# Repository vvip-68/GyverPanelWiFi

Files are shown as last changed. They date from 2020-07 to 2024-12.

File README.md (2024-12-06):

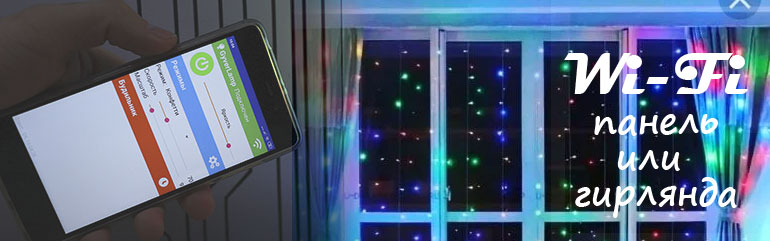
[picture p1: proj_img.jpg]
PROJECT_PHOTO

# Крутая WiFi панель / гирлянда на esp8266 своими руками
* [Описание проекта](#chapter-0)
* [Папки проекта](#chapter-1)
* [Схемы подключения](#chapter-2)
* [Материалы и компоненты](#chapter-3)
* [Как скачать и прошить](#chapter-4)
* [Полезная информация](#chapter-5)

## **Этот проект устарел.** 
> Новый проект ["WiFi панель или гирлянда на ESP8266 / ESP32 с Web-интерфейсом"](https://github.com/vvip-68/LedPanelWiFi)
> почти полностью повторяет функционал этого проекта, за исключением следующих позиций:
> - В новом проекте в настоящее время в комплекте нет Android-приложения для управления и настройки.
> - Android-приложение из версии 1.13 несовместимо с прошивкой в новом проекте
> - Управление и настройка параметров нового проекта выполняется через Web интерфейс.
> - Управление сторонним приложением или интеграция в Умный дом всё ещё возможна:  
>   Управление по каналам UDP и MQTT поддерживается как и раньше, за исключением некоторых изменений в API 
> 
> Переход на Web-интерфейс упрощает процесс внедрения новых возможностей, которые будут дополняться по мере развития проекта
> 
> Если вы активно используете управление устройством через MQTT - оставайтесь на этой версии.
> В противном случае - переходите на новый проект. 
> Поддержка этого проекта будет закрыта.  

## Описание проекта
  
Этот проект основан на проекте ["Крутая WiFi лампа на esp8266 своими руками"](https://github.com/vvip-68/GyverLampWiFi)
с расширением возможностей работы на неквадратных широких матрицах с размерами от 23x11.  
Основное назначение проекта - настенные экраны больших размеров или гирлянды на широкие балконы.  
Также подходит с некоторыми ограничениями для матриц с размерами 16x16.
Ограничение связаны с невозможностью отображения часов крупным шрифтом 5x7 для которого требуется матрица не менее 23 пикселей по ширине.
Для матриц менее 23 колонок шириной в часах может использоваться только шрифт 3x5 для которого достаточно 15 колонок.

### Железо
- Проект собран на базе микроконтроллера ESP8266 в лице платы NodeMCU или Wemos D1 mini (неважно, какую из этих плат использовать)
- Реализована поддержка микроконтроллера ESP32, имеющего больший размер оперативной памяти и быстродействие, что позволяет управлять матрицами с большим количеством светодиодов
- Матрица может быть реализована на адресной ленте или отдельных светодиодах WS8212b, спаянных в нити гирлянды проводами
- Также для компактных панелей может использоваться соединение нескольких гибких адресных матриц 16×16, состоящих из 256 диодов с плотностью 100 штук на метр, что позволяет 
  легко получить панели размерами 32х16, 48x16, 64x16 и так далее (до 128 по ширине и/или высоте).
- Система управляется со смартфона по Wi-Fi в локальной сети или из любой точки мира через MQTT, а также “оффлайн” с кнопки на корпусе (сенсорная кнопка на TTP223 или 
  любая физическая кнопка с нормально разомкнутыми контактами)
- В случае реализации проекта в виде большой настенной матрицы поддерживается функционал будильника-рассвет и индикация текущего времени на индикаторе TM1637, 
  что позволяет в ночное время полностью выключать саму матрицу, оставляя возможность отображения текущего времени на этом индикаторе
- Поддерживается загрузка файлов анимации формата \*.out программы Glediator с SD-карты.

### Фишки
 - Более 40 крутых эффектов с поддержкой отображения часов или текста бегущей строки поверх эффектов
 - 4 интерактивные игры: Лабиринт, Змейка, Тетрис, Арканоид (в программе-компаньоне "WiFiPlayer")
 - Отправка картинки со смартфона на матрицу (в программе-компаньоне "WiFiPlayer")
 - Рисование на матрице (в программе-компаньоне "WiFiPlayer")
 - Сохранение нарисованных изображения на SD-карте или во внутренней памяти микроконтроллера
 - Загрузка сохраненных изображений на матрицу и в программу "WiFiPlayer" для редактирования
 - Редактирование и создание картинок пользователя пригодных для загрузки на матрицу в утилите ["JinxFramer"](https://github.com/vvip-68/GyverPanelWiFi/wiki/JinxFramer---редактор-анимации,-роликов,-картинок).
 - Регулировка яркости эффектов относительно яркости часов или текста бегущей строки, отображаемых поверх эффектов
 - Возможность задания до 36 разных [текстовых строк](https://github.com/vvip-68/GyverPanelWiFi/wiki/Настройка-бегущей-строки), задание порядка их "воспроизведения" a также параметров отображения.
   Тексты задаются из программы на смартфоне без необходимости перепрошивки контроллера.
   [Как настроить.](https://github.com/vvip-68/GyverPanelWiFi/wiki/Настройка-бегущей-строки)
   [Обсуждение текстов.](https://github.com/vvip-68/GyverPanelWiFi/issues/102#issue-778611501)  
 - Поддержка текста бегущей строки с отображением оставшегося до события времени, например: "До Нового года осталось 5 дней 12 часов"
   и после наступления события - вывод специального текста, например: "С Новым 2022 годом!!!"
 - Текст бегущей строки может отображаться различными цветами внутри одной строки
 - Поддержка в бегущей строке шрифтов трех размеров: малый (5x8 точек), средний (8х13 точек), большой (10х16 точек) - [настраивается](https://github.com/vvip-68/GyverPanelWiFi/wiki/Большие-буквы-в-бегущей-строке) в скетче при компиляции проекта
 - Поддержка символов украинского и литовского языка (в этом случае - размер шрифта 5x11. 8x17, 10x20 точек)
 - Настройка скорости и вариаций отображения для каждого эффекта со смартфона
 - Поддержка эффектов анимации, подготовленных в программе [“Jinx!”](https://github.com/vvip-68/GyverPanelWiFi/wiki/Экспорт-эффектов-анимации-из-ПО-«Jinx!»), сохраненных на SD карту
 - Редактирование роликов анимации с SD-карты в утилите ["JinxFramer"](https://github.com/vvip-68/GyverPanelWiFi/wiki/JinxFramer---редактор-анимации,-роликов,-картинок).
 - [Создание кадров для эффекта "Анимация"](https://github.com/vvip-68/GyverPanelWiFi/wiki/Добавление-своей-анимации--к-эффекту-«Анимация») в утилите "JinxFramer" для последующего экспорта кода, пригодного для включения в скетч проекта.
 - Работа системы как в локальной сети, так и в режиме “точки доступа”
 - Система получает точное время из Интернета
 - Управление кнопкой: смена режима, настройка яркости, вкл/выкл, отображение текущего IP адреса устройства
 - Режим будильник-рассвет: менеджер будильников на неделю в приложении
 - Отображение текущего времени на индикаторе TM1637
 - Отображение текущего времени на матрице поверх эффектов
 - Отображение текстовых сообщений на матрице поверх эффектов
 - Настройка сервера синхронизации времени из программы на смартфоне 
 - Установка текущего времени со смартфона вручную, если не удалось подключиться к серверу времени NTP
 - Два режима работы индикатора времени TM1637 - светится постоянно или выключается вместе с панелью
 - Пока время не получено с сервера NTP - на индикаторе TM1637 отображается --:-- вне зависимости от настройки
   "Выключать индикатор при выключении панели"
 - Поддержка звука будильника / звука рассвета звуковой платой MP3 DFPlayer
 - Настройки сетевого подключения (SSID и пароль, статический IP) задаются в программе и сохраняются в EEPROM
 - Если не удается подключиться к сети (неверный пароль или имя сети) - автоматически создается точка подключения
   с именем PanelAP, пароль 12341234, IP 192.168.4.1. Подключившись к точке доступа из приложения
   можно настроить параметры сети. Если после задания параметров сети WiFi соединение установлено - 
   в приложении на смартфоне виден IP адрес подключения к сети WiFi.
 - Отображение текущего IP адреса устройства на индикаторе TM1637 или на матрице в режиме бегущей строки
 - Быстрое включение популярных режимов из приложения
 - Четыре программируемых по времени режима, позволяющие, например, настроить автоматическое выключение панели в ночное время
   и автоматическое включение панели вечером в назначенное время
 - Два специальных режима времени - "Рассвет" и "Закат". Время рассвета и заката на текущий день берется с сервера погоды при получении текущих погодных условия и температуры
 - Получение текущей температуры воздуха и погоды с сервера Яндекс.Погода или OpenWeatherMap. Полученные данные могут отображаться в бегущей строке или в режиме отображения времени вместе с часами
   Код региона (города) указывается в настройках в программе на смартфоне. Настройка погоды - [тут](https://github.com/vvip-68/GyverPanelWiFi/wiki/Настройка-получения-информации-о-погоде)  
 - Возможность управления из любой точки планеты через подключение к MQTT-серверу из приложения на смартфоне или с использованием ассистентов умного дома (Яндекс Алиса, Google Ассистент и т.д.)  
   Настройка подключения к MQTT-серверу [здесь](https://github.com/vvip-68/GyverPanelWiFi/wiki/Настройка-подключения-к-MQTT-серверу)  
   Описание API управления устройством [здесь](https://github.com/vvip-68/GyverPanelWiFi/wiki/API-управления-устройством)
 - Поддержка [составных матриц](https://github.com/vvip-68/GyverPanelWiFi/wiki/Сборная-матрица), собранных из стандартных матриц 8x8, 16x16, 8x32 в одну матрицу большого размера.
 - [Настройка](https://github.com/vvip-68/GyverPanelWiFi/wiki/Сборная-матрица) размеров матрицы (ширины и высоты), а также способ ее подключения - угол, направление из угла задаются в приложении-компаньоне
   WiFiPanelSetup без необходимости перепрошивки микроконтроллера.
 - Синхронизация эффектов между устройствами. Может быть создано до 10 групп устройств, количество устройств в группе - не ограничено.
 - Беспроводная трансляция эффектов на матрицу устройств из специализированных программ типа *Jinx!*, *Wixen Lights*, *xLights* и подобных по протоколу *sACN Streaming ACN E1.31 DMX*  
 - ***Новое!*** Возможность работы со сборными матрицами, собранными из сегментов любых размеров, с любым способом подключения (угол, направление из угла, зигзаг/параллельная).

#### Эффекты:
 - Заливка панели белым или другим выбранным цветом
 - Снегопад
 - Блуждающий кубик
 - Пейнтбол
 - Радуга (горизонтальная, вертикальная, диагональная, вращающаяся)
 - Огонь
 - The Matrix
 - Шарики
 - Конфетти
 - Звездопад
 - Шумовые эффекты с разными цветовыми палитрами
 - Плавная смена цвета заливки панели
 - Светлячки
 - Водоворот
 - Мерцание
 - Северное сияние
 - Циклон
 - Тени (меняющийся теневой рисунок на матрице)
 - Демо-версия игры Тетрис - автоигра без возможности управления
 - Демо-версия игры Лабиринт - автоигра без возможности управления
 - Демо-версия игры Змейка - автоигра без возможности управления
 - Демо-версия игры Арканоид - автоигра без возможности управления
 - Демо-версия игры Эволюция (симулятор жизни) - автоигра без возможности управления
 - Движущийся синус
 - Палитра (лоскутное одеяло) 
 - Имитация графического индикатора спектра, движущегося "в такт музыке". 
 - Вышиванка
 - Дождь
 - Камин
 - Стрелки
 - Погода (слайдшоу или отображение текущих погодных условия)
 - Отображение анимированных картинок
 - Фоновые узоры (нотки, сердечки, снежинки, зигзаги и т.п.)
 - Анимация с SD карты
 - Звезды - вспышки крестообразных "звезд" по всему полю матрицы
 - Штора - имитация светодиодной шторы на окне

#### Игры:

Доступны в приложении-компаньоне "WiFiPlayer"   
 - Лабиринт
 - Змейка
 - Тетрис
 - Арканоид

### Кнопка управления режимами, последовательность переключения:
#### Будильник сработал, идет рассвет или мелодия пробуждения
- Любое нажатие кнопки отключает будильник
#### Долгое удержание кнопки 
- При включенной панели - плавное изменение яркости
- При выключенной панели - включение яркой белой панели освещения (только для сборки типа "Лампа" - DEVICE_TYPE == 0)
#### Однократное нажатие кнопки
- Включение / выключение панели. При включении возобновляется режим на котором панель была выключена.
#### Двухкратное нажатие кнопки
- Ручной переход к следующему режиму
#### Трехкратное нажатие кнопки
- Включение демо-режима с автоматической сменой режимов по циклу
#### Четырехкратное нажатие кнопки
- Включение яркой белой панели освещения из любого режима, даже если панель была "выключена" /для сборки типа "Лампа"/  
  Отображение IP адреса панели на матрице и на индикаторе TM1637, если подключение к локальной WiFi сети установлено  /для сборки типа "Панель"/  
#### Пятикратное нажатие кнопки
- На индикаторе TM1637 и на матрице отображается IP адрес панели, если подключение к локальной WiFi сети установлено /для сборки типа "Лампа"/

## Папки
**ВНИМАНИЕ! Если это твой первый опыт работы с Arduino, читай [инструкцию](#chapter-4)**
- **Android** - файлы с приложениями, примерами для Android и MIT App Inventor
- **firmware** - прошивки
- **libraries** - библиотеки проекта.
- **pics** - примеры картинок для загрузки / отображении на матрице
- **schemes** - схемы подключения компонентов
- **sounds** - звуковые файлы будильника для размещения на SD-карте
- **tools** - полезные утилиты, Jinx! и другие
- **wiki** - файлы раздела wiki-страниц GitHub 

## Схема

Варианты схем с различным набором компонент, для микроконтроллеров **ESP8266** - NodeMCU, Wemos d1 mini, **ESP32** представлены [здесь](https://github.com/vvip-68/GyverPanelWiFi/wiki/%D0%92%D0%B0%D1%80%D0%B8%D0%B0%D0%BD%D1%82%D1%8B-%D1%83%D1%81%D1%82%D1%80%D0%BE%D0%B9%D1%81%D1%82%D0%B2.-%D0%A1%D1%85%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.).

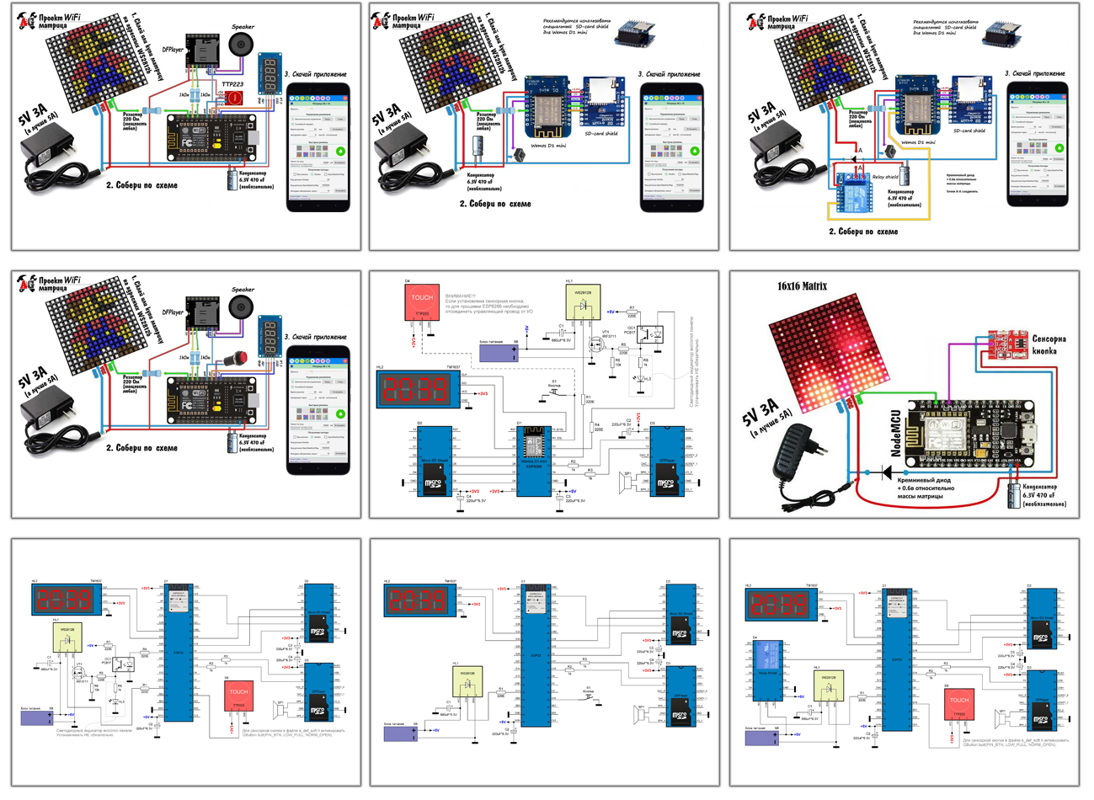
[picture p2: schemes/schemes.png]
SCHEME


Вариант релизации от [Дмитрия (7918514)](https://github.com/7918514) - схемы, фотографии сборки и готового изделия, печатные платы - все материалы доступны по [ссылке](https://disk.yandex.ru/d/fIo2UEuKpR54hg) в папке "Монстр".

## Материалы и компоненты
### Ссылки оставлены на магазины
Полный список компонентов есть в статье https://alexgyver.ru/matrix_guide/
- NodeMCU http://ali.ski/_1FJZ, https://ali.onl/1FjU
- Wemos D1 mini http://ali.ski/FuTgbO, https://ali.onl/1FjS https://ali.onl/1Fk1
- Wemos D1 mini Pro https://ali.onl/1FjT https://ali.onl/1Fk0
- Матрица 16x16 http://ali.ski/BCKQT http://ali.ski/bRW14 http://ali.ski/X-tBrQ
- Адресная лента (для DIY матрицы) http://ali.ski/rqgqdq  http://ali.ski/4Ma9iH
- Готовая гирлянда на 20/50/100 диодов (2м/5м/10м) https://ali.onl/1Fk3 https://ali.onl/1Fk4 https://ali.onl/1Fk5
- Сенсорная кнопка http://ali.ski/aWQBAa  http://ali.ski/rsOrSB
- Резисторы http://ali.ski/UEez2
- БП 5V (брать 3A минимум) http://ali.ski/K-CThT  http://ali.ski/3UWXJ
- MP3 DFPlayer http://ali.onl/1gY1 http://ali.onl/1gY3
- SD card shield https://ali.onl/1FjV https://ali.onl/1FjW https://ali.onl/1FjZ
- Динамики http://ali.onl/1h3u https://ali.onl/1FjX
- Проводочки http://ali.ski/JQRler  http://ali.ski/_SuCF
- Дисплеи TM1637 https://ali.onl/1Fkg https://ali.onl/1Fkf
- Диоды кремниевые выпрямительные https://ali.onl/1Fmw https://ali.onl/1Fmy
- MOSFET IRF4905 https://ali.onl/1Fsl https://ali.onl/1Fsm
- MOSFET IRF3205 https://ali.onl/1Fsn https://ali.onl/1Fso
- Реле управления питанием https://ali.onl/1HBY https://ali.onl/1HBZ https://ali.onl/1HC0

## Вам скорее всего пригодится
* [Всё для пайки (паяльники и примочки)](http://alexgyver.ru/all-for-soldering/)
* [Недорогие инструменты](http://alexgyver.ru/my_instruments/)
* [Все существующие модули и сенсоры Arduino](http://alexgyver.ru/arduino_shop/)
* [Электронные компоненты](http://alexgyver.ru/electronics/)
* [Аккумуляторы и зарядные модули](http://alexgyver.ru/18650/)

## Как скачать и прошить
* [Первые шаги с Arduino](http://alexgyver.ru/arduino-first/) - ультра подробная статья по началу работы с Arduino, ознакомиться первым делом!
* Скачать архив с проектом
> На главной странице проекта (где ты читаешь этот текст) вверху справа зелёная кнопка **Clone or download**, вот её жми, там будет **Download ZIP**
* Установить библиотеки в  
`C:\Program Files (x86)\Arduino\libraries\` (Windows x64)  
`C:\Program Files\Arduino\libraries\` (Windows x86)
* **Подключить внешнее питание 5 Вольт**
* Подключить Arduino к компьютеру
* Запустить файл прошивки (который имеет расширение .ino)
* Настроить IDE (COM порт, модель Arduino, как в статье выше)
* Настроить что нужно по проекту
* Нажать загрузить
* Скачать и установить на смартфон GyverPanelWiFi
* Пользоваться  

**Подробная инструкция [тут](https://github.com/vvip-68/GyverPanelWiFi/wiki/%D0%9F%D0%BE%D1%88%D0%B0%D0%B3%D0%BE%D0%B2%D0%B0%D1%8F-%D0%B8%D0%BD%D1%81%D1%82%D1%80%D1%83%D0%BA%D1%86%D0%B8%D1%8F-%D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)**

## Важно
Если проект не собирается (ошибки компиляции) или собирается, но работает неправильно (например вся матрица светится белым и ничего не происходит) - проверьте версии библиотек.   

Данный проект рассчитан на работу с версиями библиотек поддержки плат:  
- ESP8266 версии 3.2.1
- ESP32 версии 2.0.14 
- библиотеки FastLED версии 3.6.0 или более новой - 3.7.0

Вся актуальная информация о версиях ядра, библиотек, прочие требования находится в комментариях в начале основного файла скетча - GyverPanelWiFi_v1.13.ino

## Полезная информация
* [Cайт Alex Gyver](http://alexgyver.ru/)
* [Канал Alex Gyver на YouTube](https://www.youtube.com/channel/UCgtAOyEQdAyjvm9ATCi_Aig?sub_confirmation=1)
* [YouTube канал про Arduino](https://www.youtube.com/channel/UC4axiS76D784-ofoTdo5zOA?sub_confirmation=1)
* [Видеоуроки по пайке](https://www.youtube.com/playlist?list=PLOT_HeyBraBuMIwfSYu7kCKXxQGsUKcqR)
* [Видеоуроки по Arduino](http://alexgyver.ru/arduino_lessons/)

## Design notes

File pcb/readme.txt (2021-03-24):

Вариант печатной платы, разработанной пользователем RailWar (Evgeny)
для варианта устройства на ESP8366 (плата ESP-12F) по схеме "С полным набором компонент (отключение матрицы - MOSFET)" 
с toush-button смотри статью "Варианты устройств. Схемы." в wiki.

Для данной платы используется
#define DEVICE_VARIANT 1
в настройках прошивки

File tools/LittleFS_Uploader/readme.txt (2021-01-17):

Плагин для Arduino IDE - загрузчик файлов в файловую систему LittleFS микроконтроллера ESP8266

https://github.com/earlephilhower/arduino-esp8266littlefs-plugin

1. Установите плагин в Arduino IDE:
 a. Перейдите в папку, где установлена Arduino IDE (обычно "C:\Program Files (x86)\Arduino\")
 b. Если в папке нет подпапки tools - создайте ее, если есть - перейдите в эту папку
 с. Распакуйте архив ESP8266LittleFS-2.6.0.zip в папку tools - в ней будет создана подпапка ESP8266LittleFS с файлами плагина
 d. Перезагрузите Arduino IDE

2. В папке скетча создайте подпапку data
3. В созданной папке data создайте подпапку с именем, соответствующим размерам вашей матрицы. 
   Например для матрицы 16x16 создайте папку "16p16"
4. В созданную папку 16р16 скопируйте файлы картинок
5. В Arduino IDE в меню "Инструменты" выберите пункт "ESP8266 LittleFS Data Upload"
6. Наблюдайте в ArduinoIDE области сообщений ход загрузки файлов, дождитесь сообщения о завершении загрузке и
   о перезагрузке микроконтроллеоа
7. Загрузка файлов завершена.

---------------------------------------------

Для ESP32 используется свой плагин для загрузки файлов в файловую систему LittleFS ESP32

https://github.com/lorol/arduino-esp32littlefs-plugin

Установка плагина и загрузка файлов - аналогично описанной для ESP8266

---------------------------------------------

Универсальный плагин для ESP32 с поддержкой SPIFFS, LittleFS и FatFS

https://github.com/lorol/arduino-esp32fs-plugin

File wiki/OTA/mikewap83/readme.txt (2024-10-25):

Добрый вечер, я новичок в Arduino и тоже стокнулся что не хватает памяти для скетча на ESP 32 4MB если включить все, методом проб и ошибок, 
нашел метод как переразметить структуру памяти

Вот инструкция
Открыть файл C:\Users\[ИМЯ пользователя]\AppData\Local\Arduino15\packages\esp32\hardware\esp32\2.0.14\boards.txt

Добавить строки в разделе ## IDE 2.0 Seems to not update the value где идет описание PartitionScheme

esp32.menu.PartitionScheme.default_1_4MB=4MB with spiffs (1.408MB APP/1.152MB SPIFFS)
esp32.menu.PartitionScheme.default_1_4MB.build.partitions=default_1_4MB
esp32.menu.PartitionScheme.default_1_4MB.upload.maximum_size=1441792

Скопировать файл default_1_4MB.csv в папку C:\Users\[ИМЯ пользователя]\AppData\Local\Arduino15\packages\esp32\hardware\esp32\2.0.14\tools\partitions

Перезапустить Arduino и выбрать в настройка размер памяти 4M with spiffs (1.408MB APP/1.152MB SPIFFS)

В Arduino IDE 2.x в меню "Инструменты" не появится новый вариант PartitionScheme, пока мы не удалим скешированную папку приложения, для этого 
необходимо удалить папку C:\Users\[ИМЯ пользователя]\AppData\Roaming\arduino-ide\

После этого получается 1.408MB на скетч, столько же для OTA обновлений и 1.152MB для хранения папки Data, может конечно и меньше нужно, 
знать бы какой размер нужен для хранения папки Data и настроек, так бы может быть и больше под скетч можно было выделить

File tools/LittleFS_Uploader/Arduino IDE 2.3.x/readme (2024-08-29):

LittleFS uploader for ESP8266 compatible with Arduino IDE 2.3.x or higher.

https://github.com/earlephilhower/arduino-littlefs-upload

Для загрузки файловой системы необходимо сделать следующее:

1. Скачать файл плагина по ссылке: https://github.com/earlephilhower/arduino-littlefs-upload/releases/download/
   или взять уже скачанный файл из этой папки
2. Разместить его в указанном месте: C:\Users\<username>\.arduinoIDE\plugins\
3. Запустить Arduino IDE 2.3.x, нажать одновременно [Ctrl] + [Shift] + [P], 
   затем выбрать в появившемся меню "Upload LittleFS to Pico/ESP8266/Esp32".
   Начните мечатать в строке поиска 'Upload' и фильтр поможет найти плагин

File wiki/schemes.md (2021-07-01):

## Схемы устройств для Wemos d1 mini и NodeMCU

### С сенсорной кнопкой
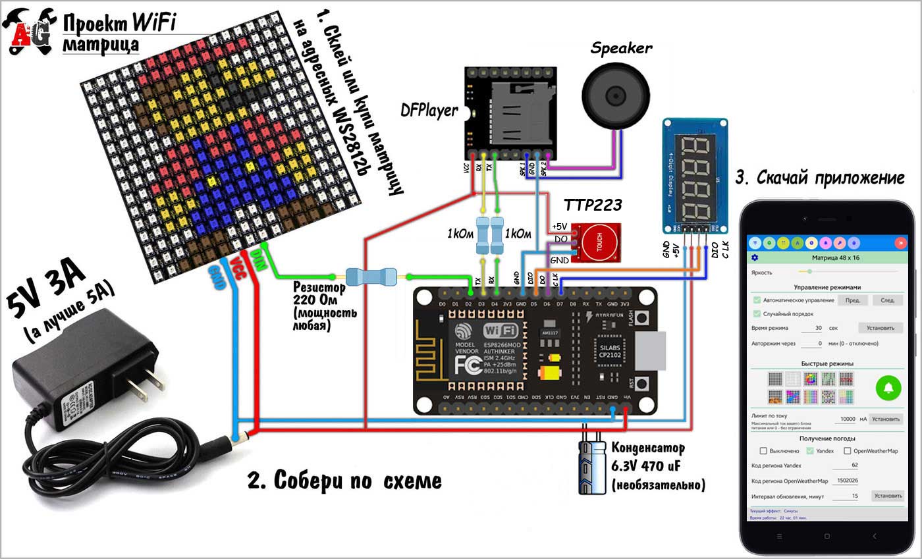
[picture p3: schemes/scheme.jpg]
SCHEME


### С обычной кнопкой
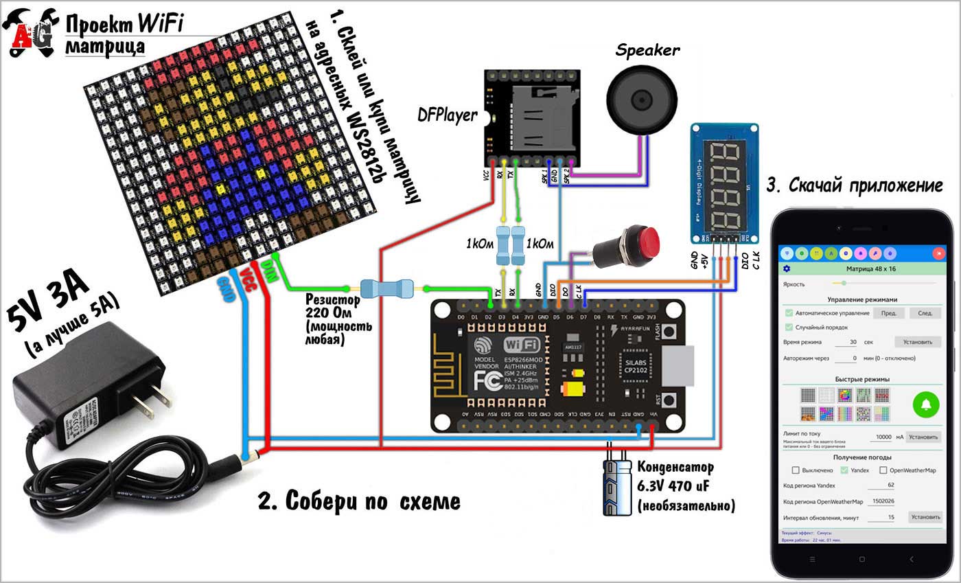
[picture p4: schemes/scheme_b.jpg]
SCHEME


### С SD картой
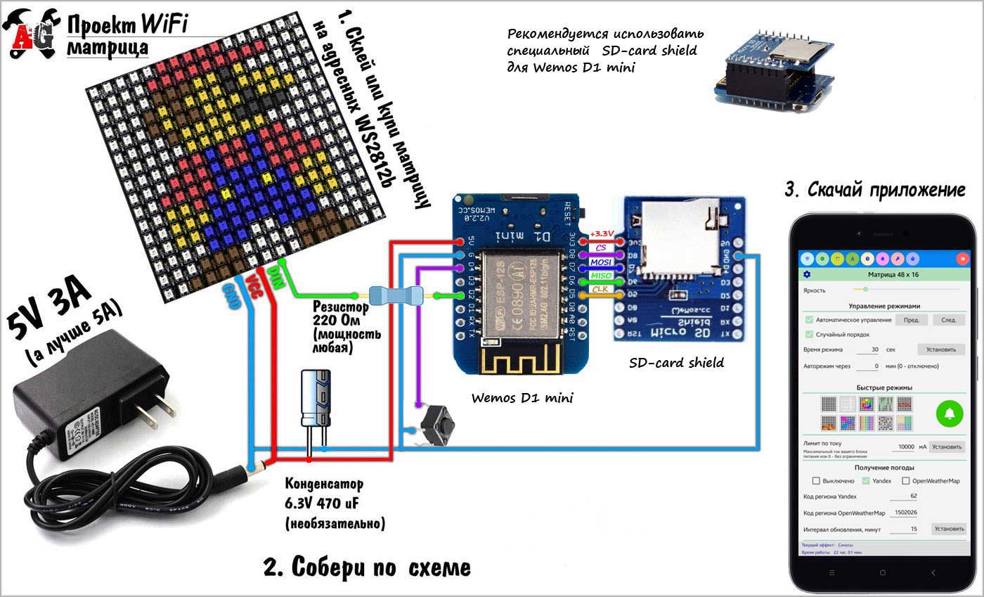
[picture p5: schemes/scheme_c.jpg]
SCHEME


### С корректировкой питания и отключением матрицы
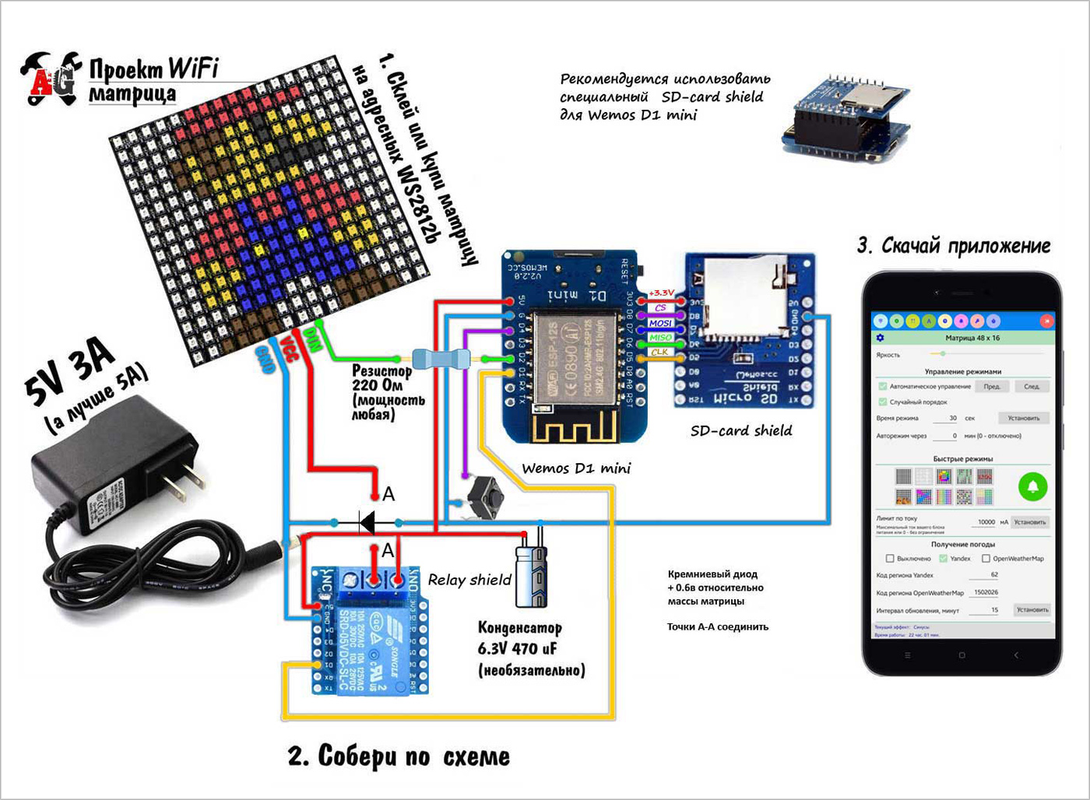
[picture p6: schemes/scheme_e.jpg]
SCHEME


### С корректировкой питания
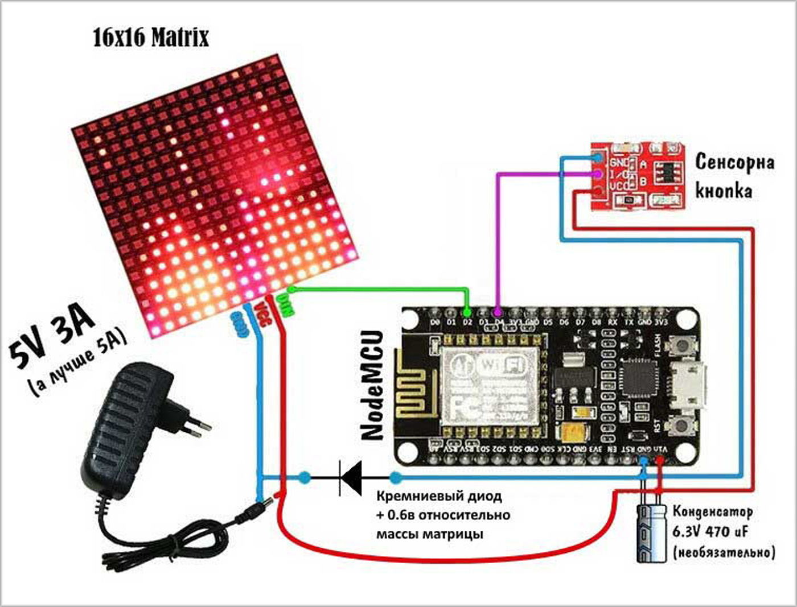
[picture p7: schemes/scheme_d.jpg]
SCHEME


### С полным набором компонент (отключение матрицы - MOSFET)
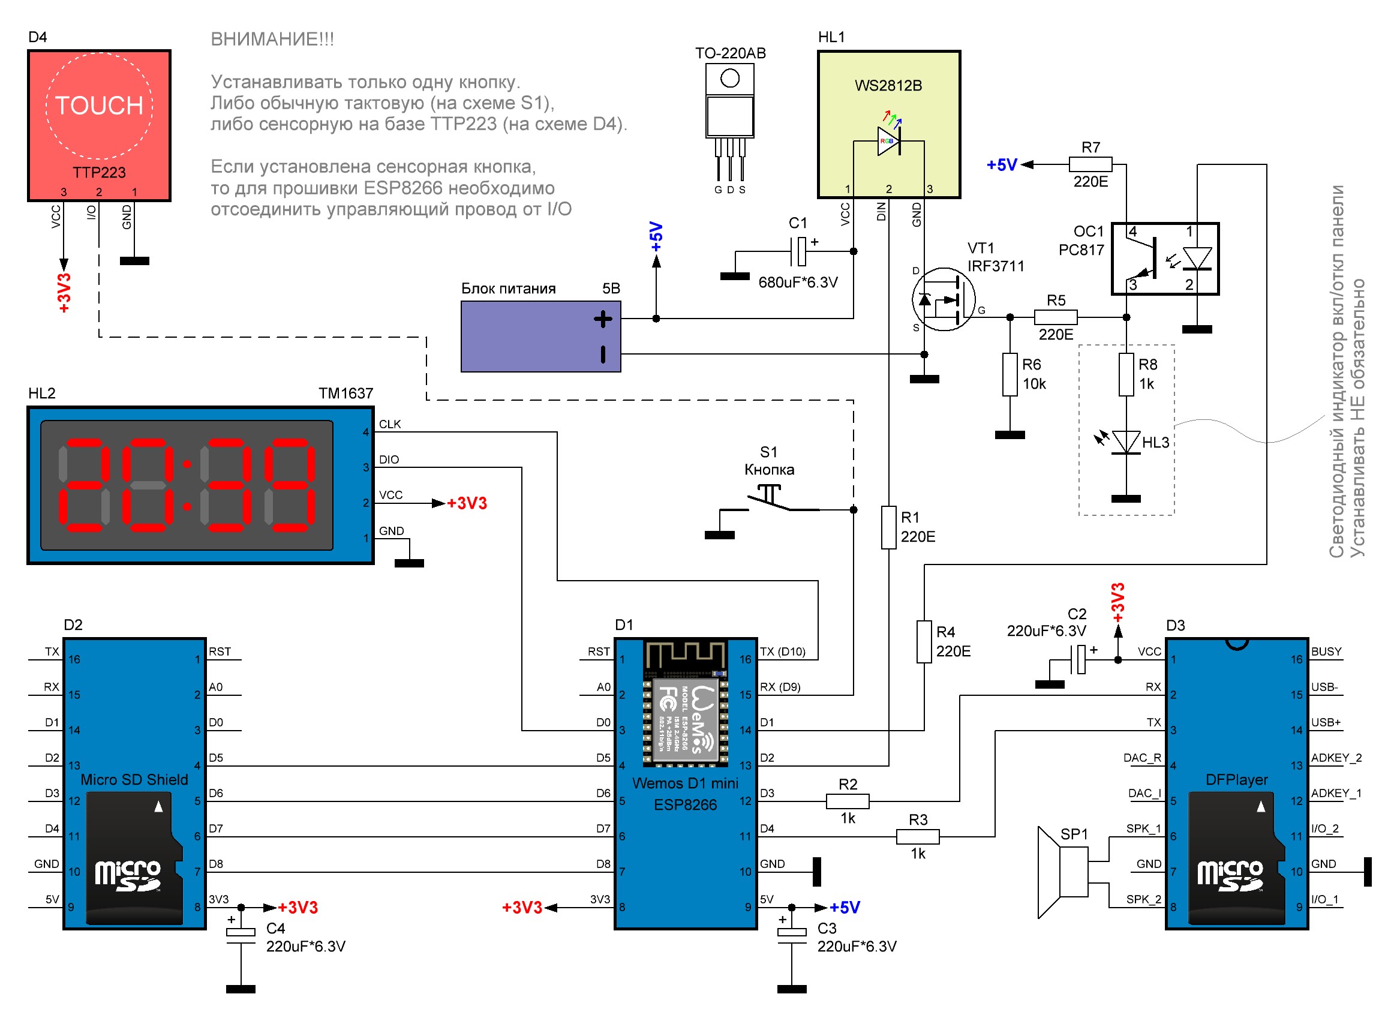
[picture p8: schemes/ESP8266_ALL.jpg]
SCHEME


Для данного варианта схемы ползователь ***RailWar*** (Evgeny) разработал печатную плату.  
PCB Layout смотри в папке **"pcb"** проекта - архив **"lamp8266.zip"**.

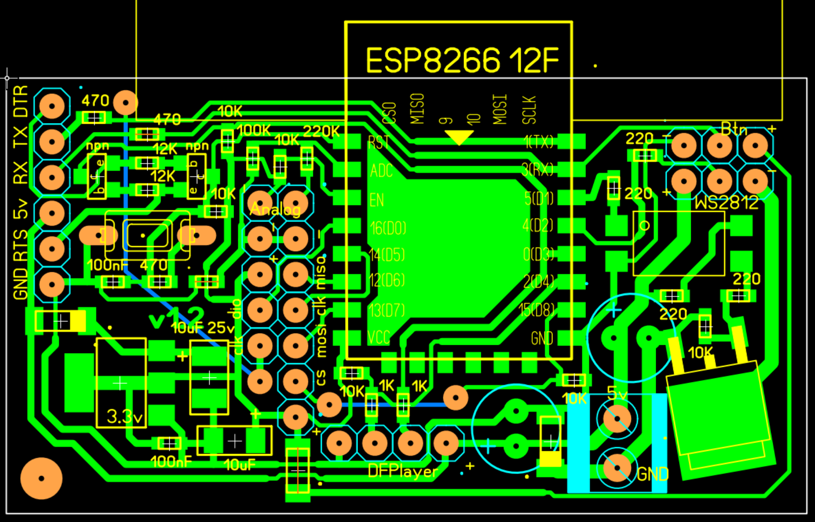
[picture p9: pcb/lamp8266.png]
PCB


### С полным набором компонент (отключение матрицы - реле)
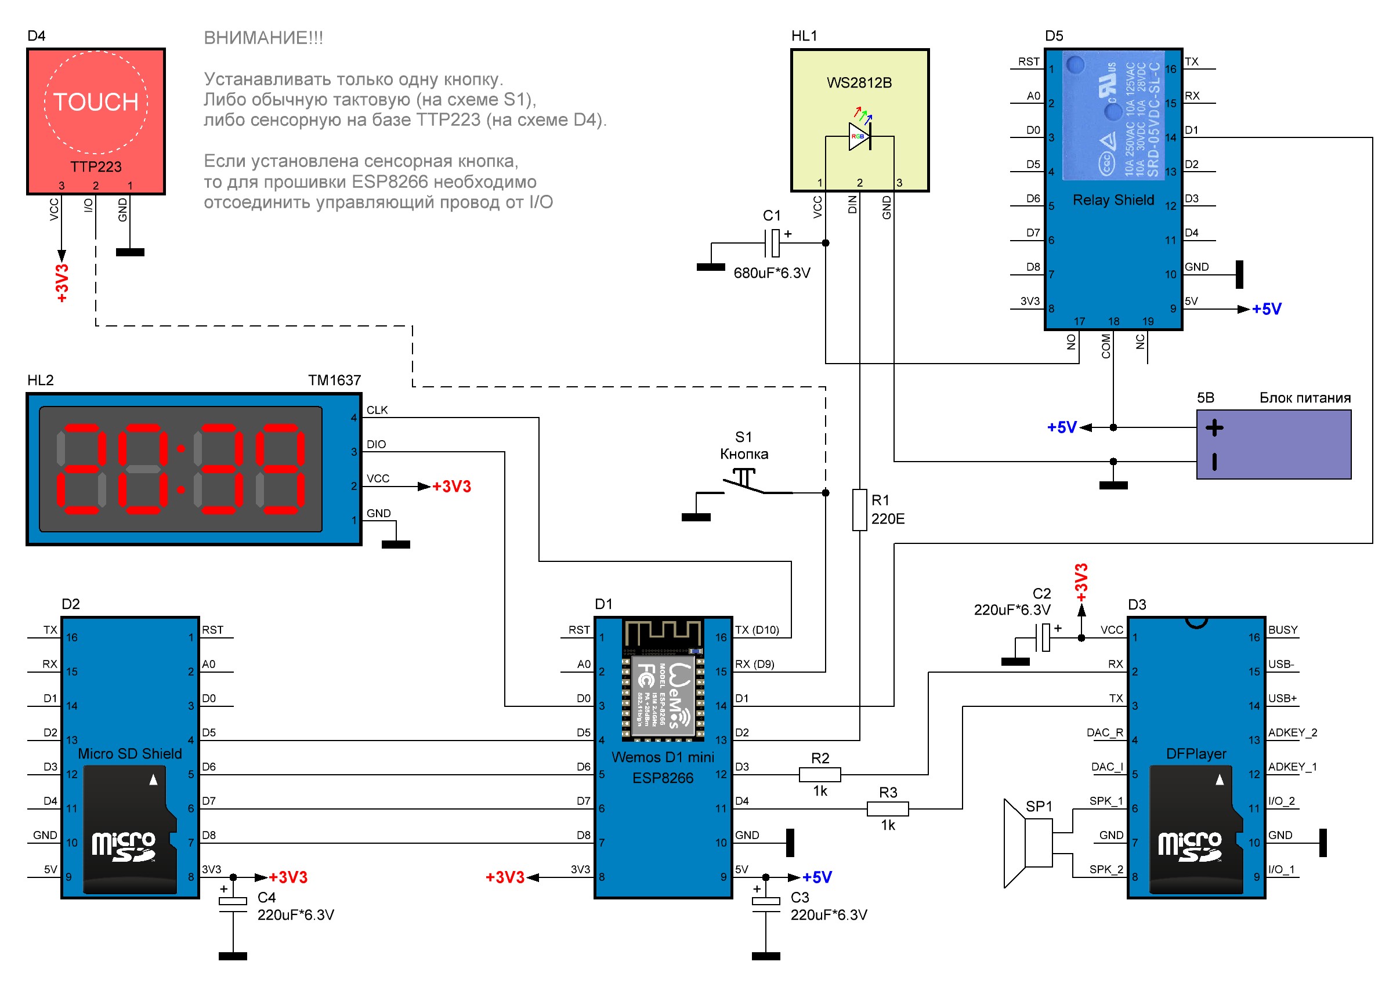
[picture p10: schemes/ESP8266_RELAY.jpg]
SCHEME


<br><br>

## Схемы устройств для ESP32

### С полным набором компонент
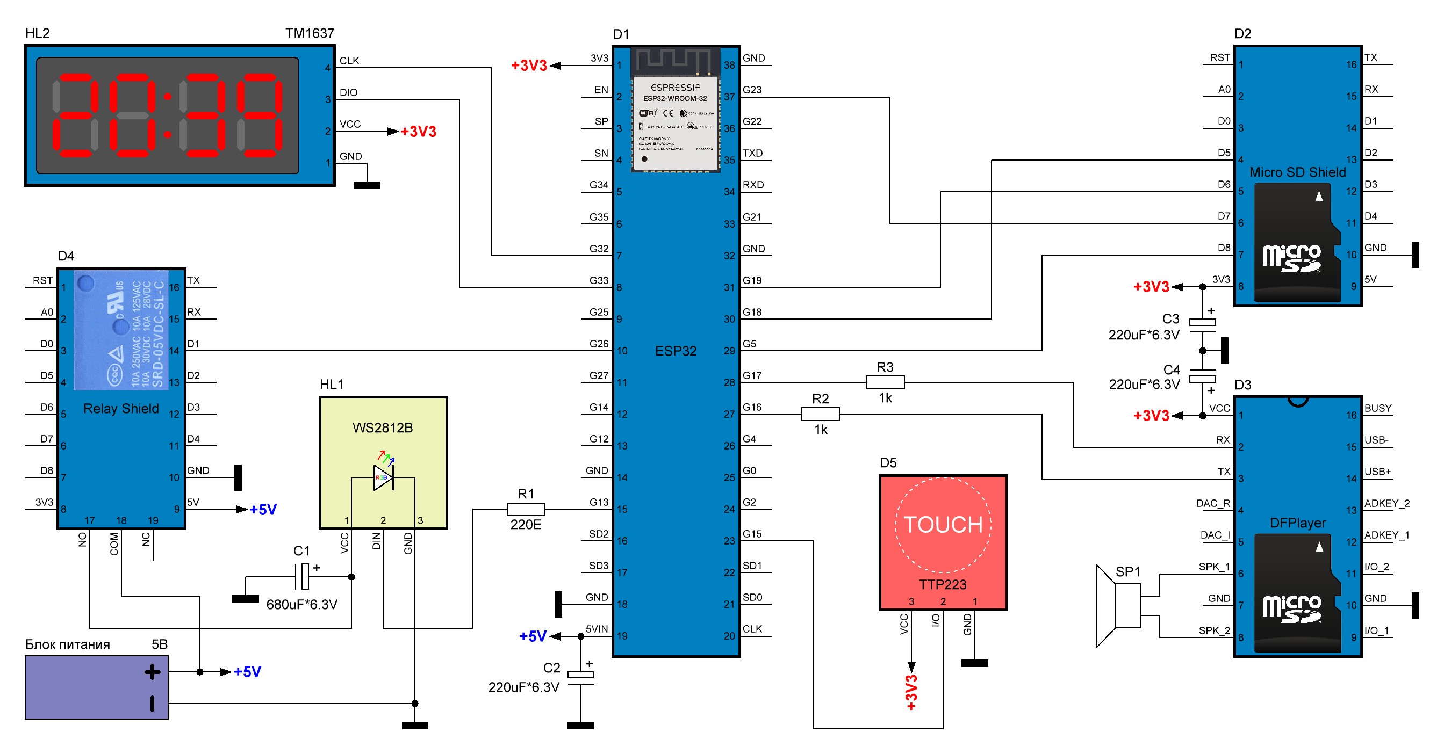
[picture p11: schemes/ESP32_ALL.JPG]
SCHEME


### С сенсорной кнопкой и отключением матрицы
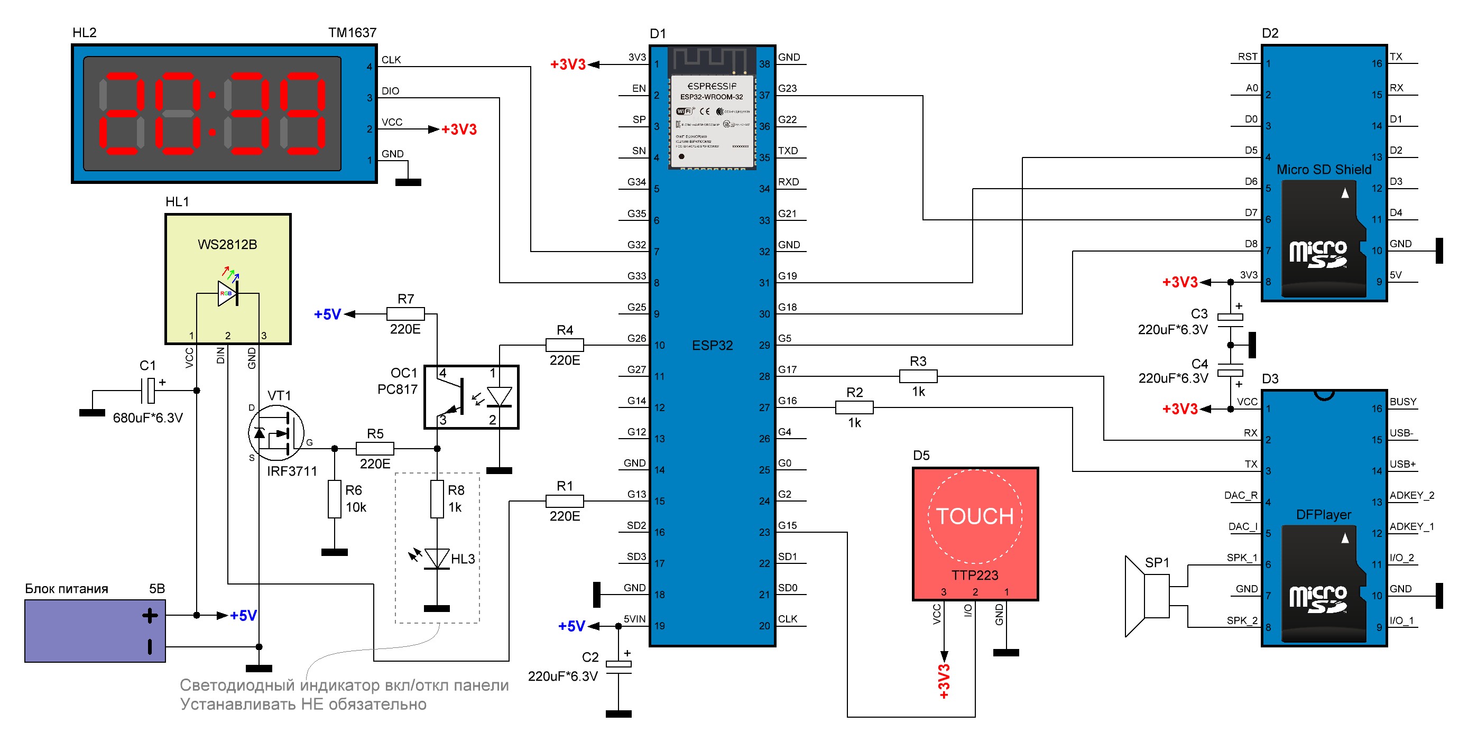
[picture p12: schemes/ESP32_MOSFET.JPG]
SCHEME


### С обычной кнопкой
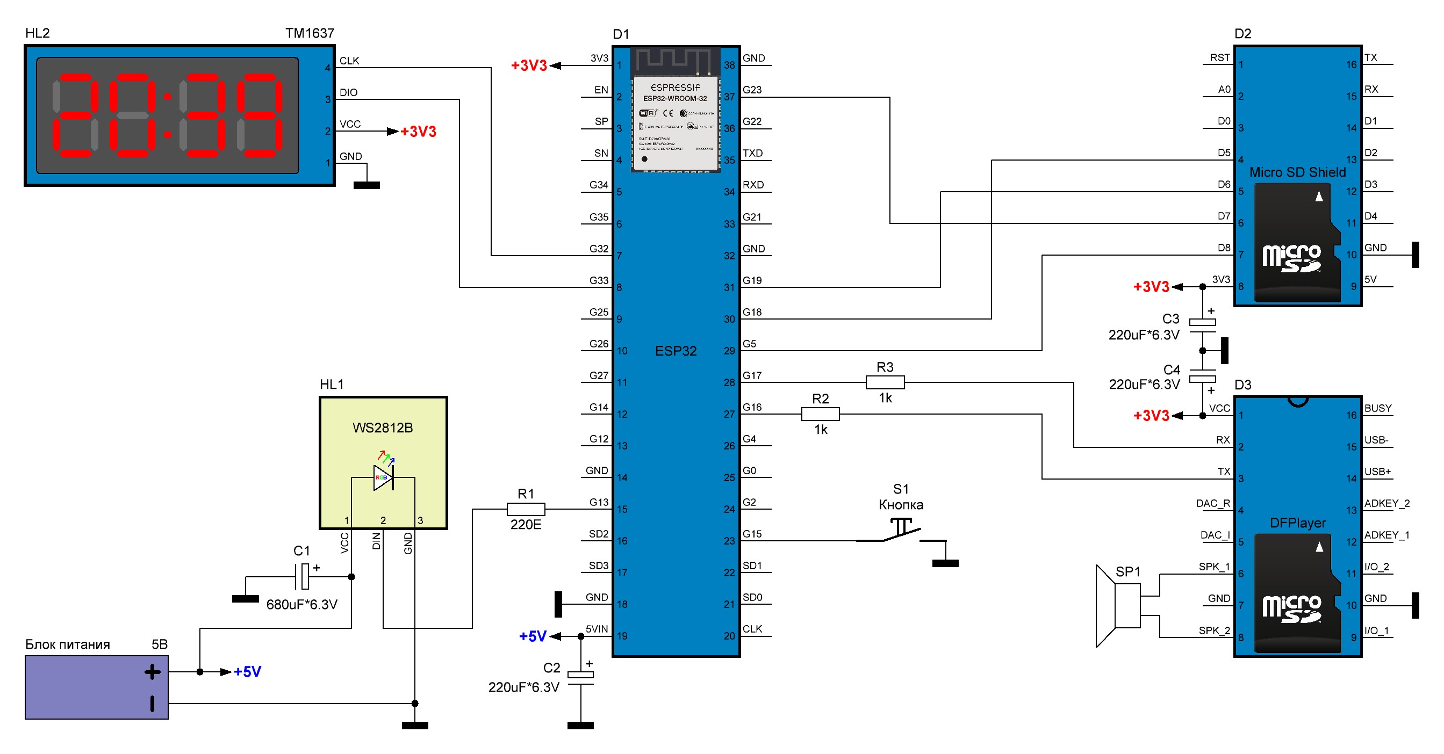
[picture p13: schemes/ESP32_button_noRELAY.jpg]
SCHEME


<br><br>

При повторении устройств следует учитывать особенности подачи питающего напряжения на собранную схему.
От соблюдения правильных параметров питания элементов зависит насколько надежно и бесперебойно будет работать собранное вами устройство.  

```
# Рекомендация по питанию

Наиболее стабильная работа устройства обеспечивается при питании схемы напряжением 4.6-4.9 вольт (не выше!).
При этом корректирующий диод в зазрыв GND питания микроконтроллера ставить не нужно.
Для схем, использующих DFPlayer, питание на него (VCC) в этом случае подавать с общего плюса питания, 
а не с пина 3.3 вольта микроконтроллера, поскольку пин 3.3 вольта не обеспечивает достаточного 
для потребления DFPlayer'ом тока, что приведет к недостаточной громкости воспроизведения, а в худшем 
случае - выходу из строя микросхемы стабилизатора напряжения 3.3 вольта микроконтроллера.

```
Заметки о том, как обеспечивается правильное питание устройства - в [этой](https://github.com/vvip-68/GyverPanelWiFi/wiki/%D0%97%D0%B0%D0%BC%D0%B5%D1%82%D0%BA%D0%B8-%D0%BE-%D0%BF%D0%B8%D1%82%D0%B0%D0%BD%D0%B8%D0%B8) статье.

<br><br>

Благодарность [Дмитрию (7918514)](https://github.com/7918514) за предоставленные варианты схем и проверку их работоспособности.
Его вариант реализации (схемы, фотографии сборки и готового изделия, печатные платы) - все материалы доступны по [ссылке](https://disk.yandex.ru/d/fIo2UEuKpR54hg) в папке "Монстр".

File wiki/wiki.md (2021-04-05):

# Пошаговая инструкция подготовки среды для проекта
## Шаг 1
Перейдите на сайт разработчиков [Arduino](https://www.arduino.cc/en/Main/Software) и скачайте среду разработки.

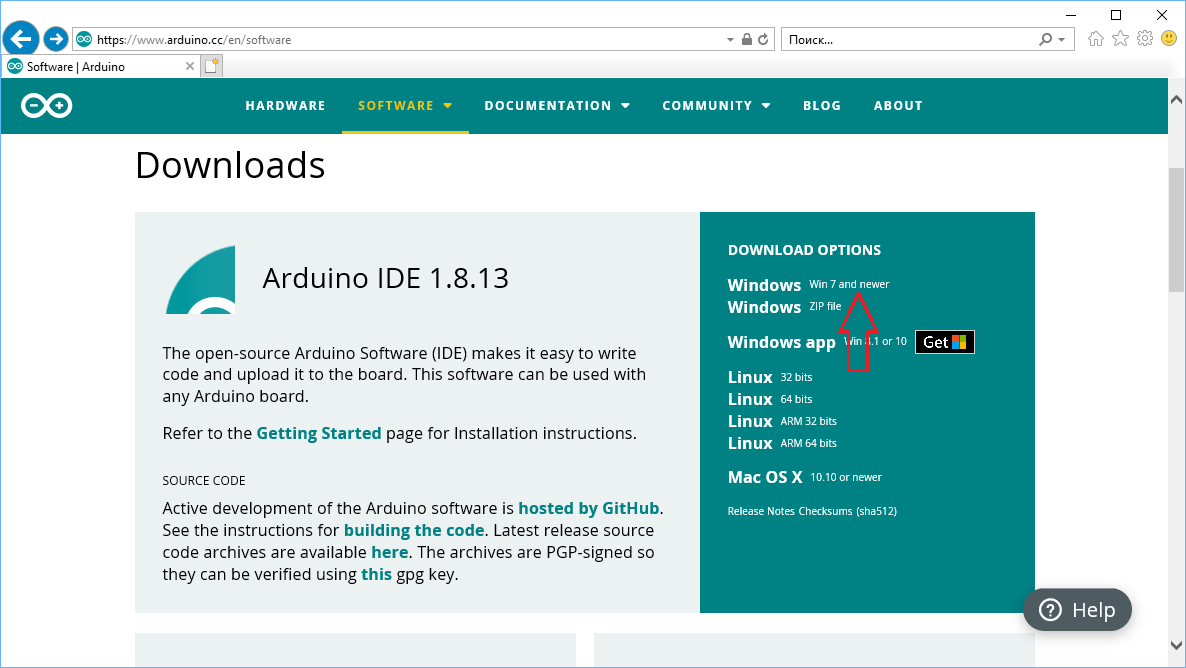
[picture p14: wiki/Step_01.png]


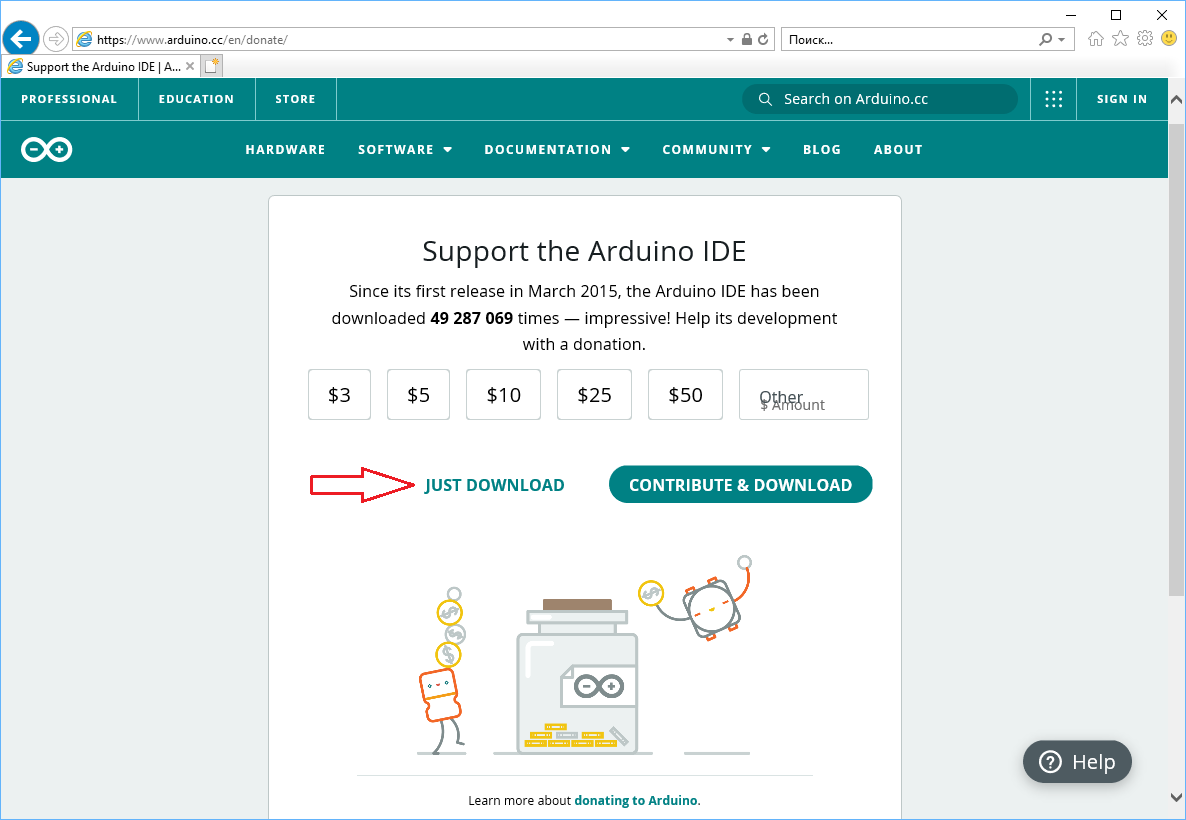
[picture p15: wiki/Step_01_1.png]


Установите среду разработки на ваш компьютер. После завершения установки, запустите Arduino IDE.

## Шаг 2
В Arduino IDE в меню "Файл" выберите пункт "Настройки".

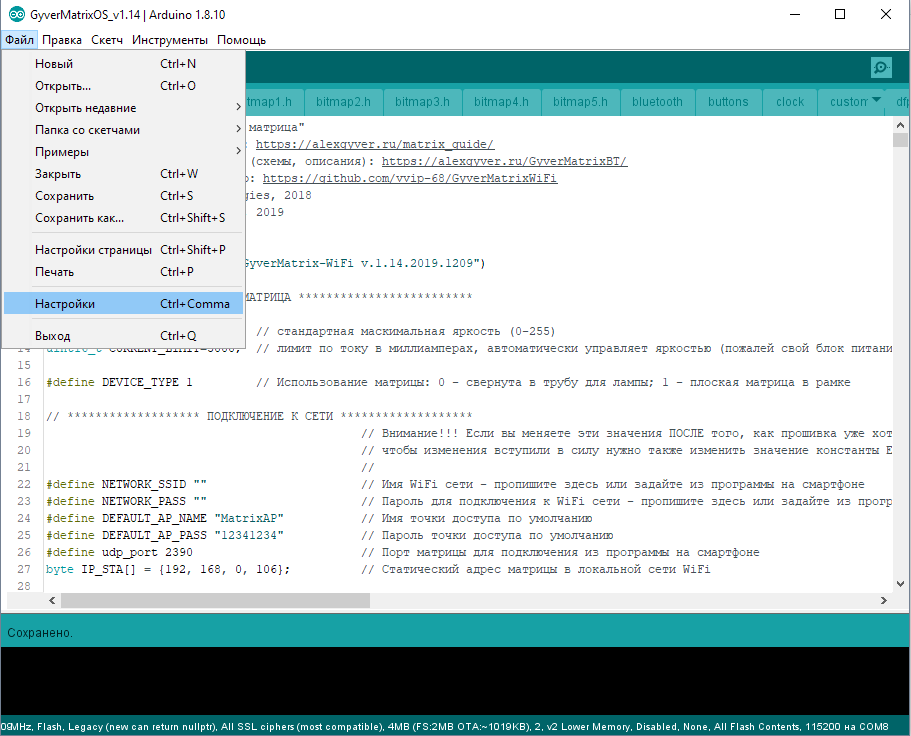
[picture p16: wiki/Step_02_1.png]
Настройки среды разработки ArduinoIDE


В открывшемся окне нажмите на кнопку справа от поля "Дополнительные ссылки для менеджера плат"

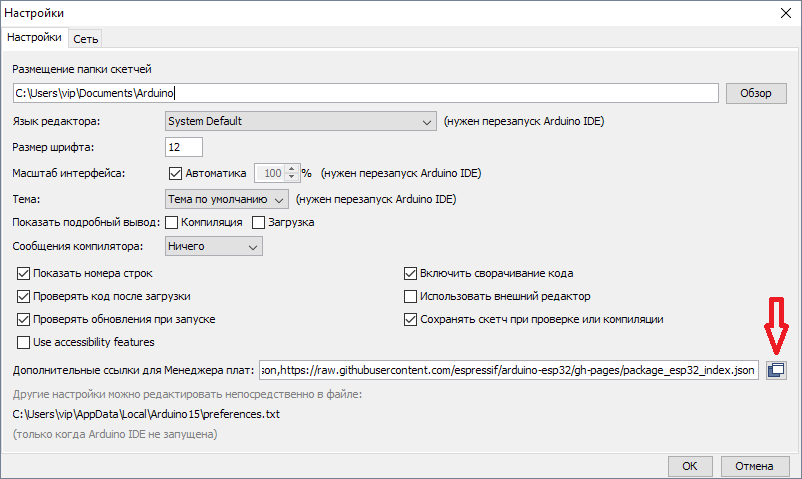
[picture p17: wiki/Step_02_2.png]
Дополнительные ссылки для менеджера плат


В открывшемся окне добавьте в поле ввода следующие строки:
`http://arduino.esp8266.com/stable/package_esp8266com_index.json` - для поддержки микроконтроллеров ESP8266 (NodeMCU, Wemos d1 mini)
`https://raw.githubusercontent.com/espressif/arduino-esp32/gh-pages/package_esp32_index.json` - для поддержки микроконтроллера ESP32.
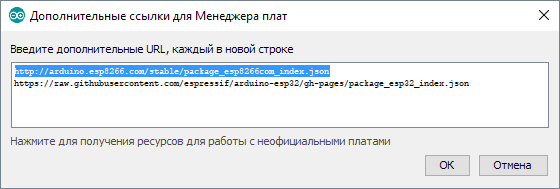
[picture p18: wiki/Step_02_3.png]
Ссылка на плату ESP8266


Примените изменения

## Шаг 3

В Arduino IDE в меню "Инструменты" выберите пункт "Менеджер плат".

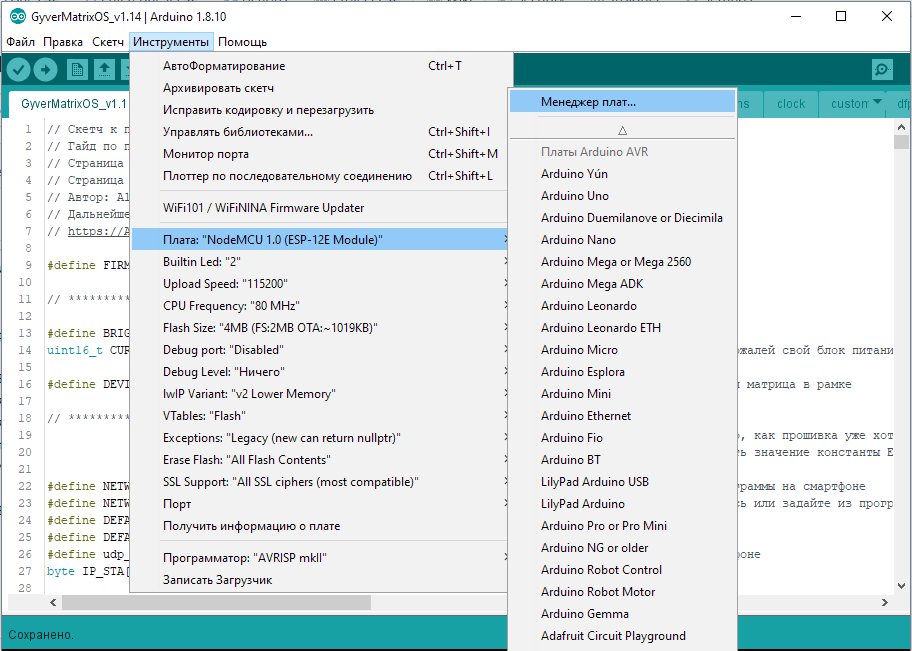
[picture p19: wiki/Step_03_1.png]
Менеджер плат


В строке фильтра введите "ESP8266", найдите блок esp8266 by ESP8266 Commumity
Нажмите кнопку "Установка", дождитесь завершения установки.

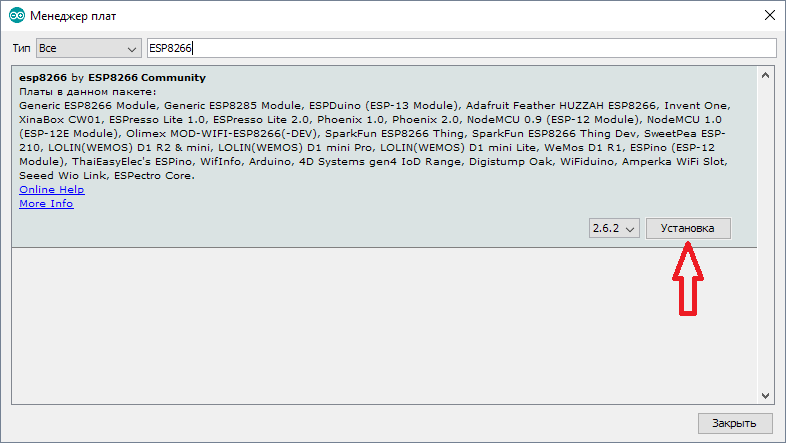
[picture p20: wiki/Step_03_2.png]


В строке фильтра введите "ESP32", найдите блок esp23 by Espressif System
Нажмите кнопку "Установка", дождитесь завершения установки.

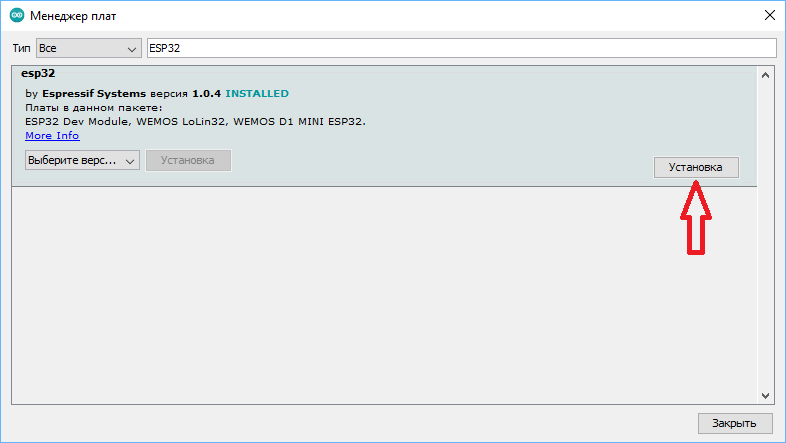
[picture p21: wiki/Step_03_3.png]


Закройте Arduino IDE

## Шаг 4

Перейдите в [репозиторий](https://github.com/vvip-68/GyverPanelWiFi) проекта
Нажмите зеленую кнопку "Clone or download" выберите "Download ZIP"

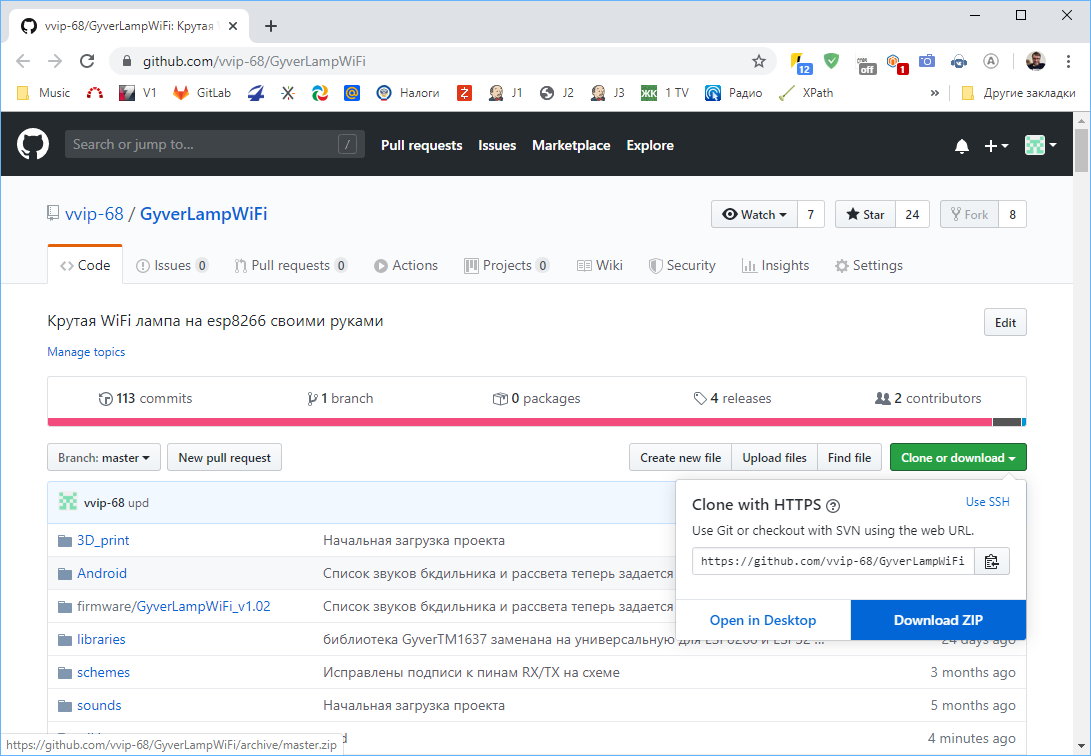
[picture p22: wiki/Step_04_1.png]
Загрузка проекта из репозитория


Сохраните архив на диск, распакуйте его в отдельную папку.

Для тех, кто пользуется утилитами работы с хранилищем GitHub (например, [SmartGit](https://www.syntevo.com/smartgit/download/)) - зарегистрируйте в нем ссылку на репозиторий
https://github.com/vvip-68/GyverPanelWiFi

## Шаг 5
Скопируйте содержимое папки "libraries" из папки проекта, в папку "libraries" установленной среды разработки Arduino
C:\Program Files (x86)\Arduino\libraries

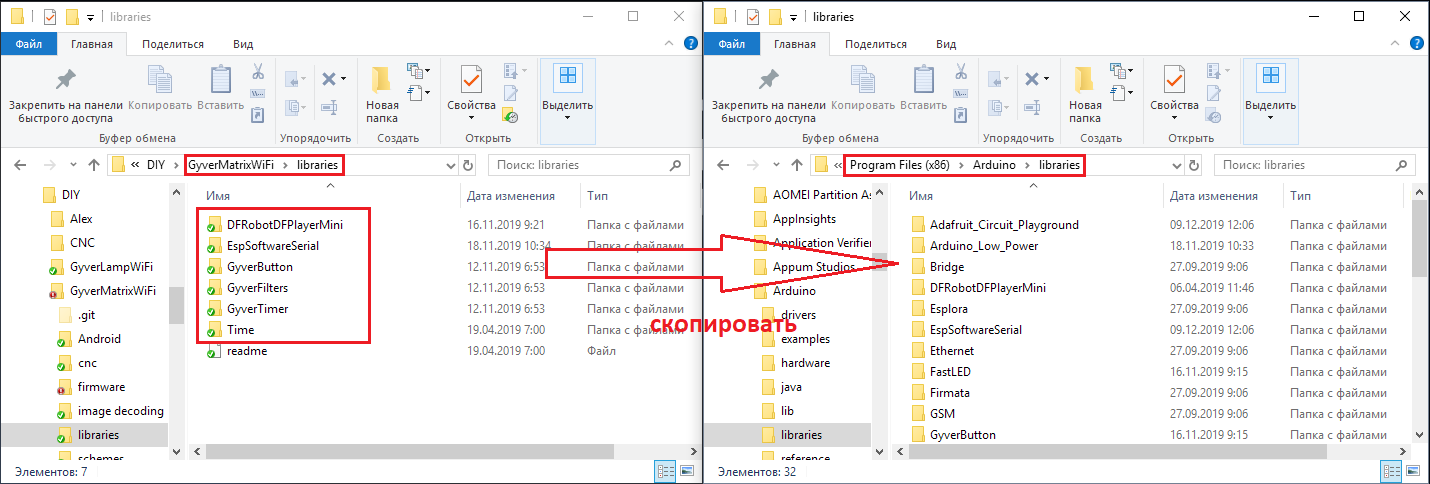
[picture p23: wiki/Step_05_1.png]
Копирование библиотек


## Шаг 6

Запустите Arduino IDE
В меню "Инструменты" выберите пункт "Управлять библиотеками"

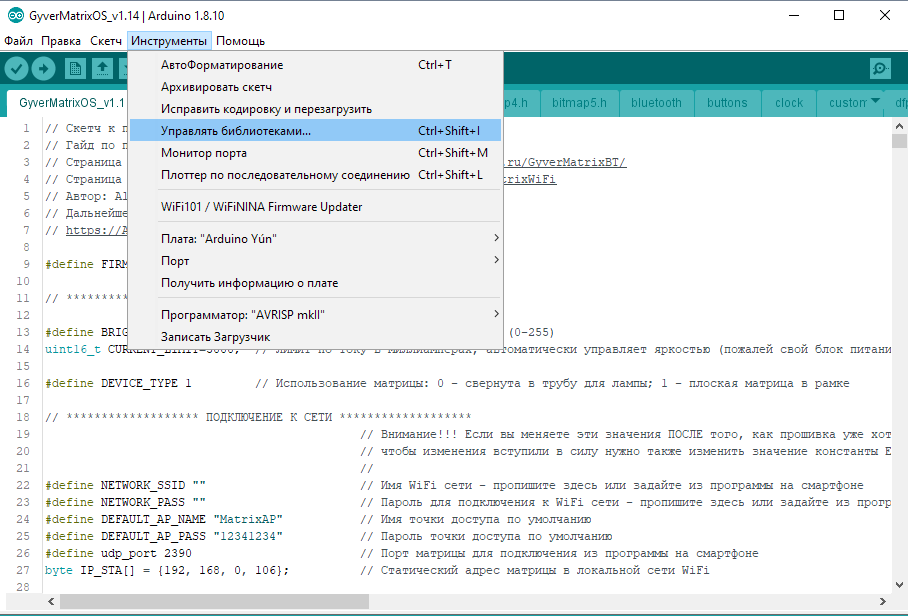
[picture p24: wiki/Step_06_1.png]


A строке поиска наберите "FastLED"
Выберите блок "FastLED by Daniel Garcia", нажмите кнопку "Установка".

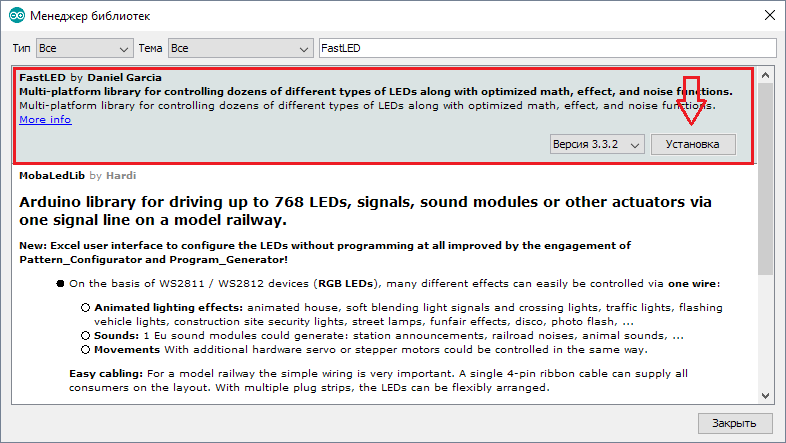
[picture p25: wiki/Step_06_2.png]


Дождитесь завершения установки. Закройте Arduino IDE

## Шаг 7

В проводнике откройте папку с проектом, перейдите в папку "firmware" и далее в папку "GyverPanelWiFi_v1.10"

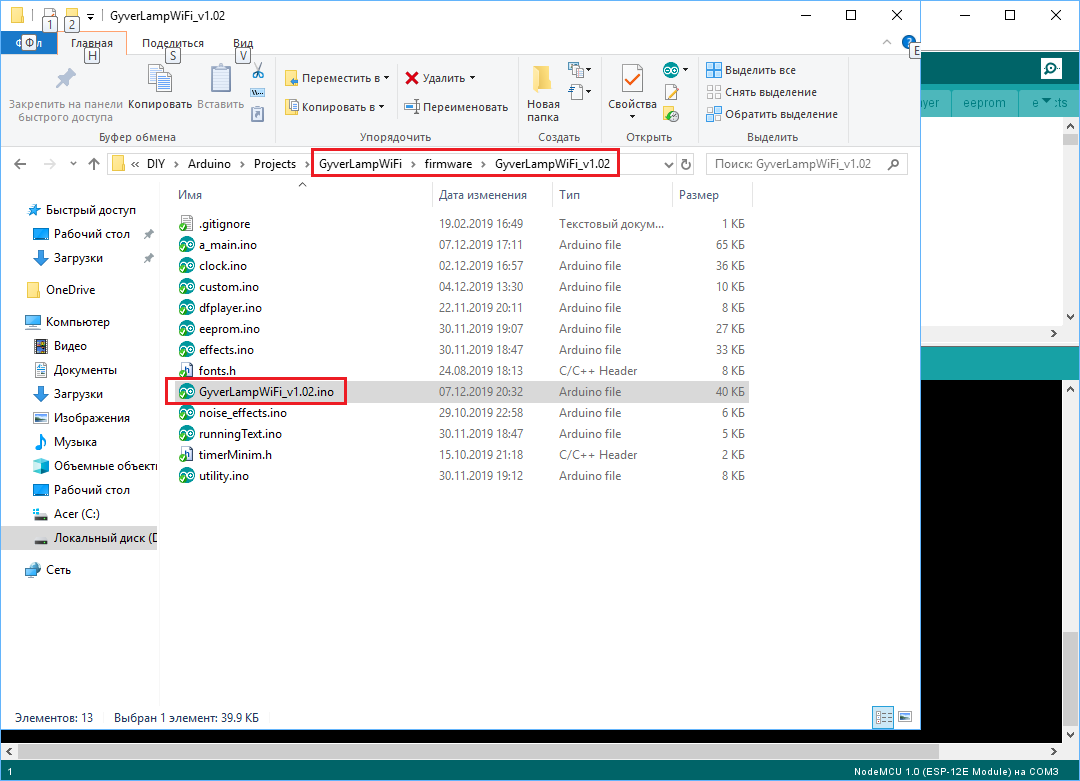
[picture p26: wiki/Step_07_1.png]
Проводник - папка проекта


Дважды щелкните на файле "GyverPanelWiFi_v1.10.ino"
Откроется Arduino IDE с загруженным проектом. Файлы проекта располагаются в разных вкладках. Их несколько.

Редактор кода

В меню "Инструменты" в пункте "Плата" в выпадающем списке выберите плату, соответствующую вашему микроконтроллеру.
В данном проекте используется плата микроконтроллера NodeMCU v1.0 или Wemos D1 pro mini.
В обоих случаях рекомендуется установить настройки как показано на рисунке.

Параметры сборки

Подключите плату микроконтроллера кабелем micro-USB к компьютеру.
Установите драйверы, соответствующие вашей плате (CH340G или CP2101) если они не установились автоматически при подключении контроллера.

Откройте менеджер устройств, найдите в группе "Диспетчер устройств" ветку дерева "Порты COM и LPT"

Управление компьютером

Найдите COM-порт, соответствующей вашей подключенной плате.

Менеджер устройств

Укажите данный порт в настройках - в меню "Инструменты", пункт "Порт"

## Шаг 8

Измените в скетче [параметры](https://github.com/vvip-68/GyverPanelWiFi/wiki/%D0%9D%D0%B0%D1%81%D1%82%D1%80%D0%BE%D0%B9%D0%BA%D0%B0-%D1%81%D0%BA%D0%B5%D1%82%D1%87%D0%B0-%D0%B4%D0%BB%D1%8F-%D0%B2%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),
соответствующие вашему проекту - высоту, ширину матрицы, угол подключения, направление ленты и другие, которые требуется изменить для вашего проекта.
Проверьте, что проект компилируется без ошибок. Для этого нажмите на кнопку "Проверить" в панели инструментов Arduino IDE.

Проверка скетча

Дождитесь окончания сборки проекта компилятором. Об успешном окончании сборки свидетельствуют белые буквы на черном фоне внизу окна редактора. 

Если белые буквы появились, обращать внимание на расположенные выше них оранжевые не нужно. Это диагностические сообщения библиотек. 

Если белых букв не появилось, вместо этого напечаталось сообщение об ошибке - читайте его внимательно, включая весь текст выше и устраняйте причину ошибки.

## Шаг 9

Если сборка проекта завершилась без ошибок - можно скетч загружать в микроконтроллер.
Подключите контроллер к USB кабелем micro-USB, выберите порт к которому подключена плата микроконтроллера, откройте монитор порта, нажав на кнопку в правом верхнем углу окна Arduino IDE.

При необходимости перед присоединением кабеля USB к контроллеру, подключите дополнительное питание к компонентам вашего собранного проекта. 

Загрузка скетча

Нажмите на кнопку "Загрузка" для загрузки скетча в микроконтроллер. Дождитесь завершения операции загрузки. 

Загрузка скетча

В черном поле редактора будут отображаться служебные сообщения, а так же прогресс загрузки в процентах.
После завершения операции появится надпись "Leaving... Hard resetting via RTS pin..."

Микроконтроллер автоматически перезагрузится и начнет выполнение скетча.
В мониторе порта отобразится журнал работы приложения, подтверждающий успешное завершение операции и выполнение скетча

Загрузка скетча

Для завершения процесса сборки устройства установите Android-приложение и [выполните настройку](https://github.com/vvip-68/GyverPanelWiFi/wiki/%D0%9D%D0%B0%D1%81%D1%82%D1%80%D0%BE%D0%B9%D0%BA%D0%B0-%D0%BF%D0%B0%D1%80%D0%B0%D0%BC%D0%B5%D1%82%D1%80%D0%BE%D0%B2-%D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)
подключения устройства к сети и параметов режимов работы.

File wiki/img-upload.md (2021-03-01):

# Загрузка изображений в файловую систему МК

1. Скачайте плагин для работы с файловой системой микроконтроллера из Arduino IDE

- Для микроконтроллера **ESP8266**
https://github.com/earlephilhower/arduino-esp8266littlefs-plugin

- Для микроконтроллера **ESP32**
https://github.com/lorol/arduino-esp32littlefs-plugin

2. Установите плагин в Arduino IDE:  
 a. Перейдите в папку, где установлена Arduino IDE (обычно `"C:\Program Files (x86)\Arduino\"`)  
 b. Если в папке нет подпапки **tools** - создайте ее, если есть - перейдите в эту папку  
 с. Распакуйте архив **ESP8266LittleFS-2.6.0.zip** для ***ESP8266*** или **ESP32LittleFS.zip** для ***ESP32*** в папку tools - 
    в ней будет создана соответствующая подпапка **ESP8266LittleFS** или **ESP32LittleFS** с файлами плагина  
 d. Перезагрузите Arduino IDE  

3. В папке скетча создайте подпапку **data**

4. В созданной папке data создайте подпапку с именем, соответствующим размерам вашей матрицы. 
   Например для матрицы **16x16** создайте папку **16p16**

5. В созданную папку **16р16** скопируйте файлы картинок из папки **pics/16p16** проекта

6. В Arduino IDE в меню **"Инструменты"** выберите пункт **"ESP8266 LittleFS Data Upload"**

7. Наблюдайте в ArduinoIDE области сообщений ход загрузки файлов, дождитесь сообщения о завершении загрузке и
   о перезагрузке микроконтроллеоа

8. Загрузка файлов завершена.

После выполнения этих действий в приложении на смартфоне ***WiFiPlayer*** будет доступна возможность работы с сохраненными
в файловой системе микроконтроллера картинками.

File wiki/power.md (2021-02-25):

## Заметки о питании

Рабочее напряжение микроконтроллера (логические уровни) - 3.3 вольта.  
Рабочее напряжение матрицы - 4.0 - 5.5 вольт.  
При питающем напряжении с источника питания 4.0-4.8 вольт включение диода не обязательно, т.к уровни логических сигналов на пинах мкроконтроллера и DIN ленты согласуются достаточно хорошо.  
Если же напряжение с блока питания составляет 5.0-5.6 вольта - без включения диода матрица надежно работать не будет из за несогласованности уровней логики.  
Включение кремниевого диода по такой схеме позволяет поднять уровень массы микроконтроллера относительно массы матрицы на 0.6-0.8 вольта в зависимости от диода, 
что в результате повышает уровень логической 1 на выходных пинах микроконтроллера до 3.3+0.6 ~= 3.8-3.9 вольта относительно "земли" матрицы, которые матрица уверенно распознает даже при повышении
напряжения с блока питания до 5.5-6 вольт. Диод можно взять, например, 1N4007 (или другой кремниевый с током не менее 0.5A)  

Корректировка напряжения с блока питания до 5-6 В также обязательна, если вы используете управление питанием матрицы через MOSFET, поскольку большинство распространенных мосфетов
логического уровня надежно открываются лишь при напряжении на затворе не ниже 5 вольт. Схемы управления питанием для P-канального MOSFET IRF4905 и N-канального MOSFET IRF3205 приведены ниже.  

```
# Рекомендация по питанию

Наиболее стабильная работа устройства обеспечивается при питании схемы напряжением 4.6-4.9 вольт (не выше!).
При этом корректирующий диод в зазрыв GND питания микроконтроллера ставить не нужно.
Для схем, использующих DFPlayer, питание на него (VCC) в этом случае подавать с общего плюса питания, 
а не с пина 3.3 вольта микроконтроллера, поскольку пин 3.3 вольта не обеспечивает достаточного 
для потребления DFPlayer'ом тока, что приведет к недостаточной громкости воспроизведения, а в худшем 
случае - выходу из строя микросхемы стабилизатора напряжения 3.3 вольта микроконтроллера.
```

## Управление питанием

Матрица, даже если она "выключена" и ничего не отображает все равно потребляет довольно значительный ток от источника питания.
Микросхемы светодиодов продолжают работать, ожидают поступление сигнала. Для проектов, работающих от аккумуляторов это может
представлять проблему - аккумулятор быстро садится.  

Для исправления этой ситуации с микроконтроллера на управляющий пин выведен сигнал включения / отключения питания матрицы.
Управление питанием реализуется следующими схемами:

P-канальный MOSFET IRF4905 обеспечивает ток питания матрицы 74А при 25 градусах, 52А - при 100 градусах.

SCHEME

N-канальный MOSFET IRF3205 обеспечивает ток питания матрицы 30А при 25 градусах, 40А - при 100 градусах.

SCHEME

Оптрон PC817 - гальваническая развязка и защита пина ESP, а также обеспечивает управление уровнем 3.3 вольта
с которым работает микроконтроллер. Мосфет лучше брать в корпусе TO-220. 
Для обеспечения большого тока питания матрицы MOSFET'ы обязательно устанавливать на радиаторы!
Управляющий сигнал POWER_ON в HIGH для включения питания матрицы, POWER_OFF в LOW для отключения питания матрицы.

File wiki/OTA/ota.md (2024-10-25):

# Обновление по воздуху - ОТА

В некоторых случаях собранное устройство - блок управления матрицей - размещено в местах, доступ к которым затруднён.
Для обновлении прошивки обычным способом - через подключение к компьютеру через USB кабель, требуется отсоединять устройство от матрицы,
вскрывать его корпус для доступа к микроконтроллеру.  

Чтобы упростить процесс обновления микропрограммы устройства в прошивку была введена поддержка обновления "по воздуху" - 
Over the Air (ОТА).  

## Обновление по воздуху

OTA

Для беспроводного обновления прошивки выполните следующие шаги:  

### Шаг 1

Запустите **Arduino IDE**. В меню **"Инструменты"** нажмите на пункт **"Порт"**.
Если ваше устройство работает уже какое-то время, роутер знает его адрес и предоставляет список
обнаруженных активных устройств среде IDE. Этот список доступен в выпадающем подменю, открывающемся
при выборе меню **"Порт"**.   

```
В некоторых случаях в точно знаете, что устройство в сети, его интерфейс доступен в браузере, но Arduino IDE упорно
не находит его в сети и его IP-адрес отсутствует в меню "Порт". Причина такого поведения неизвестна. Возможно это ошибка
Arduino IDE. Во всяком случае замечено, что Arduino IDE версий 2.x обнаруживают активные устройства в сети
гораздо быстрее и стабильнее.

Если Arduino IDE версии 1.8.xx не видит устройство в сети, попробуйте следующее:
1. Закройте Arduino IDE
2. Выключите роутер, подождите, и через некоторое время включите его обратно.
3. Запустите Arduino IDE.

В некоторых случаях после выполнения этих действий работающее устройство находится в сети.
Если устройство так и не обнаружено - отложите затею беспроводного обновления на некоторое время.
Возможно на следующий день ситуация исправится сама собой.
```

### Шаг 2

После того как сетевой порт назначенный вашему устройству выбран, нажмите в Arduino IDE  кнопку "Загрузить",
как это делается при обычном обновлении по кабелю.  

Дождитесь завершения компиляции скетча и окончании его загрузки в микроконтроллер по воздуху.  

OTA

В Arduino IDE вы увидите надпись ***`Uploading...`***, затем **"Загрузка завершена"** в строке статуса терминала Arduino IDE.  

### Шаг 3

Если в прошивке обновился Web-интерфейс, его файлы также должны быть выгружены в файловую систему микроконтроллера.
К этому моменту у вас уже должны быть [установлены плагины](https://github.com/vvip-68/LedPanelWiFi/wiki/Загрузка-данных-в-файловую-систему-МК) 
для работы с файловой системой микроконтроллера LittleFS.  

OTA

Убедитесь, что в меню **"Инструменты"** в пункте **"Порт"** по прежнему выбран сетевой порт, принадлежащий вашему устройству.
Нажмите в меню пункт **"ESP8266 LittleFS Data Upload"**, если устройство собрано на микроконтроллере ESP8266 (Wemos d1 mini, NodeMCU) или
**"ESP32 LittleFS Data Upload"**, если устройство собрано на базе микроконтроллера ESP32.  

### Шаг 4

Ожидайте завершения операции. После того, как загрузка файлов будет выполнена, в строке статуса терминала Arduino IDE
появится надпись **"LittleFS Image Uploaded"**.  

OTA

Микроконтроллер устройства автоматически перезагрузится и устройство продолжит свою работу.  
На этом процесс обновления прошивки по воздуху завершен.

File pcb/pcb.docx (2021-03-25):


Плата разработана в Sprint Layout 6.0. Односторонняя чтобы легко повторить в домашних условиях (напр. с помощью лазерного принтера и утюга). Часть деталей (smd резисторы, конденсаторы, диоды, npn транзисторы, n-канальный MOSFET) снята с материнских плат. Остальное (esp-12f, кнопка, разъемы, 1117-33) куплено в интернет магазине. Для прошивки выведен раъем для usb-uart (у меня как на картинке, но в интернете их великое множество)


Кнопка сброса в принципе не нужна. Тогда и пара деталей под ней тоже.


Сделал вход ADC. Может когда пригодится. А пока резисторы 100К и 220К тоже не нужны. Если не нужен MOSFET, то можно замкнуть там где обведено красным и не запаивать то что обведено синим.

Здесь питание DFPlayer 5В. MicroSD, TM1637 и TTP223 питаются от 3.3В. Если тач кнопка не нужна, то обычная не использует контакт «+».


Для microSD я применил такую. Поэтому на плате именно такой порядок контактов.

Для WS2812 не ставил разъем. Сразу впаял кабель с разъёмом (взят из матрицы с неиспользуемого выхода)

В итоге все пины esp-12f подключены как показаны в ESP8266_ALL.jpg и в a_def_hard.h

#define LED_PIN D2 // пин ленты

#define PIN_BTN RX // кнопка подключена сюда (D9 --- КНОПКА --- GND)

#define POWER_PIN D1 // управляющий пин вкл/выкл матрицы через MOSFET / реле; POWER_ON - HIGH, POWER_OFF - LOW

#define SD_CS_PIN D8 // пин выбора SD карты - ChipSelect; Также SD карта использует D5 (CLK), D6 (MISO), D7 (MOSI)

#define STX D3 // подключен в RX пин (2) модуля DFPlayer

#define SRX D4 // подключен в TX пин (3) модуля DFPlayer

#define DIO D0 // TM1637 display DIO pin

#define CLK TX // TM1637 display CLK pin


А выглядит у меня как-то так.

Евгений Прошкин

март 2021

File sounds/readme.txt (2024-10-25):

Набор звуков для часов - будильника, рассвета, звуки текстовой строки и говорящих часов
Файлы находится в соответствующих папках по ссылке
https://drive.google.com/drive/folders/1Xh0CW_GjQMlhbkPjJ34w1UVbuB9aOjP3?usp=sharing

Скачайте файлы и разместите их на SD карточке для MP3-плеера в такие же папки

01 - звуки будильника
02 - звуки рассвета
03 - звуки текстовой строки

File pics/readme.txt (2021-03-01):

Примеры сохраненных картинок, нарисованных пользователем
Имя папки определяет размер матрицы, например "16p16" - картинки для матрицы 16х16

Для того, чтобы WiFiPlayer увидел эти картинки - скопируйте папку с картинками, соответстующую размерам вашей матрицы
на SD-карту или во внутреннюю память микроконтроллера.

Установка плагина для работы с файловой системой (внутренней памятью) микроконтроллера и инструкция по загрузке картинок - 
в папке проекта "tools/LittleFS_Uploader", файл "readme.txt"

После перезагрузки контроллера и перезапуска приложения WiFiPlayer картинки будут доступны для загрузки и отображения на матрице.

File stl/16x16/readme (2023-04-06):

Файлы решёток для сборных матриц из 16х16 для печати на 3D-принтере
от Aleksandr

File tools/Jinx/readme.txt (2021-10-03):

0 Создайте папку для работы с Jinx> например "work"
1. Распаковать архив jinx-2.4.zip в созданную папку work
2. Скачайте архив с gif-картинками, использующимися в эффектах из https://drive.google.com/file/d/1kcc4bdjTrMEvEoL1LI-N9i0ZEnaoGTZM/view?usp=sharing   
   Создайте папку 'pics' в папку work (рядом с папкой 'jinx') распакуйте туда gif-ки из скачанного архива pics.7z
3. В папку work поместить *.jnx файлы с эффектами
4. Запустить jinx.exe из папки jinx
5. Открыть выбранный файл с эффектами *.jnx

Эффекты используют скрипт "Image Viewer" который проигрывает анимацию gif-ок, 
размещенных в папке pics, поэтому такая структура папок - обязательно, иначе
Image Viewer не найдет картинку на основе которой создан эффект.
Если gif-ка не произрывается - нажмите кнопку 'Edit' у скрипта с Image Viewer
и найдите по имени файла картинку, которую тот использует.

Примеры эффектов для матриц соответствующего разрешения можно скачать по ссылке
https://drive.google.com/drive/folders/1Xh0CW_GjQMlhbkPjJ34w1UVbuB9aOjP3?usp=sharing

Обработка роликов, захваченных с Jinx возможна утилитой из соседней папки - "JinxFramer"

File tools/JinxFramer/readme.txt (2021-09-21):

Утилита просмотра, "подрезания" и редактирования роликов, подготовленных и захваченных программой Jinx! 
эффектов для воспроизведения их с SD-карты на матрице. 
Файлы в формате Glediator (*.out)

Также поддерживается создание новых роликов покадрово и сохранение их в файлы в формате Glediator (*.out),
сохранение отдельного кадра из ролика в формате картинок, принимаемых матрицей (*.p),
а также экспорт отдельного кадра или ролика в целом в код эффекта анимации, 
включаемый в скетч для компиляции в эффект "Анимация".

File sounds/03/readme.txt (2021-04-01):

Звуки отбивки каждого часа, если включен часовой сигнал в часах
Звуки нотификации (привлечения внимания) для макроса {A} в бегущей строке

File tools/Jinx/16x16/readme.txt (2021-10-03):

Примеры эфффектов, экспортированных из Jinx!
Конфигурация матрицы - 16x16, подключение - левый нижний угол, зигзаг, направление от угла - вправо

#define WIDTH 16              // ширина матрицы
#define HEIGHT 16             // высота матрицы
#define MATRIX_TYPE 0         // тип матрицы: 0 - зигзаг, 1 - параллельная
#define CONNECTION_ANGLE 0    // угол подключения: 0 - левый нижний, 1 - левый верхний, 2 - правый верхний, 3 - правый нижний
#define STRIP_DIRECTION 0     // направление ленты из угла: 0 - вправо, 1 - вверх, 2 - влево, 3 - вниз

Распакуйте эти файлы в папку 16х16 на SD-карту
Тип матрицы для этих файлов - Лево-Низ зигзаг вправо

Файлы доступны в соответствующей папке по ссылке
https://drive.google.com/drive/folders/1Xh0CW_GjQMlhbkPjJ34w1UVbuB9aOjP3?usp=sharing

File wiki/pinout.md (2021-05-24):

## Подключение периферии к пинам микроконтроллера

Пользователь Dimansion (7918514) провел большое исследование по вариантам подключения
различных компонент периферии - кнопки, индикатора, реле, матрицы - к пинам микроконтроллера.

Результаты исследования приведены в таблице:

SCHEME

### Примечания

1. Порты, отмеченные красным сразу после прошивки иногда работают, но после перезапуска модуля (снимал и подавал питание) работать прекращают.  
2. При использовании портов D9 (RX) и D10 (TX) при прошивке через кабель нужно отключать от них периферию.  
3. По OTA обновляется все норм, без отключения периферии.  
4. Включение в прошивку часов TM1637 очень сильно замедляет некоторые эффекты (может все), на максималках это хорошо видно. Для обычных скоростей это не критично.

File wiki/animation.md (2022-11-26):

# Добавление своей анимации к эффекту «Анимация»

1. С помощью утилиты [JinxFramer](https://github.com/vvip-68/GyverPanelWiFi/wiki/JinxFramer---редактор-анимации,-роликов,-картинок) подготовьте кадры анимации и экспортируйте их в файл скетча для включения в проект.  

> Для примера взята анимация "Пятнашки", экспортированная из ролика Jinx! "Fifteens.out" в файл кода ***"fifteens.h"***  
При необходимости после сохранения файла ***"fifteens.h"*** - отредактируйте параметры анимации в структуре типа **animation_t** с именем 
**animation_fifteens**, размещенной в конце этого файла.

```   
   const animation_t animation_fifteens PROGMEM = {
     ...
   }
```   

2. Поместите отредактированный файл *"fifteens.h"* с кадрами анимации в папку проекта со скетчем  

3. В файле *animation.ino* в строках начиная с 79 найдите блок описания файлов анимации и добавьте в #include ваш файл анимации
```
   #include fifteens.h 
```

4. В файле *animation.ino* в строках, начиная с 84 добавьте имя описателя вашей анимации, как это сделано для других анимаций, 
   определенных в скетче. Имя описателя анимации смотрите в вашем подключенном файле анимации.
```
const animation_t animations[] = {
  animation_heart,
  animation_mario,
  animation_weather,
  animation_fifteens
};
```

5. В файле *animation.ino* - в строке 90 добавьте имя вашей анимации к списку  
```
   #define IMAGE_LIST F("Сердце,Марио,Погода,Пятнашки")
```

6. Скомпилируйте скетч и загрузите его в микроконтроллер.  
   Добавленная анимация должна появиться в приложении ***WiFiPanel*** на телефоне в эффекте **"Анимация"**, в комбобоксе выбора анимации.

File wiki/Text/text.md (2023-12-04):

### Настройка бегущей строки:
#### Общие правила
- Поддерживается 36 строк, каждая строка имеет номер '0'..'9','A'..'Z'
- "Макрос" - последовательность управляющих конструкций, каждая из которых заключена в фигурные скобки, например '{Exx}'
- Строка с индексом '0' является управляющей строкой, содержащей индексы строк, определяющие в какой последовательности они должны отображаться на матрице.
- Если строка с индексом '0' начинается с '#' - строка содержит последовательность строк к отображению, например '#123ZYX'  
  Эта последовательность задает порядок отображения строк '1','2','3','Z','Y','X' и далее по циклу
- Если строка с индексом '0' содержит только значение '##' - строки отображаются в случайном порядке
- Если строка пустая, начинается с '-' или содержит '{-}' - строка отключена и не отображается
- Суммарный размер всех заданных строк не должен превышать 1500 символов, в противном случае строки, выходящие за размер не сохранятся

#### Макросы 
- **{-}**   в любом месте строки означает, что строка временно отключена, аналогично '-' в начале строки
- **{#n}**  в любом месте строки означает, что после отображения этой строки будет немедленно отображена строка с номером n, где n - 1..35 или '1'..'9','A'..'Z'
- **{An+}** при наличии MP3 DFPlayer воспроизводить звук n из папки SD://03; Если указан необязательный суффикс '+' - звук зацикливается пока отображается строка.
- **{Exx}** строка отображается на фоне эффекта XX, где XX - номер эффекта. Эффект не меняется, пока строка не будет полностью отображена
- **{Exx-n}** строка отображается на фоне эффекта XX вариант n, где XX - номер эффекта, n - номер варианта.
- **{Ts}**  отображать строку указанное количество секунд s
- **{Nx}**  отображать строку указанное количество (x) раз подряд
- **{Cc}**  отображать строку указанным цветом. Цвет 'c' задается в web-формате #RRGGBB  
            Если в строке только один макрос цвета текста, расположенный **в самом начале** или в **самом конце** строки - вся строка выводится указанным цветом  
            Если в строке содержится несколько макросов определения цвета или макрос задан посередине строки, строка выводится указанными цветами:  
  - от начала строки до первого макроса цвета - глобальным значением цвета, который задается в программе на телефоне в настройках бегущей строки
  - от позиции макроса цвета до следующего макроса цвета или до концв строки - цветом, определенным в макросе
            Специальные значения цветов:  
  -  #000001 - радужные буквы вдоль текста  
  -  #000002 - каждая буква отдельным цветом
- **{Bc}**  отображать строку на однотонном фоне. Цвет фона 'c' - задается в формате #RRGGBB, например для черного цвета макрос имеет вид ```{B#000000}```  
- **{WS}**  вставить в строку текущее состояние погоды (ясно, пасмурно, дождь и т.п.)
- **{WT}**  вставить в строку текущую температуру
- **{D}**   отображать часы вида ЧЧ:MM на месте макроса
- **{D:f}** отображать часы в указанном формате f, гдее f может содержать в себе:  
  -    **d** или **D**       - день месяца в диапазоне от 1 до 31  
  -    **dd** или **DD**     - день месяца в диапазоне от 01 до 31  
  -    **ddd** или **DDD**   - сокращенное название дня недели (пон - вск)  
  -    **dddd** или **DDDD** - полное название дня недели (понедельник - воскресенье)  
  -    **М**                 - месяц от 1 до 12  
  -    **ММ**                - месяц от 01 до 12  
  -    **МММ**               - месяц прописью (янв - дек)  
  -    **MMMM**              - месяц прописью (января - декабря)  
  -    **y** или **Y**       - год от 0 до 99  
  -    **yy** или **YY**     - год от 00 до 99  
  -    **yyyy** или **YYYY** - текущий год в виде четырехзначного числа  
  -    **yyy+** или **YYY+** - следующий год в виде четырехзначного числа  
  -    **h**                 - час в 12-часовом формате от 1 до 12  
  -    **hh**                - час в 12-часовом формате от 01 до 12  
  -    **H**                 - час в 24-часовом формате от 0 до 23  
  -    **HH**                - час в 24-часовом формате от 00 до 23  
  -    **m**                 - минуты от 0 до 59  
  -    **mm**                - минуты от 00 до 59  
  -    **s** или **S**       - секунды от 0 до 59  
  -    **ss** или **SS**     - секунды от 00 до 59  
  -    **t** или **T**       - первый символ указателя am/pm или AM/PM  
  -    **tt** или **TT**     - указатель am/pm или AM/PM  
- **{Rdate time#N}** оставшееся до события время, где  

    **date** - дата события в формате ДД.ММ.ГГГГ  
               В дате допускается использовать символы-заменители:  
               - День  `'**'`   - означает любой день  
               - Месяц `'**'`   - означает любой месяц   
               - Год   `'****'` - означает текущий год  
               - Год   `'***+'` - означает следующий год  

    **time** - время события в формате ЧЧ:ММ:CC  
               Время может быть опущено, тогда принимается 00:00:00
    **N**    - индекс строки (1..9,A..Z или 1..35) отображаемой ПОСЛЕ наступления события.  
               Если N не указана - после наступления события, строка отображаться не будет.  

  При использовании в части заменителя года значения '\*\*\*\*' или '\*\*\*+' при смене года текст "До Нового года осталось {R01.01.\*\*\*+}\#N"  
  строка '#N' никогда не будет показана, поскольку при наступлении даты события год сменится и будет выводиться текст 
  "До Нового года осталось 365 дней".  

  Чтобы избежать такого развития событий, рекомендуется макрос {R} использовать совместно с макросом {S}, ограничивающим период вывода строки:
```  
  "До Нового года осталось {R01.01.***+}{S01.12.****#31.12.**** 23:59:59}"
  "До Нового года осталось {R31.12.**** 23:59:59}{S01.12.****#31.12.**** 23:59:59}"
```
  
  Время, оставшееся до наступления события, показывается в соответствии с правилами:  
  -   осталось более 7 дней - *'XX дней'*  
  -   осталось 7 дней и менее - *'XX дней XX часов'*  
  -   осталось менее 1 дня - *'XX часов XX минут'*  
  -   осталось менее 1 часа - *'XX минут'*  
  -   осталось менее 1 минуты - *'XX секунд'*  

  Если событие уже прошло, вместо строки, содержащей макрос показывается строка-заместитель с номером N, где N - индекс 1..35 или '1'..'9','A'..'Z'.  
  Для того, чтобы строка-заместитель не показывалась как обычная строка, не связанная с событием - она должна быть "отключена" - то есть - начинаться с '-' или иметь внутри макрос отключения '{-}'.  
  Если вы забудете отключить строку-заместитель, она будет отключена автоматически при воспроизведении родительской строки-события.  
  Если строка-заместитель не указана - строка с наступившим событием не показывается.  
  
- **{Pdate time#N#B#A#W}** оставшееся до события время, где  
    **date** - дата события в формате ДД.ММ.ГГГГ  
               - дата может быть опущена, указано только время, что означает "каждый день в указанное время"  
               - любой компонент даты может быть заменен звездочкой ```'*'```, что означает "любой"  
               ```**.01.2020``` - "весь январь 2020 года"  
               ```**.01.****``` - "весь январь каждого года"  
               ```01.**.2020``` - "каждое 1-е число месяца 2020-го года"  
               ```01.09.****``` - "каждое 1-е сентября"  
               ```**.**.2020``` - "весь 2020-год, каждый день"  
    **time** - время события в формате ЧЧ:ММ  
               - если время не указано - означает 0:00  
    **N**    - индекс строки (1..9,A..Z или 1..35) отображаемой ПОСЛЕ наступления события.  
    **B**    - количество секунд ДО наступления события, когда начинает отображаться строка  
    **A**    - количество секунд ПОСЛЕ наступления события, когда отображается строка-заместитель  
    **W**    - дни недели 1-пн..7-вс когда отображается бегущая строка  

  Дата или время должны быть указаны обязательно, остальные элементы могут последовательно опускаться, тогда они будут иметь значения по умолчанию:
    - нет строки заместителя, если опущены элементы #N#B#A#W
    - количество секунд ДО события - 60, если опущены элементы #B#A#W
    - количество секунд ПОСЛЕ события - 60, если опущены элементы #A#W
    - ограничения по дням недели - '1234567', если опущен элемент #W

  Строка, содержащая макрос {P} не отображается регулярно как строки с прочими макросами.  
  Эта строка отображается только за #B секунд до наступления события, затем #A секунд ПОСЛЕ наступления события отображается строка-заместитель, 
  если в макросе присутствует элемент #N и указываемая им строка не пустая.

  Если указана конкретная дата и день недели, но указанная дата не является этим днем недели - строка отображаться не будет.  

  Для того, чтобы строка-заместитель не показывалась как обычная строка, не связанная с событием - она должна быть "отключена" - то есть - начинаться с '-' или иметь внутри макрос отключения '{-}'.  

  Пример:  
    Строка D: ```Подъем через {P7:00#E#60#60#12345}```  
    Строка E: ```-Доброе утро!```  

  Каждый будний день в 6:59 до 7:00 будет отображаться обратный отсчет до пробуждения, затем с 7:00 до 7:01 отображается надпись "Доброе утро!"

  Пример:  
    Строка D: ```Трансляция начнется через {P01.11.2020 19:30#E#180#60}```  
    Строка E: ```Все на футбол!{-}```  

  1 ноября 2020 года за три минуты до начала трансляции (в 19:27 и до 19:30) начнется обратный отсчет оставшегося до трансляции времени. 
  В 19:30 и до 19:31 будет отображаться бегущая строка с текстом "Все на футбол!"

  Пример:  
    Строка D: ```До Нового года осталось {P01.01.****#E#60#60}```  
    Строка E: ```-С Новым годом!!!!```  

  За минуту до наступления каждого Нового года начнет отображаться бегущая строка с обратным отсчетом. 
  С наступлением Нового года, пока бьют куранты 1 минуту показывается бегущая строка "С Новым годом!!!"

- **{Sdate1 time1#date2 time2}** период отображения строки, где  
    **date1** - дата начала периода в формате ДД.ММ.ГГГГ  
    **time1** - время начала периода в формате ЧЧ:ММ:CC  
    **date2** - дата окончания периода в формате ДД.ММ.ГГГГ  
    **time2** - время окончания периода в формате ЧЧ:ММ:CC  

     - дата может быть опущена, указано только время, что означает "каждый день в указанное время"  
     - любой компонент даты может быть заменен звездочкой ```'*'```, что означает "любой"  
       ```**.01.2020``` - "весь январь 2020 года"  
       ```**.01.****``` - "весь январь каждого года"  
       ```01.**.2020``` - "каждое 1-е число месяца 2020-го года"  
       ```01.09.****``` - "каждое 1-е сентября"  
       ```**.**.2020``` - "весь 2020-год, каждый день"  

     - если указана только дата начала периода - датой окончания будет считаться конец указанного дня - та же дата, время 23:59:59
     - если указана только дата окончания периода - датой начала будет считаться начала указанного дня - та же дата, время 00:00:00
     - если время начала периода не указано - означает 00:00:00  
     - если время окончания периода не указано - означает 23:59:59  
     - допускается указывать несколько макроcов {S} в строке для определения нескольких разрешенных диапазонов

  Примеры:
    ``` "С Рождеством!{S07.01.2020}"```  - один день только 7 января 2021 года (весь день с 0:00 до 23:59)
    ``` "С днем Победы!{S09.05.**** 09:00#09.05.**** 21:00}"``` - каждый год 9 мая с 9:00 до 21:00
    ``` "Ура, каникулы!!!{S01.01.****#12.01.****}{S01.04.****#08.04.****}"``` - каждый год в период с 1 по 12 января и с 1 по 8 апреля

### Номера эффектов для макроса {Exx}
- **1** - "Лампа"
- **2** - "Снегопад"
- **3** - "Кубик"
- **4** - "Радуга"
- **5** - "Пейнтбол"
- **6** - "Огонь"
- **7** - "The Matrix"
- **8** - "Шарики"
- **9** - "Звездопад"
- **10** - "Конфетти"
- **11** - "Цветной шум"
- **12** - "Облака"
- **13** - "Лава"
- **14** - "Плазма"
- **15** - "Радужные переливы"
- **16** - "Полосатые переливы"
- **17** - "Зебра"
- **18** - "Шумящий лес"
- **19** - "Морской прибой"
- **20** - "Смена цвета"
- **21** - "Светлячки"
- **22** - "Водоворот"
- **23** - "Циклон"
- **24** - "Мерцание"
- **25** - "Северное сияние"
- **26** - "Тени"
- **27** - "Лабиринт"
- **28** - "Змейка"
- **29** - "Тетрис"
- **30** - "Палитра"
- **31** - "Спектрум"
- **32** - "Синусы"
- **33** - "Вышиванка"
- **34** - "Дождь"
- **35** - "Камин"
- **36** - "Водопад"
- **37** - "Стрелки"
- **38** - "Анимация"
- **39** - "Погода"
- **40** - "Жизнь"
- **41** - "Узоры"
- **42** - "Кубик Рубика"
- **43** - "Звезды"
- **44** - "Штора"
- **45** - "Рассвет"
- **46** - Эффекты с SD карты

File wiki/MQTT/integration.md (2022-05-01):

## Интеграция в Умный дом.

После появления в устройстве канала управления через подключение к MQTT-брокеру,  
энтузиасты разработчики реализовали интеграцию устройства в систему Умного дома. 

На этой страничке размещены ссылки на репозитории известных мне проектов интеграции.

1. Интеграция в HgomeAssistant oт **tarasifua**:   
      https://github.com/tarasifua/vvip-68-matrix-home-assistant-integration

2. Интеграция c Домовенком Кузей oт **Krypt0nC0R3**:   
      https://github.com/Krypt0nC0R3/AliceMQTTHandler

3. Интеграция с Алисой через Node Red от **bulava92**  
      https://github.com/bulava92/nodered_matrix

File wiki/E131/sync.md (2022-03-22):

# Синхронизация устройств

- [Общие понятия](#Общие-понятия)
- [Внешние эффекты Jinx!](#Внешние-эффекты-jinx)
- [Настройка синхронизации](#Настройка-синхронизации)
- [Технические аспекты](#Технические-аспекты)
- [Возможные проблемы](#Возможные-проблемы)
- [Настройка  ***"Jinx!"*** как источника эффектов](https://github.com/vvip-68/GyverPanelWiFi/wiki/Настройка-ПО-управления-эффектами-%22Jinx!%22-как-источника-синхронизации-устройств-в-группе).  

## Общие понятия

Прошивка поддерживает синхронизацию эффектов между устройствами. Может быть создано до 10 групп устройств.
Количество устройств в группе - не ограничено. Все синхронизированные устройства должны находиться в одной локальной сети.
Маршрутизатор должен обеспечивать корректную передачу многоадресных UDP пакетов в локальной сети - режим ***multicast***.
Настройку передачи multicast-пакетов в вашем роутере смотрите в документации на роутер.

Сеть

Устройства, объединенные в группу должны содержать одно **главное устройство** - источник (***MASTER***), остальные устройства группы являются **ведомыми** и должны быть настроены для работы в режиме приемник (***SLAVE***).

Прошивка поддерживает до 10 групп устройств - "Группа 0" .. "Группа 9", устройства в каждой группе работают синхронно, группы независимы.

### Режимы работы устройств

Каждое устройство может быть настроено в приложении-компаньоне **"WiFi Panel Setup"** для работы в одном из трех режимов:
- **Автономный режим** - устройство отключено от синхронизации, работает самостоятельно.
- **Источник** (мастер) - задает синхронизацию ведомым устройствам. Ведомые устройства воспроизводят те же эффекты, которые в настоящий момент отображаются на устройстве - источнике. Группа должна содержать не более одного устройства-источника.
- **Приемник** (ведомый) - принимает данные от главного устройства группы, повторяет эффекты, которые в настоящий момент отображает источник - мастер. Количество устройств-приемников в группе не ограничено. 

### Уровни синхронизации

Для корректной работы устройств в группе источник и приемник должны быть настроены на *одинаковые уровни* синхронизации.  
Существуют три уровня синхронизации устройств:
 - **Физическая** синхронизация
 - **Логическая** синхронизация
 - Синхронизация на уровне **команд**

#### Физический уровень

Физический уровень синхронизации является самым быстрым, поскольку полученные от источника пакеты данных не требуют дополнительной обработки и передаются "как есть" на матрицу устройства приемника. Этот режим синхронизации рекомендуется для устройств с большими матрицами, так как требуют минимальное время на обработку принятых данных.

Работа на физическом уровне синхронизации накладывает следующие ограничения на устройства группы:
- Размеры матриц всех устройств группы должны иметь одинаковый размер - высоту и ширину.
- Угол подключения матрицы и направление следования цепочки диодов из угла подключения должны быть одинаковым для всех устройств группы

Несоблюдение этих требований нарушит отображение эффектов - картинка будет искажена/рассинхронизирована. Максимальное количество диодов в матрице для этого режима - 1190. Для увеличения количества диодов (для слишком больших матриц) требуется корректировка кода в скетче. 

Физический уровень синхронизации устройств обеспечивает **абсолютную** синхронизацию устройств. Эффекты на всех устройствах группы будут выглядеть абсолютно синхронно, поскольку устройство-мастер передает устройствам-приемникам "картинку" со своей матрицы.

#### Логический уровень

Логический уровень синхронизации определяет отображение картинки эффекта с позиции (X,Y) = (0,0) - левый верхний угол картинки, направление следования "пикселей" картинки - слева направо по X, затем сверху вниз по Y. Логический уровень синхронизации требует дополнительных затрат на обработку пакетов принятых от мастера, зато нивелирует требование одинаковости угла подключения  и направления из угла матрицы для устройств в группе. Размеры матрицы (высота и ширина) по прежнему должны быть такими же как на устройстве - источнике.

Несоблюдение требования одинакового размера матриц нарушит отображение эффектов - картинка будет искажена/рассинхронизирована. Максимальное количество диодов в матрице для этого режима - 1190. Для увеличения количества диодов (для слишком больших матриц) требуется корректировка кода в скетче. 

Логический уровень синхронизации устройств обеспечивает **абсолютную** синхронизацию устройств. Эффекты на всех устройствах группы будут выглядеть абсолютно синхронно, поскольку устройство-мастер передает устройствам-приемникам "картинку" со своей матрицы.

#### Командный уровень

Командный уровень синхронизации хорошо работает для устройств группы, если размеры их матриц, угол подключения и направление цепочки светодиодов из угла не совпадают. Этот режим не позволяет добиться абсолютной синхронизации устройств, поскольку от ведущего устройства к приемникам передается не "картинка" эффекта, а команды - "включить эффект N", "установить яркость в значение X", "отобразить бегущую строку с текстом xxx" и подобные.

Часть эффектов имеют свои "подрежимы" - например эффект "радуга" имеет разновидности "Вертикальная", "Горизонтальная", "Диагональная", "Вращающаяся", "Случайный выбор". Эффекты "Анимация" или "SD-карта" - набор различных анимаций и роликов в качестве "подрежимов". Устройство приемник, получив от главного устройства команду "Включить эффект N" включит сам эффект, но "подрежимы" включенного эффекта совпадать не будут. Особенности технической реализации командного режима не позволяют синхронизировать варианты эффектов на всех устройствах группы.

Сравнение

## Внешние эффекты Jinx!

Одним из вариантов синхронизации устройств в группе является ***внешняя синхронизация***. В этом режиме в группе нет устройства-источника, все устройства настроены на работу в режиме **"приемник"** (SLAVE). В качестве источника эффектов для отображения на всех устройствах группы используется одна из программ управления световым оборудованием и создания эффектов, поддерживающих протокол SACN E1.31 (DMX-512 over Ethernet) - [***"Jinx!***](http://www.live-leds.de/), ***"Glediator"***,  [***"Wixen lights"***](http://www.vixenlights.com), [***"XLights"***](http://xlights.org/) и подобные.

Сеть

Настройка внешнего источника синхронизации на примере программы управления световым оборудованием ***"Jinx!"*** описана в этой [статье](https://github.com/vvip-68/GyverPanelWiFi/wiki/Настройка-ПО-управления-эффектами-%22Jinx!%22-как-источника-синхронизации-устройств-в-группе).

## Настройка синхронизации

Задание роли для конкретного устройства производится в приложении-компаньоне ***"WiFi Panel Setup"***. Скачайте и установите приложение из архива проекта из папки ***Android***. Создайте учетную запись устройства, задайте имя и укажите его IP. Порт оставьте по умолчанию. Нажмите кнопку "Подключить".

Настройка
Настройка 

Перейдите к разделу "Настройки синхронизации".

Настройка 

Выберите нужный *режим работы* устройства - ***Автономный***, ***"Источник"*** или ***"Приемник"***.  
При выборе режима *"Источник"* или *"Приемник"* станут доступными опции настройки *режима синхронизации*. Выберите нужный.  
Установите в комбобоксе *группу синхронизации*. Этот параметр должен совпадать для всех устройств группы.
Сохраните настройки - нажмите кнопку ***"Сохранить"***. Устройство перейдет в работу в соответствующем настройкам режиме.

Выполните описанные действия для всех устройств группы.
Если мастер-устройство доступно в сети...   
- В режиме синхронизации ***физический*** и ***логический*** картинка с матрицы ведущего устройства (источника) станет незамедлительно отображаться на устройствах, работающих в режиме приемника. После отключения мастера, когда данные потока синхронизации перестанут поступать к приемникам, они перейдут в автономный режим после двухсекундной паузы (в это время они ожидают продолжения поступления данных от мастера).
- В режиме синхронизации ***команды*** устройства приемники получат команду и выполнят синхронизацию в момент смены эффекта на мастер-устройстве.
В случае отключения мастер-устройства (переключение его в автономный режим или выключении питания) устройства приемники продолжат воспроизведение последнего полученного эффекта. Если в настройках приемника задан таймаут перехода из установленного режима к автоматическому перебору эффектов, демо-режим включится автоматически по истечении указанного таймаута.

## Технические аспекты

### Общие сведения о протоколе E1.31

В техническом плане синхронизация устройств основана на протоколе управлением световым оборудованием **E1.31** (***SACN DMX-512 over Ethernet***), разработанным компанией [ESTA](https://tsp.esta.org/tsp/index.html). Спецификация протокола описана в этом [документе](https://tsp.esta.org/tsp/documents/docs/ANSI_E1-31-2018.pdf). Передача данных от источнику к приемнику в данном проекте осуществляется путем отправки многоадресных (*multicast*) пакетов по протоколу UDP, содержащих данные синхронизации - части картинки с матрицы Мастер-устройства или команды управления.

По спецификации **DMX-512** пакет данных управления цифровым оборудованием содержит 512 байт (каналов) управляющей информации. Применительно к матрице, это означает, что в одном пакете могут быть переданы RGB цвета 170 диодов матрицы. Каждый цвет содержит компоненты RGB, занимающие по одному байту. Таким образом, данные пакета позволяют разместить RGB-цвета для 512 / 3 = 170 светодиодов. Размер полезной загрузки пакета - 170 * 3 = 510 байт.

Фабричная матрица содержит 16x16 = 256 светодиодов. Следовательно, для того, чтобы передать полную картинку с матрицы-источника на матрицу приемника требуется более 512 информационных каналов, а именно 256 * 3 = 768 каналов, или два потока по 510 (1) и 268 (2) каналов (170 и 86 светодиодов) соответственно.

Протокол DMX-512 вводит понятие **Вселенная** (*Universe*) - совокупность потоков данных, каждый из которых содержит 512 каналов. Передача каждого такого потока (каждая вселенная) требует выделения отдельного IP адреса. Для передачи многоадресных пакетов для совокупности вселенных выделяется диапазон адресов 239.255.0.0 .. 239.255.255.255. Часть из этого диапазона адресов зарезервирована для служебных целей и не может быть использована (смотри [спецификацию](https://tsp.esta.org/tsp/documents/docs/ANSI_E1-31-2018.pdf) протокола. В общем случае данные для управления световым оборудованием могут содержать до 64000 вселенных по 512 каналов в каждой. На практике же (и в данной прошивке) для передачи данных используется 10 групп, каждая из которых содержит по 7 вселенных. Таким образом, каждая группа может управлять матрицей, состоящей из 7 * 170 = 1190 светодиодов.
```
Ограничение 10 групп 7 вселенных введено из соображений достаточности для большинства проектов 
и при необходимости может быть расширено путем внесения исправлений в код скетча (файл *e131.ino*).
```
Нумерация вселенных начинается с 1. Таким образом, распределение Multicast IP адресов вселенных приведено в следующей таблице:
| Группа | Адреса вселенных |
|---|---|
| **Группа 0** | 239.255.0.1  - 239.255.0.7 |
| **Группа 1** | 239.255.0.8  - 239.255.0.14 |
| **Группа 2** | 239.255.0.15 - 239.255.0.21 |
| **Группа 3** | 239.255.0.22 - 239.255.0.28 |
| **Группа 4** | 239.255.0.29 - 239.255.0.35 |
| **Группа 5** | 239.255.0.36 - 239.255.0.42 |
| **Группа 6** | 239.255.0.43 - 239.255.0.49 |
| **Группа 7** | 239.255.0.50 - 239.255.0.56 |
| **Группа 8** | 239.255.0.57 - 239.255.0.63 |
| **Группа 9** | 239.255.0.64 - 239.255.0.70 |

UDP порт для каждого адреса по стандарту E1.31 используется **5568**

### Реализация в скетче

Для включения поддержки синхронизации устройств найдите в проекте файл *a_def_haed.h*, в нем блок определения параметров оборудования и включите использование синхронизации устройств **`#define USE_E131 1`**:
```
...
#define USE_WEATHER 1           // 1 - использовать получение информации о текущей погоде; 0 - не использовать 
#define USE_E131 1              // 1 - использовать протокол E1.31 для синхронизации устройств
#define BIG_FONT 0              // 0 - шрифт 5x8, 1 - шрифт  10x16; 2 - шрифт 8x13
...
```
После компиляции скетча и загрузки прошивки в проект - настройте роль каждого устройства в группе - один источник на группу, остальные устройства в группе - приемники.

### Как это работает

Для уровня синхронизации ***"Физический"*** после того как изображение эффекта сформировано, выполнено наложение на эффект часов / текста / погоды, непосредственно перед отправкой изображения на диоды матрицы вызывается функция ***sendE131Screen()***. Функция выполняет перебор всех светодиодов в цикле от **0 до NUM_LED-1**, извлекает три байта цвета для каждого светодиода в цепочке в порядке их физического подключения и помещает их в область данных сетевого пакета E1.31. После заполнения пакета первой вселенной группы данными RGB-цвета первых 170 диодов, пакет отправляется в сеть многоадресной рассылкой по адресу соответствующему multicast-адресу первой вселенной группы. Затем формируется новый пакет для следующей вселенной, происходит заполнение данных цветами следующих 170 диодов и отправка пакета в сеть. Это повторяется до достижения последнего светодиода в матрице. Последний пакет может быть не полным, если общее количество светодиодов не кратно 170. После того как отправка данных в сеть устройствам получателям завершена, картинка выводится на матрицу устройства-источника - `FastLED.show()`.

Для уровня синхронизации ***"Логический"*** выполняется похожая последовательность действий, за исключением того, что светодиоды матрицы опрашиваются не в порядке физического следования от *0 до NUM_LED-1*, а сканируя "развертку" изображения начиная с верхнего левого угла матрицы по столбцам (***координата X***), затем по строкам (***координата Y***). Формирование пакетов данных для вселенных группы ничем не отличается от алгоритма для уровня синхронизации *"Физический"*.

На стороне приемника из каждого полученного пакета извлекаются данные RGB-цвета светодиодов, определяется номер диода в цепочке (уровень *"Физический"* или координаты X,Y (уровень *"Логический"*) и отправляются на матрицу.

Несколько иначе обстоят дела для уровня синхронизации ***"Командный"***. В этом случае пакет E1.31 в области данных содержит не триады RGB-цветов светодиодов, а команды, которые должен выполнить приемник при их получении от устройства-источника. Отправка команд мастером выполняется в ключевые моменты алгоритма скетча, например: при смене эффекта, при начале и и завершении отображения текста бегущей строки, при изменении яркости матрицы или параметров эффекта и при других событиях. 

Чтобы отличить пакет с командой от пакета с данными - в первые два байта области данных командного пакета помещается сигнатура - 0xAA, 0x55. Следующие байты данных в командном пакете содержат *код (ID) команды* и ее параметры.

Описание команд и их параметров приведены в следующей таблице:

| № байта | значение |
|---|---|
| **[1]** | 0xAA - сигнатура, байт 1 |
| **[2]** | 0x55 - сигнатура, байт 2 |
| **[3]** | ID команды |
| --- | **Команды** |
| **[3]** | **0** - ***Вкл/выкл устройства*** |
| **[4]** | = x - 0 - выключить 1 - включить |
| --- |  |
| **[3]** | **1** - ***Установить текущую яркость*** |
| **[4]** | x - Значение яркости |
| --- |  |
| **[3]** | **1** - ***Установить текущую яркость специальных эффектов*** |
| **[4]** | x - Значение яркости |
| --- |  |
| **[3]** | **3** - ***Включить эффект*** |
| **[4]** | x - ID эффекта |
| **[5]** | x - скорость эффекта |
| **[6]** | x - контраст эффекта |
| **[7]** | x - спец.параметр №1 |
| **[8]** | x - спец.параметр №2 |
| **[9]**  | r  - значение компоненты R цвета globalColor |
| **[10]** | g  - значение компоненты G цвета globalColor |
| **[11]** | b  - значение компоненты B цвета globalColor |
| **[12]** | W  - ширина матрицы Мастера |
| **[13]** | H  - высота матрицы Мастера |
| --- |  |
| **[3]** | **4** - ***Включить указанный специальный эффект*** |
| **[4]** | x - ID специального эффекта |
| --- |  |
| **[3]** | **5** - ***Включить отображение текста, переданного в параметре*** |
| **[4]** | x - char* null-terminated текст |
| --- |  |
| **[3]** | **6** - ***Остановить отображение бегущей строки, если оно выполняется*** |
| --- |  |
| **[3]** | **7** - ***Установить время*** |
| **[4]** | x - год (без века) -  20xx |
| **[5]** | x - месяц |
| **[6]** | x - день |
| **[7]** | x - часы |
| **[8]** | x - минуты |
| **[9]** | x - секунды |
| --- |  |
| **[3]** | **8** - ***Установить скорость эффекта*** |
| **[4]** | x - скорость |
| --- |  |
| **[3]** | **9** - ***Установить контрастность эффекта*** |
| **[4]** | x - контрастность |
| --- |  |
| **[3]** | **10** - ***Установить параметр 1 эффекта*** |
| **[4]** | x  - значение |
| --- |  |
| **[3]** | **11** - ***Установить параметр 2 эффекта*** |
| **[4]** | x  - значение |
| --- |  |
| **[3]** | **12** - ***Установить globalColor*** |
| **[4]** | r  - значение компоненты цвета R |
| **[5]** | g  - значение компоненты цвета G |
| **[6]** | b  - значение компоненты цвета B |
| --- |  |
| **[3]** | **13** - ***Ширина и высота панели Мастера*** |
| **[4]** | W  - ширина |
| **[5]** | H  - высота |

## Возможные проблемы

- На устаревших роутерах типа DIR-615 замечены неполадки на устройствах-приемниках, работающих в режиме ***SLAVE***  
  - **Проявление**: изображение эффекта с MASTER на устройствах SLAVE отображается не полностью, не на всей матрице, а только на первых 170 диодах. На остальной части матрицы диоды не светятся.  
  - **Причина**: роутер отдает устройствам только первый многоадресный пакет из кадра, остальные пакеты роутером устройству-приемнику не передаются.  
  - **Решение**: обычно решить проблему помогает перезагрузка роутера. Если проблема возникает достаточно часто - рекомендуется замена роутера на более современный.

- Современные роутеры типа TPLink серии Archer имеют ошибку в прошивке.
  - **Проявление**: после выключения питания ведомых устройств роутер перестает отвечать. Пинг на роутер не проходит, Web-страница настройки роутера не открывается. Компьютеры в сети сообщают, что интернет не доступен.
  - **Причина**: ошибка в прошивке роутера.
  - **Решение**: адекватного решения в настоящий момент не существует. Ожидается обновление прошивки роутера. Восстановить доступ в интернет и доступность роутера помогает его перезагрузка. Впрочем, если роутер не трогать, он восстановится самостоятельно через 5-7 минут. Включение питания  устройств-приемников обратно также восстанавливает работоспособность роутера и доступность интернета в течение 20-30 секунд.

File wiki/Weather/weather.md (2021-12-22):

# Настройка сервиса погоды
В настоящее время система способна получать сведения о текущей погоде из двух источников: погодного сервиса **Yandex** и погодного сервиса **OpenServiceMap**.
В тех странах, где по решению правительства заблокирован доступ к сервисам **Yandex**, можно настроить получение текущей погоды с **OpenServiceMap**.  

Найдите в файле **a_def_hard.h** блок с вашими настройками для устройства, в нем строки определения - используется ли сервисы погоды вообще:  
```
#define USE_WEATHER 1         // 1 - использовать получение информации о текущей погоде; 0 - не использовать 
```
Если использование сервиса погоды включено, прошивка будет иметь возможность получать погоду и с Yandex и с OpenWeatherMap.   
Какой именно сервис погоды используется в данный момент определяется настройками в программе управления на смартфоне.

## Настройка погоды с Yandex

Перейдите на сайт [Yandex](http://yandex.com/), введте в строке поиска любой текст и нажмите кнопку "Найти"  

Yandex

В адресной строке браузера найдите часть URL с кодом вашего города.  
Если этого не произошло и вы видите сообщение, что данный сайт заблокирован - в вашей стране получить сведения о погоде с сервиса Yandex не получится.  
Попробуйте настроить получение данных с **OpenWeatherMap**.  

Yandex

Запомните найденный код. После загрузки прошивки в микроконтроллер, подключитесь к устройству со смартфона и
вставьте этот код в поле "Код региона" на странице основных настроек.  

Скачать файл, содержащий список кодов городов можно здесь:  
https://github.com/vvip-68/GyverPanelWiFi/blob/master/wiki/Weather/yandex.ru-yaca-geo.c2n.pdf  
или [здесь](https://github.com/vvip-68/GyverPanelWiFi/blob/master/wiki/Weather/towns.xlsx)  

## Настройка погоды с OpenWeatherMap

Перейдите на сайт [OpenWeatherMap](http://openweathermap.org/)  
Слева от строки поиска и кнопки "Search" найдите значок со стрелочкой навигации и нажмите на него  

OpenWeatherMap

В адресной строке браузера найдите часть URL с кодом вашего города  

OpenWeatherMap

Запомните найденный код. После загрузки прошивки в микроконтроллер, подключитесь к устройству со смартфона и
вставьте этот код в поле "Код региона" на странице основных настроек.  

OpenWeatherMap

Убедитесь в мониторе порта, что устройство соединяется с сервисом и получает необходимые данные о текущей погоде.  

OpenWeatherMap

Если вместо сообщения об успешном получении данных погоды вы видите ошибку (обычно с кодом 401) и/или сообщение о неверном ключе API, выполните следующие действия:  

- Перейдите по [ссылке](https://home.openweathermap.org/users/sign_in) и войдите в свою учетную запись на cервисе OpenWeatgerMap или
создайте ее, если у вас еще нет учетной записи.  

OpenWeatherMap

- Заполните форму, указав в полях свой логин, пароль, оставьте действующий email, согласитесь с условиями и нажмите кнопку "Create Account"  

OpenWeatherMap

- Загляните в свой почтовый ящик - вам придет письмо с просьбой подтвердить регистрацию на сервисе OpenServiceMap  

OpenWeatherMap

- Нажмите на кнопку "Verify your email". Вам на почту придет следующее письмо, в котором указан созданный для вас ключ API  

OpenWeatherMap

- В файле a_def_soft.h в строке 406 найдите следующее:
```
// API-идентификатор сервиса получения погоды  
#define WEATHER_API_KEY "6a4ba421859c9f4166697758b68d889b"
```
и замените ключ на полученный вами в ответном письме. Как правило, ключ активируется в течении 10 минут, реже - до двух часов.  
Дождитесь активации ключа, когда переход по ссылке примера обращения к API из письма в браузере будет возвращать не ошибку, а
JSON с информацией о текущей погоде.  
```
{"coord":{"lon":92.79,"lat":56.01},"weather":[{"id":803,"main":"Clouds","description":"broken clouds","icon":"04d"}],"base":"stations",  
"main":{"temp":-1,"feels_like":-6.3,"temp_min":-1,"temp_max":-1,"pressure":1023,"humidity":80},"visibility":10000,"wind":{"speed":4,"deg":270},  
"clouds":{"all":75},"dt":1604373691,"sys":{"type":1,"id":8957,"country":"RU","sunrise":1604365212,"sunset":1604397872},  
"timezone":25200,"id":1502026,"name":"Krasnoyarsk","cod":200}
```
Загрузите прошивку с новым ключом в устройство. Убедитесь в мониторе порта, что в логах есть информация об успешной загрузке погоды с погодного сервиса.

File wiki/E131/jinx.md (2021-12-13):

# Пошаговая инструкция настройки ПО управления эффектами «Jinx!» как источника синхронизации устройств в группе
## Шаг 1
Перейдите на сайт разработчиков [«Jinx!»](http://www.live-leds.de/downloads/) и скачайте приложение. 
Распакуйте архив с программой в отдельную папку. Запустите приложение

Главное окно Jinx 2.4

## Шаг 2
Программа «Jinx!» поставляется с демо-скриптом, содержащем большое количество настроенных сцен, эффектов и переходов.
Для подключения скрипта примера в меню "File" выберите пункт "Import"  

Import Demo Script  

В окне выбора файла выберите "demo.jnx" и нажмите кнопку "Открыть"  

Import Demo Script  

После того, как скрипт подключен к программе, выбор пункта меню "View Scenelist" (или нажатие кнопки F2) 

Menu Scenelist  

откроет окно выбора доступных сцен.  

Scenelist  

Каждая сцена содержит комбинацию эффектов, результат отображается в реальном режиме времени в панелях предпросмотра в верхней части главного окна Jinx.  
Изучите как работают и комбинируются эффекты. Изменяйте настройки каналов и смотрите как они влияют на результат.  

В интернете вы можете найти большое количество инструкций по созданию эффектов с помощью Jinx,  
доступны видеоуроки в Youtube.

## Шаг 3
Откройте окно настроек матрицы  

Меню Setup / Matrix options  

и задайте размер рабочего поля в пикселях  

Настройки матрицы  

Размер должен соответствовать вашей матрице, которую вы используете в своем проекте

## Шаг 4
Настройте выходное устройство для передачи анимации эффекта устройствам-потребителям.  
В нашем случае программа должна выполнять передачу изображения в сеть по протоколу **E1.31**  

Откройте окно настроек выходных устройств  

Меню Setup / Output devices  

Рассчитайте количество потоков (вселенных), требуемых для передачи изображения на вашу матрицу.  
В данном примере используется матрица размером 16x16 - общее количество светодиодов - 256.  
Одна вселенная вмещает данные RGB-цветов для 170 светодиодов (170 * 3 = 510 каналов).  
Остается 256 - 170 = 86 светодиодов (86 * 3 = 258 каналов), которые могут быть целиком размещены во второй вселенной.  
Таким образом, для матрицы 16x16 достаточно двух вселенных, содержащих 510 и 258 каналов соответственно.

Таблица распределения вселенных по группам синхронизации для этого проекта:
| Группа | Номера вселенных | IP адреса |
|---|---|---|
| **Группа 0** | 1-7 | 239.255.0.1  - 239.255.0.7 |
| **Группа 1** | 8-14  | 239.255.0.8  - 239.255.0.14 |
| **Группа 2** | 15-21 | 239.255.0.15 - 239.255.0.21 |
| **Группа 3** | 22-28 | 239.255.0.22 - 239.255.0.28 |
| **Группа 4** | 29-35 | 239.255.0.29 - 239.255.0.35 |
| **Группа 5** | 36-42 | 239.255.0.36 - 239.255.0.42 |
| **Группа 6** | 43-49 | 239.255.0.43 - 239.255.0.49 |
| **Группа 7** | 50-56 | 239.255.0.50 - 239.255.0.56 |
| **Группа 8** | 57-63 | 239.255.0.57 - 239.255.0.63 |
| **Группа 9** | 64-70 | 239.255.0.64 - 239.255.0.70 |

Пусть в нашем случае устройства-приемники объединены в группу **"Группа 0"**, имеет номера вселенных **1-7** и 
соответственно адреса многоадресной рассылки UDP пакетов - **239.255.0.1 -239.255.0.7**  

Output devices  
 
Нажмите кнопку **Add** (***"Добавить"***) для добавления нового устройства (новой вселенной)

Add/Edit device  

- В комбо-боксе ***"Device Type"*** выберите значение **"sACN / E1.31"**  
- В поле ***"Universe"*** укажите номер вселенной - **1**. Обратите внимание, что при переходе к следующему полю значение **IP Address** изменится на ***239.255.0.1***
- В поле ***"Channels"*** укажите количество каналов для вселенной 1 - **510** (это первые **170** светодиодов матрицы)
- Нажмите кнопку ***"ОК"*** для добавления созданной вселенной в список устройств

Снова нажмите кнопку **Add** (***"Добавить"***) для добавления описателя второй вселенной

Add/Edit device  

- В комбо-боксе ***"Device Type"*** выберите значение **"sACN / E1.31"**  
- В поле ***"Universe"*** укажите номер вселенной - **2**. Обратите внимание, что при переходе к следующему полю значение **IP Address** изменится на ***239.255.0.2***
- В поле ***"Channels"*** укажите количество каналов для вселенной 2 - **258** (это оставшиеся **86** светодиодов матрицы)
- Нажмите кнопку ***"ОК"*** для добавления созданной вселенной в список устройств

Для примера с матрицей 16x16 созданы все необходимые вселенные.

Device list  

Если ваша матрица другого размера - выполните расчет и создание вселенных для вашего случая.  

## Шаг 5

На следующем шаге требуется указать программе в какой последовательности располагаются светодиоды на вашей матрице, 
иными словами - в каком порядке программа должна передавать изображение на устройства-приемники. 

Выберите в меню пункт настройки варианта подключения светодиодов матрицы  

Output patch  

В открывшемся окне представлена схема матрицы, на которую должны выводиться эффекты.  
Красными представлены пиксели для которых еще не назначено соответствие светодиодам матрицы  

Output patch  

Здесь возможны два варианта в зависимости от выбранного типа синхронизации - **"Логический"** и **"Физический"**

### Логический тип синхронизации

В ***логическом*** типе синхронизации светодиоды располагаются начиная с левого верхнего угла **X,Y=(1,1)** и далее вправо по колонкам (**X**), затем вниз по строкам (**Y**). Каждая строка (и четная и нечетная) начинаются слева, увеличение координаты - вправо. Заполнение вселенных ведется последовательно - сначала созданная **Вселенная 1**, затем **Вселенная 2** и так далее.

#### Разметка Вселенной 1

Установите маркер начала распределения светодиодов - ярко красный квадрат в левый верхний угол матрицы и нажмите кнопку **"Fast Patch"**  

Output patch - Select Device  

Для размещения первых 170 светодиодов при ширине матрицы 16 колонок достаточно 11 строк. Последняя строка будет не полной - останется место для 6 светодиодов. В поле **"Dimension"** укажите размер заполняемой области - **X:16, Y:11**

В комбобоксе "Patch Mode" выберите направление светодиодов из угла подключения матрицы. 
Как указано выше - в случае логического порядка светодиоды следуют построчно с началом - в левом верхнем углу матрицы.  
Выберите значение **"Linewise starting Top-Left"**

> Доступны следующие варианты:  
Fast Patch  
```
- Linewise starting Top-Left         - Левый верхний угол, параллельно по строкам слева направо
- Linewise starting Top-Right        - Правый верхний угол, параллельно по строкам справа налево
- Linewise starting Bottom-Left      - Левый нижний угол, параллельно по строкам слева направо
- Linewise starting Bottom-Right     - Правый верхний угол, параллельно по строкам справа налево
- Snakelines starting Top-Left       - Левый верхний угол, зигзаг направление вправо
- Snakelines starting Top-Right      - Правый верхний угол, зигзаг направление влево
- Snakelines starting Bottom-Left    - Левый нижний угол, зигзаг направление вправо
- Snakelines starting Bottom-Right   - Правый нижний угол, зигзаг направление влево
- Columnwise starting Top-Left       - Левый верхний угол, параллельно по колонкам сверху вниз
- Columnwise starting Top-Right      - Правый верхний угол, параллельно по колонкам сверху вниз
- Columnwise starting Bottom-Left    - Левый нижний угол, параллельно по колонкам снизу вверх
- Columnwise starting Bottom-Right   - Правый нижний угол, параллельно по колонкам снизу вверх
- Snakecolumns starting Top-Left     - Левый верхний угол, зигзаг, направление вниз
- Snakecolumns starting Top-Right    - Правый верхний угол, зигзаг, направление вниз
- Snakecolumns starting Bottom-Left  - Левый нижний угол, зигзаг, направление вверх
- Snakecolumns starting Bottom-Right - Правый нижний угол, зигзаг, направление вверх
```
Значение в комбобоксе **"Pixel Order"** - всегда **"RGB"** - порядок следования цветов в пикселе обрабатывается программно в скетче прошивки при задании типа ленты в блоке инициализации библиотеки ***FastLED***.

Поле **"First Channel"** содержит номер канала, начиная с которого будут размещены данные цветов в формируемом пакете.
Поскольку размещение данных для вселенной только начинается - данные следуют с канала **0**.

В комбобоксе **"Patch device"** выберите устройство, соответствующее первой вселенной - **sACN/E1.31 239.255.0.1**

Нажмите кнопку **"ОК"** для запуска разметки данных для *Вселенной 1*.

Теперь первые 170 клеток матрицы имеют зеленый цвет, что означает, что каждой зеленой ячейке виртуальной / программной матрицы назначено место в массиве данных передаваемых на устройство-приемник. 

Output patch  

Обратите внимание, что последняя строка заполнена не полностью - для нее не хватило места в пакете E1.31, первой вселенной, который вмещает в себя 510 доступных каналов из 512 (или данные для 170 светодиодов). В области, выделенной зеленым справа видно, что выбранная вселенная - **sACN/E1.31 239.255.0.1[1]** и каналы для цвета RGB назначены R-507, G-508, B-509.

#### Разметка Вселенной 2

Инструмент **"Fast Patch"** использует для разметки прямоугольные области, внутри которых задает последовательность диодов согласно выбранным настройкам. После завершения распределения диодов для первой вселенной выполним разметку для второй вселенной.

В строке 11 осталось неразмеченной 6 клеток. Установите маркер начала разметки - красный прямоугольник на первую клетку неразмеченной области и снова нажмите кнопку **"Fast Parch"**.

Start output  

Прямоугольная область разметки остатка строки - 6 клеток в одной строке - укажите размер заполняемой области в поле  **"Dimension"** - **X:6, Y:1**.
В комбобоксе **"Patch Mode"** направление светодиодов из угла подключения матрицы остается неизменным - **"Linewise starting Top-Left"**.
Нумерация каналов для второй вселенной начинается с **0** - укажите это значение в поле **"First Channel"**. В поле **"Patch Device"** выберите вторую вселенную - **sACN/E1.311 239.255.0.2[2]**. Нажмите кнопку **"ОК"**.

Start output  

Разметка остатка строки выполнена. Последняя размеченная клетка определяет каналы R-15, G-16, B-17

Переместите маркер начала размечаемой области в начало строки 12. Нажмите кнопку **"Fast Patch"**.

Start output  

Размеры размечаемой области - 16 колонок, 5 строк **(X=16, Y=5)**. 
Направление следование цепочки остается неизменным - **Linewise starting Top-Left**.
Последний занятый канал Вселенной 2, заданный на предыдущем шаге - **17** (компонента цвета B). 
Значит, нумерация каналов для следующего диода должна начинаться с **18**. Это значение вводится в поле **"First Channel"**.
Убедитесь, что в комбобоксе **"Patch Device"** по-прежнему выбрана вторая вселенная **sACN/E1.311 239.255.0.2[2]** и нажмите кнопку **"ОК"**.

Start output  

Разметка матрицы для передачи изображения эффектов устройствам-приемникам по протоколу E1.31 для выбранного режима синхронизации ***"Логический"*** на этом завершена.

### Физический тип синхронизации

Физический тип синхронизации подразумевает, что определение матрицы для вывода эффектов в программе ***"Jinx!"*** должно полностью соответствовать последовательности размещения светодиодов на физической матрице.

Для примера рассмотрим матрицу размером ***16x16***, топ соединения диодов - ***зигзаг***, угол подключения - ***левый нижний***, направление следования цепочки диодов из угла - ***вправо***. Заполнение вселенных ведется последовательно - сначала созданная **Вселенная 1**, затем **Вселенная 2** и так далее.

#### Разметка Вселенной 1

Первая вселенная содержит в себе цвета первых **170** светодиодов или **170 * 3 = 510** каналов. Эти светодиоды занимают на матрице нижние 11 строк, причем последняя распределяемая строка будет содержать только 10 светодиодов, остальные 6 клеток останутся незаполненными.

Установите маркер начала распределения светодиодов - ярко красный квадрат в первую ячейку (крайнюю левую) строки под номером 6. Таким образом, определяется размечаемая область (**X,Y**) - левый верхний угол (**1,6**), правый нижний угол (**16,16**). Нажмите кнопку **"Fast Patch"**.  

Output patch - Select Device  

Задайте параметры распределения ячеек матрицы:   
Для размещения первых 170 светодиодов при ширине матрицы 16 колонок достаточно 11 строк. Последняя строка будет не полной - останется место для 6 светодиодов. В поле **"Dimension"** укажите размер заполняемой области - **X:16, Y:11**

В комбобоксе "Patch Mode" выберите направление светодиодов из угла подключения матрицы. В нашем случае светодиоды расположены ***"змейкой"***, начиная с ***левого нижнего угла*** выделенной области, направление следования из угла - ***вправо***. Выберите в комбобоксе **""Patch Mode"** значение **"Snakelines starting Bottom-Left"**

Значение в комбобоксе **"Pixel Order"** - всегда **"RGB"** - порядок следования цветов в пикселе обрабатывается программно в скетче прошивки призадании типа ленты в блоке инициализации библиотеки ***FastLED***.

Поле **"First Channel"** содержит номер канала, начиная с которого будут размещены данные цветов в формируемом пакете.
Поскольку размещение данных для вселенной только начинается - данные следуют с канала **0**.

В комбобоксе **"Patch device"** выберите устройство, соответствующее первой вселенной - **sACN/E1.31 239.255.0.1**

Нажмите кнопку **"ОК"** для запуска разметки данных для *Вселенной 1*.

Output patch - Select Device  

Теперь первые 170 клеток матрицы имеют зеленый цвет, что означает, что каждой зеленой ячейке виртуальной / программной матрицы назначено место в массиве данных передаваемых на устройство-приемник. 

Однако, разметка выглядит несколько не так, как ожидалось... К сожалению, утилита **"Fast Patch"** имеет ошибку и распределяет ячейки не совсем в соответствии с заданным алгоритмом. Придется исправлять ошибки вручную...

Обратите внимание, что ячейка **(1,16)** определяющая начальную точку (первый светодиод матрицы) подсвеченная ярко-зеленым маркером в правой части окна в информационной панели содержит номера каналов **R,G,B** - **0,1,2**. Следующая зеленая ячейка **(2,16)** - каналы **3,4,5** и так далее. И это правильно. Однако первая красная ячейка (и следующие за ней красные ячейки в строке) содержат правильное распределение каналов **(30,31,32)**, **(33,34,35)**..., но комбобокс **"Patch Device"*** содержит значение **None**. Это ошибка. 

Output patch - Select Device  

Для исправления ошибки вручную выберите в комбобоксе **"Patch Device"** *Вселенную 1* - **sACN/E1.31 239.255.0.1** для каждой красной ячейки строки.

Напротив, в строке 6 последние 6 ячеек имеют зеленый цвет, но каналы для них не назначены - **R,G,B** содержат значения **0,0,0** выберите для 6 последних ячеек строки 6 в комбобоксе **"Patch Device"** *Вселенную 2* - **sACN/E1.31 239.255.0.2** и номера каналов последовательно **(0,1,2)**,**(3,4,5)**,**(6,7,8)**,**(9,10,11)**,**(12,13,14)**,**(15,16,17)**.

Output patch - Select Device  

Итак, разметка *Вселенной 1* и первых шести диодов *Вселенной 2* - выполнена

#### Разметка Вселенной 2

Следующая размечаемая область - от **X,Y** ячейки **(1,1)** (левый верхний угол области) до **(16,5)** (правый нижний угол области.
Поскольку тип соединения нашей матрицы - **"зигзаг"** (или ***"змейка"***) с началом в левом нижнем углу, строки **16,14,12,10,8,6** имеют нумерацию ячеек и распределение каналов по возрастанию ***слева направо***, а строки **13,11,9,7** - нумерацию ячеек и распределение каналов по возрастанию - ***справа налево***.

Строка **5** в оставшейся у распределению красной области также имеет распределение номеров ячеек **СПРАВА НАЛЕВО** (***!!!***).

Нажмите кнопку **"Fast Patch"** для выполнения распределения оставшейся части ячеек матрицы.

Output patch - Select Device  

Размер области распределения **Dimension** **X=16**, **Y=5**, направление следования цепочки светодиодов в выделенной области - из **правого нижнего** угла **влево**, по строкам **змейкой** вверх. В поле **"Patch Mode"** выбираем значение **"Snakelines starting Bottom-Right"***. Номер последнего распределенного канала во *Вселенной 2* в ячейке с координатами **(16,6)** - ***B-17***, значит первым распределяемым каналом в оставшейся области будет канал **18**, что и указываем в поле **"First Channel"**. Нажмите кнопку **"ОК"** для завершения операции распределения.

Output patch - Select Device  

Назначение светодиодов для передачи картинки эффекта на устройства-приемники завершено!

### Сборная матрица

Ниже приведен рисунок назначения светодиодов матрицы "Jinx!" на [сборную матрицу](https://github.com/vvip-68/GyverPanelWiFi/wiki/Сборная-матрица), состоящую из четырех матриц размером 8x8 пикселей.

Output patch - Select Device  

Расположение матриц в сборке представлено на рисунке. Первый светодиод каждой матрицы (угол подключения) обозначен зеленой точкой. 
Направление следования цепочки светодиодов из угла подключения - красной линией.

Ниже представлена пошаговая схема распределения диодов матрицы по вселенным.

Output patch - Select Device  

## Шаг 6

Итак, эффекты созданы или выбраны из готовых примеров. Один из эффектов отображается в реальном режиме времени в центральной панели, являющейся результатом смешивания эффектов из правой и левой панелей предварительного просмотра. 

Start output  

Для начала трансляции эффекта на устройства-приемники выберите в меню **"Setup"** пункт **"Start Output"**. 
Для остановки трансляции повторно выберите этот же пункт меню.  

Start output

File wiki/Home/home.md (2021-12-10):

[Варианты устройств. Схемы.](https://github.com/vvip-68/GyverPanelWiFi/wiki/Варианты-устройств.-Схемы.)  
[Сборная матрица](https://github.com/vvip-68/GyverPanelWiFi/wiki/Сборная-матрица)   
[Всё собрал, ничего не работает.](https://github.com/vvip-68/GyverPanelWiFi/wiki/Всё-собрал,-ничего-не-работает.)  
[Три шага к успеху. Некоторые особенности настроек...](https://github.com/vvip-68/GyverPanelWiFi/wiki/Три-шага-к-успеху.-Некоторые-особенности-настроек...)  

[Пошаговая инструкция подготовки среды для проекта](https://github.com/vvip-68/GyverPanelWiFi/wiki/Пошаговая-инструкция-подготовки-среды-для-проекта)  
[Настройка скетча для вашего устройства](https://github.com/vvip-68/GyverPanelWiFi/wiki/Настройка-скетча-для-вашего-устройства)  
[Настройка параметров в приложении](https://github.com/vvip-68/GyverPanelWiFi/wiki/Настройка-параметров-в-приложении)  
[Настройка получения информации о погоде](https://github.com/vvip-68/GyverPanelWiFi/wiki/Настройка-получения-информации-о-погоде)  
[Настройка бегущей строки](https://github.com/vvip-68/GyverPanelWiFi/wiki/Настройка-бегущей-строки)  
[Настройка подключения к MQTT-серверу](https://github.com/vvip-68/GyverPanelWiFi/wiki/Настройка-подключения-к-MQTT-серверу)  

[JinxFramer - редактор анимации, роликов, картинок пользователя](https://github.com/vvip-68/GyverPanelWiFi/wiki/JinxFramer---редактор-анимации,-роликов,-картинок)  
[Загрузка изображений в файловую систему МК](https://github.com/vvip-68/GyverPanelWiFi/wiki/Загрузка-изображений-в-файловую-систему-МК)  
[Экспорт эффектов анимации из ПО «Jinx!»](https://github.com/vvip-68/GyverPanelWiFi/wiki/Экспорт-эффектов-анимации-из-ПО-«Jinx!»)  
[Захват видео программой «Jinx!»](https://github.com/vvip-68/GyverPanelWiFi/wiki/Захват-видео-программой-«Jinx!»)  
[Как добавить свою анимацию](https://github.com/vvip-68/GyverPanelWiFi/wiki/Добавление-своей-анимации--к-эффекту-«Анимация»)  

[API управления устройством](https://github.com/vvip-68/GyverPanelWiFi/wiki/API-управления-устройством)  
[API управления устройством по каналу MQTT](https://github.com/vvip-68/GyverPanelWiFi/wiki/API-управления-устройством-по-каналу-MQTT)   
[Интеграция в Умный дом](https://github.com/vvip-68/GyverPanelWiFi/wiki/Интеграция-в-Умный-дом)  
[Большие буквы в бегущей строке](https://github.com/vvip-68/GyverPanelWiFi/wiki/Большие-буквы-в-бегущей-строке)  

#### [Синхронизация устройств](https://github.com/vvip-68/GyverPanelWiFi/wiki/Синхронизация-устройств)  
- [Общие понятия](https://github.com/vvip-68/GyverPanelWiFi/wiki/Синхронизация-устройств#Общие-понятия)  
- [Внешние эффекты Jinx!](https://github.com/vvip-68/GyverPanelWiFi/wiki/Настройка-ПО-управления-эффектами-%22Jinx!%22-как-источника-синхронизации-устройств-в-группе)  
- [Настройка синхронизации](https://github.com/vvip-68/GyverPanelWiFi/wiki/Синхронизация-устройств#Настройка-синхронизации)  
- [Технические аспекты](https://github.com/vvip-68/GyverPanelWiFi/wiki/Синхронизация-устройств#Технические-аспекты)  

[Продвинутый уровень. Использование портов МК](https://github.com/vvip-68/GyverPanelWiFi/wiki/Продвинутый-уровень.-Использование-портов-микроконтроллера.) 

[FAQ](https://github.com/vvip-68/GyverPanelWiFi/wiki/FAQ)

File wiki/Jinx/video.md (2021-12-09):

# Захват видео программой «Jinx!»

### По материалам пользователей **247760** и **7918514** в [issue #166](https://github.com/vvip-68/GyverPanelWiFi/issues/166#issuecomment-986279874) 

**247760**:

В двух словах, начало такое, а дальше как и с другими вариантами в JINX:  
Предварительная базовая настройка под Вашу гирлянду. И погнали.
1. Выбрать режим **Capture Screen**
2. Сразу ниже: **Edit** 
3. Появится окошко в котором нужно нажать : **Select screen region**
4. Появится новое окошко: **Capture Screen** с кнопкой **Close**
5. Это окошко тянется за углы, это и есть площадь видеозахвата, т.е. как только вы растянете его на размер окна ролика с Ютуба или видеоплеера, жмёте **Close**, окошко пропадёт. 



6. Вы увидите в программе (окно с размерами Вашей гирлянды) то что она захватывает.  
Саму JINX утяните вниз экрана, чтобы она не попадала в видеозахват.



Вот ещё видео, с отображением видеозахвата на панели в режиме реального времени

Watch the video (https://youtu.be/wy_lokJMGOI)

**7918514**:

Я Джинксом граблю видео с ютюба. Нахожу какую-нибудь анимацию компьютерную и в Джинксе включаю захват экрана.  
Некоторые получаются  даже ничего...  

https://youtu.be/aqfzA8PqgVA  
https://youtu.be/zngPoLK_IGE  
https://youtu.be/iatlzfjluHQ  
https://youtu.be/pwcmANSvtu4  
https://youtu.be/dX6sz2QCxWc  
https://youtu.be/bx-0YlFprqc  
https://youtu.be/lbgPHWONVQg  
https://youtu.be/msnYBMdaB08  
https://youtu.be/Opymy0DXPcI  
https://youtu.be/MW2OVIdGT0o  
https://youtu.be/RoCct_L2RJI  

ну и так далее, справа в подборке ещё много вылазит.

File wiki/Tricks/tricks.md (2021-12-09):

# Три шага к успеху. Некоторые особенности настроек...

Если на вашей матрице наблюдаются случайные цветные всполохи, срывы синхронизации, когда часы или бегущая строка "рассыпается",
выполните следующие шаги, которые, вероятно, смогут устранить проблему

## Шаг1

   Описанные эффекты возникают при превышении выходного напряжения блока пиания выше 4.8-5.2 вольта. 
   Обычно китайские блоки питания имеют заводскую настройку выходного напряжение 5.4-5.6 вольт. 
   Для проверки - не подключайте +5 вольт от блока питания к микроконтроллеру совсем, питание подавайте на матрицу непосредственно. 
   "Землю" микроконтроллера и ленты соедините. Подключите сигнальный пин микроконтроллера ко входу DIN ленты. 
   Подключите микроконтроллер к компьютеру через USB (питание будет поступать отсюда). 
   Если после проделанных манипуляции проблема исчезла, регулируем напряжение на блоке питания:

   1. Для блоков питания в жестяном корпусе - возле гребенки выходных контактов есть "крутилка" - переменный резистор.  
      Подключаем к выходным разъемам вольтметр и маленькой отверткой крутим резистор влево, установив выходное напряжение в 4.8 вольта  
   2. Если ваш блок питания не имеет переменного резистора - возможно на его место впаян постоянный резистор - найдите его и земените переменным резистором.
      Далее выполните настройку из п.1
   3. Если вы не можете найти резистор или его регулировка не позволяет установить 4.8 вольта - переходим к **Шаг 2**

## Шаг 2
  
   Если ваш блок питания в пластиковой коробке и у вас нет возможности/желания разбирать его и выполнять рекомендации из **Шаг 1**
   или если вы используете схему с MOSFET для отключения питающего напряжения матрицы, попробуйте применить схему с
   включением кремниевого диода между минусом БП и пином GND микроконтроллера. Это позволит "приподнять" "землю" микроконтроллера
   на 0.6-0.8 вольт относительно уровня "земли" матрицы, что автоматически поднимает уровень логического сигнала на управляющем пине микроконтроллера / ленты.
   Лучшее согласование логических уровней может устранить всполохи на матрице.  
   Такое включение позволяет панели стабильно работать при напряжении с блока питания практически от 4.2 до 6.5 вольт без необходимости 
   регулировки выходного напряжения блока питания.  
   Если проделанные манипуляции не устранили проблему - пробуем рекомендации из **Шаг 3**

## Шаг 3

   Возможно устранить проблему всполохов и "рассыпания" текста поможет программная корректировка управляющего сигнала, подающегося на ленту / матрицу.  
   В библиотеке FastLED найдите файл **clockless_esp8266.h**. Он может быть расположен в одной из следующих папок:  

```
C:\Program Files (x86)\Arduino\libraries\FastLED\platforms\esp\8266\clockless_esp8266.h
C:\Users\<user>\Documents\Arduino\libraries\FastLED\platforms\esp\8266\clockless_esp8266.h
```

   и в строке 19 файла **clockless_esp8266.h** заменить 

```
template <int DATA_PIN, int T1, int T2, int T3, EOrder RGB_ORDER = RGB, int XTRA0 = 0, bool FLIP = false, int WAIT_TIME = 50>
```

   на

```
template <int DATA_PIN, int T1, int T2, int T3, EOrder RGB_ORDER = RGB, int XTRA0 = 0, bool FLIP = false, int WAIT_TIME = 10>
                                                                                                              ------------^
```

  Во всех файлах скетча ищем:
  Строку `#include <FastLED.h>` (это в одном файле только) и перед ней, выше пишем: 
```
  #define FASTLED_ALLOW_INTERRUPTS 0 
```
  Далее ищем строку **"FastLED.show()"** и после каждого вхождения с новой строки пишем: `yield();`

  После выполнения этих исправлений пересоберите проект и загрузите прошивку. С большой долей вероятности это решит проблему "мерцающих" пикселей на матрице.

   Однако этот метод с большой долей вероятности может привести к "отваливанию" WiFi соединения микроконтроллера с сетью и периодическим перезагрузкам, 
   обычно с сообщением о причине "Soft WDT" или "wdt reset". Обычно перезагрузка происходит через некоторое время после пропадания соединения с сетью.  

   Пробуйте подобрать значение ```WAIT_TIME``` от 5 до 50, соблюдая баланс между стабильностью работы микроконтроллера и стабильностью отображения эффектов.

   Вам решать - критично это для вас или нет. Что важнее - постоянное соединение с программой на телефоне и с сетью вообще или более стабильное отображение
   текста, часов и эффектов на матрице. Если у вас настроен выход в интернет через локальную сеть, с которой соединяется микроконтроллер - он после перезагрузки
   получит время, погоду и все что ему необходимо и продолжит работу. Внешне это выглядит как периодическое кратковременное пропадание эффектов с матрицы и 
   секунд через 10 всё восстанавливается.

   Как обычно - решать вам.

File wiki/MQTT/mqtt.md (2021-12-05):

Для управления устройством может использоваться канал связи с использованием технологии MQTT (Message Queue Telemetry Transport).
В интернете можно найти множество статей, объясняющих принципы функционирования этого протокола, дающие понятия о подписках, публикациях 
и другие основные сведения.

Список публичных MQTT-серверов можно найти в любой поисковой системе по запросу "публичный MQTT брокер".
Один из таких списков представлен [здесь](https://github.com/mqtt/mqtt.github.io/wiki/public_brokers).
Пример обзора публичных MQTT серверов можно изучить на [этой](https://kotyara12.ru/pubs/iot/cloud_services/) странице.
Выберите подходящий именно вам MQTT брокер, изучите документацию на него, настройте подключение.

## Требование к MQTT-серверу

Как правило, сервера отличаются наличием наряду с платными, бесплатных сервисов, которые, однако, могут иметь ограничения на количество одновременных подключений к брокеру,
количество разрешенных запросов в период времени, наличие / отсутствие авторизации при подключении, поддержку SSL и так далее. Выбор конкретного брокера 
зависит от ваших предпочтений и требований по защите канала (авторизация, наличие SSL и т.д). 
Вместе с тем следует принимать во внимание ряд параметров от которых зависит будет ли вообще устройство нормально работать с управлением по MQTT-каналу.

### Обработка пакета сообщений

В процессе коммуникации устройство отправляет вновь подключившемуся клиенту одновременно большое количество сообщений (около 80), содержащих
информацию о текущем состоянии устройства, актуальные значения его параметров. Далее при смене режимов отправляются одновременно от 3 до 8 сообщений об изменившихся параметрах.
По этой причине для нормальной работы критически важно выбрать брокер не имеющий ограничений на количество передаваемых сообщений в единицу времени - все отправленные сообщения
должны без задержек доходить до заинтересованных клиентов. Если бесплатный публичный MQTT-брокер имеет ограничение на отправку - "не более 1 сообщения в секунду" - он нам не подходит.

### Последняя воля

Выбранный MQTT-брокер должен поддерживать функцию LWT (Last Will and Testament). 
После физического отключения устройства от сети или потери устройством связи с MQTT-сервером, брокер автоматически рассылает
всем подключившимся клиентам сообщение, что устройство более недоступно. Получив это сообщение, клиент (программа на смартфоне)
понимает, что устройство более не доступно и деактивирует элементы управления с соответствующим сообщением о недоступности устройства.

Выполнение двух этих обязательных требований обеспечивает доступность управления устройством через MQTT-канал.
Если вам не удалось подобрать подходящий сервер из доступных бесплатных - подумайте о покупке платного тарифа MQTT-брокера
или установите и настройте свой собственный брокер для вашей локальной сети.

## MQTT-сервер по-умолчанию

#f03c15 **ВНИМАНИЕ!** В связи с изменением у брокера [mqtt.by](https://mqtt.by/) формата префикса, в приведенных ниже примерах везде вместо строки ***"af7cd12a"*** требуется использовать ***"user/<имя пользователя>/af7cd12a"***. Так же требуется задать имя пользователя и пароль. Подробности настройки подключения см. на странице брокера **"Профиль"**.

Для пробного упрощенного использования управления по каналу MQTT в проекте используется бесплатный 
общедоступный брокер - [mqtt.by](https://mqtt.by/). Зарегистрируйтесь на сервере [mqtt.by](https://mqtt.by/), в личном кабинете получите пароль
для подключения к брокеру.

Передача сообщений для конкретного устройства обеспечиваются уникальностью топика сообщения - задайте для вашего устройства гарантированный уникальный префикс. Например, используйте для префикса набор символов, формируемый из [GUID](https://ru.wikipedia.org/wiki/GUID) - Globally Unique Identifier, 
сгенерированного специальной [утилитой](https://www.rapidus.ru/guid-generator.html), буквенно-цифровой идентификатор из MAC-адреса микроконтроллера 
вашего устройства, его ID или придумайте набор символов сами. Длина сформированного префикса не должна превышать 30 символов.

Примеры префиксов: 
```
'3db46032'
'ESP-EA4774'
'gy-lamp-e5zs8d'
'MyPanel-4'
```

### Настройка MQTT-соединения в скетче

Откройте в Arduino IDE файл прошивки **"a_def_soft.h"**. Найдите строки 325-343.  
Строки указаны для версии скетча WiFiPanel-v.1.10.2021.0325. Если у вас другая версия - найдите строки, соответствующие строкам на картинке.  

Fast Patch  

Строка 326 - DEFAULT_MQTT_SERVER - укажите URL подключения к MQTT-серверу  
Строка 330 - DEFAULT_MQTT_USER   - укажите имя пользователя (логин)  
Строка 334 - DEFAULT_MQTT_PASS   - укажите пароль  
Строка 338 - DEFAULT_MQTT_PORT   - укажите порт MQTT сервера  
Строка 338 - DEFAULT_MQTT_PREFIX - укажите префикс топика сообщений  

```
#define DEFAULT_MQTT_SERVER "mqtt.by"            // MQTT сервер
#define DEFAULT_MQTT_USER   ""                   // Имя mqtt-пользователя    (укажите имя пользователя для вашего соединения)
#define DEFAULT_MQTT_PASS   ""                   // Пароль mqtt-пользователя (укажите пароль вашего соединения)
#define DEFAULT_MQTT_PORT   1883                 // Порт mqtt-соединения
#define DEFAULT_MQTT_PREFIX "af7cd12a"           // Префикс топика сообщения уникальный для вашего устройства
```

Обратите внимание на строку `#define A_DEF_PASS 1 ` определенную в выбранном вами профиле устройства в файле a_def_hard.ino

Fast Patch  

Если параметр `A_DEF_PASS` определен как **1** - это означает, что ваши настройки с чувствительными данными хранятся в отдельном 
файле с именем **"a_def_pass.h"**, который не включен в состав исходников.
Вам нужно будет создать этот файл и перенести в него настройки с вашими персональными учетными данными.

Fast Patch  

Если параметр `A_DEF_PASS` определен как **0** - это означает, что настройки вашего аккаунта для подключения к MQTT-серверу 
задаются непосредственно в строках 325-343 скетча в файле **"a_def_soft.h"**.  

Итак, параметры соединения определены, прошивку можно загружать в устройство.  
После того как прошивка загружена и стартовала, в мониторе порта будет виден лог подключения.  
Если все прошло успешно, вы увидите примерно следующее:  

Fast Patch  

На этом настройка устройства для управления по каналу MQTT завершена.  

Если у вас есть соответствующие знания - вы можете настроить управление устройством через голосовые помощники, например - **Яндекс Алиса** или **Google Assistant**.

На данный момент есть несколько реализаций интеграции устройства в систему управления умным домом с помощью Home Assistant.
Одна из реализаций описана [тут](https://github.com/tarasifua/vvip-68-matrix-home-assistant-integration).  

## Настройка параметров MQTT в приложении

#f03c15 **ВНИМАНИЕ!** В связи с изменением у брокера [mqtt.by](https://mqtt.by/) формата префикса, в приведенных ниже примерах везде вместо строки ***"af7cd12a"*** требуется использовать ***"user/<имя пользователя>/af7cd12a"***. Так же требуется задать имя пользователя и пароль. Подробности настройки подключения см. на странице брокера **"Профиль"**.

Настройки соединения с MQTT-сервером, сделанные в скетче по описанию выше, используются как значения по-умолчанию и сохраняются в энергонезависимой памяти при первой загрузке прошивки в микроконтроллер. При дальнейших запусках микроконтроллера настройки считываются из EEPROM и используются
при подключении к серверу. В любой момент настройки соединения можно изменить в программе на смартфоне.

Откройте приложение, подключитесь к устройству и перейдите на страницу "Настройки соединения"

Fast Patch  

Чекбокс **"Использовать MQTT"** позволяет временно включать и отключать канал управления MQTT.

Ниже расположены поля ввода значений настроек соединения:
1. Имя сервера
2. Имя пользователя
3. Пароль
4. Порт
5. Префикс
6. Интервал отправки сообщений 'uptime'

Некоторые параметры очевидны - имя сервера, имя пользователя, пароль и порт.  
Другие требуют некоторого объяснения:
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

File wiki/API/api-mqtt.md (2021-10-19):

## Канал управления MQTT

Управление устройством выполняется путем отправки ему команды через один из доступных каналов - UDP или MQTT.  
Не имеет значения по какому каналу устройство получило команду - обработка выполняется одинаково.  

Настройка канала управления MQTT описана в статье [Настройка подключения к MQTT серверу](https://github.com/vvip-68/GyverPanelWiFi/wiki/%D0%9D%D0%B0%D1%81%D1%82%D1%80%D0%BE%D0%B9%D0%BA%D0%B0-%D0%BF%D0%BE%D0%B4%D0%BA%D0%BB%D1%8E%D1%87%D0%B5%D0%BD%D0%B8%D1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)  

MQTT протокол обеспечивает двунаправленную передачу сообщений - как со стороны управляющей программы / браузерной панели управления в устройство,
так и из устройства в управляющую программу по инициативе устройства.  

Наличие двустороннего канала связи позволяет устройству инициативно уведомлять управляющего о событиях, произошедших в устройстве.  
К таким событиям относятся:
  - Включение и запуск устройства
  - Изменение значения параметра
  - Событие получение времени с сервера NTP
  - Событие получения информации о текущей погоде
  - Событие срабатывания одного из запрограммированных режимов по времени
  - Событие срабатывания или отключение будильника
  - Событие запуска воспроизведения файла эффекта с SD-карты
  - Событие начала / окончания показа текста бегущей строки
  - Событие выполнения синхронизации отображения данных между устройствами
  - Ошибки обработки запросов и команд, выполнения операций

### Топики сообщений

Используемые устройством топики и их назначение приведены в таблице
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

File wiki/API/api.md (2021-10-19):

## Общие понятия

Управление устройством выполняется путем отправки ему команды через один из доступных каналов - UDP или MQTT.  
Не имеет значения по какому каналу устройство получило команду - обработка выполняется одинаково.  
Команда представляет собой управляющую последовательность, начинающуюся с символа `'$'`, далее идет код операции и параметры.  
Завершается команда символом `';'`. Код команды и параметры разделены символом `' '`(пробел), состав параметров - зависит от конкретной команды.  

```
Команда: $<код> <параметры>; 
```
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

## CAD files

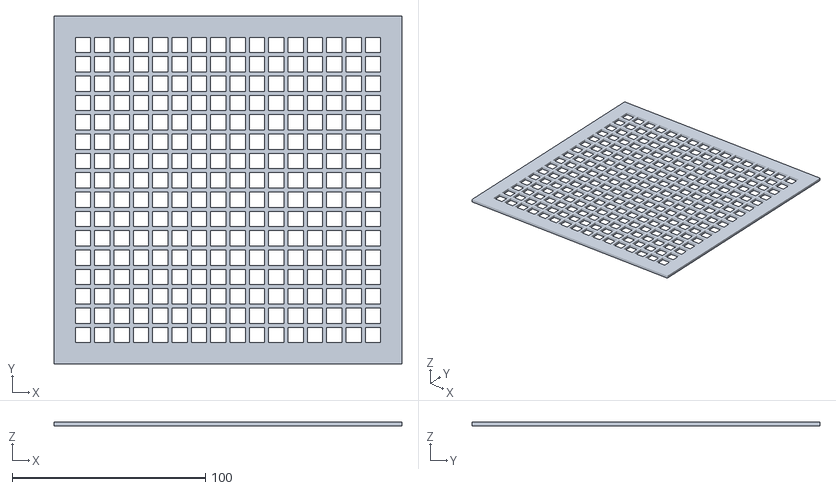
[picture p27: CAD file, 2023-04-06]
stl/16x16/matrix-full.stl
180.0 x 180.0 x 2.00

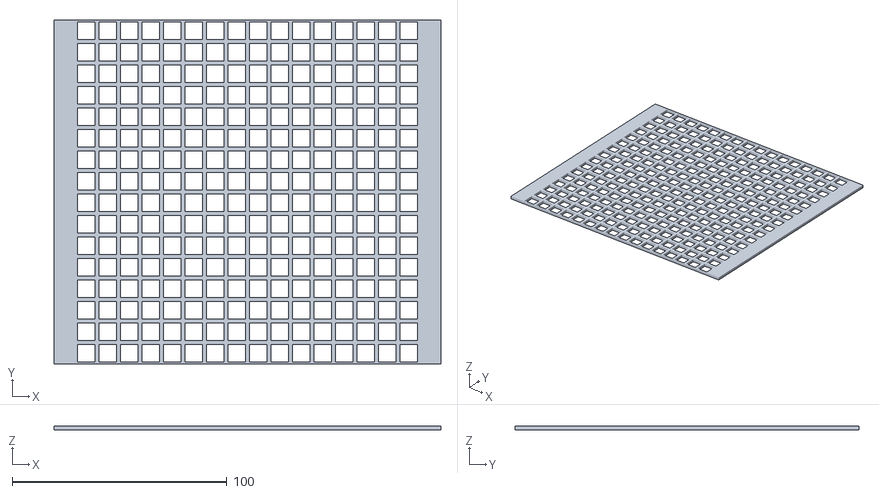
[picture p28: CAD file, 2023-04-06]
stl/16x16/matrix-2-sides.stl
180.0 x 160.0 x 2.00

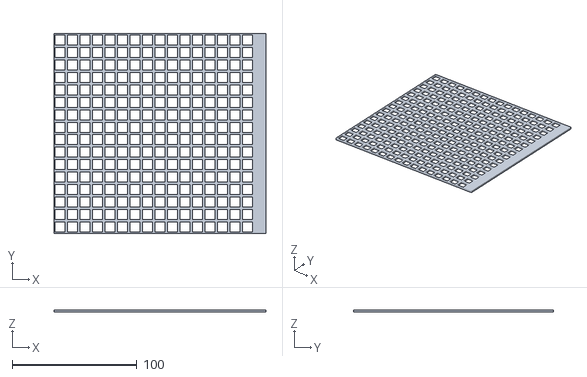
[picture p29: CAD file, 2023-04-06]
stl/16x16/matrix-1-side.stl
170.0 x 160.0 x 2.00

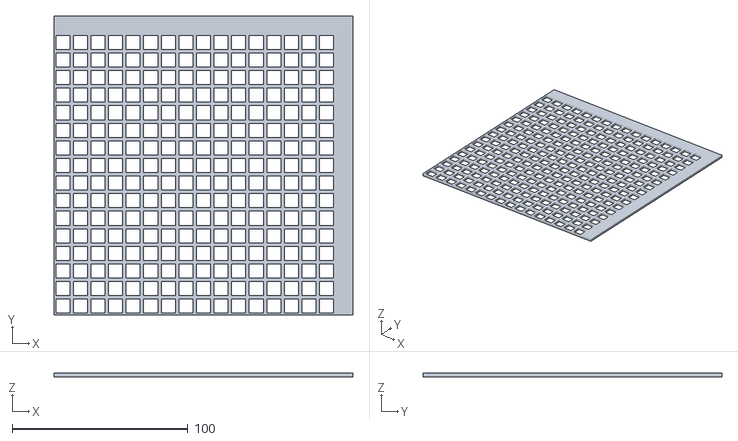
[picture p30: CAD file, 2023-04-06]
stl/16x16/matrix-angle.stl
170.0 x 170.0 x 2.00

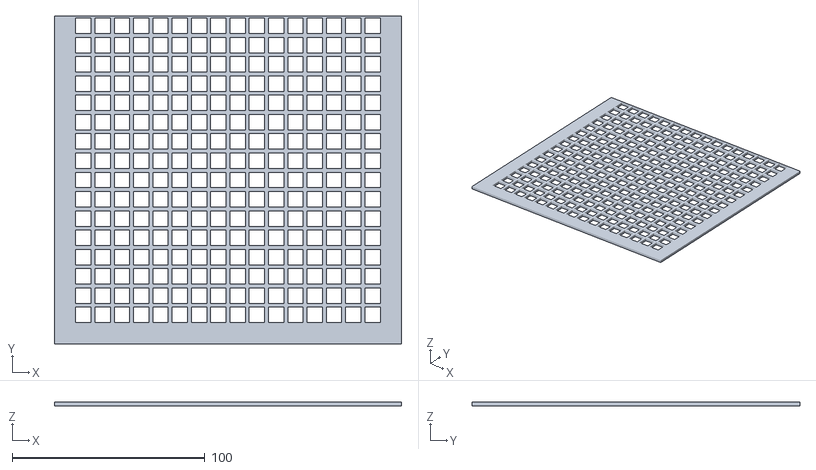
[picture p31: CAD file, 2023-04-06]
stl/16x16/matrix-3-sides.stl
180.0 x 170.0 x 2.00

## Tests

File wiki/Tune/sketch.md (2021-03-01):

# Настройка скетча для вашего устройства

## Выбор варианта устройства

Итак, вы выбрали схему, соединили все компоненты между собой.  
Следующий шаг - сообщить прошивке микроконтроллера как со всем этим работать.  

Откройте среду разработки Arduino IDE для редактирования скетча проекта. 
Перейдите на вкладку **a_def_hard.h** - все параметры, описывающие ваше устройство и поддерживаемый устройством функционал сосредоточен здесь.

Внимательно прочитайте комментарии в начале файла, там содержится важная информация!  

Если для своего устройства вы выбрали плату на базе микроконтроллера ESP8266 - NodeMCU или Wemos da mini - в пункте меню "Инструменты" установите параметры как это указано на картинке:

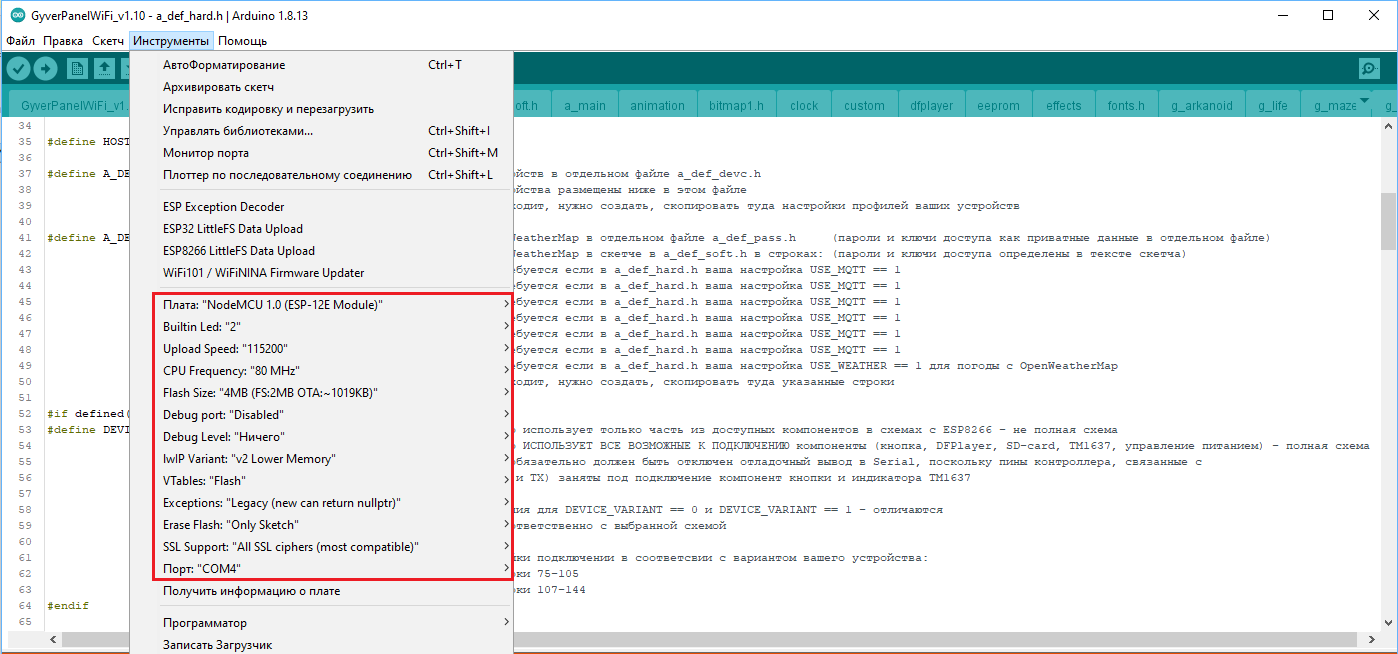
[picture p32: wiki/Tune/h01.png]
ESP8266


Если же ваше устройство собрано на базе микроконтроллера ESP32 - в пункте меню "Инструменты" установите параметры как это указано на картинке:

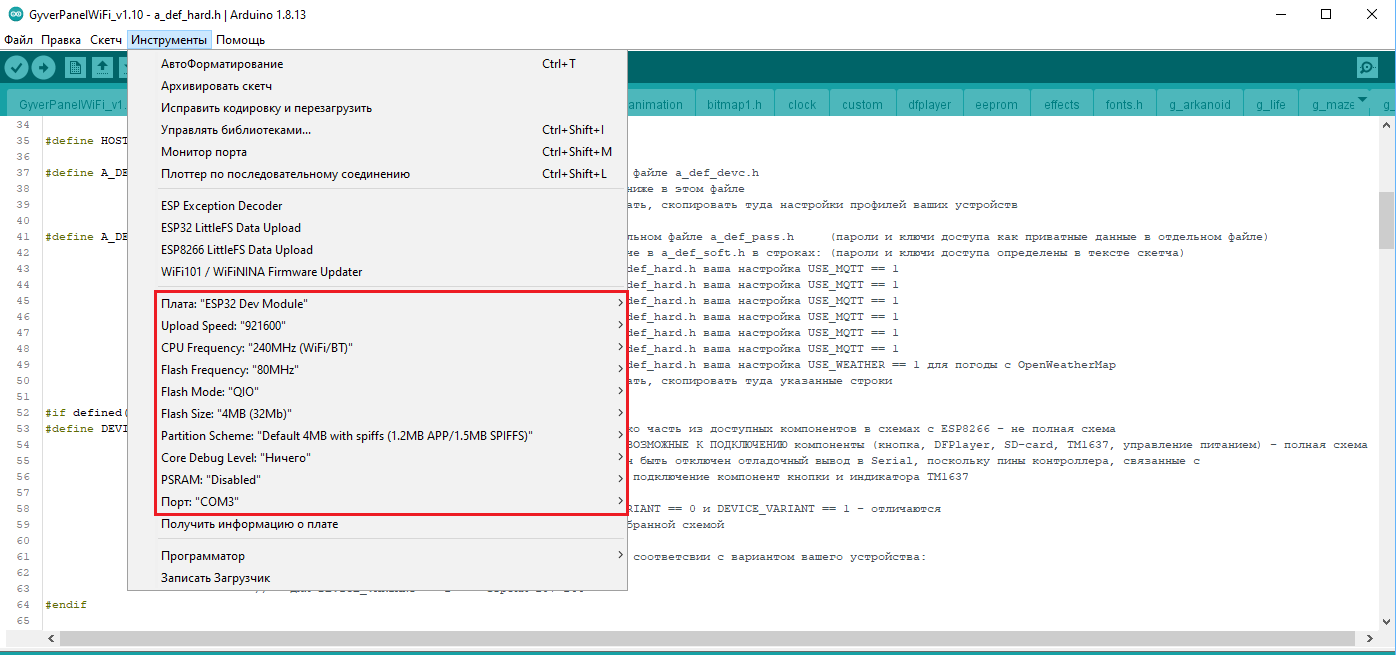
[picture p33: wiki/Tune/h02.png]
ESP32


В обоих случаях значение параметра "Порт" выбирайте в соответствии с тем, какой порт получил подключенный к USB микроконтроллер в вашем компьютере.  
Подробнее - [здесь](https://github.com/vvip-68/GyverPanelWiFi/wiki/%D0%9F%D0%BE%D1%88%D0%B0%D0%B3%D0%BE%D0%B2%D0%B0%D1%8F-%D0%B8%D0%BD%D1%81%D1%82%D1%80%D1%83%D0%BA%D1%86%D0%B8%D1%8F-%D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)

После того, как вы выбрали настройки компиляции для вашей платы - изучите и отредактируйте настройки скетча, чтобы они соответствовали собранному устройству

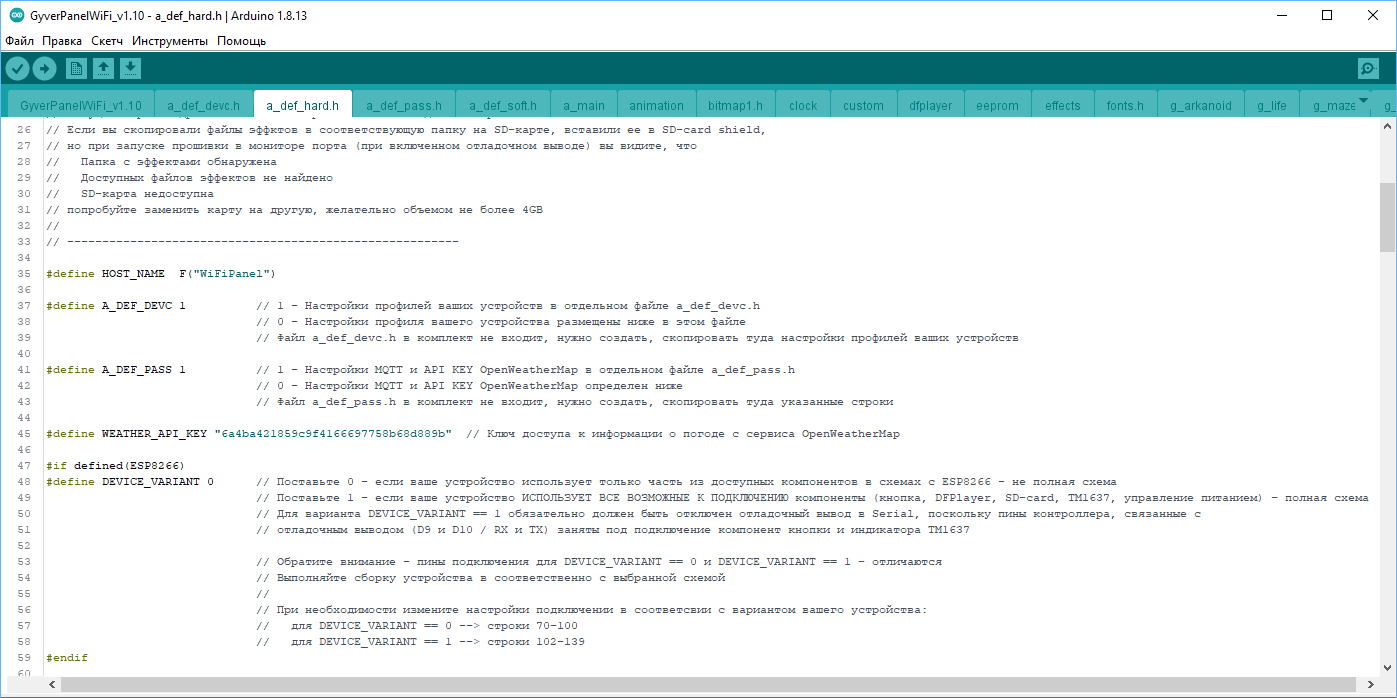
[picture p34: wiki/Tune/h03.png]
Profile


`HOST_NAME`   - строка задает то, под каким именем ваше устройство будет видно в вашей локальной сети.  
`A_DEF_DEVC`  - поставьте здесь *0*. Все параметры вашего устройства описываются в этом файле ниже.
`A_DEF_PASS`  - поставьте здесь *0*. Все параметры ваших подключений описываются в этом файле ниже.

Если вы планируете использовать сервис получения погоды с сервиса OpenWeatherMap - [получите](https://github.com/vvip-68/GyverPanelWiFi/wiki/%D0%9D%D0%B0%D1%81%D1%82%D1%80%D0%BE%D0%B9%D0%BA%D0%B0-%D0%BF%D0%BE%D0%BB%D1%83%D1%87%D0%B5%D0%BD%D0%B8%D1%8F-%D0%B8%D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) 
ключ API доступа к погодной информации на сервере. Если вы не собираетесь получать погоду - оставьте это поле не изменённым.

`WEATHER_API_KEY` - вставьте сюда ключ API получения погоды с OpenWeatherMap

Для устройств, собранных на ESP8266 существует два варианта подключения компонент к микроконтроллеру
1. Подключены [ВСЕ доступные компоненты](https://github.com/vvip-68/GyverPanelWiFi/raw/master/schemes/ESP8266_ALL.jpg): 
   DFPlayer, SD-Card, индикатор TM1637, реле или MOSFET управления питанием матрицы, кнопка (обычная или сенсорная)
2. Используется только часть из доступных к подключению компонент, устройство собрано по одной из 
   [схем](https://github.com/vvip-68/GyverPanelWiFi/wiki/%D0%92%D0%B0%D1%80%D0%B8%D0%B0%D0%BD%D1%82%D1%8B-%D1%83%D1%81%D1%82%D1%80%D0%BE%D0%B9%D1%81%D1%82%D0%B2.-%D0%A1%D1%85%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.):
   [схема 1](https://github.com/vvip-68/GyverPanelWiFi/raw/master/schemes/scheme.jpg),
   [схема 2](https://github.com/vvip-68/GyverPanelWiFi/raw/master/schemes/scheme_b.jpg),
   [схема 3](https://github.com/vvip-68/GyverPanelWiFi/raw/master/schemes/scheme_c.jpg),
   [схема 4](https://github.com/vvip-68/GyverPanelWiFi/raw/master/schemes/scheme_e.jpg),
   [схема 5](https://github.com/vvip-68/GyverPanelWiFi/raw/master/schemes/scheme_d.jpg) с возможным отсутствием одной из компонент.

Поскольку для варианта `DEVICE_VARIANT 1` используется все доступные выводы платы микроконтроллера, назначение пинов отличается от
назначения пинов варианта `DEVICE_VARIANT 0`. В зависимости от того, по какой схеме собрано ваше устройство  поставьте в определение
`DEVICE_VARIANT` значение **0** или **1**.

Если ваш вариант `DEVICE_VARIANT 0` - настраиваемые параметры определяются в строках 70-100 - переходите к редактированию этого блока  
Если ваш вариант `DEVICE_VARIANT 1` - настраиваемые параметры определяются в строках 102-139 - переходите к редактированию этого блока  

## Варианты устройств 

Для устройств, собранных на базе микроконтроллера ESP32 блок настроек параметров скетча расположен в строках 155-193 - переходите к редактированию этого блока  

### Вариант ESP8266 'DEVICE_VARIANT 0'

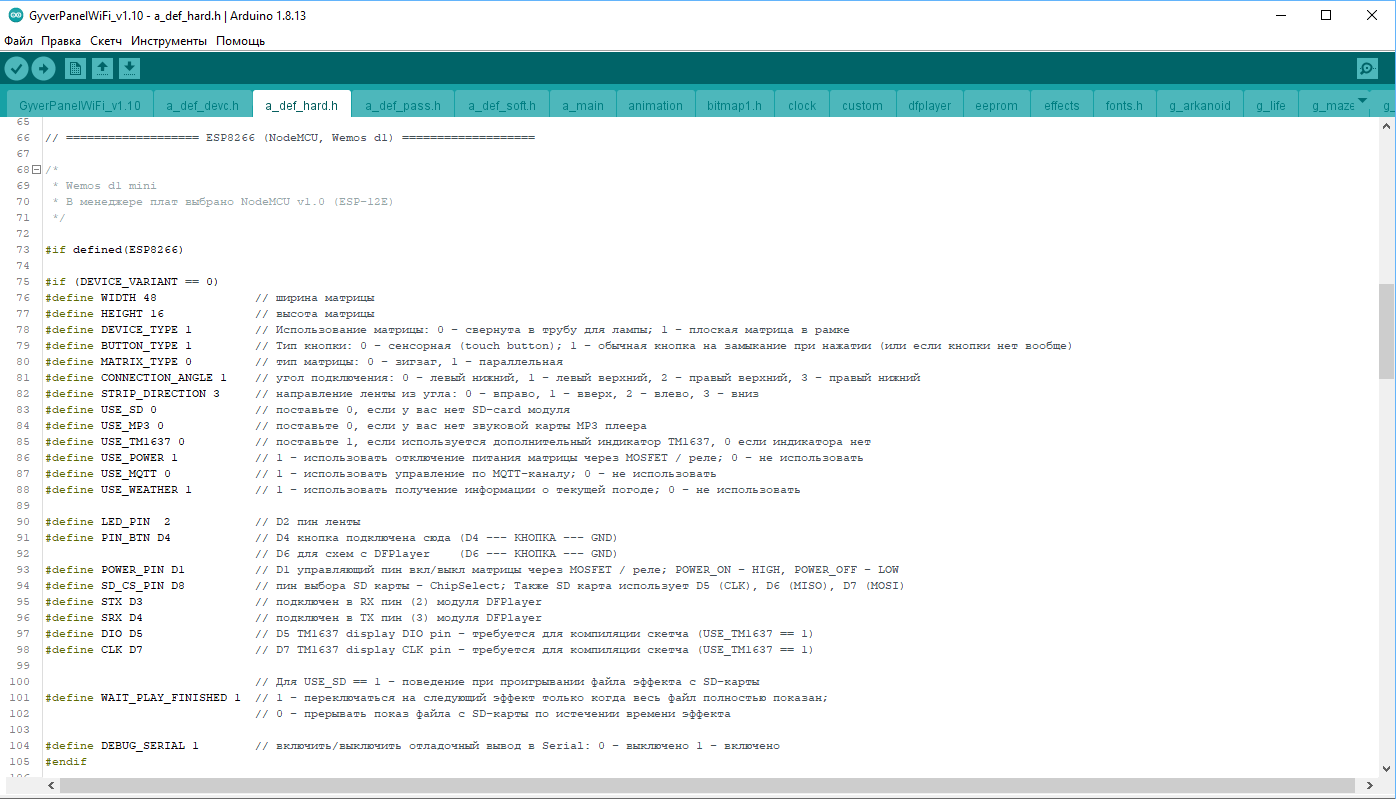
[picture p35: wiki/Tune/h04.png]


### Вариант ESP8266 'DEVICE_VARIANT 1'

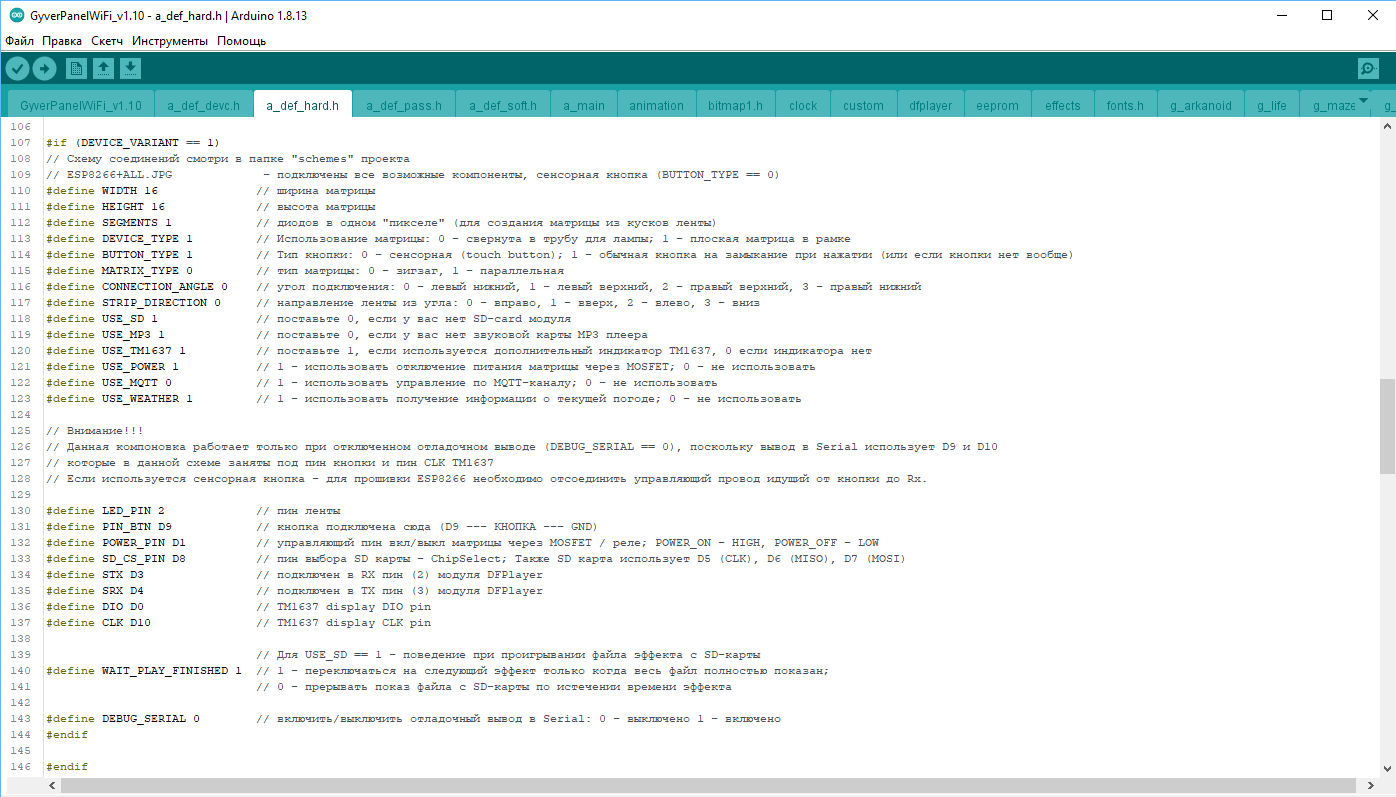
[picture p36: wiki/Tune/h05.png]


### Вариант ESP32

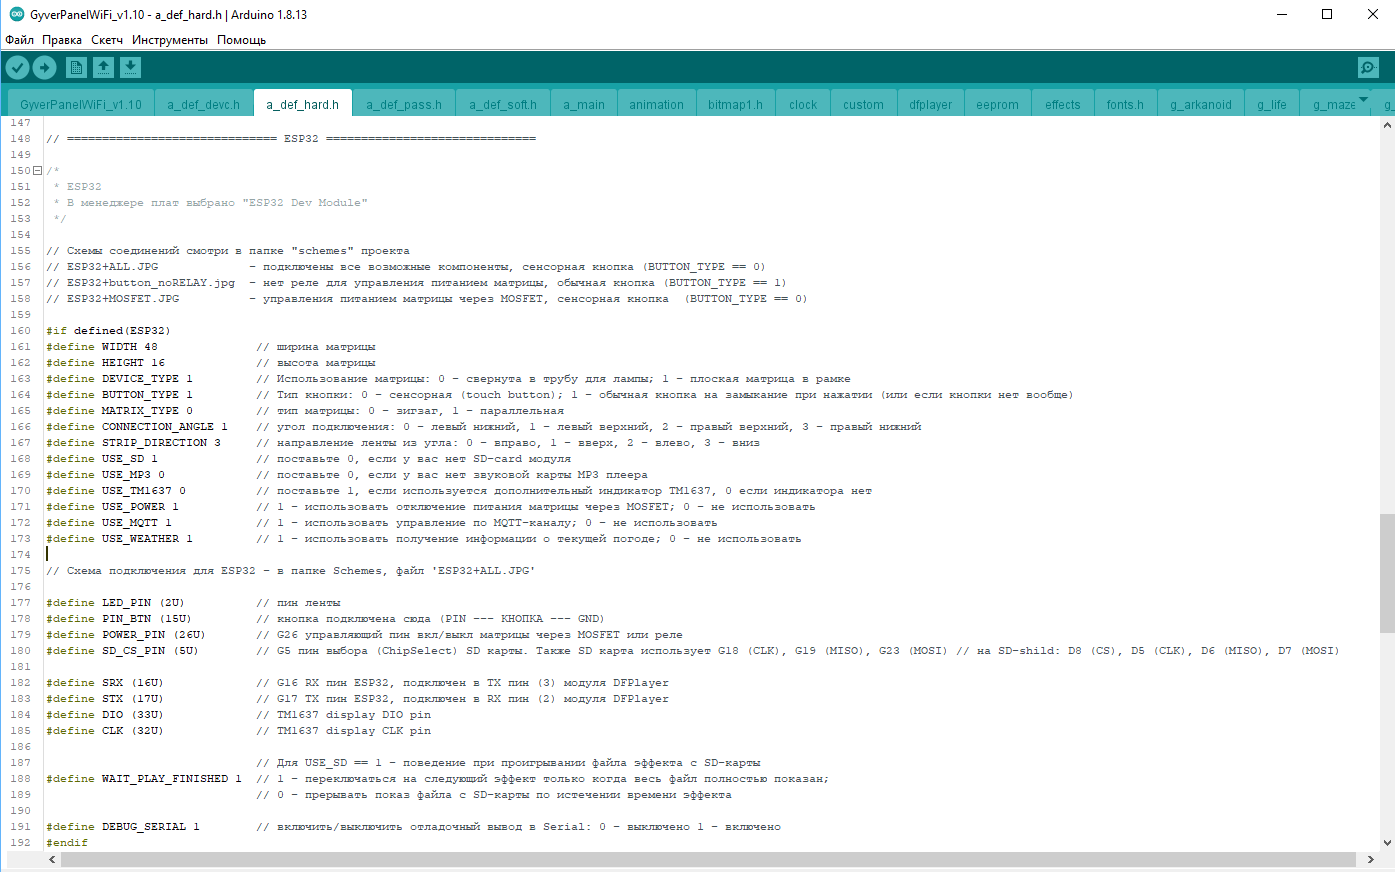
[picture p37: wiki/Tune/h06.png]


## Параметры профиля устройства

### Размеры и подключение матрицы

Профиль устройства содержит набор параметров, по значению одинаковый для всех трех вариантов. Рассмотрим назначение параметров подробнее.

#### WIDTH
Параметр **WIDTH** - укажите ширину вашей матрицы

#### HEIGHT
Параметр **HEIGHT** - укажите высоту вашей матрицы

#### DEVICE_TYPE
Параметр **DEVICE_TYPE** определяет как собрана ваша матрица:  
   **DEVICE_TYPE 0** - матрица свернута в трубу ("закольцована"), используется для устройств типа "лампа"  
   **DEVICE_TYPE 1** - плоская матрица, используется для устройств типа "гирлянда", "панель", "часы" и т.д.  

Значением этого параметра определяется поведение некоторых эффектов и часов. 
Например для *DEVICE_TYPE 0* - отображение движущихся часов "закольцовывается", что создает эффект движения часов по поверхности трубы без разрыва.
Для для *DEVICE_TYPE 1* - смещение часов уходит за край матрицы слева и не показывается с правого края, пока весь видимый текст не скроется из виду.

#### BUTTON_TYPE
Параметр **BUTTON_TYPE** определяет тип подключенной кнопки:  
  **BUTTON_TYPE 0** - сенсорная  
  **BUTTON_TYPE 1** - обычная физическая (тактовая) нормально-разомкнутая кнопка  

#### MATRIX_TYPE
Параметр **MATRIX_TYPE** определяет схему расположения "дорожек" светодиодов вашей матрицы  
  **MATRIX_TYPE 0** - зигзаг  
  **MATRIX_TYPE 1** - параллельная  

#### CONNECTION_ANGLE
Параметр **CONNECTION_ANGLE** определяет к какому углы матрицы подключен сигнальный провод, когда матрица расположена плоско прямо перед вами:  
  **CONNECTION_ANGLE 0** - левый нижний  
  **CONNECTION_ANGLE 1** - левый верхний  
  **CONNECTION_ANGLE 2** - правый верхний  
  **CONNECTION_ANGLE 3** - правый нижний  

#### STRIP_DIRECTION
Параметр **STRIP_DIRECTION** определяет в каком направлении идет "дорожка" светодиодов из угла подключения:  
  **STRIP_DIRECTION 0** - вправо  
  **STRIP_DIRECTION 1** - вверх  
  **STRIP_DIRECTION 2** - влево  
  **STRIP_DIRECTION 3** - вниз  

Схема, поясняющая тип матрицы, угол подключения и направление из угла:

MATRIX_TYPE

STRIP_DIRECTION

### Задействованные функции

В этом блоке определяются параметры, указывающие наличие подключенных к устройству компонент - **DFPlayer**, **SD-card**, **TM1637**, **Реле** или **MOSFET** для управления питанием матрицы.
В зависимости от того подключено ли устройство, в прошивке включаются или отключаются соответствующие блоки кода, обслуживающие работу с этими устройствами,
а также наличие или отсутствия соответствующих элементов управления в приложении на смартфоне.

#### USE_SD
Парааметр **USE_SD** определяет подключен ли к вашему устройству считыватель SD-карты  
  **USE_SD 0** - считыватель SD-карт отсутствует  
  **USE_SD 1** - считыватель SD-карт подключен  

#### USE_MP3
Параметр **USE_MP3** определяет подключен ли к устройству проигрыватель MP3- файлов DFPlayer  
  **USE_MP3 0** - DFPlayer отсутствует  
  **USE_MP3 1** - DFPlayer подключен  

#### USE_TM1637
Параметр **USE_TM1637** определяет подключен ли к устройству индикатор TM1637  
  **USE_TM1637 0** - TM1637 отсутствует  
  **USE_TM1637 1** - TM1637 подключен  

#### USE_POWER
Параметр **USE_POWER** определяет присутствует ли в устройстве блок управления пиитанием матрицы - реде или MOSFET  
  **USE_POWER 0** - управление питанием матрицы отсутствует  
  **USE_POWER 1** - управление питанием матрицы подключено  

Управление питанием матрицы актуально для устройств, которые работают не круглосуточно (отключены какую-то часть времени) для экономии потребляемой электроэнергии.
При программном отключении устройства "Soft Power Off" светодиоды матрицы не светятся, но микросхемы, расположенные внутри светодиодов продолжают потреблять электроэнергию.
При значительном размере матриц ток потребления матрицы в целом может составлять значительную величину. Наличие блока управления позволяет физически убирать питание
с матрицы при программном отключении устройства. Полее подробная информаци я питании [здесь](https://github.com/vvip-68/GyverPanelWiFi/wiki/%D0%97%D0%B0%D0%BC%D0%B5%D1%82%D0%BA%D0%B8-%D0%BE-%D0%BF%D0%B8%D1%82%D0%B0%D0%BD%D0%B8%D0%B8)

**Следующие два параметра определяют  поддержку программных компонент устройства - включают или отключают соответствующий функционал**

#### USE_MQTT
Параметр **USE_MQTT** определеят использование дополнительного канала управления устройством удаленно через MQTT сервер, а также возможность 
[интеграции](https://github.com/vvip-68/GyverPanelWiFi/wiki/%D0%98%D0%BD%D1%82%D0%B5%D0%B3%D1%80%D0%B0%D1%86%D0%B8%D1%8F-%D0%B2-%D0%A3%D0%BC%D0%BD%D1%8B%D0%B9-%D0%B4%D0%BE%D0%BC)
вашего устройства в одну из систем умного дома. Подробнее [здесь](https://github.com/vvip-68/GyverPanelWiFi/wiki/%D0%9D%D0%B0%D1%81%D1%82%D1%80%D0%BE%D0%B9%D0%BA%D0%B0-%D0%BF%D0%BE%D0%B4%D0%BA%D0%BB%D1%8E%D1%87%D0%B5%D0%BD%D0%B8%D1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)
и [здесь](https://github.com/vvip-68/GyverPanelWiFi/wiki/API-%D1%83%D0%BF%D1%80%D0%B0%D0%B2%D0%BB%D0%B5%D0%BD%D0%B8%D1%8F-%D1%83%D1%81%D1%82%D1%80%D0%BE%D0%B9%D1%81%D1%82%D0%B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)  
  **USE_MQTT 0** - поддержка протокола управления через MQTT отключена
  **USE_MQTT 1** - поддержка протокола управления через MQTT включена

#### USE_WEATHER
Параметр **USE_WEATHER** определяет будет ли устройство получать информацию о текущей погоде с одного из погодных серверов - [Яндекс.Погода](https://github.com/vvip-68/GyverPanelWiFi/wiki/%D0%9D%D0%B0%D1%81%D1%82%D1%80%D0%BE%D0%B9%D0%BA%D0%B0-%D0%BF%D0%BE%D0%BB%D1%83%D1%87%D0%B5%D0%BD%D0%B8%D1%8F-%D0%B8%D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)
или [OpenWeatherMap](https://github.com/vvip-68/GyverPanelWiFi/wiki/%D0%9D%D0%B0%D1%81%D1%82%D1%80%D0%BE%D0%B9%D0%BA%D0%B0-%D0%BF%D0%BE%D0%BB%D1%83%D1%87%D0%B5%D0%BD%D0%B8%D1%8F-%D0%B8%D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)  
  **USE_WEATHER 0** - получение информации о погоде отключено  
  **USE_WEATHER 1** - получение информации о погоде включено  

При наличии информации о погоде текущая температура может отображаться совместно с часами и в бегущей строке. 
Также доступны два дополнительных режима по времени - "Закат" и "Рассвет" - позволяют выполнять запрограммированное действие с наступлением заката и рассвета.
Например автоматическое включение устройства с наступлением сумерек и отключение на рассвете.

**Следующий блок - подключение компонентов к пинам микроконтроллера (платы NodeMCU, Wemos d1 mini или ESP32).**

#### LED_PIN
Параметр **LED_PIN** указывает к какому пину платы микроконтроллера подключен управляющий вход матрицы. 

#### PIN_BTN
Параметр **PIN_BTN** указывает к какому пину платы микроконтроллера подключена кнопка.  
Обратите внимание, что в части схем для **DEVICE_VARIANT 0** кнопка подключена к пину **D4** либо к пину **D6** - смотри схему по которой собрано устройство.

#### POWER_PIN
Параметр **POWER_PIN** указывает к какому пину платы микроконтроллера подключен сигнальный вход блока управления питанием матрицы - реле или MOSFET

#### SD_CS_PIN
Параметр **SD_CS_PIN** указывает пин "Chip Select (CS)" считывателя SD-карт. 
Также считыватель использует пины *D5*, *D6* и *D7* для **ESP8266** или *G18*, *G19* и *G23* для **ESP32** - эти пины аппаратно зависимы и используются протоколом SPI с которым работает считыватель.

#### SRX
Параметр **SRX** указывает пин, соответствующий функции RX (прием данных) от проигрывателя MP3-файлов DFPlayer - TX пин (3) модуля DFPlayer

#### STX
Параметр **STX** указывает пин, соответствующий функции TX (передача данных) в проигрыватель MP3-файлов DFPlayer - RX пин (2) модуля DFPlayer

#### DIO
Параметр **DIO** указывает пин приема/передачи данных в индикатор TM1637 по протоколу I2C

#### CLK
Параметр **CLK** указывает пин тактирования данных индикатора TM1637 по протоколу I2C

### Дополнительные параметры

#### WAIT_PLAY_FINISHED
Параметр **WAIT_PLAY_FINISHED** определяет поведение при проигрывании эффектов  с SD- карты  
  **WAIT_PLAY_FINISHED 0** - переключаться на следующий эффект только когда весь файл полностью показан  
  **WAIT_PLAY_FINISHED 1** - прерывать показ файла с SD-карты по истечении времени эффекта  

#### DEBUG_SERIAL
Параметр **DEBUG_SERIAL** определяет будет ли выводиться отладочная информация и лог работы устройства в монитор порта - Serial  
  **DEBUG_SERIAL 0** - отладочный вывод отключен
  **DEBUG_SERIAL 1** - отладочный вывод включен

Отключение отладочного вывода позволяет сэкономить порядка 150 килобайт памяти программы, но лишает возможности отслеживать поведение устройства в мониторе порта
для выявления причин поведения устройства не соответствующего ожиданию.

**Внимание!!!**  
Если вы собрали **полнокомплектное** устройство на микроконотроллере **ESP8266** - вариант компиляции `DEVICE_VARIANT 1` -
установка параметра **DEBUG_SERIAL 0** ***обязательна!!!***. В противном случе устройство работать не будет, поскольку вывод 
информации отладки в Serial использует пины D9 и D10, к которым уже подключены компоненты схемы. Вследствие возникающего конфликта микроконтроллер может даже вовсе не запуститься.

Также для `DEVICE_VARIANT 1` с сенсорной кнопкой при прошивке устройства следует отключать пин `D9` - иначе прошивка не будет загружена в устройство из за конфликта использования пинов.

## Завершение настройки

После того, как параметры прошивки сконфигурированы, скомпилируйте скетч и [загрузите](https://github.com/vvip-68/GyverPanelWiFi/wiki/%D0%9F%D0%BE%D1%88%D0%B0%D0%B3%D0%BE%D0%B2%D0%B0%D1%8F-%D0%B8%D0%BD%D1%81%D1%82%D1%80%D1%83%D0%BA%D1%86%D0%B8%D1%8F-%D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)
прошивку в микроконтроллер.

После успешной загрузки (смотрите сообщение в мониторе порта) ваше устройство либо подключится к локальной сети, если соответствующие параметры были указаны в скетче,
либо создаст точку доступа с адресом 192.168.4.1  

Для дальнейшей настройки параметров соединения с сетью и режимов работы устройства - установите на смартфон приложение **WiFiPanel.apk** из папки ***Androud*** проекта,
подключите телефон к сети или созданной точке доступа и продолжите выполнение [настройки устройства](https://github.com/vvip-68/GyverPanelWiFi/wiki/%D0%9D%D0%B0%D1%81%D1%82%D1%80%D0%BE%D0%B9%D0%BA%D0%B0-%D0%BF%D0%B0%D1%80%D0%B0%D0%BC%D0%B5%D1%82%D1%80%D0%BE%D0%B2-%D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) 
в приложении.

**Примечание:** приложения для iPhone в природе не существует, если только не найдется энтузиаст, способный написать такое приложение.

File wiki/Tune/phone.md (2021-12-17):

# Настройка параметров в приложении

## Подключение к устройству

Итак, прошивка настроена, скомпилирована и загружена в микроконтроллер. Микроконтроллер запустился и в окне монитора порта вы видите сообщение, 
что точка доступа **PanelAP** создана со стандартным IP **192.168.4.1** и стандартным паролем 12341234.  

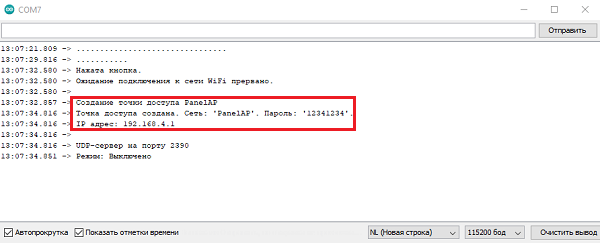
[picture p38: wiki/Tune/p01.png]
Монитор порта

               
Откройте в телефоне настройки WiFi подключений, найдите созданную сеть **PanelAP**  

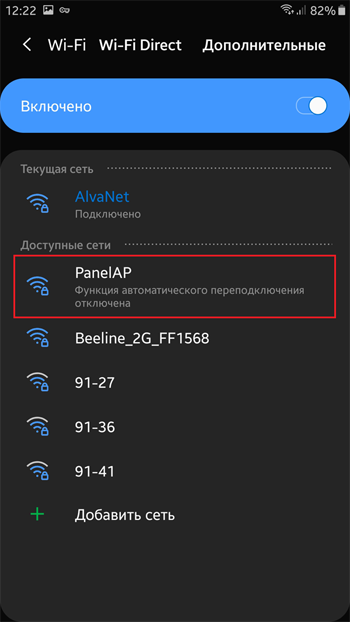
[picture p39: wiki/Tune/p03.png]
PanelAP-1


Выберите сеть **PanelAP**, введите в поле пароля пароль **12341234** и нажмите кнопку **"Подключиться"**  

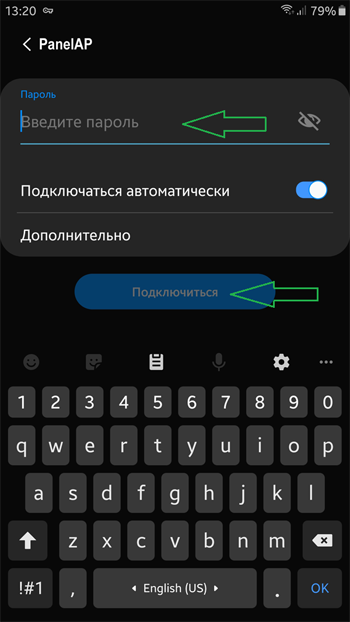
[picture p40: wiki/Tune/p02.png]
PanelAP-2


Ваш телефон подключился к точ	ке доступа, созданной устройством  

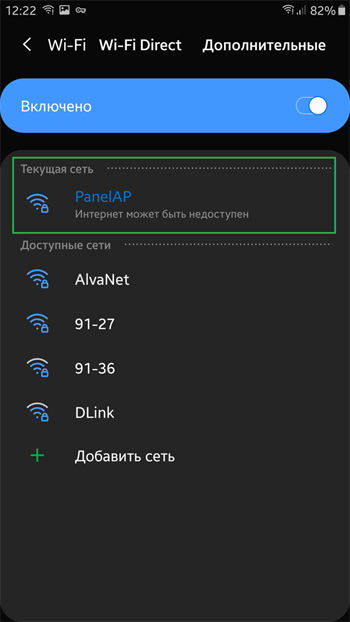
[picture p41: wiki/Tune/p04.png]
PanelAP-3


Найдите в папке проекта **Android/AppInventor** файл приложения ***PanelSetupWiFi.apk***
и установите его на ваш смартфон. Запустите приложение.

Приложение-1

В списке доступных подключений уже выбрано подключение **PanelAP**, параметры подключения - **192.168.4.1:2390**. Нажмите кнопку **"Подключить"**.  

Приложение подключится к устройству. В верхней части экрана приложения вы увидите набор кнопок, позволяющих переключаться между страницами интерфейса приложения.
Перейдите на страницу **"Настройки подключения"**.

Приложение-2

В секции **"Параметры сети"** укажите имя сети (SSID) и пароль доступа в сеть. В поле **"Текущий IP"** укажите желаемый адрес, 
который получит устройство в вашей сети. Обратите внимание, что IP адрес должен быть свободным, то есть не принадлежать какому-либо другому работающему в сети устройству.
При необходимости проверьте адреса вашей сети в настройках вашего роутера. Нажмите кнопку **"Сохранить"**. 
Для верности - можно нажать несколько раз - не всегда пакеты с данными успешно доходят до устройства.

Устройство выполнит переподключение к сети с указанным адресом. Вы увидите соответствующие сообщения в мониторе порта.
На матрице устройства бегущей строкой отобразится адрес, полученный устройством.

После того, как настройки сети применены и устройство перезагрузилось - приложение потеряет связь с устройством.  
Перейдите в приложении на страничку начального подключения и нажмите кнопку **"Добавить"**.

Приложение-3

После нажатия на кнопку **"Добавить"** откроется страница создания нового подключения.

Приложение-4

В поле **"Имя"** дайте имя создаваемому соединению. Это имя позже можно будет выбрать из списка созданных соединений для быстрого выбора устройства для подключения.  
В поле **"IP адрес"** укажите IP адрес, который получило ваше устройство при регистрации в вашей локальной сети.  
В поле **"Порт"** укажите порт подключения, который был указан на этапе конфигурирования прошивки перед компиляцией. Значение по умолчанию ***2390***  
Обратите внимание, что при настройке соединения отмечен чекбокс **"Локальная сеть"**

Нажмите кнопку **"Подключить"**. Приложение сохранит введенные настройки подключения для дальнейшего использования.  
После подключения к устройству вы снова увидите в приложении доступные элементы управления.

## Управление по каналу MQTT

Если в настройках прошивки вы указали возможность использования управления по [каналу MQTT](https://github.com/vvip-68/GyverPanelWiFi/wiki/%D0%9D%D0%B0%D1%81%D1%82%D1%80%D0%BE%D0%B9%D0%BA%D0%B0-%D0%BF%D0%BE%D0%B4%D0%BA%D0%BB%D1%8E%D1%87%D0%B5%D0%BD%D0%B8%D1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)  
```#define USE_MQTT 1```  
выполните в приложении на смартфоне [настройку](https://github.com/vvip-68/GyverPanelWiFi/wiki/%D0%9D%D0%B0%D1%81%D1%82%D1%80%D0%BE%D0%B9%D0%BA%D0%B0-%D0%BF%D0%BE%D0%B4%D0%BA%D0%BB%D1%8E%D1%87%D0%B5%D0%BD%D0%B8%D1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) 
связи с использованием этого канала.

```
Управление по каналу MQTT позволяет управлять устройством не находясь в непосредственной близости от него.
Если ваша гирлянда висит на балконе 12-го этажа многоэтажного здания и с улицы видна только через дорогу от него - вам скорее всего не удастся подключится 
к вашей локальной сети. В этом случае может быть использовано управление по каналу MQTT - гирлянда будет доступна даже если вы находитесь в другом городе.
```

### Настройка подключения со стороны устройства

Подключитесь к вашему устройству, используя уже настроенный вами канал ***"Локальная сеть"***.  
Перейдите на страничку настройки соединения к секции **"Настройки MQTT"**.  

![Приложение-5](https://github.com/vvip-68/GyverPanelWiFi/blob/master/wiki/Tune/p07.png)

Вы можете использовать любой публичный MQTT-брокер, который соответствует [требованиям](https://github.com/vvip-68/GyverPanelWiFi/wiki/%D0%9D%D0%B0%D1%81%D1%82%D1%80%D0%BE%D0%B9%D0%BA%D0%B0-%D0%BF%D0%BE%D0%B4%D0%BA%D0%BB%D1%8E%D1%87%D0%B5%D0%BD%D0%B8%D1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) 
или установить и настроить свой собственный MQTT-сервер. По умолчанию устройство использует бесплатный MQTT-брокер ***mqtt.by*** на порту **1883**. 
Укажите имя сервера MQTT и порт подключения в полях **"Имя сервера"** и **"Порт"** соответственно.  

Выбранный нами сервер ***mqtt.by*** использует авторизацию по ***Логину*** и ***Паролю*** - узнайте их в личном кабинете в настройках профиля на сайте брокера.  

Уникальность соединения канала управления устройством обеспечивается выбранным префиксом, добавляемым к
топику команд управления устройством. Придумайте уникальное значение и укажите его в поле **"Префикс"**.
Используйте только латинские буквы, цифры, знак подчеркивания и минус.
В нашем случае используется префикс ***tfhi8fb***. Помимо уникального значения - идентификатора устройства поле **"Префикс"**
для выбранного брокера ***mqtt.by*** должно содержать в начале префикса конструкцию ***user/\<login\>/***, где *\<login\>* - ваш логин, указанный в вашем личном кабинете на сайте брокера. В данном примере полный префикс - ***user/vvip/tfhi8fb***

Если канал связи создается для управления одним устройством - в качестве уникального идентификатора можете указать в поле **"Префикс"** любое понятное вам значение, например ***WiFiPanel***.  

Нажмите кнопку **"Сохранить"** для отправки настроек в устройство.  
Отметьте чекбокс **"Использовать MQTT"** для активации соединения.  

В мониторе порта вы увидите, что устройство отправило брокеру пакет со значениями своего текущего состояния.  
Устройство готово к работе по каналу MQTT.  

### Настройка подключения со стороны приложения

Откройте в приложении страницу настроек соединения, выберите в комбобоксе созданное соединение с вашим устройством и нажмите кнопку **"Править"**.  

![Приложение-6](https://github.com/vvip-68/GyverPanelWiFi/blob/master/wiki/Tune/p09.png)

Настройте параметры соединения с устройством через канал MQTT:  

![Приложение-7](https://github.com/vvip-68/GyverPanelWiFi/blob/master/wiki/Tune/p10.png)

Установите чекбокс способа подключения - **MQTT канал**  
В полях **"Сервер"** и **"Порт"** укажите имя MQTT-сервера и порт, как вы указали их в настройках подключения со стороны устройства выше.  
Укажите **"Логин"** и **"Пароль"** для подключения к серверу или оставьте их пустыми, если сервер не требует авторизации.  
В поле **"Префикс"** укажите тот же префикс, который вы использовали в ***Настройках подключения*** со стороны устройства выше.  

Нажмите кнопку **"Сохранить"** вверху страницы или сразу кнопку **"Подключить"** - настройки соединения будут сохранены.  

Какой канал соединения с устройством будет использоваться - ***Локальная сеть*** или ***MQTT*** можно увидеть в специальном информационном поле на странице **"Подключение"**
в приложении:  

![Приложение-8](https://github.com/vvip-68/GyverPanelWiFi/blob/master/wiki/Tune/p11.png)

В случае подключение к устройству в ***локальной сети*** - указана IP адрес и порт подключения устройства.  
В случае подключение к устройству по к ***каналу MQTT*** - указано имя сервера (MQTT-брокер) и портподключения к серверу.  

# Настройка устройства из приложения

Итак, соединение с устройством установлено, интерфейс управления возможностями устройства - доступен. 
Можно приступать к настройке функций и эффектов.

В верхней части экрана приложения находится панель переключения страничек интерфейса

![Приложение-9](https://github.com/vvip-68/GyverPanelWiFi/blob/master/wiki/Tune/p12-0.png)

Здесь:  
1. Настройки соединения
2. Общие настройки
3. Настройки эффектов
4. Настройки бегущей строки
5. Настройки часов
6. Настройки будильников
7. Настройки подключения
8. Настройки режимов по времени
9. Закрыть приложение

### Настройки соединения

[Настройки соединения](https://github.com/vvip-68/GyverPanelWiFi/wiki/%D0%9D%D0%B0%D1%81%D1%82%D1%80%D0%BE%D0%B9%D0%BA%D0%B0-%D0%BF%D0%B0%D1%80%D0%B0%D0%BC%D0%B5%D1%82%D1%80%D0%BE%D0%B2-%D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)
подробно рассмотрены в этом документе выше, в разделе посвященном
подключению к устройству из приложения. Повторяться не будем.

### Общие настройки

На странице общих наcтроек собраны элементы управления, позволяющие установить следующие параметры устройства:

![Приложение-10](https://github.com/vvip-68/GyverPanelWiFi/blob/master/wiki/Tune/p12-1.png)

**Общая яркость** - определяет яркость свечения светодиодов матрицы.  
Максимальная возможная яркость ограничена используемым блоком питания.  

```
Внимание!!! Длительное использование устройства на максимальной яркости может приводить к перегреву 
светодиодов и их деградации. Обеспечьте хороший отвод тепла от светодиодов для продления их максимального
срока службы. Рекомендуемая яркость - на уровне 25-50%.
```

#### Управление режимами

- Чекбокс **"Автоматическое управление"** - если включен, устройство перебирает все доступные эффекты, сменяя их через указанный промежуток времени.
  Если чекбокс отключен - выполняется постоянная демонстрация включенного вручную эффекта.  
- Чекбокс **"Случайный порядок"** - если включен - алгоритм перебора эффектов выбирает следующий эффект случайным образом. 
  Если чекбокс отключен - эффекты перебираются последовательно из списка разрешенных к использованию (смотри раздел [***"Настройки эффектов"***](https://github.com/vvip-68/GyverPanelWiFi/wiki/%D0%9D%D0%B0%D1%81%D1%82%D1%80%D0%BE%D0%B9%D0%BA%D0%B0-%D0%BF%D0%B0%D1%80%D0%B0%D0%BC%D0%B5%D1%82%D1%80%D0%BE%D0%B2-%D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) ниже)  
- Кнопка **"Предыдущий"** - возврат к предыдущему эффекту, если используется последовательный перебор эффектов  
- Кнопка **"Следующий"** - переход к следующему эффекту, если используется последовательный перебор эффектов  
  В случае, если включен режим *случайного* выбора эффекта, кнопки **"Предыдущий"** и **"Следующий"** просто меняют эффект на другой, выбранный случайным образом.  
- Значение **"Время режима"** - задает время демонстрации эффекта в секундах. По истечении указанного интервала времени будет включен следующий (случайный) эффект.  
- Значение **"Авторежим через"** определяет время возврата от включенного вручную эффекта к режиму автоматической смены эффектов. 
  Если указан **0** - возврат от ручного режима к автоматическому управлению - отключен. Заданный вручную режим будет демонстрироваться постоянно.  

#### Быстрые режимы

- Кнопка программного включения / отключения устройства.  
  Позволяет "выключить" устройство (отключить матрицу светодиодов). При наличии схемы управления питания матрицей через реле или MOSFET - снимается подача питания на светодиоды.  
- Кнопки быстрого включения "избранного" режима. Одновременно с включением выбранного режима отключается автосмена режима, выбранный эффект будет демонстрироваться постоянно.  
- Кнопка отключения будильника, если будильник включился или переход к странице настроек будильников, если будильник не активен.  

#### Лимит по току

- Значение указанное в поле **"Лимит по току"** позволяет программным образом ограничить максимальную яркость светодиодов и уберечь блок питания от срабатывания защиты
  или выхода из строя, когда установленный уровень яркости светодиодов приводит к повышенному потреблению тока, которое используемый источник питания обеспечить не в состоянии. 
  Значение указывается в миллиамперах. Рекомендуется устанавливать ограничение по току процентов на 20 меньше максимального паспортного тока вашего источника питания.  

  После ввода в поле ограничения по току нажмите на кнопку **"Установить"**, чтобы настройки были сохранены и применены в устройстве.

#### Получение погоды.

Если в настройках прошивки при компиляции указана возможность получения текущей погоды  (параметр ```#define USE_WEATHER 1```) - в этом разделе
задаются параметры запроса информации о погоде с соответствующих погодных серверов.  

**Выбор источника** 
- **Выключено** - информация о погоде не получается, отображение температуры в часах и в бегущей строке отключено.  
- **Yandex** - информация о погоде получается с погодного сервера ***Yandex.ru***  
- **OpenWeatherMap** - информация о погоде получается с погодного сервера ***OpenWeatherMap.com***  

В состав информации, получаемой с погодного сервера, кроме текущей температуры также получается время наступления ***рассвета*** и ***заката*** для возможности работы специальных 
["Режимов по времени"](https://github.com/vvip-68/GyverPanelWiFi/wiki/%D0%9D%D0%B0%D1%81%D1%82%D1%80%D0%BE%D0%B9%D0%BA%D0%B0-%D0%BF%D0%B0%D1%80%D0%B0%D0%BC%D0%B5%D1%82%D1%80%D0%BE%D0%B2-%D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) - 
**Рассвет** и **Закат**.  

- **"Код региона Yandex"** - задает код города (села, метеостанции) для которого запрашивается информация с сервера погоды ***Yandex***.  
- **"Код региона OpenWeatherMap"** - задает код города (села, метеостанции), для которого запрашивается информация с сервера погоды ***OpenWeatherMap***.  

Подробнее о настройках погоды читайте в [этой статье](https://github.com/vvip-68/GyverPanelWiFi/wiki/%D0%9D%D0%B0%D1%81%D1%82%D1%80%D0%BE%D0%B9%D0%BA%D0%B0-%D0%BF%D0%BE%D0%BB%D1%83%D1%87%D0%B5%D0%BD%D0%B8%D1%8F-%D0%B8%D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)  

- **"Интервал обновления"** - задаёт с какой периодичностью (в минутах) будет обновляться информация о текущей температуре с выбранного сервера погоды.

#### Резервная копия настроек

Позволяет сохранить все выполненные настройки во внутренней файловой системе микроконтроллера или на подключенной SD-карте, если прошивка перед компиляцией была сконфигурирована
для работы с SD-картой ```#define USE_SD 1``` и карта вставлена в соответствующий модуль устройства.  

В резервной копии сохраняются все параметры, заданные как на этой страничке приложения, так и на других - *настройки эффектов*, *тексты бегущей строки*, *настройки часов*, *будильников*, *режимов по времени* и т.д.
Рекомендуется выполнить сохранение текущих настроек устройства после завершения всего комплекса работ по настройке.  

Если SD-карта доступна - вы видите чекбокс выбора места хранения резервной копии настроек - во ***внутренней памяти*** или на подключенной ***SD-карте***.  
Если SD-карта отсутствует - резервная копия настроек может быть сохранена только во внутренней памяти микроконтроллера, в его файловой сситеме.

Нажмите кнопку **"Сохранить"** для сохранения в выбранном хранилище файла настроек - ***eeprom.bin***  
После успешного сохранения настроек станет доступна кнопка **"Загрузить"**. Нажатие этой кнопки загрузит настройки из файла ***eeprom.bin***, размещенном в указанном хранилище.
После успешной загрузки сохраненных настроек устройство будет автоматически перезагружено для применения считанных параметров.

### Настройки эффектов

На этой странице размещены элементы выбора демонстрируемого эффекта и его настройки. Наличие тех или иных настроек зависят от конкретного эффекта, какие параметры эффекта реализованы в прошивке.  

![Приложение-11](https://github.com/vvip-68/GyverPanelWiFi/blob/master/wiki/Tune/p13.png)

- Комбобокс **"Выбор эффекта"** - выбирает и активизирует эффект для демонстрации на матрице.  
  Выбор эффекта в комбобоксе отключает режим автоматической смены. Выбранный эффект будет воспроизводиться,
  пока режим автоматической смены не будет включен вручную или через указанный интервал автоматического включения демо-режима.  

- Чекбокс **"Использовать в демо-режиме"**  
  Если чекбокс активирован - эффект будет включен в список воспроизводимых для режима автоматической смены эффектов.  
  Если чекбокс отключен - эффект можно выбрать вручную, но при переходе к следующему эффекту в режиме демонстрации он будет пропущен.  

- Чекбокс **"Использовать бегущую строку поверх эффекта"**  
  Если чекбокс активирован и режим воспроизведения бегущей строки включен - текст бегущей строки будет отображаться поверх эффекта.  
  Если чекбокс отключен - бегущие строки поверх этого эффекта показываться не будут.  

- Чекбокс **"Использовать часы поверх эффекта"**  
  Если чекбокс активирован - поверх эффекта будут отображаться часы и текущая температура, если получение информации с сервера погоды включено и размеры матрицы позволяют разместить температуру вместе с часами.  
  Если чекбокс отключен - часы и температура поверх этого эффекта показываться не будут.  

```
  Для демонстрации часов малого размера требуется матрица размером не менее 15x5, 
  больших - не менее 23x7 (ширина x высота)
```

- Слайдер **"Контрастность"** позволяет регулировать яркость эффекта относительно общей яркости, установленной для устройства. 
  Если воспроизводится полноэкранный полноцветный эффект - часы не его фоне могут стать нечитаемыми.
  Снижение уровня яркости эффекта относительно яркости часов (***контраснтность***) позволяет сделать часы на фоне эффекта более заметными.  

- Слайдер **"Скорость"** регулирует скорость эффекта.  
  Некоторые эффекты по своему алгоритму требуют для формирования максимально возможной скорости.
  Для этих эффектов регулировка скорости недоступна.  

- Слайдер **"Вариант"** регулирует индивидуальные параметры эффекта. Значение регулировки зависит от выбранного эффекта.
  Например, для "шумовых" эффектов слайдер изменяет размер цветового пятна.  
  Для таких эффектов как ***"Светлячки"***, ***"Шарики"***, ***"Конфетти"***, ***"Радуга"*** и подобных - количество или размер элементов.  
  Для режима полноэкранной заливки цветом - цвет или насыщенность
  Для некоторых эффектов изменение параметра **"Вариант"** может отсутствовать.  

- Комбобокс **"Вариант"** позволяет выбрать один из возможных вариантов эффекта.  
  Например, для эффекта ***"Радуга"*** - направление радужных полос, для эффекта ***"Стрелки"*** - направление и место появления стрелок, и т.д.  
  Как правило, один из вариантов - ***"Случайный"***. Выбор этого варианта позволяет устройству выбирать вариант случайным образом.  

- Чекбокс **"Сегменты"** - переключение между широкоформатным видом эффекта или видом разделенным на сегменты.  
  
  Некоторые эффекты, например, ***"Пейнтбол"*** или ***"Водоворот"*** выглядят не очень красиво в широкоформатном режиме, когда цветовой шар движется по всей площади матрицы.  
  Если чекбокс включен - всё пространство матрицы делится на квадратные сегменты. Ширина квадрата выбирается по меньшему размеру матрицы.
  Так, матрица 48x16 может быть разделена на ***три*** квадратных сегмента ***16x16***. Сам эффект рисуется синхронно в каждом сегменте.
  Такой подход позволяет сделать эффект более насыщенным. Для матриц, у которых размеры не позволяют сформировать более одного сегмента,
  эта регулировка пиведет к сужению поля отображения эффекта до одного квадрата с размерами по меньшей стороне матрицы.  

### Настройки бегущей строки

Устройство поддерживает отображение до 36 различных строк текста в виде бегущей строки поверх эффектов.  
Все параметры отображения задаются на странице настройки параметров ***бегущей строки***  

![Приложение-12](https://github.com/vvip-68/GyverPanelWiFi/blob/master/wiki/Tune/p14.png)

- Чекбокс **"Текст поверх эффектов"**
  Включите этот чекбокс для активации периодического отображения бегущей строки поверх эффектов.
  Этот "выключатель" имеет приоритет в настройках, его отключение запрещает бегущую строку на устройстве.  
  Если чекбокс отключен - бегущая строка НЕ БУДЕТ отображаться, даже если в настройках эффектов отображение разрешено.  
  Если чекбокс включен - бегущая строка будет отображаться поверх эффектов для которых в их настройках показ бегущей строки разрешен.  

- **"Интервал"** - задает время в секундах - период отображения. Очередной текст будет отображен поверх эффектов с разрешенным 
  показом бегущей строки по истечении указанного интервала времени. Если ко времени показа бегущей строки отображается эффект, 
  для которого стоит запрет бегущей строки - текст будет показан немедленно с началом эффекта для которого бегущая строка разрешена.  

- Кнопка **"Установить"** отправляет настройки интервала в устройство.  

- **"Цвет текста"** - выбор варианта цвета отображения текста, когда внутри текста цвет не задан специальным макросом цвета.  
  - ***"Одноцветный"*** - задает цвет отображения бегущей строки. Кнопка **"Цвет"** позволяет выбрать желаемый цвет из цветового круга.  
  - ***"Радуга"*** - буквы вдоль матрицы окрашиваются в цвет радуги. Цвет букв меняется с их перемещением вдоль матрицы.  
  - ***"Каждая буква свой цвет"*** - каждая буква имеет свой цвет. Цвет букв НЕ меняется с их перемещением вдоль матрицы.  

- Слайдер **"Скорость"** задает скорость прокрутки текста бегущей строки на матрице.  

#### Ячейки хранения текста

Каждой ячейке соответствует кнопка от **0** до **9**, а так же **A**..**Z**. Нажатие на кнопку загружает в строку редактирования 
текст из соответствующей ячейки.  

Введенный в строку текст можно сохранить, нажав на кнопку **"Сохранить"**.  

Нажатие на кнопку **"Просмотр"** помимо сохранения текста в устройстве также запускает отображение бегущей строки на устройстве.  

Текст бегущей строки может содержать специальные управляющие последовательности - ***макросы***, позволяющие задавать цвет отображения текста,
количество или продолжительность показа, привязывать текст к событиям и многое другое. Подробная инструкция по использованию макросов
находится в [этой статье](https://github.com/vvip-68/GyverPanelWiFi/wiki/%D0%9D%D0%B0%D1%81%D1%82%D1%80%D0%BE%D0%B9%D0%BA%D0%B0-%D0%B1%D0%B5%D0%B3%D1%83%D1%89%D0%B5%D0%B9-%D1%81%D1%82%D1%80%D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).  

Для быстрой вставки макроса в редактируемый текст используйте **кнопки подстановки макросов**, расположенные ниже строки ввода.
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

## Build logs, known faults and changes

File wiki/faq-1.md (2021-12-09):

## FAQ
### Основные вопросы
**В**: **Как скачать с этого грёбаного сайта?**  
**О**: На главной странице проекта (где ты читаешь этот текст) вверху справа зелёная кнопка **Clone or download**, вот её жми, там будет **Download ZIP**

**В**: **Скачался какой то файл .zip, куда его теперь?**  
**О**: Это архив. Можно открыть стандартными средствами Windows, но думаю у всех на компьютере установлен WinRAR, архив нужно правой кнопкой и извлечь.

**В**: **Я совсем новичок! Что мне делать с Arduino, где взять все программы?**  
**О**: Читай и смотри видос http://alexgyver.ru/arduino-first/

**В**: **Вылетает ошибка загрузки / компиляции!**  
**О**: Читай тут: https://alexgyver.ru/arduino-first/#step-5

-----

### Вопросы по этому проекту

**В**: **Эй чувак! У тебя проект не компилится. Ты файл FastLed.h в проект забыл включить. Выложи!**  
**О**: Это стандартная библиотека для FastLed для управления адресными светодиодами. Идите в менеджер библиотек и установите ее. Или скачайте с [сайта производителя](https://github.com/FastLED/FastLED)

-----

**В**: **Собрал, использую NodeMCU/Wemos. Ничего не работает! Мигает один или несколько светодиодов в начале матрицы. И всё.**  
**О**: Производители разных плат (NodeMCU, Wemos) могут использовать различные схемы соединения контактов микроконтроллера ESP8266 к выводам макетной платы. Обычно используемый в проекте пин вывода на ленту приходится или на пин D2 или на пин D4. Для проверки не подключайте сигнальный провод матрицы к микроконтроллеру, вместо этого через резистор коснитесь вывода D2 или D4 пина микроконтроллера. Большая вероятность что матрица заработает с тем или иным вариантом подключения.

-----

**В**: **Не компилируется. Выбрана плата "голая ESP8266-12E". Сообщение об ошибке: "D4 was not declared in this scope."**  
**О**: Очевидно производители библиотеки для "голой ESP8266-12E" не определили данную константу. Используйте вместо константы D4 числовое определение пина для вашей платы или выполните компиляцию проекта для плат NodeMCU или WeMos D1 mini.

-----

**В**: **Не компилируется. В сообщении об ошибке содержатся сведения о дублирующихся библиотеках.**  
**О**: В вашей среде установлено две версии одной и той же библиотеки. Обычно это библиотека FastLED - одна версия находится в папке установки среды Arduino (например в "C:\Program Files (x86)\Arduino\libraries\"), другая - в папке документов пользователя (например "C:\Users\vvip-68\Documents\Arduino\libraries\"). Удалите одну из версий библиотек и попробуйте скомпилировать снова.

-----

**В**: **Не компилируется. В сообщении об ошибке что-то про несоответствие типов.**  
**О**: Обычно такая ситуация возникает в двух случаях:
- выбрана неверная плата. Используйте NodeMCU 1.0 (ESP-12E Module) или Wemos D1 mini. Под эти платы проект собирается, под другие, возможно, нужна модификация кода.
- установлена устаревшая версия библиотек поддержки плат - например для ESP8266 версия библиотеки 2.4.2. Данный проект использует библиотеки для плат ESP8266 версии **2.7.4**. Обновите библиотеки поддержки плат.

-----

**В**: **Собрал, использую NodeMCU (Wemos D1 mini). Эффекты работают, но нестабильно. Случайные вспышки на матрице. Буквы бегущей строки прыгают.**  
**О**: Попробуйте рекомендации изложенные в статье [Три шага к успеху](https://github.com/vvip-68/GyverPanelWiFi/wiki/%D0%A2%D1%80%D0%B8-%D1%88%D0%B0%D0%B3%D0%B0-%D0%BA-%D1%83%D1%81%D0%BF%D0%B5%D1%85%D1%83.-%D0%9D%D0%B5%D0%BA%D0%BE%D1%8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...)

-----

**В**: **Подскажите, что не так... C подключением через точку доступа всё исправно работает, а при попытке подключиться к локальной сети не могу законнектиться через приложение. В чем может быть проблема?**  
**О**: Проблема может быть в неправильно указанном статическом адресе / параметрах сети в прошивке. В скетче по умолчанию используется адрес в сети 192.168.**0**.xxx. Ваш WiFi роутер в зависимости от настроек может создавать сеть в другом диапазоне. Чаще всего это 192.168.**1**.xxx или 192.168.**100**.xxx; Проверьте какую сеть создает ваш роутер и укажите в скетче и при подключении приложения к сети именно эту сеть.

-----

**В**: **Автор неверно указал IP адрес панели 192.168.4.1 в режиме точки доступа. На самом деле он 192.168.4.2 - указываю его, приложение на смартфоне подключается. Правда управлять устройством не получается все равно - она не реагирует на изменения.**  
**О**: Нет, все правильно. IP панели - 192.168.4.1; Адрес 192.168.4.2 получает ваш смартфон при подключении к точке доступа. Когда в приложении для подключения вы указываете адрес 192.168.4.2 - вы подключаете ваш смартфон с самому себе, а не к устройству. Естественно никакое управление устройством работать не будет.   

-----

**В**: **Устройство создает точку доступа, телефон к ней подключается. В приложении ввожу IP адрес панели 192.168.4.1, но соединение не происходит. Что я делаю не так?**  
**О**: Некоторые телефоны не могут передавать данные через точку доступа, пока в них активен мобильный интернет. Все передаваемые данные отправляются в интернет, вместо передачи их в точку доступа. В настройках телефона выключите мобильный интернет ("Мобильные данные"). После этого телефон из приложения должен подключиться к устройству.  

-----

**В**: **Устройство подключается к сети, получает адрес - это видно в логах. Телефон к устройству подключается. В приложении ввожу IP адрес, полученный устройством (тот, что выводится в логе), но соединение не происходит. Что я делаю не так?**  
**О**: Некоторые роутеры  (например роутеры ASUS, в частности Asus RT-AC58U), имеют в своих настройках параметр "Изоляция точки доступа", он же - "Режим изоляции клиентов". По умолчанию эта настройка включена. Отключите ее. После этого приложение должно подключиться к смартфону.  

-----

**В**: **В скетче есть настройки который задают имя и пароль к локальной сети. Указываю, но к сети даже не пытается подключиться В чем дело?**  
```
#define NETWORK_SSID ""  // Имя WiFi сети - пропишите здесь или задайте из программы на смартфоне   
#define NETWORK_PASS ""  // Пароль для подключения к WiFi сети - пропишите здесь или задайте из программы на смартфоне
```
**О**: Эти настройки определяют параметры доступа к сети по умолчанию, которые используются при ***ПЕРВОЙ*** загрузке прошивки в устройство. В этот момент они сохраняются в EEPROM и при последующих запусках имя сети и пароль извлекаются из энергонезависимой памяти и используются уже извлеченные значения, а не те, что прописаны в #define. Если вы уже запускали устройство и ПОСЛЕ этого изменили в скетче имя и пароль сети, вам нужно также изменить значение флага, указывающее было ли уже сохранение параметров в EEPROM или еще нет. Этот флаг находится в файле a_def_soft.h в строке 7  

```
#define EEPROM_OK 0x5A // Флаг, показывающий, что EEPROM инициализирована корректными данными 
```

Измените его на любое другое значение, например **0xA5**

-----

**В**: **Погода в Украине работать будет? Как узнать код региона для моего города?**  
**О**: Изучите настройку погоды для вашего региона [тут](https://github.com/vvip-68/GyverPanelWiFi/wiki/%D0%9D%D0%B0%D1%81%D1%82%D1%80%D0%BE%D0%B9%D0%BA%D0%B0-%D0%BF%D0%BE%D0%BB%D1%83%D1%87%D0%B5%D0%BD%D0%B8%D1%8F-%D0%B8%D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)

-----

**В**: **Собрал, всё работает, но в начале матрицы постоянно ярко горит один светодиод. Как исправить?**  
**О**: Это проблема новой версии ядра ESP8266. Версия 3.0.0 и новее несовместима с используемой версией библиотеки управления светодиодами FastLED.
Для исправления ситуации - вернитесь к более ранней версии ядра - 2.7.4; В Arduino IDE в менеджере плат найдите ESP8266, посмотрите какая версия ядра установлена у вас и установите вместо нее правильную версию - 2.7.4  

Внимание!!! -  проверьте правильность подключения управляющего пина микроконтроллера к матрице:  
При определении 
```
#define LED_PIN  2            // D2 пин ленты
```
версия ядра 3.x.x направляет управляющий сигнал на пин **D4** микроконтроллера, версия ядра 2.7.4 - на пин микроконтроллера **D2**  
Если с версией ядра 3.x.x на матрице были видны эффекты, а после установки ядра 2.7.4 на матрице пусто - сделайте одно из двух:
- перепаяйте провод на матрицу с D4 на D2 или
- измените объявление пина вывода на матрицу с **`#define LED_PIN  2`** на **`#define LED_PIN  D2`**  

Перепайка предпочтительнее, так как по умолчанию скетч и схема используют подключение к пину D4 кнопки. 
Если для вывода сигнала на матрицу используется пин D4 - кнопка работать не будет, пока вы в скетче не 
переопределите подключение кнопки на другой пин и не подключите кнопку физически к указанному пину.

-----

**В**: **Как мне добавить свою анимацию в скетч в дополнение к эффекту "Анимация"?**  
**О**: Изучите утилиту редактирования роликов и анимации [JinxFramer](https://github.com/vvip-68/GyverPanelWiFi/wiki/JinxFramer---%D1%80%D0%B5%D0%B4%D0%B0%D0%BA%D1%82%D0%BE%D1%80-%D0%B0%D0%BD%D0%B8%D0%BC%D0%B0%D1%86%D0%B8%D0%B8,-%D1%80%D0%BE%D0%BB%D0%B8%D0%BA%D0%BE%D0%B2,-%D0%BA%D0%B0%D1%80%D1%82%D0%B8%D0%BD%D0%BE%D0%BA) и [эту](https://github.com/vvip-68/GyverPanelWiFi/wiki/%D0%94%D0%BE%D0%B1%D0%B0%D0%B2%D0%BB%D0%B5%D0%BD%D0%B8%D0%B5-%D1%81%D0%B2%D0%BE%D0%B5%D0%B9-%D0%B0%D0%BD%D0%B8%D0%BC%D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) инструкцию  

-----

**В**: **Матрица после включения самопроизвольно меняет яркость. Или до максимума или до минимума.**  
**О**: ***Вариант 1***: У вас физически не подключена кнопка, а тип кнопки в скетче указан "Сенсорная":
`#define BUTTON_TYPE 0`. В этом случае микроконтроллер свободный пин кнопки, притянутый внутренним резистором микроконтроллера к "земле"
воспринимает как состояние кнопки "нажато". Длительное "нажатие" кнопки воспринимается скетчем как запрос на регулировку яркости матрицы.  
**Решение:** либо припаяйте кнопку, либо измените в скетче в настройках параметров оборудования тип кнопки на "Тактовая кнопка"
`#define BUTTON_TYPE 1`  

***Вариант 2***: Физическая кнопка не подключена, в назначении пинов указано:
```
#define LED_PIN 2             // D2 пин ленты
#define PIN_BTN D4            // кнопка подключена сюда (D4 --- КНОПКА --- GND)
```
Такое определение ядро ESP8266 версии 2.7.4 назначает D2 - выход сигнала на ленту, D4 - на кнопку.  
Ядро версии 3.x.x назначает и кнопку и ленту на один и тот же пин - D4.  
Вывод сигнала на D4 воспринимается кнопкой как постоянное нажатие - сигнал к изменению яркости лампы.  

**Решение:** ***Варант 1***:  
Изменить назначение кнопки или ленты на другой пин, например
```
#define LED_PIN D2             // D2 пин ленты
#define PIN_BTN D4             // кнопка подключена сюда (D4 --- КНОПКА --- GND)
```
Однако, ядро 3.x.x некорректно выводит сигнал на матрицу - будет постоянно гореть зеленым первый светодиод матрицы.  

**Решение:** ***Вариант 2***:  
Установить ядро версии 2.7.4 - при этом и кнопка и первый диод матрицы будут работать корректно, самопроизвольного изменения яркости не будет происходить.

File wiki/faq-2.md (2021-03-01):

## Всё собрал строго по инструкции, ничего не работает.

1. Разбираем всё обратно.
2. Берем платку, смотрим чтобы к ней НИЧЕГО не было подключено.
3. Плату в таком состоянии подключаем кабелем USB к компьютеру.
4. Берем последнюю версию [прошивки](https://github.com/vvip-68/GyverPanelWiFi/) и загружаем ее в микроконтроллер.
5. Смотрим в сообщениях, что загрузка успешно выполнена и осуществлен перезапуск микроконтроллера, а в мониторе порта, что скетч стартовал, вывел версию прошивки, создал точку доступа PanelAP
6. Устанавливаем на смартфон приложение из этого проекта из папки Android
7. Подключаемся телефоном к точке доступа, приложение подключаем к матрице, пробуем тыкать на кнопки.
8. Отключаем микроконтроллер от компьютера
9. Подключаем блок питания +5 вольт и минусовой провод к матрице. Минусовой провод подключаем также к пину GND микроконтроллера.
Контроллер подключаем USB кабелем к компьютеру, блок питания включаем в сеть.
10. Проверяем, что напряжение питания с блока не превышает +5.25 вольт. Если больше - регулируем его до уровня 4.8 вольта. (см. заметки о питании)
11. Сигнальным проводом с матрицы с подключенным резистором 200 Ом тыкаемся поочередно в пины D4 и D2 микроконтроллера. В каком-то из этих двух вариантов на матрице должно сформироваться осмысленное отображение эффекта или бегущего текста. Что из этого конкретно должно в данный момент отображаться написано в мониторе порта. Запоминаем подключение к какому пину дало результат.
12. Отключаем микроконтроллер и блок питания. Провод +5V с блока питания подключаем к микроконтроллеру на пин его входного напряжения питания (у разных плат обозначен по разному - Vin, Vcc или +5). Сигнальный провод матрицы припаиваем к пину, который определили шагом выше. Очень желательно между пинами Vin и GND микроконтроллера припаять электролитический конденсатор номиналом 1000-4700 мкф, и параллельно ему керамический конденсатор на 33-100 нф.
13. Включаем блок питания в розетку. Панель должна заработать.
14. Собираем всю конструкцию в корпус.

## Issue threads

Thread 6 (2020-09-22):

How can I edit the GyverPanelWiFi.aia file ?

dorinik, 2020-09-22:
Congratulations on your work!
I want to edit the GyverPanelWiFi.aia file.
I tried with MIT app inventor, but without success ...
How can I solve this problem?
Thanks!

yusufsulaiman, 2020-09-23:
@dorinik u can use thunkableclassic

vvip-68, 2020-09-23:
@yusufsulaiman, yes, you right. It is application for Thunkable Classic.
@dornic, for edit this aia file in Thunkable Classic you MUST have account in this system. However registration of new user was closed by owners a couple year ago. Only old-registered users can use this service.
Second issue is - application reach its maximal size. Addition 1-2-3 new block into application makes application stop to compile. Compiler begin retrieve an error of compilation.

dorinik, 2020-09-23:
Thank you for the answers !
I don't want to add new blocks, I just want to translate messages from Russian into English.
Please convert the GyverPanelWiFi.aia file to the format recognized by the MIT app inventor, because I don't have an old account on Thunkable Classic.
Thanks!

vvip-68, 2020-09-23:
Do you know a way to convert aia-file from Thinkable to MIT? I know nothing about this feature / tool.
Ok, because size of application reach limit, which do not allow add new features, I can try to translate labels in UI of application to English. But you know, part of russian words come from device from firmware - list of effects for example...

dorinik, 2020-09-23:
I'm already working on translating the firmware into English.
Please translate all the words that appear in the application in Russian into English.

dorinik, 2020-09-23:
vvip-68, can you send me the keystore exported from Thunkable?

vvip-68, 2020-09-23:
I will update project after completion. aia and apk files. I think it will be done before today night.
Could you please after that check the translation and take screenshots with inapropriate translation and send them to me.
English is not native language for me. So, translation can be tampered by sense...

dorinik, 2020-09-23:
Thanks a lot !

vvip-68, 2020-09-23:
I`ve commited English version of APK file.
Please check it and send me corrections for wrong translation

dorinik, 2020-09-23:
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

vvip-68, 2020-09-23:
1. I used Full HD screen of my smartphone (1920x1080). I tried to fix sizes of elements, but not sure that it will normally viewed on screens with smaller resolution.
2. I corrected missprints in "Effects" page - "Use effect in demo mode" and "Text over effect" (and "Вариант" as label of combobox.
3. Other texts in cyrillic (content of comboboxes and checkbox label) are coming from firmware. You said you are changing code of firmware by yourself.
a_def_soft.h - 20-29 - list of effect names + line 33 -"Марио" - name of animation picture
a_main.ino - 1171-1821 - content of combo box 'Kind of" for effects parameters and checkbox label "Ceгменты"

Do you need help with translation of these strings?

dorinik, 2020-09-23:
The screenshots are from a Samsung SM-A805F (2256x1080).
The translation of the firmware in English is not completed, I still have work ...
Thanks for your patience and time for the translation!
Respect!

dorinik, 2020-09-23:
In a_def_soft.h lines 20-28 - are changed to English, only "escaped" line 33 - "Марио"

vvip-68, 2020-09-23:
Probably you use increased font size. Screenshots look as coming from hot HD screen, max - 720 pix...
I use Samsung SM-J730FM with 1920x1080, and text looks more small then yours on standard (unchanged) settings and there was no issue with screen elements sizes and positioning...

dorinik, 2020-09-23:
With the changes you made, it fits perfectly on the screen now!

dorinik, 2020-09-23:
In order not to take up space, the attached print screens (432x960) are reduced compared to the initial resolution (1080x2400)

vvip-68, 2020-09-23:
I told not about real size of pics, I told about proportions of text size with comparison of size of screen. I`ve got similar picture as on your screenshots when I changed (increased) font size in phone settings up to 2 grade over standard settings for font size (seems the ingrement is 150% over normal / ordinal size)

dorinik, 2020-09-23:
All that's left is this:
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

vvip-68, 2020-09-23:
Updated.

Fab8888, 2022-08-16:
vvip-68, would you mind to send me the translate English version app inventor .aia file and apk file, I use much time to translate it, but it's quite difficult to translate the effect page drop down menu, I really don't know how to find the list words, thanks

vvip-68, 2022-08-16:
@Fab8888 , dorry I have no time to do that at all.
List of effects comes from sketch from here:

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

Fab8888, 2022-08-16:
Thank you so much, I almost done for the translation, but I have a litter bit cannot do that very well, such as setting page the  header  "Matrix" 16 x16,  and the effects page Patterns Option drop down menu,  but it is a minor things.
By the way, really thanks.

vvip-68, 2022-08-16:
@Fab8888 , Matrix 16x16

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

Patterns effect names:

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

vvip-68, 2022-08-16:
@Fab8888 , could you share your work (aia + apk) for other users, when it is completed?

Fab8888, 2022-08-17:
Really thanks, pretty sure, I can share it.
https://tmpfiles.org/dl/12481/gyverpanelwifi.zip

One more question, if I want to send some Chinese words into the text page. Should I change the fonts.h from sketch ?
or the app have any drawing function to immediately to send the MCU Matrix LED? Just like Divoom pixel.

vvip-68, 2022-08-17:
@Fab8888 , - File not found (404)
Yes fonts.h contains bitmap image of each character of used font.
There are 3 set of letters (latin and cyrillic) for char image size 5x7, 8x13 and 10x16 points.
If you want have other-language characters, you need draw it into bitmap arrays and probably change some procedures in runningText.ino sketch like getFont(), drawLetter() and some other...

vvip-68, 2022-08-17:
Here is some information about fonts
https://github.com/vvip-68/GyverPanelWiFi/wiki/Большие-буквы-в-бегущей-строке

Text in russian, but you may use google-translate to translate it into your language.

Fab8888, 2022-08-19:
I upload again, this time in sendspace. If can't download, tell me again.
https://www.sendspace.com/file/qsxmiy

I just find some features do not include in GyverPanelWiFi.
I need the draw function. The GyverMatrixWiFi have it.
https://github.com/vvip-68/GyverMatrixWiFi/tree/master/Android
but there's aia file only supported in thunkable classic version. (Thunkable classic cannot access now)
Do you have any way to let me adjust the aia file? thanks.

vvip-68, 2022-08-30:
@Fab8888 , drawing and game application  for GyverPanelWiFi project is located in the same folder and named GyverPlayerWiFi.aia. Developed in AppInventor. Application was separated into two parts, because of big size of resulted code, that made a) very slow response in editor. b) Inventor compiler sometime returned compilation error 'file size too big'.

Fab8888, 2022-09-01:
Thanks for your reply.
One more question, when I use GyverPanelWiFi and the firmware, it is always dimming to light off, I need to increase the brightness bar. However, it is do the same things again and again.

When I use GyverMatrixWiFi and the firmware, it's no problem. Do you know what is wrong about that?

vvip-68, 2022-09-01:
@Fab8888 , yes it is known effect.
Most possible reasons:
1. Wrong initialization of of button (wrong type of button - initialization for tact button when really used sensor button or vise verse) or sketch tuned for button usage, but really no button contacted.
2. Usage of wrong version of MCU core, instead of recommended. Some versions of core mapped 2/D2 or 4/D4 to same pin out, so button and lead out mapped to same pin and output led signal on out pin reads by sketch as input button 'hold' signal that used by sketch as change brightness. Same effect also may occurs when user manually set output led to the same pin as button input pin.

Fab8888, 2022-09-04:
Thanks, I fixed the pin.
May I save a word to be a starting demo, and loop to play.

ChamakChy, 2023-05-30:
@Fab8888 can you please upload the translated .apk file the link given shows as expired.

vvip-68, 2023-05-31:
I have only this things, this is in free access

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

Closed 2020-09-24.

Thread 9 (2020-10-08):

Не компилируется при активации mp3 и ТМ1627.

Geonm778, 2020-10-08:
Не могу скомпилировать при активации проигрывателя DFPlayer mp3 и TM1627 (версия 1.05). Выдается много ошибок. Например
C:\GyverPanelWiFi_v1.05\GyverPanelWiFi_v1.05.ino: In function 'void setup()':
GyverPanelWiFi_v1.05:90:16: error: 'loadSettings' was not declared in this scope
   loadSettings();
И т.д. Проект больше не предполагает работу с лампой 16х16, mp3 проигрывателем и дисплеем? Просто схема с ними в проекте присутствует. При этом без mp3 и ТМ1627 компиляция проходит нормально.

vvip-68, 2020-10-08:
Там была ошибка - не убрал отладочный код, он не давал скомпилиться при включенном MP3. Исправил.
Еще вылез косяк с отрицательными температурами. Тоже исправил.
Возьмите последний коммит, там всё исправлено - должно собираться

Geonm778, 2020-10-08:
Прошу прощения, но нет. Не компилируется. Устанавливаю вариант часы на столе (2), устанавливаю необходимые параметры матрицы, прописываю
#define USE_SD 0
#define USE_MP3 1     
#define USE_TM1637 1
#define USE_WEATHER 0
#define USE_POWER 0  
#define USE_MQTT 0
#define SRX D4      
#define STX D3       
#define DIO D5        
#define CLK D7       
 и при попытке скомпилировать вылетает ошибка: 'loadSettings' was not declared in this scope

vvip-68, 2020-10-09:
Geonm778, у меня с вашими параметрами собирается без проблем.
" 'loadSettings' was not declared in this scope" - это всего лишь последняя ошибка в списке, причем порожденная другими ошибками. Приведите весь лог со всеми ошибками.
И - параметры с "часы на столе" - это для моей конкретно поделки, с моим набором оборудования, углом подключения и размером матрицы. Вам нужно все параметры все равно под себя настроить / проверить, что это все соответствует вашему изделию. Впрочем, думаю вы все это и так понимаете. Просто, на всякий случай...

Geonm778, 2020-10-09:
Добрый вечер! Компиляция заканчивается ошибкой, если указать что матрица свернута в трубу (а у меня как раз лампа!  Т.е.  файле a_def_hard.h если будет в настройках ЛЮБОГО варианта матрица свернута в трубу:

#define DEVICE_TYPE 0         // Использование матрицы: 0 - свернута в трубу для лампы; 1 - плоская матрица в рамке

то все, ошибка при компиляции!

vvip-68, 2020-10-10:
Geonm778, исправил

Geonm778, 2020-10-10:
Отлично! Спасибо!

Closed 2020-10-08.

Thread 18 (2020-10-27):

120x7 matrix

yusufsulaiman, 2020-10-27:
hi, thanks for sharing
i made matrix 120x7, but runningtext is not showup
what should i do?
thanks

vvip-68, 2020-10-27:
I do not know. Maybe you doing something wrong. I tried run text line on my test matrix with defined size 16x7 - text running well.
Of course tall cyrillec letters like 'Ц' and 'Щ' are truncated, however text is shown.
Does anything suspect in port monitor logs?

yusufsulaiman, 2020-10-27:
It works for 60x7, but it did not work for 120x7. Is it due to eeprom runningtext.thanks
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

vvip-68, 2020-10-27:
What wrong with eeprom running text? As far as I understand eeprom capacity for store text is about 1.5K chars.
And in my understanding do not related with ability to display text on matrix.

yusufsulaiman, 2020-10-27:
this is when i send runningtext
UDP пакeт размером 31 от 192.168.4.2, порт 2390
Содержимое: $6 0|1|ghwjshshsbbd    
Сохранение строк выполнено.
Ипользованы адреса EEPROM 800 - 849
Свободно ячеек 3246
Answer to 192.168.4.2:2390 >> $18 TE:1|TI:20|CT:0|ST:69|C2:255,255,255|OM:1623|TS:520000000000000000000000000000000000|TA:1|TX:[ghwjshshsbbd]|TY:[1:1 > 'ghwjshshsbbd'];

Exception (3):
epc1=0x40208501 epc2=0x00000000 epc3=0x00000000 excvaddr=0x40024b48 depc=0x00000000

>>>stack>>>

ctx: cont
sp: 3ffffd30 end: 3fffffc0 offset: 01a0
3ffffed0:  00000000 00000007 00000078 4020c974
3ffffee0:  00000000 3fff5b2e 0000000c 00000000
3ffffef0:  3fff5eb2 00000001 0000000c 40211339
3fffff00:  014ba1a5 3fffdad0 3fff7400 000c000f
3fffff10:  00000001 00000001 00000000 00000001
3fffff20:  ffffff8f 3fff6870 3fff8d38 401063e3
3fffff30:  3fff5be8 3fff5b2e 3fff8d04 3fff61a4
3fffff40:  00000000 3fff5b2e 3fff3c5c 402148ba
3fffff50:  6c432000 7364756f 80000027 3fff61a4
3fffff60:  3fffdad0 3fff6870 3fff5f5c 4021fa55
3fffff70:  3fffdad0 00000000 3fff5f5c 4021df36
3fffff80:  00000000 00000000 00000001 3fff61a4
3fffff90:  3fffdad0 00000000 3fff6164 40214bcb
3fffffa0:  3fffdad0 00000000 3fff6164 4021c668
3fffffb0:  feefeffe feefeffe 3ffe8590 40101115
<<<stack<<<

 ets Jan  8 2013,rst cause:2, boot mode:(3,7)

load 0x4010f000, len 1392, room 16
tail 0
chksum 0xd0
csum 0xd0
v3d128e5c
~ld

vvip-68, 2020-10-27:
Do you have latest version of firmware? A have more then 10 working devices with this firmware with different sizes of matrix. All of them display text (receive text from application, save it into eeprom) without any fault. This stack information is not informational for me. It may be decoded on your size using Exception decoder (https://github.com/me-no-dev/EspExceptionDecoder) having your build of firmware.
I am not able to debug this on my side, because I am not able to reproduce error.

vvip-68, 2020-10-27:
A see context of logs you provided - it contains words and structure of log phrases that do not present in latest version of firmware. So, I think you use enough outdated version of firmware that may contain errors fixed in later versions. Try to update your firmware to latest version. Send me log text from moment of start microcontrollet and until exceprion output.

yusufsulaiman, 2020-10-27:
ok. thanks

vvip-68, 2020-10-27:
Did you solve isuue finally?

Closed 2020-10-27.

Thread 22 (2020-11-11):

Changing custom list of effects

Engineerator, 2020-11-11:
Hello, thank you for this project!

I would like to change the list of effects that switch by themselves. The comments in custom.ino says to put the code in this structure "case number: effect; break;" Where exactly do I put this code if I wanted to add "case MC_SNOW: snowRoutine(); break;"?

I was able to run the default program normally. When I tried to change the program from `void customRoutine(byte aMode) {
  doEffectWithOverlay(aMode);
}` to `void customRoutine(byte aMode) {
switch (aMode) {
  case MC_SNOW: snowRoutine(); break;
}
}` my matrix became blank.

vvip-68, 2020-11-12:
I do not understand what you to achive with these changes.
1. Call of ```doEffectWithOverlay(aMode);``` do a lot of other preparations before show effects.
2. Your construction ```void customRoutine(byte aMode) { case MC_SNOW: snowRoutine(); break; }``` as you provide it is wrong by syntax and is not compileable.  ```case MC_SNOW: snowRoutine(); break;``` is part of ```switch``` operator, which is analog of ```if()``` cascade and do selection which effect must be processed depend on control variable aMode - all of them placed inside ```processEffect()``` procedure.
3. If you receive compiled scetch without error - I surprised about it. The blank matrix is became your current mode (thisMode) either is not in range ow known modes constants or there is no code which call one of effect processing procedure.

Engineerator, 2020-11-12:
Sorry what I meant was `void customRoutine(byte aMode) { switch (aMode) { case MC_SNOW: snowRoutine(); break; } }`.
I also meant that I ran the default sketch only changing the parameters to fit my matrix and the program worked normally.

I ran the default sketch and only changed the processEffect() procedure to `void processEffect(byte aMode) {
  switch (aMode) {
        case MC_SNOW:                snowRoutine(); break;
  }
}` but my matrix became blank.

vvip-68, 2020-11-12:
Obviously it because aMode was not MC_SNOW at that moment and showRoutine() was not called.
If you need only show MC_SNOW effect and by some reason do not want use sketch normally, set processEffect() procedure as
```
void processEffect(byte aMode) { snowRoutine();  }
```

Engineerator, 2020-11-12:
Thank you, I was able to run this code. I plan to add more effects but when I add another effect `void processEffect(byte aMode) {
  switch (aMode) {
    case MC_SNOW:                snowRoutine(); break;
    case MC_FIRE:                fireRoutine(); break;
  }
}` my matrix becomes blank again.

vvip-68, 2020-11-12:
Put into ```processEffect(byte aMode)``` procedure following line:
```
Serial.println("aMode=" + String(aMode));
```
and see which value has the switch variable aMode inside procedure and which branch of switch operator (or none of them) is executed.

Engineerator, 2020-11-12:
I put this code into processEffect(byte aMode) and the serial monitor printed out random values each minute.
aMode=12
aMode=15
aMode=31

vvip-68, 2020-11-12:
It is because time of show for each effect is one minute by default. Each minute ID of effect changed to next.
12 - MC_NOISE_CLOUD
15 - MC_NOISE_RAINBOW
31 - MC_ANALYZER
None of branch of your reduced switch operator belongs to these codes. You have only branches for MC_SNOW=2 and MC_FIRE=6.
Because you have no procedures drawing images on matrix for codes except MC_SNOW and MC_FIRE - you have blank matrix.
I do not understand why you surprised and what do you want finally.

You have a car. You removed some important gears from engine and transmission and wonder why your car stopped to move.
You removed some important parts of code from sketch and wonder why it stopped to work.
I do not understand why you surprised.

Engineerator, 2020-11-13:
In [GyverMatrixBT ](https://github.com/AlexGyver/GyverMatrixBT/blob/master/firmware/GyverMatrixOS_v1.12/custom.ino#L67) it is possible to change the list of effects the way you wanted. It is also possible in [GyverMatrixWiFi](https://github.com/vvip-68/GyverMatrixWiFi/blob/master/firmware/GyverMatrixOS_v1.15/custom.ino#L127). I'm trying to change the list so that I can add or remove effects that I want and don't want to use so that they switch by themselves without using the app.

vvip-68, 2020-11-13:
List of available effects is defined in a_def_soft.h, lines 36-79. The line 81 contains maximum number of effects.
Lines 19-29 contains list of effects (in defined order corresponded the list of definition in lines 36-79 for transfer into smartphone application. If you need to remove some effects from processing, reoder and renum them in 36-79, correct line 81 with number less then last used effect ID, reorder list of effects in 19-29.

custom.ino line 382 - nextModeHandler() and line 416 - prevModeHandler() sequentially increment/decrement ID for current effect from 0 to MAX_EFFECT or get random number in range 0..MAX_EFFECT depends on random switch on/off.

If you do not use some effect at all, you can remove effect ID definition at all and remove parts of code related with removed ID.
If you need add your own effects - take as a sample one of existing effects, do search among code for MC_XXXX and do almost same as for sampled effect

Engineerator, 2020-11-14:
Perfect! Thank you very much!!! I was able to change the custom list of effects.

When I turn off the [random switch](https://github.com/vvip-68/GyverPanelWiFi/blob/master/firmware/GyverPanelWiFi_v1.06/a_def_soft.h#L560), the program starts with a random effect. From that random effect the program switches to the next effect on the list. Is this possibly a glitch? How could the program be changed so that it starts with the first effect on the list?

vvip-68, 2020-11-14:
Main project file, lines 267-272 retrieve saved mode from EEPROM (if it was set manually) or get random mode on start.
Put following lines instead of:
```
thisMode = 0;
setEffect(thisMode);
```

Engineerator, 2020-11-15:
Thank you! I was able to start the program with the first effect on the list.

Engineerator, 2020-11-16:
I'm trying to use the project to read .out animation files from an SD card. How can I change the program so that it starts with the first file on the SD card and selects the next file on the list?

Currently if the program has more than three effects on the list, it will pick a random file and continue picking random files. I think that [this ](https://github.com/vvip-68/GyverPanelWiFi/blob/master/firmware/GyverPanelWiFi_v1.06/sdcard.ino#L121)line in the sdcard file chooses the next random file on the SD card. However I'm not sure how to change it so that it selects the next file on the list.

vvip-68, 2020-11-16:
If you need sequential files - you need simple increment file_idx until it reach countFiles value. After it reach countFiles value - reset file_idx back to zero. It is obviously, isn`t it?

Engineerator, 2020-11-22:
I'm trying to understand. So far I came up with this:
```
     for(currentFile < 0 || currentFile >= countFiles; currentFile < countFiles; currentFile++){
      file_idx++;
      if(file_idx == countFiles){
        file_idx = 0;
      }
     }
```
I replaced lines 115-125 in the sdcard file with this code. It works, but the first effect is skipped and I don't know why. For example: I have 3 files on an SD card: Effect1.out, Effect2.out and Effect3.out. The program begins with Effect2.out and then plays Effect3.out and then starts from the beginning Effect1.out, Effect2.out, etc. How can I change this code so that it begins with the first effect on the list?

Engineerator, 2020-11-22:
I'm trying to understand. So far I came up with this:
```
     for(currentFile < 0 || currentFile >= countFiles; currentFile < countFiles; currentFile++){
      file_idx++;
      if(file_idx == countFiles){
        file_idx = 0;
      }
     }
```
I replaced lines 115-125 in the sdcard file with this code. It works, but the first effect is skipped and I don't know why. For example: I have 3 files on an SD card: Effect1.out, Effect2.out and Effect3.out. The program begins with Effect2.out and then plays Effect3.out and then starts from the beginning Effect1.out, Effect2.out, etc. How can I change this code so that it begins with the first effect on the list?

Thank you very much for your help!!!

vvip-68, 2020-11-22:
It is very strange construction - use cycle 'for' without index variable. I do not understand logic how it works.
But If you use this construction and you said it works...

Obviously your currentFile and file_idx initially have values equal to zero.
Next, in the very first stage (ever before first usage)  you increment values and they become 1 and next use them in first time.
As solution - try in line 113 use following: currentFile = -1;
and initialize file_idx as:
file_idx = -1;

Engineerator, 2020-11-22:
The problem is solved! Thank you very much!!!

Evgeni198, 2020-12-02:
> Проблема решена! Большое спасибо!!!
Здравствуйте, может Вы мне поможете. Решил убрать ненужные эффекты например "Часы" убрал его из строки 36. Также в строке #define MAX_EFFECT уменьшил на один эффект и компиляция не проходит :

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

Engineerator, 2021-05-19:
Hello @vvip-68 please delete this issue. Thank you.

Engineerator, 2021-05-21:
@vvip-68 Delete this issue. Thank you.

Engineerator, 2021-05-21:
@vvip-68 Please delete this issue. Thank you.

Engineerator, 2021-05-21:
@vvip-68 Delete this issue. Thank you.

Engineerator, 2021-05-21:
@vvip-68 Please delete this issue thank you.

Engineerator, 2021-05-21:
@vvip-68 Please delete this issue thank you.

Engineerator, 2021-05-21:
@vvip-68 Please delete this issue thank you.

Engineerator, 2021-05-21:
@vvip-68 Please delete this issue thank you.

Engineerator, 2021-05-21:
@vvip-68 Please delete this issue thank you.

Engineerator, 2021-05-21:
@vvip-68 Please delete this issue thank you.

Engineerator, 2021-05-21:
@vvip-68 Please delete this issue thank you.

Engineerator, 2021-05-21:
@vvip-68 Please delete this issue thank you.

Engineerator, 2021-05-21:
@vvip-68 Please delete this issue thank you.

Engineerator, 2021-05-21:
@vvip-68 Please delete this issue thank you.

Engineerator, 2021-05-21:
@vvip-68 Please delete this issue thank you.

Engineerator, 2021-05-21:
@vvip-68 Please delete this issue thank you.

Engineerator, 2021-05-21:
@vvip-68 Please delete this issue thank you.

Engineerator, 2021-05-21:
@vvip-68 Please delete this issue thank you.

Engineerator, 2021-05-21:
@vvip-68 Please delete this issue thank you.

Engineerator, 2021-05-21:
@vvip-68 Please delete this issue thank you.

Closed 2020-11-12.

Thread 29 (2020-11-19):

Постоянная перезагрузка

jkreet, 2020-11-19:
Собрал панель на базе ESP-12E.
Включается, работает нормально.
Пока не подключена к wifi, всё ок. Эффекты переключаются, работает демо-режим. Можно подключиться к ней, как к точке доступа и управлять с телефона.
Стоит только подключить к домашнему wifi начинаются проблемы.
При включении показывает случайный эффект и часы с температурой.
Затем часы уезжают влево, и через секунду - reset.

Я подозреваю, что дело именно в уезжающих влево часах.
Потому что другие эффекты, где часы не наложены, после старта работают нормально. Например, жизнь или лабиринт, если они случайно запускаются после включения питания.

В мониторе порта сообщения по кругу:
```
ED-Panel-WiFi v.1.06.2020.1114

Загрузка строк выполнена.
Ипользованы адреса EEPROM 800 - 837
Свободно ячеек 3258

Подключение к Keenetic
...........
WiFi подключен. IP адрес: 192.168.1.102

UDP-сервер на порту 2390
NTP-сервер ru.pool.ntp.org -> 94.103.91.82
Отправка NTP пакета на сервер ru.pool.ntp.org
UDP << ip='94.103.91.82:123'; ntp sync
UDP пакeт размером 48
Разбор пакета NTP
Секунд с 1970: 1605788805
--------------------

Запрос текущей погоды
Погода получена:
Сейчас: пасмурно, +2ºC
Код иконки: 'ovc'

Цвет неба: '#58bbfe'

--------------- CUT HERE FOR EXCEPTION DECODER ---------------

Exception (3):
epc1=0x4020b658 epc2=0x00000000 epc3=0x00000000 excvaddr=0x40020173 depc=0x00000000

>>>stack>>>

ctx: cont
sp: 3ffffd00 end: 3fffffc0 offset: 0190
3ffffe90:  00000009 00000005 00000002 00000006
3ffffea0:  00000002 00000000 00000002 00000006
3ffffeb0:  00000012 0000001c 00000001 00000000
3ffffec0:  ffffff9c 00000019 00000001 00000000
3ffffed0:  3ffe8559 00000009 00000001 40214b97
3ffffee0:  00000000 00000000 4bc6a7f0 00000000
3ffffef0:  00000000 80ff1544 40100568 000039df
3fffff00:  00000000 00000000 3fff0ad4 80fe8574
3fffff10:  00000001 00000001 00000001 00000000
3fffff20:  3fff0a9c 3fff09aa 3fff0948 3ffe8574
3fffff30:  3fff0a9c 3fff09aa 3fff0ad4 40218c76
3fffff40:  3fff3900 001f001f 80ff0978 3fff3600
3fffff50:  001d02bf 800c000f 3fff3900 3fff10c8
3fffff60:  3fffdad0 00000000 3fff1544 40224fe1
3fffff70:  00000000 80efeffe 3fff0e80 40223536
3fffff80:  00000000 00000000 00000001 3fff10c8
3fffff90:  3fffdad0 00000000 3fff1088 40218fe7
3fffffa0:  3fffdad0 00000000 3fff1088 4022186c
3fffffb0:  feefeffe feefeffe 3ffe85d8 40100fed
<<<stack<<<

--------------- CUT HERE FOR EXCEPTION DECODER ---------------

 ets Jan  8 2013,rst cause:2, boot mode:(3,6)

load 0x4010f000, len 3584, room 16
tail 0
chksum 0xb0
csum 0xb0
v2843a5ac
~ld
```

kostyamat, 2020-11-19:
Судя по этому
 ets Jan  8 2013,rst cause:2, boot mode:(3,6)
сработал аппаратный вачдог. Где-то программа зациклилась.

vvip-68, 2020-11-19:
Не, когда Watchdog - оно так и пишет, что SoftReset или Watchdog reset. Тут что-то другое.
Может и в часах дело. Какой размер матрицы? На последней версии прошивки из репозитория - тоже ошибка есть? Может уже исправлено?

jkreet, 2020-11-19:
Матрица 16x16
Пробовал только последнюю версию прошивки.
По поводу ESP Exception Decoder - не силён в этом. Но если подскажете, готов попробовать.

vvip-68, 2020-11-19:
https://github.com/me-no-dev/EspExceptionDecoder
Ставишь как написано.
В меню IDE "Инструменты"  должно появиться "ESP Exception decoder"
Выбираешь этот пункт. Появляется окно, в которое копируешь вот тот стек с ошибками.
Оно показывает стек вызовов, по которому можно примерно понять что происходит.
Лучше то что получил кинуть мне в личку в https://vk.com/iivanovii - похоже разговор будет долгий.
Ни у кого ошибки не возникает, у тебя возникает. Это странно.
Давай туда же свой блок настроек - какие фичи включены / выключены, настройки размеров матрицы, угла подключения и все прочее связанное

jkreet, 2020-11-19:
У меня нет вк.
`0x40216e67: doEffectWithOverlay(unsigned char) at Z:\arduino\GyverPanelWiFi-master\firmware\GyverPanelWiFi_v1.06/custom.ino line 284
0x40100500: millis() at C:\Users\Pasha\AppData\Local\Arduino15\packages\esp8266\hardware\esp8266\2.7.4\cores\esp8266\core_esp8266_wiring.cpp line 167
0x4021a98a: process() at Z:\arduino\GyverPanelWiFi-master\firmware\GyverPanelWiFi_v1.06/a_main.ino line 195
0x40100568: millis() at C:\Users\Pasha\AppData\Local\Arduino15\packages\esp8266\hardware\esp8266\2.7.4\cores\esp8266\core_esp8266_wiring.cpp line 188
0x40106553: esp8266::polledTimeout::timeoutTemplate   >::expiredOneShot() const at C:\Users\Pasha\AppData\Local\Arduino15\packages\esp8266\hardware\esp8266\2.7.4\cores\esp8266/PolledTimeout.h line 218
0x40226d8c: esp8266::MDNSImplementation::MDNSResponder::_updateProbeStatus() at C:\Users\Pasha\AppData\Local\Arduino15\packages\esp8266\hardware\esp8266\2.7.4\libraries\ESP8266mDNS\src\LEAmDNS_Control.cpp line 1321
0x4022b140: PubSubClient::connected() (C:\Program Files at x86)\Arduino\libraries\PubSubClient\src\PubSubClient.cpp line 689
0x40205bc3: checkMqttConnection() at Z:\arduino\GyverPanelWiFi-master\firmware\GyverPanelWiFi_v1.06/mqtt.ino line 44
0x40227845: esp8266::MDNSImplementation::MDNSResponder::_process(bool) at C:\Users\Pasha\AppData\Local\Arduino15\packages\esp8266\hardware\esp8266\2.7.4\libraries\ESP8266mDNS\src\LEAmDNS_Control.cpp line 90
0x40225d9a: esp8266::MDNSImplementation::MDNSResponder::update() at C:\Users\Pasha\AppData\Local\Arduino15\packages\esp8266\hardware\esp8266\2.7.4\libraries\ESP8266mDNS\src\LEAmDNS.cpp line 1337
0x4021ad27: loop() at Z:\arduino\GyverPanelWiFi-master\firmware\GyverPanelWiFi_v1.06/GyverPanelWiFi_v1.06.ino line 297
0x402240d0: loop_wrapper() at C:\Users\Pasha\AppData\Local\Arduino15\packages\esp8266\hardware\esp8266\2.7.4\cores\esp8266\core_esp8266_main.cpp line 197`

vvip-68, 2020-11-19:
Ничего не понятно... Ну возможно да - по WatchDog падает - где-то что-то зацикливается
У тебя MQTT включен - он реально настроен и ты его используешь?
Взятый с репозитория проект - компилится, не вылетает?
Если проект без изменений не вылетает, а после твоих изменений проблемы - смотри где что правил, откатывай назад, вноси правки по одной и смотри на каком моменте валиться начинает...

jkreet, 2020-11-19:
Правок не вносил.
Только переменные под свои желания поправил.
mqtt пробовал отключать - без него то же самое.

jkreet, 2020-11-19:
Ради интереса собрал, отключив погоду:
#define USE_WEATHER 0

И всё заработало.

vvip-68, 2020-11-19:
Какой город погоды? Погода - яндекс или OpenWeatherMap?

jkreet, 2020-11-19:
Москва, Яндекс.

jkreet, 2020-11-19:
Но, похоже, дело вообще не в погоде.
Я сейчас экспериментировал - переключил часы в вертикальное отображение - всё заработало как надо.
Погоду тоже подключил - и она работает.

Включил часы поверх эффектов и горизонтально - снова словил перезагрузку. Но теперь не циклическую, т.к. в eeprom не сохранилась настройка с горизонтальными часами.

И сейчас могу, переключив часы в горизонт, снова вызвать ребут.

vvip-68, 2020-11-19:
Интересно почему у меня такого не происходит?
Видимо, тебе придется это отлаживать самостоятельно...
Потом расскажешь мне в чем было дело.

Дай свои настройки все что ты исправлял в исходном проекте.

fastdron, 2020-11-21:
Вот буквально сегодня обновил прошивку до последней актуальной - тоже все супер,не вылетает. Хотел попросить автора добавить в шрифты символ ° . Для отображения температуры очень не хватает в бегущей строке, особенно когда ноль градусов на улице - всегда дописываю после значения температуры 'С.

vvip-68, 2020-11-21:
@fastdron,  забирай обновления

Closed 2020-11-20.

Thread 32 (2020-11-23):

Не проходит компиляция на версии 1.07

tih66, 2020-11-23:
На последней версии не проходит проверку и соответственно не компилируется проект:

In file included from C:\Users\������������\AppData\Local\Arduino15\packages\esp8266\hardware\esp8266\2.5.2\libraries\ESP8266WiFi\src/ESP8266WiFi.h:31:0,
                 from sketch\a_def_hard.h:314,
                 from D:\GyverPanelWiFi-master\GyverPanelWiFi-master\firmware\GyverPanelWiFi_v1.07\GyverPanelWiFi_v1.07.ino:60:
C:\Users\������������\AppData\Local\Arduino15\packages\esp8266\hardware\esp8266\2.5.2\cores\esp8266/IPAddress.h:77:19: error: invalid use of incomplete type 'class IPAddress'
         IPAddress();
                   ^
C:\Users\������������\AppData\Local\Arduino15\packages\esp8266\hardware\esp8266\2.5.2\cores\esp8266/IPAddress.h:57:7: error: forward declaration of 'class IPAddress'
 class IPAddress: public Printable {
       ^
C:\Users\������������\AppData\Local\Arduino15\packages\esp8266\hardware\esp8266\2.5.2\cores\esp8266/IPAddress.h:77:19: error: ISO C++ forbids declaration of 'type name' with no type [-fpermissive]
         IPAddress();
                   ^
In file included from c:\users\������������\appdata\local\arduino15\packages\esp8266\tools\xtensa-lx106-elf-gcc\2.5.0-3-20ed2b9\xtensa-lx106-elf\include\c++\4.8.2\memory:67:0,
                 from C:\Users\������������\AppData\Local\Arduino15\packages\esp8266\hardware\esp8266\2.5.2\libraries\ESP8266WiFi\src/ESP8266WiFiGeneric.h:28,
                 from C:\Users\������������\AppData\Local\Arduino15\packages\esp8266\hardware\esp8266\2.5.2\libraries\ESP8266WiFi\src/ESP8266WiFiSTA.h:28,
                 from C:\Users\������������\AppData\Local\Arduino15\packages\esp8266\hardware\esp8266\2.5.2\libraries\ESP8266WiFi\src/ESP8266WiFi.h:34,
                 from sketch\a_def_hard.h:314,
                 from D:\GyverPanelWiFi-master\GyverPanelWiFi-master\firmware\GyverPanelWiFi_v1.07\GyverPanelWiFi_v1.07.ino:60:
c:\users\������������\appdata\local\arduino15\packages\esp8266\tools\xtensa-lx106-elf-gcc\2.5.0-3-20ed2b9\xtensa-lx106-elf\include\c++\4.8.2\bits\stl_raw_storage_iter.h:75:7: error: expected primary-expression before 'explicit'
       explicit
       ^
c:\users\������������\appdata\local\arduino15\packages\esp8266\tools\xtensa-lx106-elf-gcc\2.5.0-3-20ed2b9\xtensa-lx106-elf\include\c++\4.8.2\bits\stl_raw_storage_iter.h:74:11: error: expected ';' at end of member declaration
     public:
           ^
In file included from c:\users\������������\appdata\local\arduino15\packages\esp8266\tools\xtensa-lx106-elf-gcc\2.5.0-3-20ed2b9\xtensa-lx106-elf\include\c++\4.8.2\memory:74:0,
                 from C:\Users\������������\AppData\Local\Arduino15\packages\esp8266\hardware\esp8266\2.5.2\libraries\ESP8266WiFi\src/ESP8266WiFiGeneric.h:28,
                 from C:\Users\������������\AppData\Local\Arduino15\packages\esp8266\hardware\esp8266\2.5.2\libraries\ESP8266WiFi\src/ESP8266WiFiSTA.h:28,
                 from C:\Users\������������\AppData\Local\Arduino15\packages\esp8266\hardware\esp8266\2.5.2\libraries\ESP8266WiFi\src/ESP8266WiFi.h:34,
                 from sketch\a_def_hard.h:314,
                 from D:\GyverPanelWiFi-master\GyverPanelWiFi-master\firmware\GyverPanelWiFi_v1.07\GyverPanelWiFi_v1.07.ino:60:
c:\users\������������\appdata\local\arduino15\packages\esp8266\tools\xtensa-lx106-elf-gcc\2.5.0-3-20ed2b9\xtensa-lx106-elf\include\c++\4.8.2\ext\concurrence.h:70:5: error: expected primary-expression before 'virtual'
     virtual char const*
     ^
c:\users\������������\appdata\local\arduino15\packages\esp8266\tools\xtensa-lx106-elf-gcc\2.5.0-3-20ed2b9\xtensa-lx106-elf\include\c++\4.8.2\ext\concurrence.h:69:9: error: expected ';' at end of member declaration
   public:
         ^
c:\users\������������\appdata\local\arduino15\packages\esp8266\tools\xtensa-lx106-elf-gcc\2.5.0-3-20ed2b9\xtensa-lx106-elf\include\c++\4.8.2\ext\concurrence.h:78:5: error: expected primary-expression before 'virtual'
     virtual char const*
     ^
c:\users\������������\appdata\local\arduino15\packages\esp8266\tools\xtensa-lx106-elf-gcc\2.5.0-3-20ed2b9\xtensa-lx106-elf\include\c++\4.8.2\ext\concurrence.h:77:9: error: expected ';' at end of member declaration
   public:
         ^
c:\users\������������\appdata\local\arduino15\packages\esp8266\tools\xtensa-lx106-elf-gcc\2.5.0-3-20ed2b9\xtensa-lx106-elf\include\c++\4.8.2\ext\concurrence.h:86:5: error: expected primary-expression before 'virtual'
     virtual char const*
     ^
c:\users\������������\appdata\local\arduino15\packages\esp8266\tools\xtensa-lx106-elf-gcc\2.5.0-3-20ed2b9\xtensa-lx106-elf\include\c++\4.8.2\ext\concurrence.h:85:9: error: expected ';' at end of member declaration
   public:
         ^
c:\users\������������\appdata\local\arduino15\packages\esp8266\tools\xtensa-lx106-elf-gcc\2.5.0-3-20ed2b9\xtensa-lx106-elf\include\c++\4.8.2\ext\concurrence.h:94:5: error: expected primary-expression before 'virtual'
     virtual char const*
     ^
c:\users\������������\appdata\local\arduino15\packages\esp8266\tools\xtensa-lx106-elf-gcc\2.5.0-3-20ed2b9\xtensa-lx106-elf\include\c++\4.8.2\ext\concurrence.h:93:9: error: expected ';' at end of member declaration
   public:
         ^
c:\users\������������\appdata\local\arduino15\packages\esp8266\tools\xtensa-lx106-elf-gcc\2.5.0-3-20ed2b9\xtensa-lx106-elf\include\c++\4.8.2\ext\concurrence.h:131:13: error: invalid use of incomplete type 'class __gnu_cxx::__mutex'
     __mutex()
             ^
c:\users\������������\appdata\local\arduino15\packages\esp8266\tools\xtensa-lx106-elf-gcc\2.5.0-3-20ed2b9\xtensa-lx106-elf\include\c++\4.8.2\ext\concurrence.h:118:9: error: forward declaration of 'class __gnu_cxx::__mutex'
   class __mutex
         ^
c:\users\������������\appdata\local\arduino15\packages\esp8266\tools\xtensa-lx106-elf-gcc\2.5.0-3-20ed2b9\xtensa-lx106-elf\include\c++\4.8.2\ext\concurrence.h:131:13: error: expected ';' at end of member declaration
     __mutex()
             ^
c:\users\������������\appdata\local\arduino15\packages\esp8266\tools\xtensa-lx106-elf-gcc\2.5.0-3-20ed2b9\xtensa-lx106-elf\include\c++\4.8.2\ext\concurrence.h:132:5: error: expected unqualified-id before '{' token
     {

и т.д.
Не подскажите в чем загвоздка?

vvip-68, 2020-11-23:
Возможно - в устаревшей версии ядра ESP8266. У вас стоит 2.5.2
Обновитесь до последней - на текущий момент 2.7.4
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
tih66, 2020-11-23:
Тоже самое. Уже полностью удалил все что связано с ардуино и установил все с нуля, последняя версия вываливается в ошибку.

vvip-68, 2020-11-23:
Еще вариант - у вас в путях - кириллица. То что черными квадратиками в сообщении выше. Раньше Ардуино IDE точно не любил кириллицу в путях. Какой, кстати, версии у вас Arduino IDE? Если не последней - обновите...
Создайте пользователя в винде не содержащего кириллицу в имени, войдите под ним. Установите Arduino IDE, ядро и библиотеки. Откройте проект из под этого пользователя.
Я не вижу причины почему эта версия может вести себя вот так. Предыдущая версия - собирается?
Ничего серьезного касательно IPAddress на которую ругается - не поменялось. Все то же самое.
В 1.07 только добавилась игра Андроид, включено интерактивное управление играми и добавлена возможность рисования на матрице из программы на смартфоне. Весь остальной код остался тем же самым. Я не вижу причин почему старая версия собиралась, а новая нет.
Единственное изменение 1.07 от 1.06 касаемое IPAddress - в файле clock.ino, строки 88-89 -
  ip1.fromString(F("0.0.0.0"));
  ip2.fromString(F("255.255.255.255"));
Закомментируйте этот блок, и связанное с ним, попробуйте собрать.
Посмотрите как это было в версии 1.06

vvip-68, 2020-11-23:
Вот эти строки
C:\Users\������������\AppData\Local\Arduino15\packages\esp8266\hardware\esp8266\2.7.4\cores\esp8266/IPAddress.h:78:19: error: ISO C++ forbids declaration of 'type name' with no type [-fpermissive]
IPAddress();
навевают на мысль, что у вас в компиляторе включены какие-то строгие проверки...
Попробуйте в настройках среды выставить вот так:
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

tih66, 2020-11-23:
К сожалению смена пользователя на "без кирилицы" не помогла, та же самая ошибка. Настройки у меня выставлены как у Вас. Попробовал в итоге вообще заменить файл clock.ino на файл из 1.06 прошивки. не помогло.

vvip-68, 2020-11-23:
Так а 1.06 - собирается?

vvip-68, 2020-11-23:
Еще отличие 1.06 от 1.07 - в 1.07 были обновлены библиотеки ArduinoJson и ESPSoftwareSerial.
Но они вообще никаким боком к IPAddress не относятся...

tih66, 2020-11-23:
1.06 собирается

vvip-68, 2020-11-23:
Пришлите совсем полный лог ошибок  от нажатия кнопки до результата ошибок.
На vvip-cобака-маил-точка-ру

tih66, 2020-11-23:
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

tih66, 2020-11-23:
это версия 1.06

vvip-68, 2020-11-23:
Ну, что-то у меня нет вариантов. Я не понимаю почему ошибки и на что ругается.
У меня версия 1.07 собирается без ошибок и прямо сейчас работает на 5 устройствах...

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

vvip-68, 2020-11-23:
Вообще а другом есть возможность попробовать собрать?
И - у меня Windows 10...
Хотя 1.06 же у вас и на 7-ке тоже собирается. Не знаю...

vvip-68, 2020-11-23:
Пришлите мне на почту архив полная папка вашего проекта, вот прям как он у вас есть...

tih66, 2020-11-23:
отправил

tih66, 2020-11-23:
создал пустой файл a_def_pass.h и закоментировал //#define public и проект собрался!

tih66, 2020-11-23:
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

vvip-68, 2020-11-23:
Да... Такой вариант я не проверял - у меня всегда этот файл есть...
Попробую понять что происходит...

vvip-68, 2020-11-23:
Хм... Видимо public - что-то где-то зарезервированное "#define public" раньше был в другом месте скетча и, видимо, не влиял на компиляцию. В 1.07 он переехал в начало скетча и все сломал...
Переопределил
#define public_project
#ifndef public_project
и всё стало собираться.

vvip-68, 2020-11-23:
У вас в проекте в a_def_hard.h
#define DEVICE_ID   4         // 0 - тестовый стенд
Вот лучше использовать другую ID
У меня под этим номером - довольно проблемная гирлянда - во первых она большая 50x20 - как следствие - не хватает памяти на всё и скетч "валится". Во вторых - диоды проблемные - срывается синхронизация.
Чтобы не валился и попытки исправить - для этого DEVICE_ID, например, отключены игры. Возможно что-то где-то еще...
Совершенно точно - при сборке с этим ID вместо игр будет или черный экран или замерший предыдущий эффект...

KAKTO, 2020-12-21:
Я мало понимаю в этом, но начиная с  версии 1.07 был изменён код в EspSoftwareSerial. Конкретно в файле \libraries\EspSoftwareSerial\src\SoftwareSerial.h изменены строки 130-137, в строке 132 открыта фигурная скобка.
Заменил этот файл (из версии 1.06), теперь компиляция проходит на ура и в "точке доступа" вроде всё работает.

130     int available() override;
131 #if defined(ESP8266)
132     int availableForWrite() override {
133 #else
134     int availableForWrite() {
135 #endif
136         if (!m_txValid) return 0;
137         return 1;

KAKTO, 2020-12-21:
Да, и никаких манипуляций с файлом a_def_pass.h не проводил (не создавал, отключен и MQTT отключен.

Closed 2020-11-23.

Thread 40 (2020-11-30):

text and mqtt

matteos1, 2020-11-30:
the characters displayed appear to go from right to left and back. what needs to be corrected?
Mqtt fails to make it work

vvip-68, 2020-12-01:
If you want characters move right to left and back (bidirectional move) - in need write appropriate code in sketch. Current code allows move text unidirectional rigt to left. If you want move characters mirrored - left from right unidirectional and mirrored -- you need change matrix connection angle (CONNECTION_ANGLE) and direction from angle STRIP_DIRECTION

MQTT need appropriate setting to be working. Did you set appropriate server and  name and user password, server port and so on? Which server do you use? Are you able read article in project wiki related to mqtt settings (article in russian)?

matteos1, 2020-12-01:
Mosquito

vvip-68, 2020-12-01:
So, you need change settings in script regarding connection to your MQTT server.

matteos1, 2020-12-01:
I have tried several times. I wanted to make it communicate with home assistant but I can't.
i changed the parameters but nan goes.

vvip-68, 2020-12-01:
I know nothing about mosquito and its settings.
I know only thd sketch has server name defined in DEFAULT_MQTT_SERVER (line 293 of a_def_soft.h), server user in DEFAULT_MQTT_USER line 297, password in DEFAULT_MQTT_PASS line 301 and server port in DEFAULT_MQTT_PORT
All these settings are used on first time sketch start when params were not save into EEPROM). Next start these params rerieved from saved EEPROM and use to establish connection to MQTT server. You may change EEPROM_OK constant to another value after you changed one of definition described above. Or upload sketch with params "erase flash: all). After that saved ino EEPROM mqtt settings will be overwrite with defined default values. Also you may set MQTT connection parameters from amartphone application, page 'Connections'
Flag MQTT_USE_PREFIX lead to how topic request is constructed.
When MQTT_USE_PREFIX==1 topic is user_name/device_id/cmd
When MQTT_USE_PREFIX==0 topic is device_id/cmd
Here user_name is name of user defined in DEFAULT_MQTT_USER
device id is - DEVICE_ID value
For my settings to first case topic is 'user_af7cd12a/WiFiPanel-0/cmd', in second case - 'WiFiPanel-0/cmd'
Free MQTT servers usually have limitation - how often it can process request from one device, usually 1 request per second. More often request are skipped. Delay before send next request is defined in MQTT_SEND_DELAY
Check if your settings match to description

matteos1, 2020-12-01:
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

ok i try

Closed 2020-12-02.

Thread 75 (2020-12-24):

Проблема с прошивкой.

araneon, 2020-12-24:
Добрый день.
Уважаемый @vvip-68, не подскажите в чём моя ошибка (сразу скажу, что опыта с Arduino в принципе нет).
Пытаюсь загрузить в ESP-WROOM-32 ваш проект, изменил в **a_def_hard.h** параметры для своего случая на такие:

// Профиль устройства, под которое выполняется компиляция и сборка проекта
#define DEVICE_ID   **7**

// ================== Для ESP32 ====================

#if (DEVICE_ID == 7)   **// добавил сам, поправьте если не правильно сделал.**
/*
 * NodeMCU ESP32
 * Физическое подключение:
 * Матрица зигзаг, левый нижний угол, направление в право
 * Пин ленты    - 13
 * Пин кнопки   - 15
 * MP3Player    - 17 к RX, 16 к TX плеера
 * TM1637       - 33 к DIO, 32 к CLK
 * SD-карта     - 5 - CS, 18 (CLK), 19 (MISO), 23 (MOSI)  - у SD-card wemos d1 shield - D8 (CS), D5 (CLK), D6 (MISO), D7 (MOSI)
 * В менеджере плат выбрано "ESP32 Dev Module"
 */
#if defined(ESP32)
#define WIDTH 18              // ширина матрицы
#define HEIGHT 13             // высота матрицы
#define DEVICE_TYPE 1         // Использование матрицы: 0 - свернута в трубу для лампы; 1 - плоская матрица в рамке
#define MATRIX_TYPE 0         // тип матрицы: 0 - зигзаг, 1 - параллельная
#define CONNECTION_ANGLE 0    // угол подключения: 0 - левый нижний, 1 - левый верхний, 2 - правый верхний, 3 - правый нижний
#define STRIP_DIRECTION 1     // направление ленты из угла: 0 - вправо, 1 - вверх, 2 - влево, 3 - вниз
#define USE_SD 0              // поставьте 0, если у вас нет SD-card модуля
#define USE_MP3 0             // поставьте 0, если у вас нет звуковой карты MP3 плеера
#define USE_TM1637 0          // поставьте 1, если используется дополнительный индикатор TM1637, 0 если индикатора нет
#define USE_POWER 0           // 1 - использовать отключение питания матрицы через MOSFET; 0 - не использовать
#define USE_MQTT 1            // 1 - использовать управление по MQTT-каналу; 0 - не использовать
#define USE_WEATHER 0         // 1 - использовать получение информации о текущей погоде; 0 - не использовать

#define A_DEF_PASS 0          // 1 - Настройки MQTT и API KEY OpenWeatherMap в отдельном файле a_def_pass.h
                              // 0 - Настройки MQTT и API KEY OpenWeatherMap в скетче в a_def_soft.h в строках:
                              // Смотри комментарий к блоку DEVICE_ID == 0

// Схема подключения для ESP32 - в папке Schemes, файл 'ESP32+ALL.JPG'

#define LED_PIN (13U) // (13U)м // пин ленты, физически подключена к пину D13 на плате
#define PIN_BTN (15U)         // кнопка подключена сюда (PIN --- КНОПКА --- GND)
#define POWER_PIN (26U)       // G26 управляющий пин вкл/выкл матрицы через MOSFET или реле
#define SD_CS_PIN (5U)        // G5 пин выбора (ChipSelect) SD карты. Также SD карта использует G18 (CLK), G19 (MISO), G23 (MOSI) // на SD-shild: D8 (CS), D5 (CLK), D6 (MISO), D7 (MOSI)

#define SRX (16U)             // G16 RX пин ESP32, подключен в TX пин (3) модуля DFPlayer
#define STX (17U)             // G17 TX пин ESP32, подключен в RX пин (2) модуля DFPlayer
#define DIO (33U)             // TM1637 display DIO pin
#define CLK (32U)             // TM1637 display CLK pin

#endif
#endif     // добавил сам

// =======================================================

У меня пока кроме самой платы ESP-WROOM-32, блока питания и ленты WS2812, больше ничего нет, по этому в настройках выше вроде всё лишнее (что смог понять :)) отключил.
При попытке загрузить проект в плату, получаю ошибку **'WIDTH' was not declared in this scope** и открывается страница g_life, где подсвечивается 1-ая строка (#define  BYTE_WIDTH  (WIDTH / 8)             // Массив должен быть кратен 8 битам (сколько байт по ширине))
Не подскажите что нужно ещё поправить?

Весь лог из Arduino IDE выложил на [Google Диск](https://drive.google.com/file/d/1UlQx-7fva4hRzptuRxy_ceTw2WepmVU8), так как сюда не помещается.

vvip-68, 2020-12-24:
Для ESP32 там отдельный блок. В нем свои параметры поправь. И не надо для него никаких #If (DEVICE_ID) писать
Ты или написал и сам DEVICE_ID 7 d в але не поставил или... Или лишний #endif в конце поставил.
В общем структура кода у тебя нарушена после твоих правок

araneon, 2020-12-24:
Спасибо большое, поправил, теперь скетч грузится, но есть какие то другие ошибки.

In file included from sketch\a_def_hard.h:423:0,
                 from C:\Christmas_WINDOW\GyverPanelWiFi-master\firmware\GyverPanelWiFi_v1.08\GyverPanelWiFi_v1.08.ino:20:
C:\Soft\Arduino\libraries\FastLED/FastLED.h:14:21: note: #pragma message: FastLED version 3.003.003
 #    pragma message "FastLED version 3.003.003"
                     ^
In file included from C:\Soft\Arduino\libraries\FastLED/FastLED.h:65:0,
                 from sketch\a_def_hard.h:423,
                 from C:\Christmas_WINDOW\GyverPanelWiFi-master\firmware\GyverPanelWiFi_v1.08\GyverPanelWiFi_v1.08.ino:20:
C:\Soft\Arduino\libraries\FastLED/fastspi.h:130:23: note: #pragma message: No hardware SPI pins defined.  All SPI access will default to bitbanged output
 #      pragma message "No hardware SPI pins defined.  All SPI access will default to bitbanged output"
                       ^
И в итоге работает только первые 6 полос по 13 диодов, а остальные 12 полос молчат.
Пробовал менять угол подключения, не помогло. (подключил, как "правый нижний"), если я смотрю на диоды, то точка подключения получается с права внизу и дальше змейкой (в верх - в низ) уходит справа налево.

vvip-68, 2020-12-25:
1. Это не ошибки, это информационные сообщения.
2. Ищи там где горит последний / не горит первый непропай, соплю или один из этих  диодов сгоревший.
При условии что размеры матрицы указаны правильно.

sanyafifa, 2020-12-25:
> P.S. Походу косяк с подключением на ленте, завтра буду перепаивать.

Прозвоните диоды последний который работает и тот который не работает. "Короткого" между любыми контактами быть не должно.

araneon, 2020-12-25:
Лента в порядке, подключил контроллер T-1000S, все диоды горят, режимы меняются, а вот с ESP не хочет, как в прочем и с китайской Arduino NANO, на которой ранее эта лента полноценно работала.

vvip-68, 2020-12-25:
Вывод - лента впорядке, не работает микроконтроллер ESP или неправильно собрана схема.
Для Arduino Nano этот проект вообще не предназначен.
Проверяйте правильность сборки схемы.

Closed 2020-12-25.

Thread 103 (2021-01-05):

Не компилится 1.08 версия

mcvall, 2021-01-05:
C:\GyverPanelWiFi-master\GyverPanelWiFi-master\firmware\GyverPanelWiFi_v1.08\custom.ino: In function 'void checkIdleState()':
custom:639:36: error: 'wait_play_file_finished' was not declared in this scope
          _**(thisMode == MC_SDCARD && wait_play_file_finished && !play_file_finished))**_
                                    ^
custom:639:64: error: 'play_file_finished' was not declared in this scope
          (thisMode == MC_SDCARD && wait_play_file_finished && !play_file_finished))
                                                                ^
exit status 1
'wait_play_file_finished' was not declared in this scope

vvip-68, 2021-01-05:
Исправил.

Closed 2021-01-05.

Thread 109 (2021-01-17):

Ошибка при компиляции

vaicekas, 2021-01-17:
Здраствуйте, пытаюсь обновить прошивку, но получяю ошибку:

a_main:3903:82: error: 'IntToHex' was not declared in this scope
         imageLine += IntToHex(gammaCorrectionBack(getPixColorXY(sendImageCol, i))) + " ";
                                                                                  ^
C:\Users\Zydrius\Documents\Downloads\Compressed\GyverPanelWiFi-master20210117\GyverPanelWiFi-master\firmware\GyverPanelWiFi_v1.09\runningText.ino: In function 'void rescanTextEvents()':
runningText:1789:76: error: 'LEAP_YEAR' was not declared in this scope
           if (daysInMonth == 28) daysInMonth += byte(LEAP_YEAR(iYear - 1970));
                                                                            ^
exit status 1
'IntToHex' was not declared in this scope

Arduino IDE последней версии, все библиотеки из архива.
В чём моя ошибка?

Спасибо.

vvip-68, 2021-01-17:
В том, что смотрите на последнее сообщение в стеке ошибок, которая является как правило вторичной (порожденной) ошибкой. Первопричина - в списке ошибок выданных компилятором где-то выше. Скорее всего не поставили точку с запятой, скобку не закрыли или что-то еще. Устраните первопричину - эти ошибки уйдут автоматически

vaicekas, 2021-01-17:
В скече поменял только свои параметры матрицы, к разделительным знакам не притрагивался.
Попробую скомпилировать ничего не меняя, с Вашыми настройками, посмотрью результат.

vaicekas, 2021-01-17:
Нашёл свой косяк ;)
Я заменял utility.ino с предыдущей версии, првленный на литовский язык названия даты и времени.
А теперь сравнил с новым utility.ino, а здесь есть изменения.
Спасибо! ;)

Dmitro4ekalov, 2021-01-22:
Здравствуйте! такая ошибка при компиляции:
C:\Users\Максим\Documents\Arduino\GyverPanelWiFi_v1.09\clock.ino: In function 'void checkAutoMode5Time()':
clock:1187:80: error: 'useweather' was not declared in this scope
C:\Users\Максим\Documents\Arduino\GyverPanelWiFi_v1.09\clock.ino: In function 'void checkAutoMode6Time()':
clock:1207:80: error: 'useweather' was not declared in this scope
exit status 1
'useweather' was not declared in this scope
в чем причина?

Closed 2021-01-17.

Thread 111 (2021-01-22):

Ошибка при компиляции

Dmitro4ekalov, 2021-01-22:
Здравствуйте! такая ошибка при компиляции:
C:\Users\Максим\Documents\Arduino\GyverPanelWiFi_v1.09\clock.ino: In function 'void checkAutoMode5Time()':
clock:1187:80: error: 'useweather' was not declared in this scope
C:\Users\Максим\Documents\Arduino\GyverPanelWiFi_v1.09\clock.ino: In function 'void checkAutoMode6Time()':
clock:1207:80: error: 'useweather' was not declared in this scope
exit status 1
'useweather' was not declared in this scope
Помогите, в чем причина?

vvip-68, 2021-01-22:
Затрудняюсь сказать. Вы что-то исправляли?
В моем экземпляре скетча в 'mn[ строках - переменная useWeather.
А переменная useweather - действительно неизвестна...

Dmitro4ekalov, 2021-01-22:
да, useWeather на useweather я сам исправлял, думал может ошибка в большой букве W.
а вот с оригиналом так же
C:\Users\Максим\Documents\Arduino\GyverPanelWiFi_v1.09\clock.ino: In function 'void checkAutoMode5Time()':
clock:1187:80: error: 'useWeather' was not declared in this scope
C:\Users\Максим\Documents\Arduino\GyverPanelWiFi_v1.09\clock.ino: In function 'void checkAutoMode6Time()':
clock:1207:80: error: 'useWeather' was not declared in this scope
exit status 1
'useWeather' was not declared in this scope

vvip-68, 2021-01-22:
А... У вас наверное в настройках стоит `#define USE_WEATHER 0`
Мой косяк. Сейчас исправлю...

vvip-68, 2021-01-22:
Исправил, забирайте
clock.ino

Closed 2021-01-22.

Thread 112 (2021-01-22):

ошибки при компиляции ESP32

Dmitro4ekalov, 2021-01-22:
In file included from sketch\a_def_hard.h:432:0,
                 from C:\Users\Максим\Documents\Arduino\GyverPanelWiFi_v1.09\GyverPanelWiFi_v1.09.ino:19:
C:\Users\������\AppData\Local\Arduino15\packages\esp32\hardware\esp32\1.0.4\libraries\ArduinoOTA\src/ArduinoOTA.h:84:5: error: 'WiFiUDP' does not name a type
     WiFiUDP _udp_ota;
     ^
                       ^
C:\Users\Максим\Documents\Arduino\GyverPanelWiFi_v1.09\GyverPanelWiFi_v1.09.ino: In function 'void startWiFi(long unsigned int)':
GyverPanelWiFi_v1.09:325:23: error: no matching function for call to 'WiFiClass::disconnect(bool)'
In file included from C:\Users\������\AppData\Local\Arduino15\packages\esp32\hardware\esp32\1.0.4\libraries\ArduinoOTA\src/ArduinoOTA.h:4:0,
                 from sketch\a_def_hard.h:432,
                 from C:\Users\Максим\Documents\Arduino\GyverPanelWiFi_v1.09\GyverPanelWiFi_v1.09.ino:19:
C:\Program Files (x86)\Arduino\libraries\WiFi\src/WiFi.h:130:9: note: candidate: int WiFiClass::disconnect()
     int disconnect(void);
         ^
C:\Program Files (x86)\Arduino\libraries\WiFi\src/WiFi.h:130:9: note:   candidate expects 0 arguments, 1 provided
GyverPanelWiFi_v1.09:329:8: error: 'class WiFiClass' has no member named 'mode'
GyverPanelWiFi_v1.09:329:13: error: 'WIFI_STA' was not declared in this scope
GyverPanelWiFi_v1.09:341:40: error: no matching function for call to 'WiFiClass::config(IPAddress, IPAddress, IPAddress, IPAddress, IPAddress)'
In file included from C:\Users\������\AppData\Local\Arduino15\packages\esp32\hardware\esp32\1.0.4\libraries\ArduinoOTA\src/ArduinoOTA.h:4:0,
                 from sketch\a_def_hard.h:432,
                 from C:\Users\Максим\Documents\Arduino\GyverPanelWiFi_v1.09\GyverPanelWiFi_v1.09.ino:19:
C:\Program Files (x86)\Arduino\libraries\WiFi\src/WiFi.h:85:10: note: candidate: void WiFiClass::config(IPAddress)
     void config(IPAddress local_ip);
          ^
C:\Program Files (x86)\Arduino\libraries\WiFi\src/WiFi.h:85:10: note:   candidate expects 1 argument, 5 provided
C:\Program Files (x86)\Arduino\libraries\WiFi\src/WiFi.h:92:10: note: candidate: void WiFiClass::config(IPAddress, IPAddress)
     void config(IPAddress local_ip, IPAddress dns_server);
          ^
C:\Program Files (x86)\Arduino\libraries\WiFi\src/WiFi.h:92:10: note:   candidate expects 2 arguments, 5 provided
C:\Program Files (x86)\Arduino\libraries\WiFi\src/WiFi.h:100:10: note: candidate: void WiFiClass::config(IPAddress, IPAddress, IPAddress)
     void config(IPAddress local_ip, IPAddress dns_server, IPAddress gateway);
          ^
C:\Program Files (x86)\Arduino\libraries\WiFi\src/WiFi.h:100:10: note:   candidate expects 3 arguments, 5 provided
C:\Program Files (x86)\Arduino\libraries\WiFi\src/WiFi.h:109:10: note: candidate: void WiFiClass::config(IPAddress, IPAddress, IPAddress, IPAddress)
     void config(IPAddress local_ip, IPAddress dns_server, IPAddress gateway, IPAddress subnet);
          ^
C:\Program Files (x86)\Arduino\libraries\WiFi\src/WiFi.h:109:10: note:   candidate expects 4 arguments, 5 provided
C:\Users\Максим\Documents\Arduino\GyverPanelWiFi_v1.09\GyverPanelWiFi_v1.09.ino: In function 'void startSoftAP()':
GyverPanelWiFi_v1.09:403:8: error: 'class WiFiClass' has no member named 'softAPdisconnect'
GyverPanelWiFi_v1.09:409:23: error: 'class WiFiClass' has no member named 'softAP'
GyverPanelWiFi_v1.09:425:27: error: 'class WiFiClass' has no member named 'softAPIP'
GyverPanelWiFi_v1.09:429:10: error: 'class WiFiClass' has no member named 'enableAP'
GyverPanelWiFi_v1.09:430:10: error: 'class WiFiClass' has no member named 'softAPdisconnect'
GyverPanelWiFi_v1.09:434:25: error: 'class WiFiClass' has no member named 'softAP'
C:\Users\Максим\Documents\Arduino\GyverPanelWiFi_v1.09\GyverPanelWiFi_v1.09.ino: In function 'void connectToNetwork()':
GyverPanelWiFi_v1.09:448:10: error: 'class WiFiClass' has no member named 'mode'
GyverPanelWiFi_v1.09:448:15: error: 'WIFI_AP' was not declared in this scope
C:\Users\Максим\Documents\Arduino\GyverPanelWiFi_v1.09\a_main.ino: In function 'void parsing()':
a_main:1950:22: error: 'class WiFiClass' has no member named 'softAPdisconnect'
exit status 1
no matching function for call to 'WiFiClass::disconnect(bool)'

vvip-68, 2021-01-23:
Возможно это из за наличия у вас кириллицы в пути к библиотекам - те черные квадратики со знаками вопроса.
Смените пользователя Windows на не-кириллического.

Closed 2021-01-23.

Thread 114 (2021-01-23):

ошибки при компиляции ESP32

Dmitro4ekalov, 2021-01-23:
In file included from sketch\a_def_hard.h:432:0,

                 from C:\Users\Maxim\Documents\Arduino\GyverPanelWiFi_v1.09\GyverPanelWiFi_v1.09.ino:19:

C:\Users\Maxim\AppData\Local\Arduino15\packages\esp32\hardware\esp32\1.0.4\libraries\ArduinoOTA\src/ArduinoOTA.h:84:5: error: 'WiFiUDP' does not name a type

     WiFiUDP _udp_ota;

     ^

                       ^

C:\Users\Maxim\Documents\Arduino\GyverPanelWiFi_v1.09\GyverPanelWiFi_v1.09.ino: In function 'void startWiFi(long unsigned int)':

GyverPanelWiFi_v1.09:325:23: error: no matching function for call to 'WiFiClass::disconnect(bool)'

   WiFi.disconnect(true);

                       ^

In file included from C:\Users\Maxim\AppData\Local\Arduino15\packages\esp32\hardware\esp32\1.0.4\libraries\ArduinoOTA\src/ArduinoOTA.h:4:0,

                 from sketch\a_def_hard.h:432,

                 from C:\Users\Maxim\Documents\Arduino\GyverPanelWiFi_v1.09\GyverPanelWiFi_v1.09.ino:19:

C:\Program Files (x86)\Arduino\libraries\WiFi\src/WiFi.h:130:9: note: candidate: int WiFiClass::disconnect()

     int disconnect(void);

         ^

C:\Program Files (x86)\Arduino\libraries\WiFi\src/WiFi.h:130:9: note:   candidate expects 0 arguments, 1 provided

GyverPanelWiFi_v1.09:329:8: error: 'class WiFiClass' has no member named 'mode'

   WiFi.mode(WIFI_STA);

        ^

GyverPanelWiFi_v1.09:329:13: error: 'WIFI_STA' was not declared in this scope

   WiFi.mode(WIFI_STA);

             ^

GyverPanelWiFi_v1.09:341:40: error: no matching function for call to 'WiFiClass::config(IPAddress, IPAddress, IPAddress, IPAddress, IPAddress)'

                   IPAddress(8, 8, 8, 8));                                 // DNS2 8.8.8.8          

                                        ^

In file included from C:\Users\Maxim\AppData\Local\Arduino15\packages\esp32\hardware\esp32\1.0.4\libraries\ArduinoOTA\src/ArduinoOTA.h:4:0,

                 from sketch\a_def_hard.h:432,

                 from C:\Users\Maxim\Documents\Arduino\GyverPanelWiFi_v1.09\GyverPanelWiFi_v1.09.ino:19:

C:\Program Files (x86)\Arduino\libraries\WiFi\src/WiFi.h:85:10: note: candidate: void WiFiClass::config(IPAddress)

     void config(IPAddress local_ip);

          ^

C:\Program Files (x86)\Arduino\libraries\WiFi\src/WiFi.h:85:10: note:   candidate expects 1 argument, 5 provided

C:\Program Files (x86)\Arduino\libraries\WiFi\src/WiFi.h:92:10: note: candidate: void WiFiClass::config(IPAddress, IPAddress)

     void config(IPAddress local_ip, IPAddress dns_server);

          ^

C:\Program Files (x86)\Arduino\libraries\WiFi\src/WiFi.h:92:10: note:   candidate expects 2 arguments, 5 provided

C:\Program Files (x86)\Arduino\libraries\WiFi\src/WiFi.h:100:10: note: candidate: void WiFiClass::config(IPAddress, IPAddress, IPAddress)

     void config(IPAddress local_ip, IPAddress dns_server, IPAddress gateway);

          ^

C:\Program Files (x86)\Arduino\libraries\WiFi\src/WiFi.h:100:10: note:   candidate expects 3 arguments, 5 provided

C:\Program Files (x86)\Arduino\libraries\WiFi\src/WiFi.h:109:10: note: candidate: void WiFiClass::config(IPAddress, IPAddress, IPAddress, IPAddress)

     void config(IPAddress local_ip, IPAddress dns_server, IPAddress gateway, IPAddress subnet);

          ^

C:\Program Files (x86)\Arduino\libraries\WiFi\src/WiFi.h:109:10: note:   candidate expects 4 arguments, 5 provided

C:\Users\Maxim\Documents\Arduino\GyverPanelWiFi_v1.09\GyverPanelWiFi_v1.09.ino: In function 'void startSoftAP()':

GyverPanelWiFi_v1.09:403:8: error: 'class WiFiClass' has no member named 'softAPdisconnect'

   WiFi.softAPdisconnect(true);

        ^

GyverPanelWiFi_v1.09:409:23: error: 'class WiFiClass' has no member named 'softAP'

   ap_connected = WiFi.softAP(apName, apPass);

                       ^

GyverPanelWiFi_v1.09:425:27: error: 'class WiFiClass' has no member named 'softAPIP'

       Serial.println(WiFi.softAPIP());

                           ^

GyverPanelWiFi_v1.09:429:10: error: 'class WiFiClass' has no member named 'enableAP'

     WiFi.enableAP(false);

          ^

GyverPanelWiFi_v1.09:430:10: error: 'class WiFiClass' has no member named 'softAPdisconnect'

     WiFi.softAPdisconnect(true);

          ^

GyverPanelWiFi_v1.09:434:25: error: 'class WiFiClass' has no member named 'softAP'

     ap_connected = WiFi.softAP(apName, apPass);

                         ^

C:\Users\Maxim\Documents\Arduino\GyverPanelWiFi_v1.09\GyverPanelWiFi_v1.09.ino: In function 'void connectToNetwork()':

GyverPanelWiFi_v1.09:448:10: error: 'class WiFiClass' has no member named 'mode'

     WiFi.mode(WIFI_AP);

          ^

GyverPanelWiFi_v1.09:448:15: error: 'WIFI_AP' was not declared in this scope

     WiFi.mode(WIFI_AP);

               ^

C:\Users\Maxim\Documents\Arduino\GyverPanelWiFi_v1.09\a_main.ino: In function 'void parsing()':

a_main:1950:22: error: 'class WiFiClass' has no member named 'softAPdisconnect'

                 WiFi.softAPdisconnect(true);

                      ^

exit status 1

no matching function for call to 'WiFiClass::disconnect(bool)'

подскажите, в чем причина?

vvip-68, 2021-01-23:
Нет, не подскажу. Вы первый и единственный у кого такая ошибка. Причины не понимаю. Cудя по логу - версия ядра актуальная, все на что ругается - входит в состав ядра ESP32. Попробуйте переустановить всё - начиная с Arduino IDE, заканчивая всеми используемыми библиотеками и ядром ESP32. Другого совета у меня нет.

vvip-68, 2021-01-23:
У вас какая-то смесь из библиотек, например
`C:\Program Files (x86)\Arduino\libraries\WiFi\src/WiFi.h:130:9: note: candidate: int WiFiClass::disconnect()`
Что за библиотека WiFi, которая пытается использоваться при компиляции?
Все что нужно для работы скетча - находится внутри ядра ESP32
Удалите эту папку с библиотекой `C:\Program Files (x86)\Arduino\libraries\WiFi` для начала

Mosrom, 2021-04-03:
После изменений 6 дней назад файла clock.ino строк 870-876:
       if (((useWeather > 0)) && weather_ok && (((second() + 10) % 30) >= 28)) {
        uint8_t atH = abs(temperature) / 10;
        uint8_t atL = abs(temperature) % 10;
        display.point(false);
        if (atH == 0)
          display.displayByte(_empty, (temperature >= 0) ? _empty : _dash, display.encodeDigit(atL), _degree);
        else
возникает ошибка компиляции (см. скрин), до этих изменений скетч компилировался без ошибок.  
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

vvip-68, 2021-04-03:
Не подскажу. У меня таких проблем не возникает - всё собирается без ошибок.
Я там поубирал некоторые warnings компилятора. Попробуйте собрать обновленную версию.

Mosrom, 2021-04-03:
Спасибо. Помогло.

Closed 2021-01-23.

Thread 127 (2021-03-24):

pcb

RailWar, 2021-03-24:
для себя разработал плату для esp-12f в sprint layout если кому-то кроме меня интересно могу поделиться - вставите в проект. выглядит так
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
готовую уже не сфотогрофировать - запаял и засунул в коробку. разведено все - micro sd, dfplayer, дисплей, тач,  мосфет, порт для usb-uart

vvip-68, 2021-03-24:
Плата - это здорово. Я в этом ничего не понимаю, но если пришлёте всё что нужно - я добавлю это в проект.

RailWar, 2021-03-24:
[lamp8266.zip](https://github.com/vvip-68/GyverPanelWiFi/files/6196693/lamp8266.zip)

vvip-68, 2021-03-24:
Вот спасибо за печатку!
Чтобы не ошибиться - это же для
#define DEVICE_VARIANT 1
?

Дам для варианта 0 и 1 кажется немного отличается распиновка - что к каким пинам подключается.
Этот вариант для тач-кнопки или можно обычную использовать и где-то что-то перемычкой переключается?

vvip-68, 2021-03-24:
Может быть было бы совсем хорошо - если есть какой-то текстик - иснструкция по сборке для "чайников"...

vvip-68, 2021-03-24:
Особенно с инструкцией "как прошивать" по проводам. Для этого же нужен внешний конвертоh USB-TTL? насколько я понимаю или через Arduino (Nano)?

RailWar, 2021-03-24:
#define DEVICE_VARIANT 1 - да
можно и обычную кнопку. там контакт "+" не используется.
чайники с таким связываться не захотят (наверное). я утюгом делал плату, где покупал на али, где выпаивал из доноров детальки. но напишу-опишу чуть позже.
а прошивать точно так же. просто надо иметь com-uart. напр. на той же cp2102. появится ком-порт

vvip-68, 2021-03-24:
У меня ЧПУ-шка есть. Надо будет попробовать выгравировать плату, как время свободное на это появится...

RailWar, 2021-03-24:
специально делал односторонюю чтобы утюгом . только две перемычки бросить надо

RailWar, 2021-03-24:
вывел туда еще adc. может когда пригодится

RailWar, 2021-03-25:
[pcb.docx](https://github.com/vvip-68/GyverPanelWiFi/files/6203823/pcb.docx)

vvip-68, 2021-03-25:
Вот спасибо! Добавил в проект.

Closed 2021-03-25.

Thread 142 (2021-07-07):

Error while compiling - missing a_def_devc.h

TimoUrban, 2021-07-07:
Hi!

I get the following error during compilation in Arduino IDE:

```
compilation terminated.
exit status 1
a_def_devc.h: No such file or directory
```

I found this file in file "private.zip" but it is password protected.
Can you please help me?

Thank you very much.

vvip-68, 2021-07-07:
You not need this file.
Edit line 37 of file a_def_hard.h as:
 
#define A_DEF_DEVC  0
 
 
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
 
 
С уважением,
Вадим Пузанов

Closed 2021-07-08.

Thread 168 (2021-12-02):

Какой версией FastLED прошить, чтобы предотвратить хаотичные мерцания по всей матрице?

AndreyLyamkin, 2021-12-02:
Как можно устранить хаотичные вспышки на гирлянде?
Пробовал FastLED понижать до 3.3.3, 3.3.2...
Может есть патч какой-то для ESP8266 (NodeMCU 1.0(ESP-12E Module))&

vvip-68, 2021-12-02:
Хаотичные вспышки на гирлянде можно устранить только настройкой напряжения питания системы. Никакие изменения версии FаstLED не помогут в принципе.
Если схема собрана без поддерживающего диода по минусу питания контроллера - напряжение питания системы не должно быть выше 4.8 вольта. Если напряжение питание в диапазоне 5.0-5.8 вольт - нужно ставить поддерживающий диод на минус питания контроллера.
Естественно источник питания не должен должен иметь шумов на выходе, на питании контроллера очень желательно ставить электролитический конденсатор на 1000-2000 мкф и параллельно ему керамический конденсатор на 100 нф.

AndreyLyamkin, 2021-12-02:
Спасибо за совет!!!
попробовал понизить даже до 4.0 вольт... Ничего не изменилось.
Но! Я в прошлом году собирал на этом же железе, на этих же светодиодах.... И не было мерцаний.

vvip-68, 2021-12-02:
Ядро контроллера какой версии стоит?

AndreyLyamkin, 2021-12-02:
Это удар в спину ))))
Как проверить? и как обновить???

vvip-68, 2021-12-02:
В Arduino IDE - Инструменты - Платы - Менеджер плат - ESP8266
Версия должна быть 2.7.4

AndreyLyamkin, 2021-12-02:
Была 3.0.2
Ставлю 2.7.4 и шьюсь!

247760, 2021-12-02:
Кусочек из самого начала GyverPanelWiFi_v1.12.ino
`
// -------------------------------------------------------------------------------------------------------

// На версии ядра ESP8266 v3.x.x и FastLED 3.4 работать не будет!
//  -> Постоянно горит самый первый светодиод в цепочке синим или зелёным
//  -> некоторые эффекты сильно мерцают.
//  -> пин ленты с D2 переназначается ядром на D4
// На версии ядра ESP32 1.0.5 или 2.x.x и FastLED 3.4 работать не будет!
//  -> 1.0.5 - При USE_E131 == 1 - при переключении с MASTER на STANDALONE или SLAVE - crash  и перезагрузка.
//             Для исправления - в файле C:\Users\<user>\AppData\Local\Arduino15\packages\esp32\hardware\esp32\1.0.5\libraries\AsyncUDP\src\AsyncUDP.cpp
//             найти деструктор AsyncUDP::~AsyncUDP() и перенести вызов close(); из начала процедуры в конец
//  -> 2.0.0 - Нет вывода изображения на ленту ни на одном из пинов

// Версия ядра ESP8266 - 2.7.4
// Версия ядра ESP32   - 1.0.6
// Версия FastLED      - 3.4.0

// -------------------------------------------------------------------------------------------------------
`

AndreyLyamkin, 2021-12-02:
я уже откатился на прошивку 1.0.8....

247760, 2021-12-02:
@AndreyLyamkin раз осилили 1,08 в своё время, то потратьте 5 минут и настройте крайнюю версию, всё самое важное что надо прочитать (https://github.com/vvip-68/GyverPanelWiFi/issues/168#issuecomment-984744642) , сделать и перенести старые данные.

vvip-68, 2021-12-02:
@AndreyLyamkin - вы не только не читаете комментарии в скетче, но даже не читаете то, что вам отвечают...
Так что - откатиться на 1.0.8 - самое верное решение. Но оно скорее всего тоже не заработает по той же самой причине.
> // На версии ядра ESP8266 v3.x.x и FastLED 3.4 работать не будет!
 //  -> Постоянно горит самый первый светодиод в цепочке синим или зелёным
 //  -> некоторые эффекты сильно мерцают.
 //  -> пин ленты с D2 переназначается ядром на D4

**пин ленты с D2 переназначается ядром на D4**

AndreyLyamkin, 2021-12-02:
Да как же! Я же  в самом начале написал, что FastLED поставил != 3.4
Я пробовал все вниз: 3.3.3, 3.3.2
И все вроде как работает! Только эти хаотичные вспышки... И питанием не помогает убрать..

Сейчас прошился на крайний релиз, все как по Вашим подсказкам.
Но теперь другая беда - к Wi-Fi подключается, а вот дальше никуда, ни адрес NTP не получает, ни погоду никак не получит...
ДА!!! Пробовал и на рабочем роутере, и через Wi-Fi поднятого на телефоне...

vvip-68, 2021-12-02:
Вам же написали - вспышки - из за ядра 3.0.2. При назначении "LED_PIN 2" это ядро садит выход на D4.
Рабочее ядро - 2.7.4. При этом, если ничего не менять в настройках - при том же "LED_PIN 2" ядро направид выход сигнала на D2.

Про WiFi - смотрите правильно ли настроена сеть, находится ли устройство в той  же сети, что и роутер. Смотрите в мониторе порта на какой адрес подключается и подключается ли вовсе. Ну и далее по алгоритму...

AndreyLyamkin, 2021-12-06:
Вы меня простите. Я Вас обоих понимаю, сам работаю программистом и по совместительству сисадмином. И повторять одно и тоже этим тупым пользователям... Которые не читают инструкции... В общем, без обид!
Теперь по существу:

Чтобы я не делал, как бы не варьировал версии ядра и библиотеки FastLED, мой контроллер не работает с последней прошивкой! А именно: в мониторе порта тупо пишет, что подключился к сети, но в логах роутера (Mikrotik) пусто!, так же не пингуется плата вообще никак. Ну, и соответственно, ни время, ни погоду получить из интернета не может.
Это первое...  Было бы интересно понять, почему так происходит, тем более я не один [такой](https://github.com/vvip-68/GyverPanelWiFi/issues/165).

Я восстанавливаю 1.0.8 работала всю с декабря по май без проблем.... А вот в этом году почему-то хаотичные вспышки.
Блок питания у меня вполне норм, 5V30А... такой железный "в дырочку"... И питание я понижал до 4 вольт, и кондеры ставил 5.3V1000mF... И диод, чтобы подтянуть напругу.... Ничто это не помогло убрать хаотичные вспышки...

Но я победил этот недуг:
1. В библиотеке FastLED ищем файл "\FastLED\platforms\esp\8266\clockless_esp8266.h"
2. В нем ищем строку "//template <int DATA_PIN, int T1, int T2, int T3, EOrder RGB_ORDER = RGB, int XTRA0 = 0, bool FLIP = false, int WAIT_TIME = 50>"
3. Меняем ее на "//template <int DATA_PIN, int T1, int T2, int T3, EOrder RGB_ORDER = RGB, int XTRA0 = 0, bool FLIP = false, int WAIT_TIME = 5>"   т.е. в конце 50 меняем на 5. Возможно частые отключения от Wi-Fi, но у меня за час "НЕ БЫЛО НИ ЕДИНОГО РАЗРЫВА" )))

Далее... Во всех файлах скетча ищем:
Строку #include <FastLED.h> и перед ней, выше пишем: #define FASTLED_ALLOW_INTERRUPTS 0 (это в одном файле только)
Далее ищем строку "FastLED.show()" и после каждого вхождения с новой строки пишем:  yield();

После прошивки того-же контроллера все артефакты как ветром сдуло!
Может кому-то еще поможет...

KAKTO, 2021-12-09:
Была такая проблема с хаотичными вспышками на гирлянде  500 Leds 25 метров - поставил диод (1N4007) - проблема ушла. Думаю наводка по проводам (провода не скручивал). Но ближе к этой проблеме новая матрица 16х16, которую  купил. Собрал, подключил - хаотичные вспышки. Подключил старую матрицу - работает. Поставил диод, подключил новую матрицу - работает.
Правда собрано на Wemos
FastLED version 3.003.003
LED_PIN 3
PIN_BTN D4

Closed 2021-12-02.

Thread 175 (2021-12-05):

Внешний файл настроек

Des-75, 2021-12-05:
Здравствуйте. Можно поподробнее вот про этот момент:
```
#define A_DEF_DEVC 1          // 1 - Настройки профилей ваших устройств в отдельном файле a_def_devc.h
                              // 0 - Настройки профиля вашего устройства размещены ниже в этом файле
                              // Файл a_def_devc.h в комплект не входит, нужно создать, скопировать туда настройки профилей ваших устройств
```
Я не понимаю где начинаются/заканчиваются границы профиля, который я должен скопировать во внешний файл (у меня ESP8266).

vvip-68, 2021-12-05:
Оно вам действительно нужно? У вас несколько изделий, содержащих разные размеры матриц / состав подключенных модулей / пины подключения?

Профиль устройства - от начала описания профиля до следующего такого же куска в скетче ниже.
Вот пример описания профиля одного устройства:
```
#define WIDTH 16                // ширина одного сегмента матрицы
#define HEIGHT 16               // высота одного сегмента матрицы
#define MATRIX_TYPE 0           // тип соединения диодов в сегменте матрицы: 0 - зигзаг, 1 - параллельная
#define CONNECTION_ANGLE 1      // угол подключения диодов в сегменте: 0 - левый нижний, 1 - левый верхний, 2 - правый верхний, 3 - правый нижний
#define STRIP_DIRECTION 3       // направление ленты из угла сегмента: 0 - вправо, 1 - вверх, 2 - влево, 3 - вниз

#define META_MATRIX_WIDTH 1     // количество сегментов в ширину сборной матрицы
#define META_MATRIX_HEIGHT 1    // количество сегментов в высоту сборной матрицы
#define META_MATRIX_TYPE 0      // тип сборной матрицы: 0 - зигзаг, 1 - параллельная
#define META_MATRIX_ANGLE 0     // угол 1-го сегмента сборной матрицы: 0 - левый нижний, 1 - левый верхний, 2 - правый верхний, 3 - правый нижний
#define META_MATRIX_DIRECTION 0 // направление следующих сегментов сборной матрицы из угла: 0 - вправо, 1 - вверх, 2 - влево, 3 - вниз

#define DEVICE_TYPE 1           // Использование матрицы: 0 - свернута в трубу для лампы; 1 - плоская матрица в рамке
#define BUTTON_TYPE 1           // Тип кнопки: 0 - сенсорная (touch button); 1 - обычная кнопка на замыкание при нажатии (или если кнопки нет вообще)
#define USE_SD 0                // поставьте 0, если у вас нет SD-card модуля
#define USE_TM1637 0            // поставьте 1, если используется дополнительный индикатор TM1637, 0 если индикатора нет
#define USE_POWER 1             // 1 - использовать отключение питания матрицы через MOSFET / реле; 0 - не использовать
#define USE_MQTT 0              // 1 - использовать управление по MQTT-каналу; 0 - не использовать
#define USE_WEATHER 1           // 1 - использовать получение информации о текущей погоде; 0 - не использовать
#define USE_E131 0              // 1 - использовать протокол E1.31 для синхронизации устройств или приема внешнего потока на матрицу с Jinx! или другого аналогичного ПО
#define BIG_FONT 0              // 0 - шрифт 5x8, 1 - шрифт  10x16; 2 - шрифт 8x13

// DFPlayer выпускается разными производителями на разных чипах.
// Оригинальный плеер построен на микросхеме с обозначением на корпусе AS20HH5883-74
// Существует множество клонов DFPlayer от других производителей, построенных на других чипах, например MH2024K-24SS, MH2024K-16SS и др.
// Эти чипы отличаются от оригинальных несколько измененной системой команд. Библиотеке нужно знать команды в каком формате отправлять плееру.
// Укажите ниже какой чип использован в в вашем DFPlayer

#define USE_MP3 0               // поставьте 0, если у вас нет звуковой карты MP3 плеера
#define DFPLAYER_TYPE 0         // 0 - AS20HH5883-74 (оригинальный); 1 - MH2024K-24SS, MH2024K-16SS (клон)

#define LED_PIN  2              // D2 пин ленты
#define PIN_BTN D4              // D4 кнопка подключена сюда (D4 --- КНОПКА --- GND)
                                // D6 для схем с DFPlayer    (D6 --- КНОПКА --- GND)
#define POWER_PIN D1            // D1 управляющий пин вкл/выкл матрицы через MOSFET / реле; POWER_ON - HIGH, POWER_OFF - LOW
#define SD_CS_PIN D8            // пин выбора SD карты - ChipSelect; Также SD карта использует D5 (CLK), D6 (MISO), D7 (MOSI)
#define STX D3                  // подключен в RX пин (2) модуля DFPlayer
#define SRX D4                  // подключен в TX пин (3) модуля DFPlayer
#define DIO D5                  // D5 TM1637 display DIO pin - требуется для компиляции скетча (USE_TM1637 == 1)
#define CLK D7                  // D7 TM1637 display CLK pin - требуется для компиляции скетча (USE_TM1637 == 1)

                                // Для USE_SD == 1 - поведение при проигрывании файла эффекта с SD-карты
#define WAIT_PLAY_FINISHED 1    // 1 - переключаться на следующий эффект только когда весь файл полностью показан;
                                // 0 - прерывать показ файла с SD-карты по истечении времени эффекта

#define DEBUG_SERIAL 1          // включить/выключить отладочный вывод в Serial: 0 - выключено 1 - включено
```
Ниже повторяется такой же набор полей для другого профиля

ЗЫ: Раньше этот файл, содержащий профили (настройки) МОИХ устройств входил в состав проекта, но пользовали почему-то бездумно выбирали МОЕ устройство и удивлялись что у них ничего не работает. И оно вполне естественно - у них то другие размеры, другие пины подключения, другой набор модулей. Поэтому МОИ настройки были вынесены в отдельный файл, который теперь не входит проект, а пользователю предлагается ИЛИ самостоятельно создать файл и настроить в нем профили множества своих устройств под себя ИЛИ просто изменить настройки в этом (a_hard_def.h) файле в профиле, описанном ниже

Des-75, 2021-12-05:
Спасибо.
ЗЫ: Оно мне **действительно** нужно. Ваш проект на месте не стоит, и менять настройки каждое обновление несколько муторно, согласитесь?

vvip-68, 2021-12-05:
1. Тогда могу куда-нибудь прислать мой файл. Сделаете на его основе свой.
2. Потому что народ жаловался, что им мало 16 (или 24?) символов в пароли - у них пароли по 30 символов. Место на длинные строки в EEPROM уже не было (а все настройки там хранились) - пришлось переместить длинные пароли на "диск" - в файловую систему микроконтроллера.  Это было с версии то ли 1.10 то ли 1.11
Если прошивка без выделения места под файловую систему - сохранять настройки подклбчения к сети негде - она каждый раз будет требовать их вводить.

Des-75, 2021-12-05:
1. Спасибо, не надо, уже сделал.
2. Было бы неплохо указать на эту особенность. :)

Closed 2021-12-05.

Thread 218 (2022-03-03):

12 hour mode

Red-77, 2022-03-03:
is it possible to change the clock mode to 12 hour mode, cuz by default it is in 24 hour mode, thank you

vvip-68, 2022-03-03:
Here in the country of developer nobody uses 12H format of time display, only 24H
By this reason nobody wants this and nobody use it.
Source code is open - you may change script by yourself to use time format you want.

Red-77, 2022-03-03:
in what part of the code the time is formatted? alas where should i look and make changes to the format, sorry but im not good with coding, but i am willing to do it myself so can you please guide me a bit

vvip-68, 2022-03-03:
More obvious part of code is in clock.ino file, function DrawClock(), starting line 237
'hrs' is parameter of function containing hours of time in range 0..23.
You must doing simplest arithmetic operation to convert it from 0..23 to 1..12 range

Red-77, 2022-03-03:
ok i kind of figured it out the library has a function to return 12 hour time  "hourFormat12(); ". so that was simple to do, one last thing what is the purpose of line 128 : String clockCurrentText, do i need to change anything in that?

vvip-68, 2022-03-03:
I think yes. This function is used fro display current time as running text in some cases.
line 130 returns hours in range 0..23; Obviously you also need convert it to 12H format

Red-77, 2022-03-03:
ok i did it and it worked so if someone whats to change the time format to 12 hours

change the  hour();  function to  hourFormat12();
in line 74, 130, 801 and leave the rest as it is

Red-77, 2022-03-05:
ok so the clock is working fine but ,i am facing a problem, the time is displayed in 12 hour format if i am connected to the internet, but if i disconnect internet after 12 it turn to 13 cuz it cant sync to ntp, also if i use "set device time" it sets the time in 24 hours, so how can i set the timer to be 1-12 so that after 12 it turns back to 1

vvip-68, 2022-03-05:
Why you can`t sync time via internet? What is the reason? Internally time stored (and received from NTP server) in system as long integer (seconds since 1970 year) and it is no difference between 12H or 24H of **display** format. The same with "set device time" - phone internally sends time to controller in 24H format (as I understand) and sketch of controller converts them into long integer internally. I do not understand the issue...

If you means setting time of alerts and time dependent modes page of application - fields containing time shows it as returns clock component of application. All clocks an timers uses time in natural 24H format. If you want to see time in special 12H format - it is necessary somehow rework phone application (in aia-file in folder Android of project) in AppInventor web constructor. Because of size of application it works very slow - it is paine to change something in application. But you can try if you want.

Red-77, 2022-03-05:
i think you misunderstood my issue my issue is that, if internet connection is lost, after 12:59 it goes to 13:00, is there someway i can make it go from 12:59 to 01:00, otherwise i have to sync to ntp every minute

Red-77, 2022-03-05:
see let me explain my issue
i modified the code so that when it syncs to ntp it shows 12 hour format, which forces it to go to 1:00 after 12:59
but if it doesn't sync to ntp after 12:59 it turns to 13:00, cuz the internal counter still counts (0-23)
so if i loose my internet connection at 12:59, it will go to 13:00, is there some way i can fix it

vvip-68, 2022-03-05:
I still do not understand the issue. Whole day has 24 hours. All internal counters work in 24-hour cycle. It is system things. More exactly it counts every one second tick to increment large int value stored seconds. The method how you doing **print** int seconds counter (more common converted to hours with hour() or hourFormat12() function) on matrix screen - is fully your design and implementation. You even can display time in 8-hour intervals 0..7 and next again 0..7 if you need it for some exotic reason. I do not understand a subject of issue

Red-77, 2022-03-05:
ok whole day has 24 hours, in 24 hour system (0-23), in 12 hour system (1-12am 1-12pm), so all i want to know is how do i make the internal conter count from (1-12am 1-12pm) because if i loose internet connection and the clock is not able to sync to ntp, it shows 13:00 instead of showing 1pm. the line of code that i changed, requested 12 hour time from library, but it doesn't change the internal counter, so what i want to know is in which part of the code is the counter function located

vvip-68, 2022-03-05:
No. It is impossible. Because of nature. Because Earth doing one turn around in 24 hours. It not depend on ntp sync. Ntp Sync time returns time as amount of milliseconds since 1970.01.01 00:00 and does not depend on **DISPLAY** format you use - 24H or 12H. If in drawClock() function call of hourFormat12() returns wrong (unexpected) value as 13 - it is error in library function and you need to override it writing code manually. Like - if hour value is greater or equal to 13 - decrease value by 12. If returned value of hours is 0 - assign it to 12.

Red-77, 2022-03-05:
actually i fixed the issue, there were some function in other file that used hour(); changing them to hourFormat12 (); fixed the issue, i didn't even have to modify the app, now it all works

Closed 2022-03-05.

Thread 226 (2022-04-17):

led corner blinking

dio1985, 2022-04-17:
> 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

i have 4panels(16×16)
i found 1point blinking led. so i tried to change to other panel. but its same
and also i changed led direction by code. but its same

any problem only for me?

https://user-images.githubusercontent.com/78635592/163703343-eb608509-a93b-42a1-9894-a377ed2f9009.mp4

vvip-68, 2022-04-17:
It is common issue for those, who do not want read instructions on several first lines of main sketch file and uses wrong version of ESP8266 core. It should be 2.7.4 version, not 3.x.x

vvip-68, 2022-04-17:
After you install right version of esp8266 core du not forget also return led bin back to D2 from D4, that uses in case of core 3.x.x version

Closed 2022-04-17.

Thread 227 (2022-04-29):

wifi setup err

dio1985, 2022-04-29:
1. connection to my wifi with default(192.168.0.100)
2. but my wifi was 192.168.219.xxx
3. but GyverPanel tried to conect wrong default(192.168.0.100)
4. GyverPanel show me conected 192.168.0.100
5. so can not conect any ntp or weather .
6. this is same to wrong wifi
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
 psswd as 2times

vvip-68, 2022-04-29:
So, what is the question? Of course, if you connect to wrong network, you will not be able to get internet resources, available on another network. It is obviously.

Turn on matrix device into AP mode using button click on device start before it connected to wrong network, connect to the device using APPanel access point on 192.168.4.1, open PanelSetup application and set correct IP addres for device.

Closed 2022-04-29.

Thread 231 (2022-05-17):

auto connection wifi

dio1985, 2022-05-17:
"auto connect" has some problem when start

1. panel is connected xxx.xxx.xxx.100
2. phone is connected xxx.xxxx.xxx.101
3. The app is connected to addr xxx.xxx.xxx.100
  (Set up an automatic connection checked)

but If i change the order of Wi-Fi connection after the connection is successful

1. phone is xxx.xxx.xxx.100
2. (panel is not connected yet) now powe off
3. insert power . panel is xxx.xxx.xxx.101
4. start app. (app try to connect 100 that is phone)
5.  The phone is connected, but the application is successful.
But I couldn't load the existing settings
I can't do anything

vvip-68, 2022-05-17:
Sorry, it is not clear description for issue. I do not understand completely where is trouble.
If you set in app specified IP address and checkbox 'Autoconnect' is checked, obviously app will try to connect to specified IP without necessity to tap on button 'Connect". What`s wrong?

dio1985, 2022-05-17:
> Sorry, it is not clear description for issue. I do not understand completely where is trouble. If you set in app specified IP address and checkbox 'Autoconnect' is checked, obviously app will try to connect to specified IP without necessity to tap on button 'Connect". What`s wrong?

For example, the ip of the panel is 100. The application connection is successful. After that, turn off all power connected to wifi again The panel is connected to ip 101 (in this case, the phone has ip 100). But the app connects to the phone with ip 100. But I can't do anything.

dio1985, 2022-05-17:
I mean, the app is connected to the IP of the phone.

vvip-68, 2022-05-17:
If you specify panel IP directly in WiFiPanelSetup application, panel couldn`t change IP in random manner, it uset always exactly specified IP. If you leave in WiFiPanelSetup IP address empty or set it to 0.0.0.0 - panel will use DHCP and will get IP address given by your router.

It is your choice how to setup panel. If you prefer use  DHCP - you may setup your router for set specified IP to device each time on panel request getting IP by DHCP. See manual for your router.

If you want, you may specify IP address for panel as static in WiFiPanelSetup application and panel will receive specified IP each time on start (on power on).

If you can`t connect to panel, when it connected to your local network, you may shortly press button on panel immediately after it is powered on. In this case panel will create Access Point with IP 192.168.4.1.  Connect your phone to this Access Point and use WiFiPanelSetup application for setup static IP.

Closed 2022-05-17.

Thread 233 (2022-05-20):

getWeekdayString

dio1985, 2022-05-20:
file . utility.ino

 String getWeekdayString(uint8_t wd) {
  String str = "";
  switch (wd) {
    case  1: str = F("Monday");    break;
    case  2: str = F("Tuesday");   break;
    case  3: str = F("Wednesday"); break;
    case  4: str = F("Thursday");  break;
    case  5: str = F("Friday");    break;
    case  6: str = F("Saturday");  break;
    case  7: str = F("Sunday");    break;
  }
  return str;
}

I just changed the day of the week to english but it doesn't show properly

"Fri2a22" ??????????

https://user-images.githubusercontent.com/78635592/169562382-9c6f0aff-e6b2-4678-90c9-187d3903f28b.mp4

vvip-68, 2022-05-20:
I have no answer. Video is inaccessible.

dio1985, 2022-05-20:
> I have no answer. Video is inaccessible.

https://user-images.githubusercontent.com/78635592/169616596-2c264d37-b3d1-491b-b124-32ea6ad8f69e.mp4

> I have no answer. Video is inaccessible.

https://user-images.githubusercontent.com/78635592/169616996-fcf7e99c-7807-4188-8469-c16c2c172afd.mp4

> I have no answer. Video is inaccessible.

https://user-images.githubusercontent.com/78635592/169617391-8c20f54e-2b81-4edd-b275-745b1582087b.mp4

dio1985, 2022-05-20:
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
and i used "MM dd yyyy dddd" but all dddd or DDDD has something wrong
>
> "Fri2a22" ??????????

vvip-68, 2022-05-21:
I still have no idea.
Conversion from 'DDDD' or 'dddd' to day of week is in RunningText.ino, lines 1134-1136
Check if your code files are saved in UTF-8 format.

dio1985, 2022-05-21:
> I still have no idea. Conversion from 'DDDD' or 'dddd' to day of week is in RunningText.ino, lines 1134-1136 Check if your code files are saved in UTF-8 format.

I just changed the days of the week in Russian to English. You can find out if you change only one day of the week into English

file . utility.ino

String getWeekdayString(uint8_t wd) {
String str = "";
switch (wd) {
case 1: str = F("Monday"); break;
case 2: str = F("Tuesday"); break;
case 3: str = F("Wednesday"); break;
case 4: str = F("Thursday"); break;
case 5: str = F("Friday"); break;
case 6: str = F("Saturday"); break;
case 7: str = F("Sunday"); break;
}
return str;
}

please try to use english

vvip-68, 2022-05-21:
Yes, really. I got an issue. Because running string processed in cycle until all data-related substitutions are not processed.
So, data-formatter string 'DDDD' initially substituted with 'Fri*d*a*y*', next iteration *'d'* from Friday substituted with day '21' and *'y'* with short-year -- 22...

Will think about way to fix it...

vvip-68, 2022-05-21:
I updated source file runningText.ino
Try to get it and use in your sketch.
I thing issue is fixed.

dio1985, 2022-05-21:
> I updated source file runningText.ino Try to get it and use in your sketch. I thing issue is fixed.

wow thank you so much !!i will try to do .
your project is so great

Closed 2022-05-21.

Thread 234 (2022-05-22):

auto connection Err

dio1985, 2022-05-22:
https://user-images.githubusercontent.com/78635592/169684103-38c0242b-967b-4d6b-a234-0fda0b23a8b8.mp4

it has something wrong with auto connection.
first of all , its not working when just only try to connection
but auto connection tried to connect to phone IP after exit application with checked "auto connection"  and reStart application

vvip-68, 2022-05-22:
So what? It senseless test of check connection?
Yes, it is bug.
When 'Autoconnect' is unchecked, the check of IP address validity performs on button click action. It checked if specified IP differs from IP address received by phone self from router, for preventing establish connection of application to phone self.
When 'Autoconnect' is checked the validation of specified IP address is skipped and connection established as loop to self (like localhost). Obviously in this loop nothing works, because remote device still out of connection and know nothing about data requests from application.

It is so rare and specific situation and I do not want spend my time to modify application for IP address validation if 'Autoconnect' checkbox is checked. You may do it yourself if you wand and have a lot of free time. Source code of application placed in project in folder 'Android/AppInventor'.

vvip-68, 2022-05-22:
During this fascinating process you also may translate labels in application from russian to english. It is very useful case.

Closed 2022-05-22.

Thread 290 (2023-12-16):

Ошибка 'workMode' was not declared in this scope

munstr, 2023-12-16:
Приветствую. Ничего не трогал и вдруг компилятор начал что то на рабов ругаться. Ядро 3.1.2. Wemos d1 mini

Вот фулл ошибка:
`
In file included from C:\Users\lsiba\OneDrive\Desktop\ARDUINO\LedPanelWiFi-main\firmware\LedPanelWiFi_v1.14\a_def_hard.h:502,
                 from C:\Users\lsiba\OneDrive\Desktop\ARDUINO\LedPanelWiFi-main\firmware\LedPanelWiFi_v1.14\LedPanelWiFi_v1.14.ino:185:
C:\Users\lsiba\OneDrive\Desktop\ARDUINO\LedPanelWiFi-main\firmware\LedPanelWiFi_v1.14\a_def_lang.h:41:6: warning: multi-character character constant [-Wmultichar]
   41 | #if (LANG == 'RUS')
      |      ^~~~
C:\Users\lsiba\OneDrive\Desktop\ARDUINO\LedPanelWiFi-main\firmware\LedPanelWiFi_v1.14\a_def_lang.h:41:14: warning: multi-character character constant [-Wmultichar]
   41 | #if (LANG == 'RUS')
      |              ^~~~~
C:\Users\lsiba\OneDrive\Desktop\ARDUINO\LedPanelWiFi-main\firmware\LedPanelWiFi_v1.14\a_def_lang.h:329:6: warning: multi-character character constant [-Wmultichar]
  329 | #if (LANG == 'ENG')
      |      ^~~~
C:\Users\lsiba\OneDrive\Desktop\ARDUINO\LedPanelWiFi-main\firmware\LedPanelWiFi_v1.14\a_def_lang.h:329:14: warning: multi-character character constant [-Wmultichar]
  329 | #if (LANG == 'ENG')
      |              ^~~~~
C:\Users\lsiba\OneDrive\Desktop\ARDUINO\LedPanelWiFi-main\firmware\LedPanelWiFi_v1.14\a_def_lang.h:618:6: warning: multi-character character constant [-Wmultichar]
  618 | #if (LANG == 'ESP')
      |      ^~~~
C:\Users\lsiba\OneDrive\Desktop\ARDUINO\LedPanelWiFi-main\firmware\LedPanelWiFi_v1.14\a_def_lang.h:618:14: warning: multi-character character constant [-Wmultichar]
  618 | #if (LANG == 'ESP')
      |              ^~~~~
In file included from C:\Users\lsiba\OneDrive\���������\Arduino\libraries\FastLED\src/FastLED.h:75,
                 from C:\Users\lsiba\OneDrive\Desktop\ARDUINO\LedPanelWiFi-main\firmware\LedPanelWiFi_v1.14\a_def_hard.h:528,
                 from C:\Users\lsiba\OneDrive\Desktop\ARDUINO\LedPanelWiFi-main\firmware\LedPanelWiFi_v1.14\LedPanelWiFi_v1.14.ino:185:
C:\Users\lsiba\OneDrive\���������\Arduino\libraries\FastLED\src/fastspi.h:157:23: note: '#pragma message: No hardware SPI pins defined.  All SPI access will default to bitbanged output'
  157 | #      pragma message "No hardware SPI pins defined.  All SPI access will default to bitbanged output"
      |                       ^~~~~~~~~~~~~~~~~~~~~~~~~~~~~~~~~~~~~~~~~~~~~~~~~~~~~~~~~~~~~~~~~~~~~~~~~~~~~~~~
C:\Users\lsiba\OneDrive\Desktop\ARDUINO\LedPanelWiFi-main\firmware\LedPanelWiFi_v1.14\a_main.ino: In function 'void process()':
a_main:435:24: error: 'workMode' was not declared in this scope
  435 |     if (isTurnedOff && workMode != SLAVE) {
      |                        ^~~~~~~~
a_main:435:36: error: 'SLAVE' was not declared in this scope; did you mean 'sSLAVE'?
  435 |     if (isTurnedOff && workMode != SLAVE) {
      |                                    ^~~~~
      |                                    sSLAVE
exit status 1
'workMode' was not declared in this scope
`

vvip-68, 2023-12-16:
Минут 15 назад исправил это. Возьмите последнюю версию файла a_main.ino
Или внесите следующие изменения - должно помочь

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

Ну или (все равно не используете E131 - прост удалите вот этот кусочек - '&& workMode != SLAVE'

Closed 2023-12-17.

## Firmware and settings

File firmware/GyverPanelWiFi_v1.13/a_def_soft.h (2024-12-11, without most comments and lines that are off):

#define EEPROM_OK     0x5D                // Флаг, показывающий, что EEPROM инициализирована корректными данными
#define NETWORK_SSID ""                   // Имя WiFi сети
#define NETWORK_PASS ""                   // Пароль для подключения к WiFi сети
#define DEFAULT_IP {192, 168, 0, 100}     // Сетевой адрес устройства по умолчанию
#define DEFAULT_PORT 2390                 // Сетевой порт устройства по умолчанию
#define GTW     1                         // Последняя цифра в IP адресе роутера. Обычно IP роутера 192.168.0.*1*, но некоторые роутеры имеют адрес 192.168.0.100 или 192.168.0.254
#define DEFAULT_NTP_SERVER "ru.pool.ntp.org"     // NTP сервер по умолчанию "time.nist.gov"
#define DEFAULT_AP_NAME    "PanelAP"             // Имя точки доступа по умолчанию
#define DEFAULT_AP_PASS    "12341234"            // Пароль точки доступа по умолчанию
#if (USE_MQTT == 1)
#define DEFAULT_MQTT_SERVER "mqtt.by"            // MQTT сервер
#define DEFAULT_MQTT_USER   ""                   // Имя mqtt-пользователя    (!!! укажите имя пользователя для вашего соединения - зарегистрируйтесь на mqtt.by -> смотрите в личном кабинете !!!)
#define DEFAULT_MQTT_PASS   ""                   // Пароль mqtt-пользователя (!!! укажите пароль вашего соединения - зарегистрируйтесь на mqtt.by -> смотрите в личном кабинете !!!)
#define DEFAULT_MQTT_PORT   1883                 // Порт mqtt-соединения
#define DEFAULT_MQTT_PREFIX "af7cd12a"           // Префикс топика сообщения уникальный для вашего устройства
#endif
#define EEPROM_MAX    4096       // Максимальный размер EEPROM доступный для использования
#define EFFECT_EEPROM  400       // Начальная ячейка eeprom с параметрами эффектов, 5 байт на эффект
#define TEXT_EEPROM   1000       // Начальная ячейка eeprom с текстом бегущих строк
#define BRIGHTNESS      32       // Яркость матрицы по-умолчанию 0..255
#define TIME_ZONE        7           // Смещение часового пояса от UTC
#define WEATHER_REGION_YDX 62        // Код региона погоды по Yandex
#define WEATHER_REGION_OWTH 1502026  // Код региона погоды по OpenWeatherMap
static const char WTR_LANG_YA[]  = "ru";      // Яндекс.Погода - кажется понимает только "ru" и "en"
static const char WTR_LANG_OWM[] = "ru";      // OpenWeatherMap = 2-[ бкувенный код языка - ru,en,de,fr,it и так далее. Если язык не знает - возвращает как для en
#if (USE_SD == 1)
#define EFFECT_LIST F("Часы,Лампа,Снегопад,Кубик,Радуга,Пейнтбол,Огонь,The Matrix,Шарики,Звездопад,Конфетти," \
                      "Цветной шум,Облака,Лава,Плазма,Радужные переливы,Павлин,Зебра,Шумящий лес,Морской прибой,Смена цвета," \
                      "Светлячки,Водоворот,Циклон,Мерцание,Северное сияние,Тени,Лабиринт,Змейка,Тетрис,Арканоид," \
                      "Палитра,Спектрум,Синусы,Вышиванка,Дождь,Камин,Стрелки,Анимация,Погода,Жизнь,Узоры,Рубик,Звёзды,Штора,Трафик," \
                      "Фейерверк,Поток,Полосы,Слайды,Рассвет,SD-Карта")
#else
#define EFFECT_LIST F("Часы,Лампа,Снегопад,Кубик,Радуга,Пейнтбол,Огонь,The Matrix,Шарики,Звездопад,Конфетти," \
                      "Цветной шум,Облака,Лава,Плазма,Радужные переливы,Павлин,Зебра,Шумящий лес,Морской прибой,Смена цвета," \
                      "Светлячки,Водоворот,Циклон,Мерцание,Северное сияние,Тени,Лабиринт,Змейка,Тетрис,Арканоид," \
                      "Палитра,Спектрум,Синусы,Вышиванка,Дождь,Камин,Стрелки,Анимация,Погода,Жизнь,Узоры,Рубик,Звёзды,Штора,Трафик," \
                      "Фейерверк,Поток,Полосы,Слайды,Рассвет")
#endif
#define MC_CLOCK                 0         // Режим отображения часов (когда "Ночные часы" или просто "Часы" на черном фоне, а не как оверлей поверх других эффектов
#define MC_FILL_COLOR            1
#define MC_SNOW                  2
#define MC_BALL                  3
#define MC_RAINBOW               4
#define MC_PAINTBALL             5
#define MC_FIRE                  6
#define MC_MATRIX                7
#define MC_BALLS                 8
#define MC_STARFALL              9
#define MC_SPARKLES             10
#define MC_NOISE_MADNESS        11
#define MC_NOISE_CLOUD          12
#define MC_NOISE_LAVA           13
#define MC_NOISE_PLASMA         14
#define MC_NOISE_RAINBOW        15
#define MC_NOISE_RAINBOW_STRIP  16
#define MC_NOISE_ZEBRA          17
#define MC_NOISE_FOREST         18
#define MC_NOISE_OCEAN          19
#define MC_COLORS               20
#define MC_LIGHTERS             21
#define MC_SWIRL                22
#define MC_CYCLON               23
#define MC_FLICKER              24
#define MC_PACIFICA             25
#define MC_SHADOWS              26
#define MC_MAZE                 27
#define MC_SNAKE                28
#define MC_TETRIS               29
#define MC_ARKANOID             30
#define MC_PALETTE              31
#define MC_ANALYZER             32
#define MC_PRIZMATA             33
#define MC_MUNCH                34
#define MC_RAIN                 35
#define MC_FIRE2                36
#define MC_ARROWS               37
#define MC_IMAGE                38
#define MC_WEATHER              39
#define MC_LIFE                 40
#define MC_PATTERNS             41
#define MC_RUBIK                42
#define MC_STARS                43
#define MC_STARS2               44
#define MC_TRAFFIC              45
#define MC_FIREWORKS            46
#define MC_PRIZMATA2            47
#define MC_SHADOWS2             48
#define MC_SLIDE                49
#define MC_DAWN_ALARM           50
#define MC_SDCARD               51
#if (USE_SD == 1)
#define MAX_EFFECT              52         // количество эффектов, определенных в прошивке
#else
#define MAX_EFFECT              51         // количество эффектов, определенных в прошивке
#endif
#define MAX_SPEC_EFFECT         11         // количество эффектов быстрого доступа определенных в прошивке -> 0..10
#define SPECIAL_EFFECTS_START  120         // Некоторые специальные "служебные" эффекты имеют код >= SPECIAL_EFFECTS_START
#define MC_DRAW                123         // Режим рисования картинки на телефоне
#define MC_LOADIMAGE           124         // Режим загрузки изображения с телефона
#define MC_TEXT                125         // Режим бегущей строки (для отображения IP адреса) - бегущая строка на черном фоне
#define MC_DAWN_ALARM_SPIRAL   126         // Специальный режим, вызывается из DEMO_DAWN_ALARM для ламп на круговой матрице - огонек по спирали
#define MC_DAWN_ALARM_SQUARE   127         // Специальный режим, вызывается из DEMO_DAWN_ALARM для плоских матриц - огонек по спирали на плоскости матрицы
enum  eModes   {NORMAL, COLOR, TEXT}   parseMode; // Текущий режим парсера
enum  eSources {NONE, BOTH, UDP, MQTT} cmdSource; // Источник команды; NONE - нет значения; BOTH - любой, UDP-клиент, MQTT-клиент
#if (USE_MP3 == 1)
#define ALARM_SOUND_LIST   F("One Step Over,In the Death Car,Труба зовет,Маяк,Mister Sandman,Шкатулка,Banana Phone,Carol of the Bells")
#define DAWN_SOUND_LIST    F("Птицы,Гроза,Прибой,Дождь,Ручей,Мантра,La Petite Fille De La Mer")
#define NOTIFY_SOUND_LIST  F("Piece Of Сake,Swiftly,Pristine,Goes Without Saying,Inflicted,Eventually,Point Blank,Spring Board," \
                             "To The Point,Serious Strike,Jingle Bells,Happy New Year,Christmas Bells,Door Knock,Alarm Signal," \
                             "Viber Message,Viber Call,Text Message,Old Clock 1,Old Clock 2,Old Clock 3")
#endif
#define D_CLOCK_SPEED 254                   // скорость перемещения эффекта часов по умолчанию (мс) - если больше 240 - часы стоят, не прокручиваются
#define D_CLOCK_SPEED_MIN 2
#define D_CLOCK_SPEED_MAX 254
uint8_t CLOCK_SIZE = 0;                     // Размер горизонтальных часов: 0 - авто; 1 - цифры 3x5; 2 - цифры 5х7
uint8_t CLOCK_ORIENT = 0;                   // Ориентация отображения часов: 0 горизонтальные, 1 вертикальные (только для режима часов с цифрами 3х5; Часы шрифтом 5x7 всегда горизонтальные
uint8_t CLOCK_MOVE_DIVIDER = 3;             // Делитель такта таймера эффектов для движения часов оверлея (режим прокручивания часов по горизонтали)
uint8_t CLOCK_MOVE_CNT = CLOCK_MOVE_DIVIDER;// Текущее значения счетчика сдвига
uint8_t clockScrollSpeed = D_CLOCK_SPEED;   // Скорость прокрутки часов
uint8_t c_size = 0;                         // тип часов: 0 - авто; 1 - шрифт 3x5; 2 - шрифт 5х7; вычисляется в зависимости от настроек и параметров матрицы
bool allow_two_row = false;                 // высота матрицы позволяет размещать календарь и часы с температурой в две строки
bool time_h12 = false;                      // Время - в 12-часовом формате
uint8_t  CALENDAR_X;                        // Позиция вывода календаря по X
uint8_t  CALENDAR_Y;                        // Позиция вывода календаря по Y
uint8_t  CLOCK_X;                           // Позиция вывода часов по X
uint8_t  CLOCK_Y;                           // Позиция вывода часов по Y
int8_t   CLOCK_WX;                          // Позиция вывода погоды по X в малых часах / Реальная ширина отрисованных часов в больших часах
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

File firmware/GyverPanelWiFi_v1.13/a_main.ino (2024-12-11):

// ----------------------------------------------------

// Контроль времени цикла
uint32_t last_ms = millis();  
int32_t ccnt;

// Отладка приема пакетов E1.31
#if (USE_E131 == 1)
bool flag_1 = false;
bool flag_2 = false;
#endif

void process() {  

  // Время прохода одного цикла  
  uint16_t duration = millis() - last_ms;
  
  if (duration > 0) {
    last_ms = millis();
    //DEBUG(F("duration="));
    //DEBUGLN(duration);
  }
  
  // принимаем данные
  parsing();

  #if (USE_E131 == 1)
    streaming = e131 != NULL && (workMode == MASTER || (workMode == SLAVE && (e131_wait_command || ((!e131->isEmpty() || (millis() - e131_last_packet <= E131_TIMEOUT)))))); 
    if (!e131_streaming && streaming) {
      flag_1 = false;
      flag_2 = false;

      // Передать на ведомые устройства группы начальные установочные параметры синхронизации
      if (workMode == MASTER) {
        DEBUGLN(F("Запуск вещания E1.31 потока"));
        commandSetDimension(pWIDTH, pHEIGHT);
        commandTurnOnOff(isTurnedOff);
        commandSetBrightness(globalBrightness);
        commandSetSpecialBrightness(specialBrightness);
        if (syncMode == COMMAND) {
          commandSetCurrentTime(hour(), minute(), second(), day(), month(), year());
          commandSetGlobalColor(globalColor);
          commandSetTextSpeed(textScrollSpeed);
          commandSetClockSpeed(clockScrollSpeed);
          if (specialMode)
            commandSetSpecialMode(specialModeId);
          else
            commandSetMode(thisMode);
        }
      } else {
        masterWidth = 0;
        masterHeight = 0;
        if (syncMode == COMMAND)
          DEBUGLN(F("Ожидание поступления потока команд E1.31...\n"));        
        else
          DEBUGLN(F("Ожидание поступления потока данных E1.31...\n"));        
      }

      prevWorkMode = workMode;
      prevSyncMode = syncMode;
      prevSyncGroup = syncGroup;
      
      #if (USE_MQTT == 1)
        DynamicJsonDocument doc(256);
        String out;
        doc["act"]   = F("E131");
        doc["mode"]  = workMode == MASTER ? F("MASTER") : F("SLAVE");
        doc["type"]  = syncMode == PHYSIC ? F("PHYSIC") : (syncMode == LOGIC ? F("LOGIC"): F("COMMAND"));
        doc["group"] = syncGroup;
        doc["run"]   = true;
        serializeJson(doc, out);      
        SendMQTT(out, TOPIC_E131);
      #endif
      FastLED.clear();
    }
    if (e131_streaming && !streaming) {
      if (prevWorkMode == MASTER)
        DEBUGLN(F("Останов вещания E1.31 потока"));
      else
        DEBUGLN(F("Останов слушателя E1.31 потока"));            
      #if (USE_MQTT == 1)
        DynamicJsonDocument doc(256);
        String out;
        doc["act"]   = F("E131");
        doc["mode"]  = prevWorkMode == MASTER ? F("MASTER") : F("SLAVE");
        doc["type"]  = prevSyncMode == PHYSIC ? F("PHYSIC") : (prevSyncMode == LOGIC ? F("LOGIC"): F("COMMAND"));
        doc["group"] = prevSyncGroup;
        doc["run"]   = false;
        serializeJson(doc, out);      
        SendMQTT(out, TOPIC_E131);
      #endif
    }
    e131_streaming = streaming;
  #endif


  // Если включен эффект с кодом большим кол-ва эффектов (но меньшим кода специальных эффектов) - 
  // выбрать случайный эффект, иначе будет отображаться черный экран или застывший предыдущий эффект
  if (thisMode >= MAX_EFFECT && thisMode < SPECIAL_EFFECTS_START) {
    setRandomMode(); 
  }

  // Эффект сменился?  tmpSaveMode - эффект, который был на предыдущем шаге цикла, thisMode - текущий эффект
  if (tmpSaveMode != thisMode) {
    if (effect_name.length() == 0) {
      // Если режим отсутствует в списке эффектов - имя пустое - включить случайный, 
      // на следующем цикле tmpSaveMode != thisMode - имя будет определено снова
      setRandomMode(); 
    } else {
      #if (USE_E131 == 1)
      if (!(e131_streaming && workMode == SLAVE)) {
      #endif  
        #if (USE_MQTT == 0)
        DEBUGLN(String(F("Режим: ")) + effect_name);
        #else
        if (!useMQTT || !mqtt.connected()) {
          DEBUGLN(String(F("Режим: ")) + effect_name);
        }      
        #endif
      #if (USE_E131 == 1)
      }
      #endif
      tmpSaveMode = thisMode;    
    }               
  }

  // на время принятия данных матрицу не обновляем!
  if (!parseStarted) {

    // Раз в час выполнять пересканирование текстов бегущих строк на наличие события непрерывного отслеживания.
    // При сканировании события с нечеткими датами (со звездочками) просматриваются не далее чем на сутки вперед
    // События с более поздним сроком не попадут в отслеживание. Поэтому требуется периодическое перестроение списка.
    // Сканирование требуется без учета наличия соединения с интернетом и значения флага useNTP - время может быть установлено вручную с телефона
    if (init_time && (millis() - textCheckTime > SECS_PER_HOUR * 1000L)) {
      rescanTextEvents();
    }

    if (wifi_connected) {

      // Если настройки программы предполагают синхронизацию с NTP сервером и время пришло - выполнить синхронизацию
      if (useNtp) {
        if ((ntp_t > 0) && getNtpInProgress && (millis() - ntp_t > 5000)) {
          DEBUGLN(F("Таймаут NTP запроса!"));
          ntp_cnt++;
          getNtpInProgress = false;
          if (init_time && ntp_cnt >= 10) {
            DEBUGLN(F("Не удалось установить соединение с NTP сервером."));  
            refresh_time = false;
          }
          
          #if (USE_MQTT == 1)
          DynamicJsonDocument doc(256);
          String out;
          doc["act"]         = F("TIME");
          doc["server_name"] = ntpServerName;
          doc["server_ip"]   = timeServerIP.toString();
          doc["result"]      = F("TIMEOUT");
          serializeJson(doc, out);      
          SendMQTT(out, TOPIC_TME);
          #endif
        }
        
        bool timeToSync = ntpSyncTimer.isReady();
        if (timeToSync) { ntp_cnt = 0; refresh_time = true; }
        if (timeToSync || (refresh_time && (ntp_t == 0 || (millis() - ntp_t > 30000)) && (ntp_cnt < 10 || !init_time))) {
          ntp_t = millis();
          getNTP();
        }
      }

      #if (USE_WEATHER == 1)  
        if (useWeather > 0) {   
          // Если настройки программы предполагают получение сведений о текущей погоде - выполнить обновление данных с погодного сервера
          if ((weather_t > 0) && getWeatherInProgress && (millis() - weather_t > 5000)) {
            DEBUGLN(F("Таймаут запроса погоды!"));
            getWeatherInProgress = false;
            weather_cnt++;
            refresh_weather = true; weather_t = 0;
            if (init_weather && weather_cnt >= TRY_GET_WEATHER_CNT) {
              DEBUGLN(F("Не удалось установить соединение с сервером погоды."));  
              refresh_weather = false;
              
              #if (USE_MQTT == 1)
              DynamicJsonDocument doc(256);
              String out;
              doc["act"]    = F("WEATHER");
              doc["region"] = useWeather == 1 ? regionID : regionID2;
              doc["result"] = F("TIMEOUT");
              serializeJson(doc, out);      
              SendMQTT(out, TOPIC_WTR);
              #endif
            }
          }
          
          bool timeToGetWeather = weatherTimer.isReady(); 
          if (timeToGetWeather) { weather_cnt = 0; weather_t = 0; refresh_weather = true; }
          // weather_t - время последней отправки запроса. Запрашивать погоду если weather_t обнулено или если последний (неудачный) запрос произошел не менее чем минуту назад
          // иначе слишком частые запросы нарушают коммуникацию с приложением - устройство все время блокирующе запрашивает данные с сервера погоды
          if (timeToGetWeather || (refresh_weather && (weather_t == 0 || (millis() - weather_t > 60000)) && (weather_cnt < TRY_GET_WEATHER_CNT || !init_weather))) {            
            weather_t = millis();
            getWeatherInProgress = true;
            getWeather();
            if (weather_cnt >= TRY_GET_WEATHER_CNT) {
              if (init_weather) {
                udp.flush();
              } else {
                weather_cnt = 0;
              }
            }        
          }
        }
      #endif
    } 

    #if (USE_WEATHER == 1)  
      // Если погода не смогла обновиться дважды за период обновления погоды + 30сек "запаса" - считать погоду неинициализированной и не отображать погоду в часах
      if (useWeather > 0 && init_weather && (millis() - weather_time > weatherActualityDuration * 3600L * 1000L)) {
        init_weather = false;
        refresh_weather = true;
      }
    #endif
    
    if (init_time && !(wifi_connected && useNtp)) {
      // Если нет соединения WiFi (возможно работает в режиме AP) - вместо запроса текущего времени интернета
      // выполнить (пере)расчет времени рассвета, т.к. если рассвет выключить вручную до наступления времени будильника -
      // следующее время рассвета считается неправильно. В часах без подключения к интернету и синхронизации времени с NTP сервера
      // рассвет на следующий день не срабатывает, т.к. рассчитан неправильно
      bool timeToSync = ntpSyncTimer.isReady();
      if (timeToSync) calculateDawnTime();
    }

    bool needProcessEffect = true;

    #if (USE_E131 == 1)
        
    // Если сработал будильник - отрабатывать его эффект, даже если идет стриминг с мастера    
    if (workMode == SLAVE && (e131_streaming || e131_wait_command) && (!(isAlarming || isPlayAlarmSound))) {      
      needProcessEffect = e131_wait_command;
      // Если идет прием потока данных с MASTER-устройства - проверить наличие пакета от мастера
      if (e131 && !e131->isEmpty()) {
        // Получен пакет данных. 
        e131_last_packet = millis();
        e131->pull(&e131_packet);        
        
        idleTimer.reset();
        
        uint16_t CURRENT_UNIVERSE = htons(e131_packet.universe);      

        /*
        // Отладка: информация о полученном E1.31 пакете
        Serial.printf("Universe %u / %u Channels | Packet#: %u / Errors: %u\n",
                  CURRENT_UNIVERSE,                            // The Universe for this packet
                  htons(e131_packet.property_value_count) - 1, // Start code is ignored, we're interested in dimmer data
                  e131->stats.num_packets,                     // Packet counter
                  e131->stats.packet_errors);                  // Packet error counter
        */     
             
        /*
        // Отладка: вывод данных структуры полученного пакета E1.31 для первых двух вселенных
        if (!flag_1 && CURRENT_UNIVERSE == 1 || !flag_2 && CURRENT_UNIVERSE == 2) {
          printE131packet(&e131_packet);
          flag_1 |= CURRENT_UNIVERSE == 1;
          flag_2 |= CURRENT_UNIVERSE == 2;
        }
        */

        /*
            Serial.print(CURRENT_UNIVERSE);
            Serial.print(",");
            ccnt++; 
            if (ccnt>60) {
              Serial.println();
              ccnt=0;
            }
        */

        bool isCommand = isCommandPacket(&e131_packet);
        if (isCommand && syncMode == COMMAND) e131_wait_command = true;

        // Если задан расчет FPS выводимых данных потока E1.31 - рассчитать и вывести в консоль
        if (syncMode != COMMAND && E131_FPS_INTERVAL > 0) {
          if (CURRENT_UNIVERSE == START_UNIVERSE && !isCommand) frameCnt++;
          if (millis() - last_fps_time >= E131_FPS_INTERVAL) {
            last_fps_time = millis();
            DEBUG(F("FPS: "));
            DEBUGLN(1000.0 * frameCnt / E131_FPS_INTERVAL);
            frameCnt = 0;
          }
        }

        // Если пакет содержит команду - обработать ее
        if (isCommand) {
          processCommandPacket(&e131_packet);          
          needProcessEffect = syncMode == COMMAND;
        } else
        // Если режим стрима - PHYSIC или LOGIC - вывести принятые данные на матрицу
        // Физический вывод на матрицу выполнять при получении ПЕРВОГО (НАЧАЛЬНОГО) пакета группы,
        // подразумевая что на предыдущем шаге все принятые пакеты уже разобраны и цвета помещены в массив leds[] - то есть полный кадр сформирован        
        // Для всех остальных пакетов - просто разбирать их и помещать принятые данные части кадра в массив leds[];
        // Если дожидаться последнего пакета группы и только потом выводить - для MASTER матриц чей размер меньше SLAVE - последний пакет не придет никогда
        // и будет создаваться впечатление "зависшей" матрицы - нет вывода. Конечно, в этом случае при несовпадении размеров матриц MASTER и SLAVE
        // быдет выведена "каша", но хотя бы видно, что устройство не зависло...
        if (syncMode == PHYSIC || syncMode == LOGIC) {
          if (CURRENT_UNIVERSE == START_UNIVERSE) FastLED.show();
          drawE131frame(&e131_packet, syncMode);
        }
      }
    }

    #endif

    if (needProcessEffect) {
      // Сформировать и вывести на матрицу текущий демо-режим
      // При яркости = 1 остаются гореть только красные светодиоды и все эффекты теряют вид.
      // поэтому отображать эффект "ночные часы"
      uint8_t br = specialMode ? specialBrightness : globalBrightness;
      if (br == 1 && !(loadingFlag || isAlarming || thisMode == MC_TEXT || thisMode == MC_DRAW || thisMode == MC_LOADIMAGE)) {
        if (allowHorizontal || allowVertical) 
          customRoutine(MC_CLOCK);    
        else
          FastLED.clear();  
      } else {    
        customRoutine(thisMode);
      }
    }
    
    clockTicker();
    
    #if (USE_TM1637 == 1)
      if (lastDisplay[0] != currDisplay[0] || lastDisplay[1] != currDisplay[1] || lastDisplay[2] != currDisplay[2] || lastDisplay[3] != currDisplay[3]) {
        display.displayByte(currDisplay[0], currDisplay[1], currDisplay[2], currDisplay[3]);
        lastDisplay[0] = currDisplay[0];
        lastDisplay[1] = currDisplay[1];
        lastDisplay[2] = currDisplay[2];
        lastDisplay[3] = currDisplay[3];
      }
      if (lastDotState != currDotState) {
        display.point(currDotState);
        lastDotState = currDotState;
      }
      if (lastDisplayBrightness != currDisplayBrightness) {
        display.setBrightness(currDisplayBrightness);
        lastDisplayBrightness = currDisplayBrightness;
      }
    #endif    

    checkAlarmTime();
    checkAutoMode1Time();
    checkAutoMode2Time();
    checkAutoMode3Time();
    checkAutoMode4Time();
    #if (USE_WEATHER == 1)      
    checkAutoMode5Time();
    checkAutoMode6Time();
    #endif  

    butt.tick();  // обязательная функция отработки. Должна постоянно опрашиваться
    uint8_t clicks = 0;

    // Один клик
    if (butt.isSingle()) clicks = 1;    
    // Двойной клик
    if (butt.isDouble()) clicks = 2;
    // Тройной клик
    if (butt.isTriple()) clicks = 3;
    // Четверной и более клик
    if (butt.hasClicks()) clicks = butt.getClicks();

    // Максимальное количество нажатий - 5-кратный клик
    // По неизвестными причинам (возможно ошибка в библиотеке GyverButtons) 
    // getClicks() возвращает 179, что абсолютная ерунда
    if (clicks > 4) clicks = 0;
    
    if (butt.isPress()) {
      // Состояние - кнопку нажали  
    }
    
    if (butt.isRelease()) {
      // Состояние - кнопку отпустили
      isButtonHold = false;
    }
    
    if (butt.isHolded()) {
      isButtonHold = true;
      if (globalBrightness == 255)
        brightDirection = false;
      else if (globalBrightness == 0)  
        brightDirection = true;
      else  
        brightDirection = !brightDirection;
    }

    if (clicks > 0) {
      DEBUG(F("Кнопка нажата "));  
      DEBUG(clicks);
      DEBUGLN(F(" раз"));  
    }

    // Любое нажатие кнопки останавливает будильник
    if ((isAlarming || isPlayAlarmSound) && (isButtonHold || clicks > 0)) {
      DEBUG(F("Выключение будильника кнопкой."));  
      stopAlarm();
      clicks = 0;
    }

    // Одинарный клик - включить . выключить панель
    if (clicks == 1) {
      turnOnOff();
    }
    
    // Прочие клики работают только если не выключено
    if (isTurnedOff) {
      // Выключить питание матрицы
      #if (USE_POWER == 1)
        if (!isAlarming) {
          digitalWrite(POWER_PIN, POWER_OFF);
        } else {
          digitalWrite(POWER_PIN, POWER_ON);
        }
      #endif      
      //  - длительное нажатие кнопки включает яркий белый свет
      #if (DEVICE_TYPE == 0)
        if (isButtonHold) {
          // Включить панель - белый цвет
          set_specialBrightness(255);
          set_globalBrightness(255);
          set_globalColor(0xFFFFFF);
          isButtonHold = false;
          setSpecialMode(1);
          FastLEDsetBrightness(globalBrightness);
        }
      #else
        // Удержание кнопки повышает / понижает яркость панели (лампы)
        if (isButtonHold && butt.isStep()) {
          processButtonStep();
        }
      #endif      
      
    } else {
      
      // Включить питание матрицы
      #if (USE_POWER == 1)
        digitalWrite(POWER_PIN, POWER_ON);
      #endif
      
      // Был двойной клик - следующий эффект, сброс автоматического переключения
      if (clicks == 2) {
        bool tmpSaveSpecial = specialMode;
        resetModes();  
        setManualModeTo(true);
        if (tmpSaveSpecial) 
          setRandomMode();        
        else 
          nextMode();
      }

      // Тройное нажатие - включить случайный режим с автосменой
      else if (clicks == 3) {
        // Включить демо-режим
        resetModes();          
        setManualModeTo(false);        
        setRandomMode();
      }

      // Если устройство - лампа
      #if (DEVICE_TYPE == 0)
        // Четверное нажатие - включить белую лампу независимо от того была она выключена или включен любой другой режим
        if (clicks == 4) {
          // Включить лампу - белый цвет
          set_specialBrightness(255);
          set_globalBrightness(255);
          set_globalColor(0xFFFFFF);
          setSpecialMode(1);
          FastLEDsetBrightness(globalBrightness);
        }      
        // Пятикратное нажатие - показать текущий IP WiFi-соединения            
        else if (clicks == 5) {
          showCurrentIP(false);
        }      
      #else      
        // Четырехкратное нажатие - показать текущий IP WiFi-соединения            
        else if (clicks == 4) {
          showCurrentIP(false);
        }      
      #endif
      // ... и т.д.
      
      // Обработка нажатой и удерживаемой кнопки
      else if (isButtonHold && butt.isStep() && thisMode != MC_DAWN_ALARM) {      
        // Удержание кнопки повышает / понижает яркость панели (лампы)
        processButtonStep();
      }            
    }
    
    // Проверить - если долгое время не было ручного управления - переключиться в автоматический режим
    if (!(isAlarming || isPlayAlarmSound)) checkIdleState();

    // Если есть несохраненные в EEPROM данные - сохранить их
    if (saveSettingsTimer.isReady()) {
      saveSettings();
    }
  }
}

String getEffectName(int8_t mode) {
  String ef_name = "";
  switch (mode) {
    case MC_CLOCK:      
      if (isNightClock)
        ef_name = F("Ночные часы");
      else
        ef_name = F("Часы");
      break;
    case MC_TEXT:
      ef_name = F("Бегущая строка");
      break;
    case MC_LOADIMAGE:
      ef_name = F("Загрузка изображения");
      break;
    case MC_DRAW:
      ef_name = F("Рисование");
      break;
    case -1:      
      ef_name = "";
      break;
    default:
      // Определить какой эффект включился
      String s_tmp = String(EFFECT_LIST);    
      uint16_t len1 = s_tmp.length();
      s_tmp = GetToken(s_tmp, thisMode+1, ',');
      uint16_t len2 = s_tmp.length();
      if (len1 > len2) { 
        ef_name = s_tmp;
      } else {
        // Если режим отсутствует в списке эффектов - имя не определено
        ef_name = "";
      }    
      break;
  }
  return ef_name;
}

void processButtonStep() {
  if (brightDirection) {
    if (globalBrightness < 10) set_globalBrightness(globalBrightness + 1);
    else if (globalBrightness < 250) set_globalBrightness(globalBrightness + 5);
    else {
      set_globalBrightness(255);
    }
  } else {
    if (globalBrightness > 15) set_globalBrightness(globalBrightness - 5);
    else if (globalBrightness > 1) set_globalBrightness(globalBrightness - 1);
    else {
      set_globalBrightness(1);
    }
  }
  set_specialBrightness(globalBrightness);
  if (!isTurnedOff) FastLEDsetBrightness(globalBrightness);    
}

// ********************* ПРИНИМАЕМ ДАННЫЕ **********************
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

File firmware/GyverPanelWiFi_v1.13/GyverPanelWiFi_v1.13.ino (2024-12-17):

// Гайд по постройке матрицы: https://alexgyver.ru/matrix_guide/
// Страница проекта на GitHub: https://github.com/vvip-68/GyverPanelWiFi
// Автор идеи, начальный проект - GyverMatrixBT: AlexGyver Technologies, 2019 (https://alexgyver.ru/gyvermatrixbt/)
// Дальнейшее развитие: vvip-68, 2019-2024
// https://AlexGyver.ru/
//
// Дополнительные ссылки для Менеджера плат ESP8266 и ESP32 в Файл -> Настройки
// https://raw.githubusercontent.com/esp8266/esp8266.github.io/master/stable/package_esp8266com_index.json
// https://raw.githubusercontent.com/espressif/arduino-esp32/gh-pages/package_esp32_index.json

//#pragma GCC optimize ("O1")
//#pragma GCC optimize ("O2")

#define FIRMWARE_VER F("WiFiPanel v.1.13.2024.1217")

// -------------------------------------------------------------------------------------------------------
//
// Внимание!!!
// Проект разрабатывался и тестировался для плат разработчика на базе 
//   ESP8266 - 'NodeMCU ESP-12 DevKit v1.0' с CH340, CH341, CP2102, 'Wemos d1 mini' различных вариаций - у них у всех одинаковое назначение пинов
//   ESP32   - 'ESP32-WROOM-32 DevKit' 30,32,38-pin - у них одинаковое назначение пинов, но возможно не все выведены на гребенку
//
// Проверена и рекомендлвано к использованию ESP32-плата типа этих:
// https://aliexpress.ru/item/1005004605399313.html  ( ESP32-WROOM-32 )
// https://aliexpress.ru/item/32836372640.html       ( ESP32 D1 Mini  )
//
// Для остальных плат потребуется перепроверка назначения пинов с выяснением какие комбинации работают, а какие нет.
// Внимание!!!
// Рабочие комбинации версий ядра и библиотек:
//
// Версия ядра ESP8266 - 3.1.2   
// Версия ядра ESP32   - 2.0.17
// Версия FastLED      - 3.7.0  // 3.6.0   - смотри комментарий ниже в секции *** FastLED
// 
// Альтернативные варианты для ESP8266
// Версия ядра ESP8266 - 2.7.4  // Наиболее стабильная по выводу изображения на матрицу без артефактов и подергиваний   
// Версия FastLED      - 3.5.0  // 3.6.0 / 3.7.0  - смотри комментарий ниже в секции *** FastLED
//
// Для версии ядра ESP8266 3.1.2
//   Плату выбираем реально которую используете - для NodeMCU - "NodeMCU 1.0 (ESP12E Module)", для Wemos d1 mini - "LOLIN(WEMOS) D1 mini (clone)"
//   Пин вывода на ленту в конфигурации по умолчанию LED_PIN обозначен как D2 (GPIO4) - вывод идет на D2
//
// Для версии ядра ESP8266 2.7.4
//   Плату выбираем реально которую используете - для NodeMCU - "NodeMCU 1.0 (ESP12E Module)", для Wemos d1 mini - "LOLIN(WEMOS) D1 R2 & mini"
//   Пин вывода на ленту в конфигурации по умолчанию LED_PIN обозначен как D2 (GPIO4) - вывод идет на D2
//
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

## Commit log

2020-07-27 Исправлено описание проекта
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2020-07-29 Эффекты "Пейнтбол" и "Водоворот" исправлены для работы с неквадратными матрицами (два режима - растягивать / повторять квадратные сегменты)
    [clock.ino, effects.ino]
2020-07-29 ффекты "Пейнтбол" и "Водоворот" исправлены для работы с неквадратными матрицами. Два режима - растягивать или повторять квадратные сегменты.
    [eeprom.ino, effects.ino]
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2020-07-30 Исправлено - бегущая строка "дергалась" если установлена максимальная скорость прокрутки часов
    [a_def_soft.h, custom.ino]
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2020-08-02 Добавлена возможность регулировки яркости (контрастности) эффектов относительно яркости часов / бегущей строки
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2020-08-02 После смены IP адреса из приложения установленный IP адрес отображается на матрице для контроля
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2020-08-04 Эффект Циклон; Настройки в программе (разрашение часов и бегущей строки для эффекта)
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2020-08-05 Исправлен Тетрис
2020-08-05 Исправлено сохранение строк в EEPROM
    [eeprom.ino]
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2020-08-08 Автосмена в демо-режиме в играх Лабиринт и Тетрис, а также в режиме бегущей строки - только после завершения игры или после того как строка "прокрутится"до конца.
2020-08-09 Режимы "Часы" и "Часы с датой" убраны из списка доступных в приложении Роведение кнопки немного изменяется в зависимости от того как обозначено устройство - панель или лампа
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2020-08-16 Исправлены мелкие ошибки, выявленные по ходу тестирования
    [custom.ino]
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2020-08-17 Для ESP8266 может быть использована аппаратная инициализация random seed? что обещает более качественную рандомизацию
2020-08-17 Бегущая строка отключена если текущий режим "Ночные часы или "Выключено" Исправлено - не отображался текущий IP по запросу Исправлено - Включение программы на телефоне сбрасывало режим "Ночные часы"
    [a_def_soft.h, a_main.ino, custom.ino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]
2020-08-18 Добавлены эффекты "Синусы" и "Вышиванка" Исправлены некоторые проблемы с загрузеой / сохранением строк текста эффекта "Бегущая строка"
    [a_def_hard.h, a_def_soft.h, a_main.ino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]
2020-08-18 Исправлено: не включался режим "Ночные часы"
    [custom.ino]
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2020-08-19 Исправлена инициализация параметров эффекта "Будильник-рассвет"
    [effects.ino]
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2020-08-22 Поддержка нескольких макросов цвета в бегущей строке Это позволяет выделять части текста в строке различными цветами
2020-08-22 Температуру в бегущей строке по макросу {WT} выводить цветом, в зависимости от значения температуры
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2020-08-24 Переработан вывод анимированных картинок (Режим "Анимация" (MC_IMAGE)) Если размер картинки меньше размера матрицы - можно двигать картинку по матрице одновременно с анимацией
2020-08-24 В качестве фона для анимации (картинки) можно использовать другой эффект Если фоном использовать эффект "Огонь", а анимацию - "Марио" - Марио будет бегать по пожару. "Кубик" - "играть" в футбол, "Сне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
2020-08-26 Добавлен эффект "Погода". При наличии данных о текущей погоде - отображает ее, если погода не загружена или отключена - просто слайд-шоу картинок погоды
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2020-08-28 Мелкие исправления
2020-08-29 Исправление неразберихи переключения авто/ручной режим
    [a_def_soft.h, a_main.ino, clock.ino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]
2020-08-29 Исправлено: добавление нового соединения заменяло существующее.
2020-08-30 FAQ: В Украние погода работать будет? Как узнать код для моего города?
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2020-09-01 Добавлено отображение текущей температуры вместе с часами Включается в приложении в настройках часов - чекбокс "Показывать дату и температуру в малых часах" Работает на горизонтальных малых часах, ес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
2020-09-01 Исправлена позиция отображения малых часов на матрицах 16x16
    [a_def_hard.h, clock.ino]
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2020-09-01 Добавлен узор "Снежинка" к эффекту "Узоры" Добавлено вспомогательное средство для создания узоров
    [pattern-creator.xlsx]
2020-09-03 Добавлена поддержка загрузки эффектов с SD-карты. Эффекты подготавливаются в программу "Jinx!" и сохраняются на SD-карту в формате Glediator (файлы *.out)
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2020-09-03 Подправлены параметры для эффекта "SD-карта"; Добавлены мримеры эффектов экспортированных из Jinx для матриц 16х16
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2020-09-04 Добавлена схема решения питания системы МК-матрица, позволяющая стабильно работать при напряжении с БП до 5.5-6.0 вольт (ранее - 4.0-4.8 вольт)
2020-09-04 Выгрузка версии 1.0.4; Более ранние версии удалены из архива. Загрузить их можно по тагам релизов
2020-09-04 Исправлена схема подключения SD-карты
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2020-09-08 Зацикливать эффекты Jinx (по окончании фрагмента воспроизводить его заново) Это позволяет на коротких роликах получать долгоиграющие эффекты.
2020-09-08 fix Loading flag reset on SD-card effect
    [sdcard.ino]
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2020-09-09 Искусственно увеличена вероятность выпадения эффекта с SD-карты, если стоит флажок "Случайный выбор эффекта"
2020-09-09 Модификатор текста бегущей строки {ENN} теперь может содержать вариант эффекта {ENN-XX} Это полезно например для эффекта с SD-карты MC_SDCARD указать какой именно "ролик" воспроизводить
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2020-09-11 Добавлена утилита просмотра и "подрезания" файлов для воспроизведения их на матрице с SD-карты Файлы захватываются утилитой Jinx! v сохраняются в формате Glediator (*.out)
2020-09-15 Исправлены некоторые Warnings, трактуемые компилятором как ошибки при соответствующих настройках компиляции
    [GyverPanelWiFi_v1.04.ino, a_def_hard.h, a_main.ino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]
2020-09-17 SketchUp модель корпуса / рамки панели размером 50x20, ячейка 35(39) мм
    [Рамка-корпус-панели-50x20.skp]
2020-09-18 Исправлен эффект "Вышиванка" - шумовые эффекты портили палитру и после них Вышиванка работала криво
    [effects.ino]
2020-09-18 Увеличен таймаут ожидания сети WiFi до 180 секунд При отключении электричества, после включения устройство загружалось быстрее чем роутер создавал сеть. Вместо подключения к сети создавалась точка до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
2020-09-18 Имя хоста для OTA включает ID устройства - иначе из всего семейства Arduino IDE видит только одно устройство.
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2020-09-25 Имправлена ошибка, приводящая к перезагрузке устройства в некоторых случаях при отображении бегущей строки, имеющей внутри макрос, задающий цвет текста отдельного слова.
2020-09-25 Исправлено описание номера эффекта "SD-карта"/"Рассвет"
2020-09-25 Исправлены опечатки
2020-09-29 Код региона погоды увеличен с uint16_t до uint32_t, т.к коды некоторых регионов превышают 65535
2020-09-30 Параметр "Использовать цвет" для отображения температуры в часах разделен на два - для ночных и дневных часов отдельно
2020-10-01 Внутр.: Изменен механизм формирования строки ответа с текущими параметрами в приложение на смартфоне. Подготовка к добавлению управления через MQTT
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2020-10-06 Wiki - исправления в API
2020-10-06 Исправлено зацикливание разбора NTP пакета времени; Исправления в обработке команд из MQTT канала
    [a_def_soft.h, a_main.ino]
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2020-10-08 Исправлена компиляция при USE_MP3 == 1; Исправлен вывод отрицательных температур.
    [a_def_soft.h, clock.ino, weather.ino]
2020-10-08 Исправлена компиляция при USE_TM1637 == 1
    [a_def_hard.h, clock.ino]
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2020-10-09 Эффект "Камин" - убраны регулировки скорости и вариации как неэффективные; Исправлен эффект Диагональная радуга на вертикальных матрицах
    [a_def_hard.h, a_main.ino, effects.ino]
2020-10-09 Исправлена вероятная ошибка "вылета" эффекта "Палитра" на матрицах с размерами, не кратными размеру блока
    [a_def_hard.h, effects.ino]
2020-10-09 Исправлена передача значения параметра "Авторежим через" из прошивки в приложение на телефоне
    [a_main.ino, effects.ino]
2020-10-09 Исправлена некорректная работа эффекта "Палитра" на неквадратных матрицах
    [effects.ino]
2020-10-10 Исправлена компиляция при DEVICE_TYPE == 0
    [a_main.ino]
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2020-10-11 Бегущая строка, макрос {WT} - исправлено задваивание знака '-' у отрицательных температур
    [runningText.ino]
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2020-10-14 Попытка исправить эффект "Вышиванка", который ломается по неизвестной причине через некоторое время работы.
    [effects.ino]
2020-10-16 Исправлено: В программу на страницу настроек эффекта не передавалось состояние фладка "Текст поверх эффекта"
    [a_main.ino]
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2020-10-24 Исправлено: вывод неверного текста в строке с событием, когда событие уже прошло.
    [a_def_hard.h, custom.ino, runningText.ino]
2020-10-25 Исправлено: отображение IP адреса подклюения к сети WiFi по 4/5-кратному нажатию кнопки
    [a_main.ino, custom.ino, runningText.ino]
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2020-10-30 Исправлено: При отсутствии разрешенных к отображению строк (все строки отключены) все равно отабражалсь строка из позиции 1;
    [a_main.ino, custom.ino, eeprom.ino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]
2020-11-01 Исправлено: в игре "Жизнь" счетчик поколений выводился некорректно на матрицах с некоторой шириной.
    [g_life.ino]
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2020-11-03 Исправление текста документации
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2020-11-03 Эффект "Погода" исправлен выбор картинки для кода 800-803, а также при включении эффекта "Погода" ДО получения данных с сервера
    [weather.ino]
2020-11-03 Эффект "Погода" исправлен выбор картинки при включении эффекта "Погода" ДО получения данных с сервера
    [weather.ino]
2020-11-03 Исправлена компиляция при разных сочетаниях директив компиляции связанных с использованием погоды, исправлен эффект отображения погоды для некоторых кодов и икогок погоды
    [a_def_soft.h, weather.ino]
2020-11-03 Исправлена позиция вывода температуры, когда эффект "Погода" включен до момента получения данных о погоде
    [weather.ino]
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2020-11-16 Исправлено: из прошивки в программу не передавался параметр "Продолжительность рассвета" - он всегда отображался по умолчанию 20 минут, даже если в проошивке было сохранено другое значение
    [a_main.ino]
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2020-11-17 Исправления в программе для смартфона
    [a_main.ino]
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2020-11-18 Исправлено: при вкл/выкл панели кнопкой сбрасывался деморежим в ручной режим
    [a_def_soft.h, a_main.ino, eeprom.ino]
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2020-11-23 Небольшая структурная реорганизация кода, исправлены комментарии, добавлен раздел wiki
    [a_def_hard.h, g_arkanoid.ino, g_maze.ino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]
2020-11-23 Исправлено: проект не собирался, если в главном файде в строке 35 раскомментировано #define public Заменено на #define public_project
    [a_def_hard.h, a_def_soft.h]
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2020-11-27 Исправлена инициализация параметров эффектов при первичной (или после изменения EEPROM_OK) загрузки прошивки
    [a_def_soft.h, eeprom.ino]
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2020-12-01 Очередное исправление 0 при включенной галочке "Авторежим" автоматическая смена эффектов не происходила (иногда, при совпадении некоторых условия. Исправлено.)
    [a_main.ino]
2020-12-01 Очередное исправление - при включенной галочке "Авторежим" автоматическая смена эффектов не происходила (иногда, при совпадении некоторых условия. Исправлено.)
    [eeprom.ino]
2020-12-02 Исправлено: после последних правок про авторежим - ручное включение режима на вкладке Эффекты перестало отключать авторежим Восстановлено - теперь ручное включение режима отключает авторежим.
    [a_main.ino]
2020-12-02 Исправлена ошибка разбора макроса {P} при задании полного набора параметров при наличии подстановки *
    [runningText.ino]
2020-12-03 Исправлено - в схемах с реле - реле подачи питания на матрицу не включалось при срабатывании будильника В сборках с USE_MP3 == 0 не работала кнопка выключения будильника в приложении на смартфоне
    [a_main.ino, clock.ino, runningText.ino]
2020-12-04 1. Исправлена орфография в приложении на смартфоне 2. Добавлена схема для ESP32 + пины подключения 3. Добавлены звуки будильника
    [a_def_hard.h, a_def_soft.h]
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2020-12-04 Приложение для смартфона - исправлено: снятие галочки "Часы поверх эффекта" отрабатывалось неправильно
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2020-12-05 Вариант ESP32 + SD-card - исправлено формирование имени файла эффекта, загружаемого с SD-карты
    [sdcard.ino]
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2020-12-07 Приложение. Исправлено: при активации вкладки настроек эффектов снималась галочка "Автоматическое управление"
2020-12-09 Исправления в комментариях. Ничего существенного. Для DEVICE_ID 4 раскомментированы игры - снова доступны
    [a_def_hard.h, g_arkanoid.ino, g_maze.ino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]
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2020-12-12 Исправлено: Библиотеки для TM1637 включались в компиляцию даже если USE_TM1637 == 0 Небольшие исправления позиционирования малых часов на матрицах с небольшой высотой (11 пикс) Актуализация комментар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
    [a_def_hard.h, clock.ino, custom.ino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]
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2020-12-13 Исправлена ошибка, при которой отключался авторежим, хотя галочка оставалось включенной - просто перестовали автоматически меняться эффекты...
    [a_main.ino]
2020-12-13 Исправлено - значение флажка "Использовать MQTT" не восстанавливалось из сохраненных значений после загрузки данных из EEPROM
    [a_def_hard.h, a_def_soft.h, a_main.ino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]
2020-12-13 Исправлено определение кол-ва эффектов MAX_EFFECT для случая, когда USE_SD 0 или 1
    [a_def_soft.h]
2020-12-14 Исправлено: доступность поля "Время режима"
2020-12-14 Исправлены косяки с бегущей строкой, возникшие после добавления букв украинского алфавита.
    [a_def_soft.h, a_main.ino, mqtt.ino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]
2020-12-14 Исправллено - не собиралась последняя версия при USE_SD 0
    [a_def_soft.h]
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2020-12-18 Исправлено - директивы условной компиляции в зависимости от вкл/выкл оборудования в профиле
    [a_def_hard.h, eeprom.ino, setters.ino]
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2020-12-18 Исправлена возможная проблема при последовательном переборе эффектов, когда очередь доходит до последнего в списке эффекта
    [custom.ino]
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2020-12-19 Исправлена регулировка громкости звука будильника в приложении
    [a_def_hard.h, setters.ino]
2020-12-19 Исправлено - не работали режимы "Рисование" и "Загрузка картинки"
    [a_main.ino, custom.ino, eeprom.ino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]
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2020-12-20 1. В приложение передается список файлов эффектов 2. Изменен алгоритм загрузки строк текста в приложение 3. Исправлен самопроизвольный сброс эффекта в "Часы" при первом входе на закладку "Эффекты" пр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
    [a_def_soft.h, a_main.ino, g_life.ino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]
2020-12-20 Исправление артефактов при выводе счета "игры" эффекта "Жизнь"
    [a_def_hard.h, a_main.ino, g_life.ino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]
2020-12-20 Исправлена сломавшаяся с переходом на 1.08 регулировка индивидуальных параметров эффектов
    [a_def_hard.h, setters.ino]
2020-12-20 Исправлено: изменение параметров режимов по времени не передавались в MQTT-канал; Приложение выдавало ошибку при выборе пустой строки
    [a_def_hard.h, a_def_soft.h, a_main.ino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]
2020-12-21 Исправлене компиляция при установленном SMOOTH_CHANGE 1
    [a_def_soft.h]
2020-12-21 Исправлено - в MQTT не всегда передавалось значение параметра SQ
    [mqtt.ino, setters.ino]
2020-12-21 Исправлено: Приложение на телефоне "вылетало" если заполненно много строк текста бегущей строки при выборе строки, не поместившейся в буфер.
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2020-12-21 Краивости в приложении Исправлена ошибка при входе на страницу текста приложения
    [a_main.ino]
2020-12-22 Канал MQTT - исправлена отдача параметров BE SE
    [setters.ino]
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2020-12-25 Приложение - исправлено: при отсутствующем в настройках IP адреа (пустой) - приложение ерашилось
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2020-12-27 WiFyPlayer - исправлены иконки на кнопках создания/отмены нового подключения
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2020-12-29 Исправлена ошибка расчета времени наступления события и отображения текста для макроса {P} в тексте бегущей строки
    [eeprom.ino, runningText.ino, utility.ino]
2020-12-30 Исправлено: скроллинг больших вертикальных часов - не лоходили до левой границы экрана на 4 точки
    [a_def_hard.h, custom.ino]
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2021-01-05 Исправление компиляции при USE_SD==0
    [custom.ino]
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2021-01-16 Исправлено - сохранение настроек на ESP32
    [eeprom.ino]
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2021-01-22 Исправлена совместная работа макросов бегущей строки {A} и {E}
    [runningText.ino]
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2021-01-22 Исправлена компиляция при USE_WEATHER == 0
    [clock.ino]
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2021-02-11 MQTT: смена бесплатного сервера по умолчанию на "mqtt.iotwithus.com"; Небольшие изменения в библиотеке PubSubClient, исправляющие слишком частые разрывы соединения по критерию keepAlive; Ихменения в 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
    [GyverPanelWiFi_v1.09.ino, a_def_hard.h, a_def_soft.h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]
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2021-02-17 исправление схемы с подтяжкой для соответствия пинам в скетче
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2021-02-19 Эффект "Циклон" - исправлена работа в режиме с сегментами
    [a_def_soft.h, a_main.ino, clock.ino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]
2021-02-19 Исправление в "Змейке" - при длине змейки близкой к максимуму выпадала целая корзинка яблок.
    [g_snake.ino]
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2021-02-21 Попытка исправить эффект "Вышиванка" - не дорисовывался сегмент
    [effects.ino]
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2021-02-25 Исправление ошибок и доработки: - Исправлены проблемы центрирования часов с погодой на разных размерах матриц - Приложение - ошибка при выборе пустой строки - Приложение - добавлена кнопка включения 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
    [a_def_soft.h, a_main.ino, clock.ino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]
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2021-03-26 Исправлено: не работало изменение имени точки доступа.
    [patterns.ino, setters.ino]
2021-03-27 Исправлен сдвиг больших часов при некоторых комбинациях цифр на матрицах шириной 23,24,25 njxtr
    [clock.ino]
2021-03-27 Эффект "Узоры" - исправлено переворачивание эффекта, добавлен выбор направления смещения узоров
    [a_main.ino, patterns.ino]
2021-03-28 Исправлена компиляция при USE_WEATHER 0 Для варианта TM1637 - добавлено периодическое отображение температуры на индикаторе (C) RailWar Evgeny Для устройства типа "лампа" DEVICE_TYPE 0 - в эффекте "П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
    [a_def_soft.h, clock.ino, weather.ino]
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2021-04-03 Исправлено - в режиме точки доступа (AP) без подключения интернета после ручной установки времени с телефона будильники не "подхватывались" и не срабатывали
    [a_main.ino]
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2021-04-08 Исправлено: После выключения устройства по расписанию и последующего включения вручную кнопкой не восстанавливался демо-режим, если он был включен дл отключения устройства.
    [clock.ino]
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2021-05-19 Исправлено отображение больших часов на матрице 32x8
    [clock.ino]
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2021-06-06 Исправил https://github.com/vvip-68/GyverPanelWiFi/issues/139
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2021-08-19 Исправлено - при работе бкз доступа к интернету (синхронизации времени с NTP сервера) после срабатывания рассвета и выключения его вручную на следующий день рассвет не срабатывал
    [a_main.ino]
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2021-10-02 Исправлена ошибка сохранения имени сети (SSID) и пароля к ней на системах ESP32
    [a_def_soft.h, eeprom.ino]
2021-10-03 Чистка репозитория - удалены устаревшие файлы, файлы большого размера перенесены на Google Disk https://drive.google.com/drive/folders/1Xh0CW_GjQMlhbkPjJ34w1UVbuB9aOjP3?usp=sharing
    [Рамка-корпус-панели-50x20.skp]
2021-10-05 Утилита JinxFramer - исправлено сохранение кадра в виде кода в кодировке UTF-8 - убрана метка BOM в начале файла, которая вызывала ошибку при компиляции в IDE 1.8.15
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2021-10-15 Исправлен сломавшийся эффект "Рассвет"
    [GyverPanelWiFi_v1.11.ino, custom.ino]
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2021-10-19 Исправлено редактирование кадра ролика - неправильно сохранялся после редактирования
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2021-10-29 Fix compile for ESP32
    [a_def_hard.h]
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2021-11-02 Исправлен эффект "Кубик"
2021-11-06 Основное Android-приложение GyverPanelWiFi - исправлен скроллинг главного экрана приложения - Header и Footer страницы остаются в области видимости, содержимое центральной панели прокручивается по ве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
2021-11-18 Исправлена ошибка смещения года относительно даты в календаре в больших часах
    [a_main.ino, clock.ino, e131.ino]
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2021-11-22 Исправлено начертание символа '$' в малом шрифте бегущей строки
2021-11-24 Исправлены некоторые warnings при компиляции
    [a_def_soft.h, a_main.ino, clock.ino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]
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2021-12-04 Исправлено - возвращение игр в автоматический режим после того, как закончили играть в приложении Player; Добавлена настройка - тип чипа нв котором сделан DFPlayer - орининальный (AS20HH5883-74) или 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
    [a_def_hard.h, a_def_soft.h, a_main.ino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]
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2021-12-04 Исправлено: приложение не могло подключиться к контроллеру пока работа будильник-рассвет
    [a_main.ino]
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2021-12-05 wiki - Статья натройка MQTT - исправлены ссылки, добавлено предупреждение о смене формата топика на сервере
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2021-12-05 Исправления в статье wiki; Добавлен комментарий о необходимости сборки прошивки с ВКЛЮЧЕННЫМ распредением памяти с выделением место под файловую систему
    [a_def_soft.h]
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2021-12-10 Исправление от limittouch: настройка - не повторять игры в демо-режиме, переходить к следующему эффекту после однократной демонстрации игры
    [a_def_hard.h, a_def_soft.h, a_main.ino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]
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2021-12-16 Исправлена позиция отображения календаря на матрицах шириной 15 колонок
    [custom.ino]
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2021-12-22 Альтернативный список городов
    [towns.xlsx]
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2022-01-28 Исправлен вывод (рваный ритм и фризы) с Jinx непосредственно на матрицу
    [a_def_soft.h, a_main.ino, e131.ino]
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2022-02-25 Исправлен возврат значения MQTT параметра "CL"
    [a_main.ino]
2022-03-13 Fix possible issue with dunrise/sundown hours conversion while getting weather data from OpenWeatherMap
    [weather.ino]
2022-05-01 Fix draw calendar in small clock, vertical clock mode
    [custom.ino]
2022-05-12 Исправлено: перебор эффектов SD -карты в автоматическом режиме
    [a_def_soft.h, a_main.ino, custom.ino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]
2022-05-21 Исправлено форматирование макроса даты в бегущей строке, если дни недели / месяцы исправлены в прошивке на английский язык
    [runningText.ino]
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2022-10-29 Исправление эффекта Кубик рубика (убраны ошибки)
    [a_main.ino, custom.ino, effects.ino]
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2022-11-04 Исправлены ошибки вывода часов и календаря для различных размеров матрицы, размеров шрифта часов и календаря
    [clock.ino]
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2022-11-24 Исправлен эффект "Светлячки" для гирлянд шире 25 диодов; Добавлен новый эффект (по просьбе заказчика) - Штора.
    [a_def_soft.h, a_main.ino, custom.ino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]
2022-11-24 Исправлены эффекты Тени и Северное сияние работающие на разнородных сборных матрицах
    [effects.ino]
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2022-11-25 Исправлен макрос {S} - может содержать только одну дату из интервала
    [runningText.ino]
2022-11-25 Исправлена инструкция по макросам {R} и {S} в wiki
    [runningText.ino]
2022-11-25 Обновлена страница справки по макросам - исправлено описание макросов {R} и {S}
2022-11-26 Добавлена анимация "Сердце" 8x8, пригодная для отображения на матрицах всех размеров; Упрощено подключение своей анимации к проекту; Переработан механизм загрузки анимации: анимации с размером бОльши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
    [GyverPanelWiFi_v1.13.ino, a_def_soft.h, a_main.ino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]
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2022-12-04 Групповая синхронизация - исправлен вывод с устройства (MASTER) меньшего размера на матрицу (SLAVE) большего размера в режиме ЛОГИЧЕСКИХ координат.
    [a_def_soft.h, a_main.ino, e131.ino]
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2022-12-04 Групповая синхронизация - исправлен вывод с устройства (MASTER) большего размера на матрицу (SLAVE) меньшего размера в режиме ЛОГИЧЕСКИХ координат.
    [a_def_soft.h, e131.ino]
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2022-12-10 Эффект слайды - исправлено появление на неквадратных картинках; JinxFramer - тсправлено рисование слайдов для неквадратных матриц
    [GyverPanelWiFi_v1.13.ino, pictures.ino]
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2022-12-13 Исправлен эффект "Траффик" - убрана яркая точка в конце дорожки
    [effects.ino]
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2022-12-24 Исправлено приложение Player - в устройствах с SD-картой игры открывались, но не запускались с ручным управлением
    [a_main.ino]
2023-01-16 Незначительные исправления, в основном - пояснения в комментариях
    [GyverPanelWiFi_v1.13.ino, a_def_hard.h, runningText.ino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]
2023-04-06 STL-ки для печати сборной решетки из сегментов 16x16 от Aleksander
    [matrix-1-side.stl, matrix-2-sides.stl, matrix-3-sides.stl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]
2023-04-16 Переход на версию ядра 2.0.6 для ESP32, исправление ошибок компиляции
    [GyverPanelWiFi_v1.13.ino, a_def_hard.h, clock.ino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]
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2023-04-22 Исправление- тип матирицы сбрасывается в зигзаг из параллельной
    [GyverPanelWiFi_v1.13.ino]
2023-11-12 Fix: возможное прграммное "залипание" кнопки в состоянии "нажато" при старте прошивки
    [GyverPanelWiFi_v1.13.ino, effects.ino]
2023-11-22 Update runningText.ino
    Fix check of letter height on segmented matrix
    [runningText.ino]
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2023-12-05 Исправлена ошибка выхода за границы массива
    [GyverPanelWiFi_v1.13.ino, eeprom.ino]
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2024-08-29 Исправлено - получение погоды с Яндекс
    [GyverPanelWiFi_v1.13.ino, a_def_hard.h, a_def_soft.h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]
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2024-10-25 Исправлено получение погоды с Яндекс.Погода
    [GyverPanelWiFi_v1.13.ino, a_def_hard.h, a_def_soft.h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]
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2024-10-31 Исправлен номер версии, который был неправильным
    [GyverPanelWiFi_v1.13.ino]
2024-11-06 Исправление, касающиеся ошибок компиляции, при включенном строгом режиме
    [GyverPanelWiFi_v1.13.ino, weather.ino]
2024-11-21 Исправлено получение IP-адреса по DHCP
    [GyverPanelWiFi_v1.13.ino, a_def_soft.h]
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2026-06-12 Комментарии и определения (исправлено)
